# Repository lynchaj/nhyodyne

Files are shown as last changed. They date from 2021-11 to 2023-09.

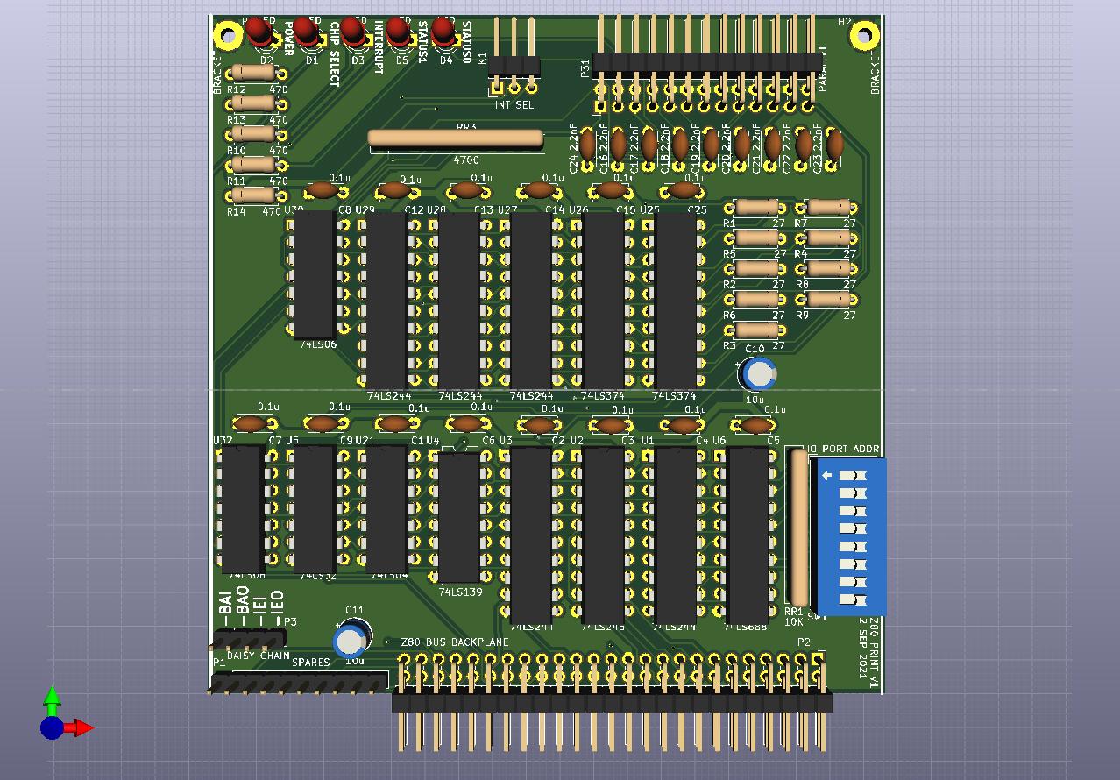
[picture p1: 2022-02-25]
Z80PRINT1/Z80PRINT.jpg

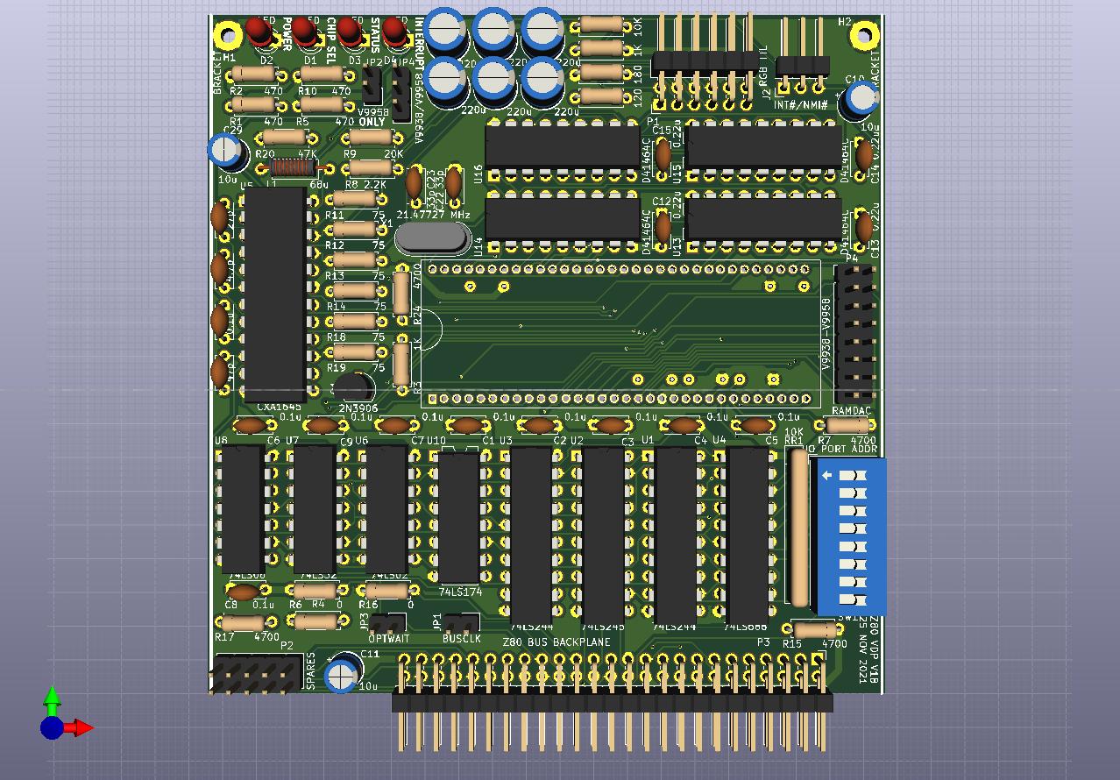
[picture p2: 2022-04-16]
Z80ESP/HARDWARE/Z80ESP.jpg

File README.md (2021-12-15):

# nhyodyne: A Modular Backplane Computer (MBC)

Dans Z80 MBC with MBC65C02

# Introduction
The purpose of this project is to revisit the design concepts behind my original Z80 SBC (aka test prototype) which has evolved into the SBC V2-005 over several years. Attempt to introduce some new concepts to make the design more modular, flexible, and less expensive. Use low cost prototype PCBs (100x100mm) available for less than $20 including shipping from JLCPCB. Make simple single function boards to implement good program design concepts from Computer Science: high cohesion and low coupling. Maintain as much backward compatibility with latest SBC V2 as possible.

# Overview
The MBC consists of four core boards: Z80 backplane, Z80 processor, Z80 clock, and Z80 ROM. These are sufficient to build a working system of minimum capability. However  the core boards are designed in such a way that they can be individually redesigned and replaced with improved designs and/or customized to suit the builder. It achieves low coupling by implementing a simple bus using off-the-shelf 2×25 2.54mm spaced pin headers and socket strips. The backplane is a replication of a fully buffered Z80 CPU pin out in the same order. Each board has high cohesion by being limited to a single function consisting of only parts specifically related to to perform its task. This lowers builder cost by eliminating unnecessary parts and improves system reliability by having fewer parts to fail. Likewise, if a component or whole board fails it can be replaced without affecting the remaining boards.

# Tools
Open Source tools and software are used to the maximum extend possible to keep costs down for people building the Z80 MBC.  The target software for Z80 MBC is ROMWBW and is supported in the Dev Branch.  All boards are designed using KiCAD version 5 or later and FreeRouting for PCB trace autorouting.  Gerber files are supplied for most boards and can be obtained from JLCPCB or the PCB manufacturer of your choice.

RomWBW Dev Branch  https://github.com/wwarthen/romwbw/tree/dev

KiCAD version 5 or later  https://www.kicad.org/

FreeRouting  https://github.com/freerouting/freerouting

JLCPCB  https://jlcpcb.com/

# Additional Design Goals
There are several additional design goals for the Z80 MBC.

First, is to ease constraints on the design to allow for some new configurations. Specifically capability to access memory over the bus and configurable memory map holes for external memory.

A second design goal is making all IO devices optional, fully configurable, and limiting IO port addresses to only the minimum necessary. Multiple IO devices can exist in the system simultaneously or not exist as the builder chooses. Lowers cost and improves system reliability by removing unneeded and/or unwanted capabilities.

The third design goal is allowing multiple memory modules with boot enable jumpers to specify boot devices present after CPU reset.

Fourth, adding simple debug features like user LEDs and a switch.

Fifth, implementing a fully buffered Z80 processor with configurable wait state capability and no internal IO or memory devices. Related is each board is also fully buffered to keep bus signals only on the bus with no raw bus signals intruding into the board past the buffers.

Sixth, maintain backwards compatibility to the extent possible (two exceptions so far) to reuse existing SBC software. Target software is current ROMWBW

Seventh, lower build cost by using inexpensive off-the-shelf components and PCBs. All parts come from Jameco or eBay (like bus connectors). Use simple 9vdc 1A unregulated power supply. Keep part count on boards low so they are effectively disposable eliminating the need for sockets and further lowering builder costs. Make non-essential components optionally do-not-populate.



Photo: Wayne Warthen's early version of Z80 MBC with prototype DSKY V3.  From left to right; contains boards Z80BCKPLN1 (underneath), Z80CLOCK, Z80PROC, Z80RAM, Z80ROM, Z80SERIAL, and Z80PPIDE with CF adapter installed.  Z80PPIDE is also connected to DSKY V3 via legacy PPI connector.
DSKY V3 by Dan Werner  https://www.retrobrewcomputers.org/doku.php?id=boards:ecb:dskyng

# Frequently Asked Questions
  What is "nhyodyne"?  The name nyhodyne is completely made up in an attempt to be unique.  It is pronounced like "neodyne".  https://www.howtopronounce.com/neo meaning "new" and https://www.howtopronounce.com/dyne meaning "force"

  Who is the intended audience?  Electronic and retrocomputing hobbyists of all ages and experience.  From brand new beginners to experienced designers, all are welcome.  Help is available on the discussion forum as needed or get in contact with me personally.  The boards are designed with beginners in mind and use common off-the-shelf tools and components.  I try to keep specialized parts to a minimum as well as surface mount devices (SMD) and/or programmable logic devices (GALs, CPLDs, FPGAs).

Where can I get Printed Circuit Boards (PCBs)?  Use the supplied Gerber files and order from JLCPCB or any other manufacturer. I just accept the defaults and they work fine.  You can customize if you want but you should know what you're doing.

I ordered PCBs and now I have extras.  What do I do with them?  Give them away to family and friends!  They make excellent gifts and affordable too!  Don't let the extras sit on a shelf gathering dust.  Share the fun

Can I use these designs in my science fair, school project, etc?  Sure, but please cite your source so others can find this project too.

What if I want to fork my own project based on your work?  It's OK with me and I wish you the best of luck.  I'll be happy to answer questions as best I can and as time allows.

Can these designs be used commercially?  Not really and I'd prefer they be kept for hobbyists because that's they're intended purpose.  If you take these designs partially or in whole commercial you are on your own and accept all associated risk.  These are intended for hobbyist and educational use only.

Why are all the PCBs green?  I like green PCBs and am a bit of a traditionalist from back in the day when PCBs only came in green.  Also it is a good color choice to see the traces underneath and provides good contrast compared to other colors.  That being said, you can make your PCBs any color you like when you order them.

Wow, this is cool!  How do I get involved?  Simple, download the Gerber files and get them built at JLCPCB or whatever PCB manufacturer you prefer.  Order parts and build your boards.  Post your questions on the forum with pictures.

What can I do to support nhyodyne project?  Great question!  What it most needs is YOU so start building your boards right away.  Then tell your friends.  Post on your favorite retrocomputing forums like retro-comp, comp.os.cpm, vogons.org, vintage computer sites, retrobrewcomputers.org, S100computers.com, etc.

Do you accept monetary donations?  Not really, but some people send money and I appreciate their generousity and thank them profusely. However, the truth is I am a senior engineer much closer to retirement than the beginning of my career.  I really enjoy this hobby so much I want to share it with others and make new friends.  If you insist on donations, I will usually graciously accept them but I'd rather you built your own system and tell all your friends about it.

Hey, I've got a great idea for a new board!  How to I make it?  I can help you and depending on your skill level either make it myself for the project or help you make it yourself.   There are people doing both.  I occasionally take requests for new boards although when I make them they are subject to my sense of priority and availability.  In other words, if I make them it will be on my own time and when I am ready.

Any closing thoughts?   Yes, have a great day!  Get out and enjoy your life!  This is a wonderful hobby and I've met the best people -- you will too.  I wish you a long and prosperous life with all the happiness it can bring.  Help someone else along the way.

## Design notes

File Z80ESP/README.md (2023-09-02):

# ESP32 Multi IO
The Nhyodyne ESP32 board provides the following functions for your Nhyodyne computer
* ANSI Console
* Graphics
* Sprites
* Sound
* Dual USB Serial Support
* WiFi
* Keyboard
* Mouse

This board relies heavily on the FabGL library from Fabrizio Di Vittorio.   More information can be found [HERE](http://www.fabglib.org/)

# ESP32 BOM
Qty|Reference(s)|Value|Notes
---|------------|-----|-----
12|C1, C2, C3, C4, C5, C6, C7, C8, C9, C10, C13, C14|0.1uF
3|C11, C12, C16|10uF
1|C15|100nf
1|D2|LED
2|D3, D6|1N4001
1|J3|Pin Header, right angle 1x2
1|J4|Pin Header, right angle 1x3
1|J5|Pin Header, right angle 1x3
1|J6|DB15 Female High Density PCB VGA Connector
1|J7|Pin Header, right angle 2x5
1|P2|Pin Header Right Angle 2x25
4|R1, R3, R14, R15|120ohm
1|R2|470ohm
2|R4, R6|2Kohm
2|R5, R13|1Kohm
3|R7, R9, R11|400ohm
3|R8, R10, R12|800ohm
1|R16|270ohm
1|R17|150ohm
1|RR1|10Kohm, networked, 9 pin, 8 resistor
1|RR2|1Kohm, networked, 9 pin, 8 resistor
1|SW1|8 position DIP switch
1|U1|74LS04
2|U2, U4|74LS244
1|U3|74LS245
3|U5, U6, U14|74LS32
2|U7, U9|74HC595
2|U8, U11|74HC165
1|U10|74LS688
2|U12, U13|ESP-WROOM-32 Dev Module|Such As: https://www.amazon.com/ESP-WROOM-32-Development-Microcontroller-Integrated-Compatible/dp/B08D5ZD528
1|U15|74LS244
1|U16|74LS07

# ESP32 Firmware Installation
The firmware for this board requires that platformio be installed on your system.

To install platformio core for your operating system see the directions [HERE](https://platformio.org/install/cli).  
Make sure you follow the additional directions to install the shell commands.

On linux systems it may be necessary to update permissions for the device that is autocreated for the ESP32. [More details](https://docs.platformio.org/en/latest/core/installation/udev-rules.html)  
Once platformio is properly setup on your system, you should be able to build and deploy the firmware to the ESP32.  

## To build and install the ESP firmware:
Take the ESP32 device you have designated as ESP0 and with it NOT INSTALLED in the nhyodyne card, plug it into your computer via USB.
change directory to the ESP0Firmware folder on your PC and from the operating system prompt type
```
pio run -t upload
```

Over the next couple of minutes you should see the build and upload process
something like this:

```
dwerner@lserver02:/lserver03/fileserv/Development/Vintage/Projects/nhyodyne/Z80ESP/ESP0Firmware$ pio run -t upload
Processing esp32dev (platform: espressif32; board: esp32dev; framework: arduino)
-----------------------------------------------------------------------------------------------------------------------
Verbose mode can be enabled via `-v, --verbose` option
CONFIGURATION: https://docs.platformio.org/page/boards/espressif32/esp32dev.html
PLATFORM: Espressif 32 (6.3.2) > Espressif ESP32 Dev Module
HARDWARE: ESP32 240MHz, 320KB RAM, 4MB Flash
DEBUG: Current (cmsis-dap) External (cmsis-dap, esp-bridge, esp-prog, iot-bus-jtag, jlink, minimodule, olimex-arm-usb-ocd, olimex-arm-usb-ocd-h, olimex-arm-usb-tiny-h, olimex-jtag-tiny, tumpa)
PACKAGES:
 - framework-arduinoespressif32 @ 3.20009.0 (2.0.9)
 - tool-esptoolpy @ 1.40501.0 (4.5.1)
 - tool-mkfatfs @ 2.0.1
 - tool-mklittlefs @ 1.203.210628 (2.3)
 - tool-mkspiffs @ 2.230.0 (2.30)
 - toolchain-xtensa-esp32 @ 8.4.0+2021r2-patch5
LDF: Library Dependency Finder -> https://bit.ly/configure-pio-ldf
LDF Modes: Finder ~ deep+, Compatibility ~ soft
Found 34 compatible libraries
Scanning dependencies...
Dependency Graph
|-- FabGL @ 1.0.9
|-- SPI @ 2.0.0
|-- Preferences @ 2.0.0
Building in release mode
Retrieving maximum program size .pio/build/esp32dev/firmware.elf
Checking size .pio/build/esp32dev/firmware.elf
Advanced Memory Usage is available via "PlatformIO Home > Project Inspect"
RAM:   [=         ]   9.3% (used 30632 bytes from 327680 bytes)
Flash: [=====     ]  46.4% (used 608561 bytes from 1310720 bytes)
Configuring upload protocol...
AVAILABLE: cmsis-dap, esp-bridge, esp-prog, espota, esptool, iot-bus-jtag, jlink, minimodule, olimex-arm-usb-ocd, olimex-arm-usb-ocd-h, olimex-arm-usb-tiny-h, olimex-jtag-tiny, tumpa
CURRENT: upload_protocol = esptool
Looking for upload port...
Auto-detected: /dev/ttyUSB0
Uploading .pio/build/esp32dev/firmware.bin
esptool.py v4.5.1
Serial port /dev/ttyUSB0
Connecting.....
Chip is ESP32-D0WD-V3 (revision v3.0)
Features: WiFi, BT, Dual Core, 240MHz, VRef calibration in efuse, Coding Scheme None
Crystal is 40MHz
MAC: 08:b6:1f:33:39:fc
Uploading stub...
Running stub...
Stub running...
Changing baud rate to 460800
Changed.
Configuring flash size...
Flash will be erased from 0x00001000 to 0x00005fff...
Flash will be erased from 0x00008000 to 0x00008fff...
Flash will be erased from 0x0000e000 to 0x0000ffff...
Flash will be erased from 0x00010000 to 0x000a4fff...
Compressed 17488 bytes to 12168...
Writing at 0x00001000... (100 %)
Wrote 17488 bytes (12168 compressed) at 0x00001000 in 0.5 seconds (effective 287.3 kbit/s)...
Hash of data verified.
Compressed 3072 bytes to 146...
Writing at 0x00008000... (100 %)
Wrote 3072 bytes (146 compressed) at 0x00008000 in 0.0 seconds (effective 571.2 kbit/s)...
Hash of data verified.
Compressed 8192 bytes to 47...
Writing at 0x0000e000... (100 %)
Wrote 8192 bytes (47 compressed) at 0x0000e000 in 0.1 seconds (effective 829.3 kbit/s)...
Hash of data verified.
Compressed 608928 bytes to 309667...
Writing at 0x00010000... (5 %)
Writing at 0x00020854... (10 %)
Writing at 0x0002f631... (15 %)
Writing at 0x0003b66a... (21 %)
Writing at 0x0004b725... (26 %)
Writing at 0x00050794... (31 %)
Writing at 0x00056585... (36 %)
Writing at 0x0005c2fd... (42 %)
Writing at 0x0006271e... (47 %)
Writing at 0x000684b2... (52 %)
Writing at 0x0006dceb... (57 %)
Writing at 0x00073098... (63 %)
Writing at 0x0007864e... (68 %)
Writing at 0x0007de33... (73 %)
Writing at 0x0008412b... (78 %)
Writing at 0x0008c053... (84 %)
Writing at 0x00094cba... (89 %)
Writing at 0x0009a559... (94 %)
Writing at 0x0009f9b7... (100 %)
Wrote 608928 bytes (309667 compressed) at 0x00010000 in 8.0 seconds (effective 606.6 kbit/s)...
Hash of data verified.

Leaving...
Hard resetting via RTS pin...
============================================ [SUCCESS] Took 22.49 seconds ============================================
```

Once this is done you can install ESP0 into U12 on your nhyodyne board.  Then repeat the process for the ESP1 and install into U13.

# ESP32 Communication Protocol

The ESP32 board communicates with your system via 3 ports, two IO ports and one status port.

The default configuration sets the base IO to $9C.  IO Communication with ESP0 is at base port, ESP1 is at base port +1 and the status register is at base port +2.

```
ESPBASE         EQU $9C         ; Base Port
ESP0:           EQU ESPBASE     ; ESP0 IO PORT

ESP1:           EQU ESPBASE+1   ; ESP1 IO PORT

ESP_STATUS:     EQU ESPBASE+2   ; ESP  STATUS PORT
                                ; MSB XX XX S S S S S
                                ;           | | | | |- ESP0 READY_OUTPUT
                                ;           | | | |--- ESP0 BUSY
                                ;           | | |----- ESP0 SPARE (unused)
                                ;           | |------- ESP1 READY_OUTPUT
                                ;           |--------- ESP1 BUSY
```

The communication process is fairly straight forward.  Upon reset, the ESP will initialize, set BUSY and READY_OUTPUT to low and wait for an opcode.

To send an opcode or data to the ESP:

* wait for ESPx BUSY bit to go low (a timeout is suggested)
* write the opcode or data to the ESPx IO port
* it is a best practice to wait for ESPx BUSY bit to go high then low (a timeout is suggested) before sending the next byte

If an "out of sync" occurrs, where the ESP is waiting for data rather than an opcode and the host driver is unsure of the state of the ESP, it is possible to resync the ESP back to the "waiting for opcode" state by sending a stream of NULL bytes to the IO port. A stream of more than 25 NULLS should always safely return the ESP back to the "waiting for opcode" state.

Some Opcodes will return one or more bytes to the host system.   For those opcodes

* wait for ESPx BUSY bit to go low (a timeout is suggested)
* wait for ESPx READY_OUTPUT bit to go high (a timeout is suggested)
* Read the ESPx IO port
* it is a best practice to wait for ESPx BUSY bit to go high then low (a timeout is suggested) before sending the next byte

Note that the BUSY bit transitions after a command is written or data is read can happen very fast.   On slower systems a timeout is required as it is possible for the host system to miss this transition if it is not polling fast enough.

It is also a best practice to empty the ESP send buffer before sending an opcode that returns data.

For example code, see the ESPTEST.ASM program in this repo.

# ESP32 ESP0 Opcode Reference

## ESP32 Misc Opcodes

OP CODE|Description|Values
-------|-----------|------
00|NO OPERATION|NONE

The NO OPERATION opcode is used to sync the ESP32 communications stream to a known state, "Waiting for opcode".

Input Parameters: None  
Returns: None  

OP CODE|Description|Values
-------|-----------|------
255|DISCOVER|"E" "S" "P" "3" "2" "V" "1"

The DISCOVER opcode is used by host systems to verify the presence and version of the ESP hardware and firmware.

Input Parameters: None  
Returns: 7 bytes - "E" "S" "P" "3" "2" "V" "1"  

## ESP32 Terminal Opcodes
	
OP CODE|Description|Values
-------|-----------|------
1 |VGA ANSI TERM OUT SINGLE CHAR| OUT-BYTE

The VGA ANSI TERM OUT SINGLE CHAR opcode sends a single byte to the ANSI terminal subsystem of the ESP32.  Using the ANSI escape sequence set, this byte is rendered to the VGA terminal console.

Input Parameters: 1 byte - "OUT CHAR"  
Returns: None  

OP CODE|Description|Values
-------|-----------|------
2 |VGA ANSI TERM OUT NULL TERMINATED STRING| OUT-BYTE	OUT-BYTE	OUT-BYTE	OUT-BYTE	OUT-BYTE	OUT-BYTE	…	…	…	…	NULL

The VGA ANSI TERM OUT NULL TERMINATED STRING opcode sends a null terminated string to the ANSI terminal subsystem of the ESP32.  Using the ANSI escape sequence set, this string is rendered to the VGA terminal console.

Input Parameters: X bytes - string terminated by a null  
Returns: None  

OP CODE|Description|Values
-------|-----------|------
3 |VGA ANSI TERM KEYBOARD IN| IN-BYTE	

The VGA ANSI TERM KEYBOARD IN opcode returns a byte from the terminal keyboard buffer.   If there is no keystrokes in the buffer, the opcode will return a null.

Input Parameters: None  
Returns: 1 byte - input keystroke or null  

OP CODE|Description|Values
-------|-----------|------
4 |VGA ANSI TERM KEYBOARD BUFFER LENGTH| IN-BYTE

The VGA ANSI TERM KEYBOARD BUFFER LENGTH opcode returns the numbser of keystrokes in the ANSI terminal keyboard buffer.

Input Parameters: None  
Returns: 1 byte - keystroke buffer length  

OP CODE|Description|Values
-------|-----------|------
5 |VGA ANSI TERM SET CURSOR| OUT-BYTE

The VGA ANSI TERM SET CURSOR opcode sets the visibility of the terminal cursor.
* 0 = cursor off
* 1 = cursor on

Input Parameters: 1 byte - Cursor status  
Returns: None  

## ESP32 Serial Opcodes

OP CODE|Description|Values
-------|-----------|------
6 |Set Baud Rate| OUT-BYTE  OUT-BYTE  OUT-BYTE  OUT-BYTE

The Set Baud Rate opcode sets the baud rate for the ESP async serial port.  This port is exposed through the header on the top of the card and through the USB port on the ESP32 module.   Byte order is least signifigant byte to most significant byte.

Input Parameters: 4 bytes - Baud Rate
Returns: None  

OP CODE|Description|Values
-------|-----------|------
7 |Set Serial Mode| OUT-BYTE

The Set Serial Mode opcode sets the serial communication parameters for the ESP async serial port.  This port is exposed through the header on the top of the card and through the USB port on the ESP32 module.
Parameters are set as follows:
* 0 = 8 data bits, no parity, 1 stop bits
* 1 = 8 data bits, even parity, 1 stop bits
* 2 = 8 data bits, odd parity, 1 stop bits
* 3 = 7 data bits, no parity, 1 stop bits
* 4 = 7 data bits, even parity, 1 stop bits
* 5 = 7 data bits, odd parity, 1 stop bits

Input Parameters: 1 byte - Serial Mode  
Returns: None  

OP CODE|Description|Values
-------|-----------|------
8 |Serial TX Single char| OUT-BYTE

The Serial TX Single char opcode transmits a single byte through the serial communication port.  This port is exposed through the header on the top of the card and through the USB port on the ESP32 module.

Input Parameters: 1 byte - char  
Returns: None  

OP CODE|Description|Values
-------|-----------|------
9 |Serial TX Null Terminated String| OUT-BYTE  OUT-BYTE  OUT-BYTE  OUT-BYTE  OUT-BYTE  OUT-BYTE	…	…	…	…	NULL

The Serial TX Null Terminated String opcode transmits a null terminated string through the serial communication port.  This port is exposed through the header on the top of the card and through the USB port on the ESP32 module.

Input Parameters: X bytes - string terminated by a null  
Returns: None  

OP CODE|Description|Values
-------|-----------|------
10 |Serial RX| IN-BYTE

The Serial RX opcode returns a byte from the serial communication port buffer.  If there are no values in the buffer, the opcode will return a null.  This port is exposed through the header on the top of the card and through the USB port on the ESP32 module.   

Input Parameters: None  
Returns: 1 byte - input value or null    

OP CODE|Description|Values
-------|-----------|------
11 |Chars in Serial Buffer| IN-BYTE

The Chars in Serial Buffer opcode returns the numbser of keystrokes in the serial communication port buffer.  This port is exposed through the header on the top of the card and through the USB port on the ESP32 module.   

Input Parameters: None  
Returns: 1 byte - serial buffer length  

## ESP32 Audio Opcodes

OP CODE|Description|Values
-------|-----------|------
12 |Play Null Terminated String| OUT-BYTE  OUT-BYTE  OUT-BYTE  OUT-BYTE  OUT-BYTE  OUT-BYTE	…	…	…	…	NULL

The Play Null Terminated String opcode intreprets a string as musical notes and plays them with a square wave tone generator through the audio port on the top of the ESP32 card.  The audio port is at line level and requires amplification. 

Example string: "A4 4 2 A4 4 2 A#4 4 2 C5 4 2 C5 4 2 A#4 4 2 A4 4 2 G4 4 2 F4 4 2 F4 4 2 G4 4 2 A4 4 2 A4 2 2 G4 16 2 G4 2 2 P 8 2 "

The string is in the format:  [note (C,D,E,F,G,A,B) + [#,b] + octave (2..7) + space + tempo (99..1)] + [pause (P) + space + tempo (99.1)]
```
    "A4 4 2" 
     |  | |----- Tempo
     |  |------- Octave (2..7)
     |---------- note to play (or P for pause)
```     

Input Parameters: 1 byte - Cursor status  
Returns: None  

OP CODE|Description|Values
-------|-----------|------
13 |Play Sound	| OUT-BYTE  OUT-BYTE  OUT-BYTE  OUT-BYTE  OUT-BYTE  OUT-BYTE  OUT-BYTE  OUT-BYTE  OUT-BYTE  OUT-BYTE  OUT-BYTE  OUT-BYTE  OUT-BYTE  OUT-BYTE  OUT-BYTE  OUT-BYTE  OUT-BYTE  OUT-BYTE  OUT-BYTE  OUT-BYTE  OUT-BYTE  OUT-BYTE  OUT-BYTE  OUT-BYTE  

The Play Sound opcode plays a sound with the specified parameters through the audio port on the top of the ESP32 card.  The audio port is at line level and requires amplification. 

The following parameters need to be specified in the following order:
* Attack, 4 bytes, Byte order is least signifigant byte to most significant byte.
* Decay, 4 bytes, Byte order is least signifigant byte to most significant byte.
* Sustain, 2 bytes, Byte order is least signifigant byte to most significant byte.
* Release, 4 bytes, Byte order is least signifigant byte to most significant byte.
* WaveType, 1 byte,   0=WAVE_SQUARE,1=WAVE_SINE,2=WAVE_TRIANGLE,3=WAVE_SAW,4=WAVE_NOISE
* Volume, 2 bytes,  Byte order is least signifigant byte to most significant byte.  Even though volume is specified as two bytes, only LSB is used.
* Duration, 2 bytes, Byte order is least signifigant byte to most significant byte.  Duration is in MS.
* FreqStart, 2 bytes, Byte order is least signifigant byte to most significant byte.
* FreqEnd, 2 bytes, Byte order is least signifigant byte to most significant byte.
* ModFreqMode, 1 byte,  0=MODFREQ_NONE,1=MODFREQ_TO_END,2=MODFREQ_TO_RELEASE,3=MODFREQ_TO_SUSTAIN

More detailed information about programming the sound generator can be found [HERE](http://www.fabglib.org/classfabgl_1_1_sound_generator.html)

Input Parameters: 24 bytes
Returns: None  

OP CODE|Description|Values
-------|-----------|------
14 |Set Volume| OUT-BYTE

The Set Volume opcode sets the overall volume of the sound generated by the audio port on the top of the ESP32 card.  The audio port is at line level and requires amplification.

Input Parameters: 1 byte - Volume
Returns: None  

## ESP32 Graphics Opcodes
OP CODE|Description|Values
-------|-----------|------
15 |Set Display Resolution| OUT-BYTE

The Set Display Resolution opcode sets the display resolution of the VGA output of the ESP32. The specified display resolution is stored in flash memory and will survive a power cycle.  Note that this opcode can take a SECOND OR MORE to process as it requires the ESP to reboot, so leave plenty of time after issuing this command. ALWAYS issue a Clear Display(17) command after changing video mode. 

The proper sequence is as follows:
* issue Set Display Resolution opcode
* send one byte for new video mode
* wait at least 3 seconds
* issue clear display command

ID|Mode Name|Description|Color Depth
--|---------|-----------|-----------
00|VGA_320x200_70Hz|320x200@70Hz resolution - the same of VGA_640x200_70Hz with horizontal halved|64
01|VGA_320x200_75Hz|320x200@75Hz resolution|64
02|VGA_320x200_75HzRetro|320x200@75Hz retro resolution|64
03|QVGA_320x240_60Hz|320x240@60Hz resolution|64
04|VGA_400x300_60Hz|400x300@60Hz resolution|64
05|VGA_480x300_75Hz|480x300@75Hz resolution|64
06|VGA_512x192_60Hz|512x192@60Hz resolution|16
07|VGA_512x384_60Hz	|512x384@60Hz resolution|16
08|VGA_512x448_60Hz|512x448@60Hz resolution|16
09|VGA_512x512_58Hz|512x512@58Hz resolution|16
10|VGA_640x200_60HzD|640x200@60Hz doublescan resolution|16
11|VGA_640x200_70Hz|640x200@70Hz resolution - the same of VGA_640x400_70Hz with vertical halved|16
12|VGA_640x200_70HzRetro|640x200@70Hz retro resolution|16
13|VGA_640x240_60Hz|640x240@60Hz (DoubleScan) resolution|16
14|VGA_640x350_70Hz|640x350@70Hz resolution|16
15|VGA_640x350_70HzAlt1|640x350@70HzAlt1 resolution|16
16|VESA_640x350_85Hz|640x350@85Hz resolution|16
17|VGA_640x382_60Hz|640x382@60Hz resolution|16
18|VGA_640x384_60Hz|640x384@60Hz resolution|16
19|VGA_640x400_70Hz|640x400@70Hz resolution|16
20|VGA_640x400_60Hz|640x400@60Hz (actually 640x480 but with less lines)|16
21|VGA_640x480_60Hz|640x480@60Hz resolution|16
22|VGA_640x480_60HzAlt1|640x480@60HzAlt1 resolution|16
23|VGA_640x480_60HzD|640x480@60Hz doublescan resolution|16
24|VGA_640x480_73Hz|640x480@73Hz resolution|16
25|VESA_640x480_75Hz|640x480@75Hz resolution|16
26|VGA_720x348_50HzD|720x348@50Hz doublescan resolution|16
27|VGA_720x348_59HzD|720x348@59Hz doublescan resolution|16
28|VGA_720x348_73Hz|720x348@73Hz resolution|16
29|VGA_720x350_70Hz|720x350@70Hz resolution|16
30|VGA_720x400_70Hz|720x400@70Hz resolution|16
31|VESA_720x400_85Hz|720x400@85Hz resolution|16
32|PAL_720x576_50Hz|720x576@50Hz resolution|8
33|VESA_768x576_60Hz|768x576@60Hz resolution|8
34|SVGA_800x300_60Hz|800x300@60Hz resolution|8
35|SVGA_800x600_56Hz|800x600@56Hz resolution|4
36|SVGA_800x600_60Hz|800x600@60Hz resolution|4
37|SVGA_960x540_60Hz|960x540@60Hz resolution|4
38|SVGA_1024x768_60Hz|1024x768@60Hz resolution|2
39|SVGA_1024x768_70Hz|1024x768@70Hz resolution|2
40|SVGA_1024x768_75Hz|1024x768@75Hz resolution|2
41|SVGA_1280x600_60Hz|1280x600@60Hz resolution|2
42|SVGA_1280x720_60Hz|1280x720@60Hz resolution|2
43|SVGA_1280x720_60HzAlt1|1280x720@60Hz resolution|2
44|SVGA_1280x768_50Hz|1280x768@50Hz resolution|2

Input Parameters: 1 byte - Video Mode
Returns: None  

OP CODE|Description|Values
-------|-----------|------
16 |Load Font| OUT-BYTE

The Load Font opcode sets the display font for the VGA ANSI Terminal.

ID|Font Name	
--|---------
00|FONT_4X6
01|FONT_5X7
02|FONT_5X8
03|FONT_6X8
04|FONT_6X9
05|FONT_6X10
06|FONT_6X12
07|FONT_6X13
08|FONT_7X13
09|FONT_7X14
10|FONT_8X8
11|FONT_8X9
12|FONT_8X13
13|FONT_8X14
14|FONT_8X16
15|FONT_8X19
16|FONT_9X15
17|FONT_9X18
18|FONT_10X20
19|FONT_BIGSERIF_8X14
20|FONT_BIGSERIF_8X16
21|FONT_BLOCK_8X14
22|FONT_BROADWAY_8X14
23|FONT_COMPUTER_8X14
24|FONT_COURIER_8X14
25|FONT_LCD_8X14
26|FONT_OLDENGL_8X16
27|FONT_SANSERIF_8X14
28|FONT_SANSERIF_8X16
29|FONT_SLANT_8X14
30|FONT_WIGGLY_8X16

Input Parameters: 1 byte - Font
Returns: None  

OP CODE|Description|Values
-------|-----------|------
17|Clear Display| NONE

The Clear Display opcode clears the VGA.

Input Parameters: None
Returns: None  

OP CODE|Description|Values
-------|-----------|------
18 |Copy Rectangle| OUT-BYTE OUT-BYTE OUT-BYTE OUT-BYTE OUT-BYTE OUT-BYTE OUT-BYTE OUT-BYTE OUT-BYTE OUT-BYTE OUT-BYTE OUT-BYTE

The Copy Rectangle opcode copyies a rectangle shaped area from one part of the bitmapped display to another.

The following parameters need to be specified in the following order:
* Source X coordinate, 2 bytes, Byte order is least signifigant byte to most significant byte.
* Source Y coordinate, 2 bytes, Byte order is least signifigant byte to most significant byte.
* Destination X coordinate, 2 bytes, Byte order is least signifigant byte to most significant byte.
* Destination Y coordinate, 2 bytes, Byte order is least signifigant byte to most significant byte.
* Area Width, 2 bytes, Byte order is least signifigant byte to most significant byte.
* Area Hight, 2 bytes, Byte order is least signifigant byte to most significant byte.

All Parameters above are in display pixels with 0,0 being the upper left of the VGA screen.

Input Parameters: 12 bytes
Returns: None  

OP CODE|Description|Values
-------|-----------|------
19 |Draw Bitmap| OUT-BYTE(s)

The Draw Bitmap opcode draws a specified bitmap on the VGA display.

The following parameters need to be specified in the following order:
* X coordinate, 2 bytes, Byte order is least signifigant byte to most significant byte.
* Y coordinate, 2 bytes, Byte order is least signifigant byte to most significant byte.
* Width, 2 bytes, Byte order is least signifigant byte to most significant byte.
* Hight, 2 bytes, Byte order is least signifigant byte to most significant byte.
* Pixel Format, 1 byte, FORMAT=1:NATIVE DEVICE(usually 1 BIT/PIXEL),2:MASK(1=OPAQUE 0=TRANSP),3: 8 BITS/PIXEL aabbggrr, 4:32 BITS/PIXEL RGBA
* Bitmap Length, 2 bytes, Byte order is least signifigant byte to most significant byte.
* Bitmap Data, X bytes, bitmap size cannot exceed 31.5K

Input Parameters: X bytes
Returns: None  

OP CODE|Description|Values
-------|-----------|------
20 |Draw Char| OUT-BYTE OUT-BYTE OUT-BYTE OUT-BYTE OUT-BYTE OUT-BYTE

The Draw Char opcode draws a specified character, at a specified location, in a specified font, in the current Pen color.

The following parameters need to be specified in the following order:
* X coordinate, 2 bytes, Byte order is least signifigant byte to most significant byte.
* Y coordinate, 2 bytes, Byte order is least signifigant byte to most significant byte.
* Character to Draw, 1 byte
* Font, 1 bytes, See Font Table from Set Font opcode

Input Parameters: 6 bytes
Returns: None  

OP CODE|Description|Values
-------|-----------|------
21 |Draw Ellipse| OUT-BYTE  OUT-BYTE  OUT-BYTE  OUT-BYTE  OUT-BYTE  OUT-BYTE  OUT-BYTE  OUT-BYTE  

The Draw Ellipse opcode draws an ellpise on the bitmapped display, in the current Pen color.

The following parameters need to be specified in the following order:
* X coordinate, 2 bytes, Byte order is least signifigant byte to most significant byte.
* Y coordinate, 2 bytes, Byte order is least signifigant byte to most significant byte.
* Width, 2 bytes, Byte order is least signifigant byte to most significant byte.
* Height, 2 bytes, Byte order is least signifigant byte to most significant byte.

Input Parameters: 6 bytes
Returns: None  

OP CODE|Description|Values
-------|-----------|------
22 |Draw Gliph| OUT-BYTE(s)

The Draw Glyph opcode draws a Glyph on the bitmapped display, in the current Pen color.

The following parameters need to be specified in the following order:
* X coordinate, 2 bytes, Byte order is least signifigant byte to most significant byte.
* Y coordinate, 2 bytes, Byte order is least signifigant byte to most significant byte.
* Width, 2 bytes, Byte order is least signifigant byte to most significant byte.
* Height, 2 bytes, Byte order is least signifigant byte to most significant byte.
* Index, 2 bytes, Byte order is least signifigant byte to most significant byte.  Usually 0, Use when the buffer contains multiple glyphs.
* Glyph Length, 2 bytes, Byte order is least signifigant byte to most significant byte.
* Glyph Data, X bytes, glyph size cannot exceed 255 bytes, and is stored as a 1 bit/pixel bitmap

Input Parameters: X bytes
Returns: None  

OP CODE|Description|Values
-------|-----------|------
23 |Draw Line| OUT-BYTE  OUT-BYTE  OUT-BYTE  OUT-BYTE  OUT-BYTE  OUT-BYTE  OUT-BYTE  OUT-BYTE  

The Draw Line opcode draws a line on the bitmapped display, in the current Pen color.

The following parameters need to be specified in the following order:
* Start X coordinate, 2 bytes, Byte order is least signifigant byte to most significant byte.
* Start Y coordinate, 2 bytes, Byte order is least signifigant byte to most significant byte.
* End X coordinate, 2 bytes, Byte order is least signifigant byte to most significant byte.
* End Y coordinate, 2 bytes, Byte order is least signifigant byte to most significant byte.

Input Parameters: 8 bytes
Returns: None  

OP CODE|Description|Values
-------|-----------|------
24 |Draw Rectangle| OUT-BYTE  OUT-BYTE  OUT-BYTE  OUT-BYTE  OUT-BYTE  OUT-BYTE  OUT-BYTE  OUT-BYTE  

The Draw Rectangle opcode draws a Rectangle on the bitmapped display, in the current Pen color.

The following parameters need to be specified in the following order:
* Start X coordinate, 2 bytes, Byte order is least signifigant byte to most significant byte.
* Start Y coordinate, 2 bytes, Byte order is least signifigant byte to most significant byte.
* End X coordinate, 2 bytes, Byte order is least signifigant byte to most significant byte.
* End Y coordinate, 2 bytes, Byte order is least signifigant byte to most significant byte.

Input Parameters: 8 bytes
Returns: None  

OP CODE|Description|Values
-------|-----------|------
25 |Draw Filled Ellipse| OUT-BYTE  OUT-BYTE  OUT-BYTE  OUT-BYTE  OUT-BYTE  OUT-BYTE  OUT-BYTE  OUT-BYTE  

The Draw Filled Ellipse opcode draws a filled ellipse on the bitmapped display, in the current Pen color, filled with the current Brush color.

The following parameters need to be specified in the following order:
* Start X coordinate, 2 bytes, Byte order is least signifigant byte to most significant byte.
* Start Y coordinate, 2 bytes, Byte order is least signifigant byte to most significant byte.
* width, 2 bytes, Byte order is least signifigant byte to most significant byte.
* Height, 2 bytes, Byte order is least signifigant byte to most significant byte.

Input Parameters: 8 bytes
Returns: None  

OP CODE|Description|Values
-------|-----------|------
26 |Draw Filled Rectangle| OUT-BYTE  OUT-BYTE  OUT-BYTE  OUT-BYTE  OUT-BYTE  OUT-BYTE  OUT-BYTE  OUT-BYTE  

The Draw Filled Rectangle opcode draws a filled rectangle on the bitmapped display, in the current Pen color, filled with the current Brush color.

The following parameters need to be specified in the following order:
* Start X coordinate, 2 bytes, Byte order is least signifigant byte to most significant byte.
* Start Y coordinate, 2 bytes, Byte order is least signifigant byte to most significant byte.
* End X coordinate, 2 bytes, Byte order is least signifigant byte to most significant byte.
* End Y coordinate, 2 bytes, Byte order is least signifigant byte to most significant byte.

Input Parameters: 8 bytes
Returns: None  

OP CODE|Description|Values
-------|-----------|------
27 |Get Pixel Value| OUT-BYTE  OUT-BYTE  OUT-BYTE  OUT-BYTE  IN-BYTE    IN-BYTE    IN-BYTE  

The Get Pixel Value opcode returns the current color value of the specified display pixel.

The following parameters need to be specified in the following order:
* X coordinate, 2 bytes, Byte order is least signifigant byte to most significant byte.
* Y coordinate, 2 bytes, Byte order is least signifigant byte to most significant byte.

The ESP will then return:
* Blue value, 1 byte
* Green value, 1 byte
* Red value, 1 byte

Input Parameters: 4 bytes
Returns: 3 bytes

OP CODE|Description|Values
-------|-----------|------
28 |Invert Rectangle| OUT-BYTE  OUT-BYTE  OUT-BYTE  OUT-BYTE  OUT-BYTE  OUT-BYTE  OUT-BYTE  OUT-BYTE  

The Invert Rectangle opcode will invert all of the pixels within a specified area on the bitmapped display.

The following parameters need to be specified in the following order:
* Start X coordinate, 2 bytes, Byte order is least signifigant byte to most significant byte.
* Start Y coordinate, 2 bytes, Byte order is least signifigant byte to most significant byte.
* End X coordinate, 2 bytes, Byte order is least signifigant byte to most significant byte.
* End Y coordinate, 2 bytes, Byte order is least signifigant byte to most significant byte.

Input Parameters: 8 bytes
Returns: None  

OP CODE|Description|Values
-------|-----------|------
29 |Draw A Line To| OUT-BYTE  OUT-BYTE  OUT-BYTE  OUT-BYTE

The Draw A Line To opcode will draw a line from the current graphics cursor position to the specified location on the bitmapped display.

The following parameters need to be specified in the following order:
* End X coordinate, 2 bytes, Byte order is least signifigant byte to most significant byte.
* End Y coordinate, 2 bytes, Byte order is least signifigant byte to most significant byte.

Input Parameters: 4 bytes
Returns: None  

OP CODE|Description|Values
-------|-----------|------
30 |Move Cursor To| OUT-BYTE  OUT-BYTE  OUT-BYTE  OUT-BYTE

The Move Cursor To opcode will move the graphics cursor to the specified location on the bitmapped display.

The following parameters need to be specified in the following order:
* End X coordinate, 2 bytes, Byte order is least signifigant byte to most significant byte.
* End Y coordinate, 2 bytes, Byte order is least signifigant byte to most significant byte.

Input Parameters: 4 bytes
Returns: None  

OP CODE|Description|Values
-------|-----------|------
31 |Scroll Display| OUT-BYTE  OUT-BYTE  OUT-BYTE  OUT-BYTE

The Scroll Display opcode will scroll the display by the specified offset.

The following parameters need to be specified in the following order:
* X Offset, 2 bytes, Byte order is least signifigant byte to most significant byte.  Left Scroll is accomplished by a negative offset
* Y Offset, 2 bytes, Byte order is least signifigant byte to most significant byte.  Up Scroll is accomplished by a negative offset

Input Parameters: 4 bytes
Returns: None  

OP CODE|Description|Values
-------|-----------|------
32 |Set Brush Color| OUT-BYTE

The Set Brush Color sets the brush color to the specified color index on the pallette.

Input Parameters: 1 byte - Color
Returns: None  

OP CODE|Description|Values
-------|-----------|------
33 |Set Line Ends| OUT-BYTE

The Set Line Ends sets the method for drawing line ends by the display renderer. 
* 0=NONE
* 1=ROUNDED

Input Parameters: 1 byte - End Type
Returns: None  

OP CODE|Description|Values
-------|-----------|------
34 |Set Pen Color| OUT-BYTE

The Set Pen Color sets the brush color to the specified color index on the pallette.

Input Parameters: 1 byte - Color
Returns: None  

OP CODE|Description|Values
-------|-----------|------
35 |Set Pen Width| OUT-BYTE

The Set Pen Width sets the width in pixels of the drawing pen.

Input Parameters: 1 byte - Pen Width
Returns: None  

OP CODE|Description|Values
-------|-----------|------
36 |Set Pixel| OUT-BYTE  OUT-BYTE  OUT-BYTE  OUT-BYTE  

The Set Pixel draws a pixel at the specified location in the current pen color.

The following parameters need to be specified in the following order:
* End X coordinate, 2 bytes, Byte order is least signifigant byte to most significant byte.
* End Y coordinate, 2 bytes, Byte order is least signifigant byte to most significant byte.

Input Parameters: 4 bytes
Returns: None 

OP CODE|Description|Values
-------|-----------|------
37 |Set Glyph Options| OUT-BYTE  OUT-BYTE  OUT-BYTE  OUT-BYTE  OUT-BYTE  OUT-BYTE  OUT-BYTE  

The Set Glpyh Options opcode sets optional parameters that modify how glyphs are rendered by Draw Glyph.

The following parameters need to be specified in the following order:
* blank, 1 byte, send 1 to cause glyph to be rendered in background color
* bold, 1 byte, send 1 to cause glyph to be rendered in bold
* doubleWidth, 1 byte, send 1 to cause glyph to be rendered double width
* FillBackground, 1 byte, send 1 to cause glyph to be rendered with background painted in the specified brush color
* Invert, 1 byte, send 1 to cause glyph to be rendered inverted
* Italic, 1 byte, send 1 to cause glyph to be rendered in italics
* Underline, 1 byte, send 1 to cause glyph to be rendered with an underline

Input Parameters: 7 bytes
Returns: None  

OP CODE|Description|Values
-------|-----------|------
38 |Set Pallette Item| OUT-BYTE  OUT-BYTE  OUT-BYTE  OUT-BYTE  

The Set Pallette Item opcode sets the rendered color for a given color index.

The following parameters need to be specified in the following order:
* Index, 1 byte, Color Index on Pallette (0-63 or 0-15, or 0-3, or 0-2 or 0-1 depending on screen color depth)
* Blue Value, 1 byte 
* Green Value, 1 byte
* Red Value, 1 byte

Input Parameters: 4 bytes
Returns: None  

OP CODE|Description|Values
-------|-----------|------
39 |Set Mouse Cursor Type| OUT-BYTE

The Set Mouse Cursor Type opcode sets the shape of the rendered mouse cursor.

ID|Description
--|-----------
0|11x11 Amiga like colored mouse pointer
1|10x15 mouse pointer
2|11x19 mouse pointer
3|11x19 shadowed mouse pointer
4|12x17 mouse pointer
5|16x16 pen
6|9x9 cross
7|11x11 cross
8|5x5 point
9|11x11 left arrow
10|11x11 right arrow
11|11x11 down arrow
12|11x11 up arrow
13|19x19 move
14|12x12 resize orientation 1
15|12x12 resize orientation 2
16|11x17 resize orientation 3
17|17x11 resize orientation 4
18|7x15 text input

Input Parameters: 1 byte - Mouse Cursor Type
Returns: None  

OP CODE|Description|Values
-------|-----------|------
40 |Set Mouse Cursor Position| OUT-BYTE  OUT-BYTE  OUT-BYTE  OUT-BYTE  

The Set Mouse Cursor Position opcode sets the display position of the mouse cursor.

The following parameters need to be specified in the following order:
* X coordinate, 2 bytes, Byte order is least signifigant byte to most significant byte.
* Y coordinate, 2 bytes, Byte order is least signifigant byte to most significant byte.

Input Parameters: 4 bytes
Returns: None  

OP CODE|Description|Values
-------|-----------|------
41 |Clear Sprites| NONE

The Clear Sprites opcode clears the sprite shape table.

Input Parameters: None  
Returns: None  

OP CODE|Description|Values
-------|-----------|------
42 |Set Sprite Map| OUT-BYTE(s)

setSpriteMap	42		*AWAYS SET THE HIGHEST INDEX SPRITE LAST, AND THE MAX CONFIGURED SPRITE NUMBER IS 31. (0-32)

The Set Sprite Map opcode sets the shape for a specified sprite.   There are 32 sprites (0-31) available with the current firmware and it is important to set the highest # sprite used LAST.   

The following parameters need to be specified in the following order:
* Sprite Index, 1 byte
* Sprite Width, 2 bytes, Byte order is least signifigant byte to most significant byte.
* Sprite Hight, 2 bytes, Byte order is least signifigant byte to most significant byte.
* Pixel Format, 1 byte, FORMAT=1:NATIVE DEVICE(usually 1 BIT/PIXEL),2:MASK(1=OPAQUE 0=TRANSP),3: 8 BITS/PIXEL aabbggrr, 4:32 BITS/PIXEL RGBA
* Sprite Length, 2 bytes, Byte order is least signifigant byte to most significant byte.
* Sprite Data, X bytes, bitmap size cannot exceed 31.5K

Input Parameters: X bytes
Returns: None  

OP CODE|Description|Values
-------|-----------|------
43 |Set Sprite Location| OUT-BYTE   OUT-BYTE   OUT-BYTE   OUT-BYTE   OUT-BYTE  

The Set Sprite Location opcode moves a specified sprite to a specified location.

The following parameters need to be specified in the following order:
* X Coordinate Location, 2 bytes, Byte order is least signifigant byte to most significant byte.
* Y Coordinate Location, 2 bytes, Byte order is least signifigant byte to most significant byte.
* Sprite Index, 1 byte

Input Parameters: 5 bytes
Returns: None  

OP CODE|Description|Values
-------|-----------|------
44 |Set Sprite Visibility| OUT-BYTE  OUT-BYTE  

The Set Sprite Visibility opcode sets the visibility of a specified sprite.

The following parameters need to be specified in the following order:
* Sprite Index, 1 byte
* Visible, 1 byte, 0= hidden, 1=visible

Input Parameters: 2 bytes
Returns: None  

### ESP32 ESP1 Opcode Reference

## ESP32 Misc Opcodes

OP CODE|Description|Values
-------|-----------|------
00|NO OPERATION|NONE

The NO OPERATION opcode is used to sync the ESP32 communications stream to a known state, "Waiting for opcode".

Input Parameters: None  
Returns: None  

OP CODE|Description|Values
-------|-----------|------
255|DISCOVER|"E" "S" "P" "3" "2" "V" "1"

The DISCOVER opcode is used by host systems to verify the presence and version of the ESP hardware and firmware.

Input Parameters: None  
Returns: 7 bytes - "E" "S" "P" "3" "2" "V" "1"  

## ESP32 WiFi Opcodes
OP CODE|Description|Values
-------|-----------|------
1 |WiFi Set SSID| OUT-BYTE(s)

The WiFi Set SSID opcode stores a null terminated string in the ESP flash memory and will survive a power cycle.  This value is then used during WiFi Connection.

Input Parameters: X bytes - string terminated by a null  
Returns: None  

OP CODE|Description|Values
-------|-----------|------
2 |WiFi Set Password| OUT-BYTE(s)
The WiFi Set WiFi Password opcode stores a null terminated string in the ESP flash memory and will survive a power cycle.  This value is then used during WiFi Connection.

Input Parameters: X bytes - string terminated by a null  
Returns: None  

OP CODE|Description|Values
-------|-----------|------
3 |WiFi Connect| None

The WiFi Connect opcode will attempt to connect to a WiFI access point using the stored configuration information.  If No TCP/IP address information is configured, DHCP will be attempted.

Input Parameters: None  
Returns: None  

OP CODE|Description|Values
-------|-----------|------
4 |WiFi Get Status| IN-BYTE  

The WiFi Get Status opcode returns the current WiFi status.

Status Byte|Description
-----------|-----------
0|WL_IDLE_STATUS
1|WL_NO_SSID_AVAIL
2|WL_SCAN_COMPLETED
3|WL_CONNECTED
4|WL_CONNECT_FAILED
5|WL_CONNECTION_LOST
6|WL_DISCONNECTED

Input Parameters: None  
Returns: 1 byte - WiFi Status

OP CODE|Description|Values
-------|-----------|------
5 |WiFi Get Signal Strength| IN-BYTE  

The WiFi Get Signal Strength opcode returns the current WiFi signal strength.

Input Parameters: None  
Returns: 1 bytes- Signal Strength  

## ESP32 TCP/IP Opcodes

OP CODE|Description|Values
-------|-----------|------
12|Get IP Address| IN-BYTE   IN-BYTE   IN-BYTE   IN-BYTE

The Get IP Address opcode returns the current IP address.

Input Parameters: None  
Returns: 4 bytes (octet 1,2,3,4)  

OP CODE|Description|Values
-------|-----------|------
13 |Get Subnet Mask| IN-BYTE   IN-BYTE   IN-BYTE   IN-BYTE

The Get Subnet Mask opcode returns the current submet mask.

Input Parameters: None  
Returns: 4 bytes (octet 1,2,3,4)  

OP CODE|Description|Values
-------|-----------|------
14 |Get Gateway| IN-BYTE   IN-BYTE   IN-BYTE   IN-BYTE

The Get Gateway opcode returns the current IP default gateway.

Input Parameters: None  
Returns: 4 bytes (octet 1,2,3,4)  

OP CODE|Description|Values
-------|-----------|------
15 |Get Primary DNS| IN-BYTE   IN-BYTE   IN-BYTE   IN-BYTE

The Get Primary DNS returns the current primary DNS address.

Input Parameters: None  
Returns: 4 bytes (octet 1,2,3,4)  

OP CODE|Description|Values
-------|-----------|------
16 |Get Secondary DNS| IN-BYTE   IN-BYTE   IN-BYTE   IN-BYTE

The Get Secondary DNS opcode returns the current secondary DNS IP address.

Input Parameters: None  
Returns: 4 bytes (octet 1,2,3,4)  

OP CODE|Description|Values
-------|-----------|------
17 |Set IP Address| OUT-BYTE   OUT-BYTE   OUT-BYTE   OUT-BYTE

The Set IP Address opcode sets the IP address. 0.0.0.0 value enables DHCP.

Input Parameters: 4 bytes (octet 1,2,3,4)  
Returns: None  

OP CODE|Description|Values
-------|-----------|------
18 |Set Subnet Mask| OUT-BYTE   OUT-BYTE   OUT-BYTE   OUT-BYTE   OUT-BYTE  

The Set Subnet Mask opcode sets the subnet mask.

Input Parameters: 4 bytes (octet 1,2,3,4)  
Returns: None  

OP CODE|Description|Values
-------|-----------|------
19 |Set Gateway	| OUT-BYTE   OUT-BYTE   OUT-BYTE   OUT-BYTE   OUT-BYTE  

The Set Gateway	opcode sets the Gateway IP Address.

Input Parameters: 4 bytes (octet 1,2,3,4)  
Returns: None  

OP CODE|Description|Values
-------|-----------|------
20 |Set Primary DNS| OUT-BYTE   OUT-BYTE   OUT-BYTE   OUT-BYTE   OUT-BYTE  

The Set Primary DNS opcode sets the primary DNS IP address.

Input Parameters: 4 bytes (octet 1,2,3,4)  
Returns: None  

OP CODE|Description|Values
-------|-----------|------
21 |Set Secondary DNS| OUT-BYTE   OUT-BYTE   OUT-BYTE   OUT-BYTE   OUT-BYTE  

The Set Secondary DNS opcode sets the secondary DNS IP address.

Input Parameters: 4 bytes (octet 1,2,3,4)  
Returns: None  

OP CODE|Description|Values
-------|-----------|------
22 |Set Hostname| OUT-BYTE(s)

The Set Hostname opcode stores a null terminated string in the ESP flash memory and will survive a power cycle.  This value is then used during WiFi Connection.

Input Parameters: X bytes - string terminated by a null  
Returns: None  

OP CODE|Description|Values
-------|-----------|------
23 |Create Outgoing Connection| OUT-BYTEs

The Create Outgoing Connection opcode creates an outgoing TCP/IP socket connection to a specified host.

The following parameters need to be specified in the following order:
* Connection Number, 1 byte, Must be from 1-63, connection 0 is reserved for incoming connections.
* Port, 2 bytes, Byte order is least signifigant byte to most significant byte.
* Hostname, x bytes, null terminated string.

Input Parameters: x bytes
Returns: None  

OP CODE|Description|Values
-------|-----------|------
24 |Set Incoming Port| OUT-BYTE   OUT-BYTE

The Set Incoming Port opcode sets listen port for connection 0.

The following parameters need to be specified in the following order:
* Port Number, 2 bytes, Byte order is least signifigant byte to most significant byte.

Input Parameters: 2 bytes
Returns: None  

OP CODE|Description|Values
-------|-----------|------
25 |Out Byte to Connection#| OUT-BYTE   OUT-BYTE

The Out Byte to Connection# opcode sends a byte to the specified connection.

The following parameters need to be specified in the following order:
* Connetion #, 1 byte
* Char, 1 byte

Input Parameters: 2 bytes
Returns: None  

OP CODE|Description|Values
-------|-----------|------
26 |Out String to Connection#| OUT-BYTE   OUT-BYTE(s)

The Out String to Connection# opcode sends a null terminated string to the specified connection.

The following parameters need to be specified in the following order:
* Connetion #, 1 byte
* string, x bytes null terminated

Input Parameters: x bytes
Returns: None  

OP CODE|Description|Values
-------|-----------|------
27 |In Byte From Connection#| OUT-BYTE   IN-BYTE

The In Byte From Connection# opcode returns a byte from the connection communication buffer.  If there are no values in the buffer, the opcode will return a null.  

Input Parameters: 1 byte - Connection Number  
Returns: 1 byte - input value or null    

OP CODE|Description|Values
-------|-----------|------
28 |Chars in Buffer from Connection#| OUT-BYTE   IN-BYTE   OUT-BYTE   OUT-BYTE   OUT-BYTE  

The Chars in Buffer from Connection# opcode returns the numbser of bytes in the connection communication buffer.  This port is exposed through the header on the top of the card and through the USB port on the ESP32 module.   

Input Parameters: 1 byte - Connection Number  
Returns: 1 byte - number of bytes in the buffer 

OP CODE|Description|Values
-------|-----------|------
30 |Get MAC Address| IN-BYTE  IN-BYTE  IN-BYTE  IN-BYTE  IN-BYTE  IN-BYTE    

The Get Mac Address opcode returns the six byte MAC address of the ESP32

The following information is returned in the following order:
* MAC Address, 6 bytes

Input Parameters: None  
Returns: 6 bytes  

## ESP32 Serial Opcodes

OP CODE|Description|Values
-------|-----------|------
6 |Set Baud Rate| OUT-BYTE  OUT-BYTE  OUT-BYTE  OUT-BYTE

The Set Baud Rate opcode sets the baud rate for the ESP async serial port.  This port is exposed through the header on the top of the card and through the USB port on the ESP32 module.   Byte order is least signifigant byte to most significant byte.

Input Parameters: 4 bytes - Baud Rate
Returns: None  

OP CODE|Description|Values
-------|-----------|------
7 |Set Serial Mode| OUT-BYTE

The Set Serial Mode opcode sets the serial communication parameters for the ESP async serial port.  This port is exposed through the header on the top of the card and through the USB port on the ESP32 module.
Parameters are set as follows:
* 0 = 8 data bits, no parity, 1 stop bits
* 1 = 8 data bits, even parity, 1 stop bits
* 2 = 8 data bits, odd parity, 1 stop bits
* 3 = 7 data bits, no parity, 1 stop bits
* 4 = 7 data bits, even parity, 1 stop bits
* 5 = 7 data bits, odd parity, 1 stop bits

Input Parameters: 1 byte - Serial Mode  
Returns: None  

OP CODE|Description|Values
-------|-----------|------
8 |Serial TX Single char| OUT-BYTE

The Serial TX Single char opcode transmits a single byte through the serial communication port.  This port is exposed through the header on the top of the card and through the USB port on the ESP32 module.

Input Parameters: 1 byte - char  
Returns: None  

OP CODE|Description|Values
-------|-----------|------
9 |Serial TX Null Terminated String| OUT-BYTE  OUT-BYTE  OUT-BYTE  OUT-BYTE  OUT-BYTE  OUT-BYTE	…	…	…	…	NULL

The Serial TX Null Terminated String opcode transmits a null terminated string through the serial communication port.  This port is exposed through the header on the top of the card and through the USB port on the ESP32 module.

Input Parameters: X bytes - string terminated by a null  
Returns: None  

OP CODE|Description|Values
-------|-----------|------
10 |Serial RX| IN-BYTE

The Serial RX opcode returns a byte from the serial communication port buffer.  If there are no values in the buffer, the opcode will return a null.  This port is exposed through the header on the top of the card and through the USB port on the ESP32 module.   

Input Parameters: None  
Returns: 1 byte - input value or null    

OP CODE|Description|Values
-------|-----------|------
11 |Chars in Serial Buffer| IN-BYTE

The Chars in Serial Buffer opcode returns the numbser of keystrokes in the serial communication port buffer.  This port is exposed through the header on the top of the card and through the USB port on the ESP32 module.   

Input Parameters: None  
Returns: 1 byte - serial buffer length  

## ESP32 Mouse Opcodes
OP CODE|Description|Values
-------|-----------|------
29 |Get Mouse| IN-BYTE  IN-BYTE  IN-BYTE  IN-BYTE  IN-BYTE  IN-BYTE  IN-BYTE  IN-BYTE  

GetMouse	29	left btn	middle btn	right btn	Wheel Delta	X	X	Y	Y

The Get Mouse opcode gets the current mouse information.

The following information is returned in the following order:
* Left Button Status, 1 byte
* Middle Button Status, 1 byte
* Right Button Status, 1 byte
* Wheel location Delta, 1 byte
* X Coordinate Location, 2 bytes, Byte order is least signifigant byte to most significant byte.
* Y Coordinate Location, 2 bytes, Byte order is least signifigant byte to most significant byte.

Input Parameters: None  
Returns: 8 bytes  

### TO DO
* Improve formatting of README file

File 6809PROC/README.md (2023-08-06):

# MBC6809
6809 processor board (hardware and software) for the Nhyodyne computer system

# Bugs
* I AM SURE THERE ARE SOME . . . .

# JUMPER SETTINGS
## General
        J1 - Enable
                1&2 Only CPU
                2&3 Secondary CPU

        J2 - Clock Divider
                1&2 CLK/2
                3&4 CLK/4
                5&6 CLK/8
                7&8 CLK/16
                9&10 CLK

        J4 - Reset
                1&2 Only CPU
                2&3 Secondary CPU

        JP1 - External Reset Switch

        SW1 - IO Page select
                This maps the IO addresses $00-$FF into the 6809 memory space.  Note that
                the 6809 has address line A15 inverted in order to maintain compatibility
                with the Nhyodyne ROM and RAM cards.   Therefore the MSB (SW8) is inverted.  Most applications for this board expect an IO page of $FE ($FE00-$FEFF).Leading to a default setting of:
                1-on
                2-off
                3-off
                4-off
                5-off
                6-off
                7-off
                8-on

        SW2 - Reset

        SW2 - 6809 toggle address
                This setting sets the IO port that toggles the 6809 in and out of control when it is a secondary CPU.  When it is the only CPU in the system this setting has no effect. Most test applications for this board expect an IO address of $F0.   Reading this IO port will toggle the 6809 active/inactive.
                Leading to a default setting of:
                1-on
                2-on
                3-on
                4-on
                5-off
                6-off
                7-off
                8-off

# BOM

Qty|Reference(s)|Value
--- | --- | ---
5|C1, C14, C15, C16, C17|10µf electrolytic
12|C2, C3, C4, C5, C6, C7, C8, C9, C10, C11, C12, C13|0.1µf
1|D1|Device:LED
1|D2|Device:LED
1|D3|Device:LED
1|D4|Device:LED
1|D5|Device:LED
1|D6|Device:LED
1|D7|1N4148
1|J1|Connecto 02x04 Male Right Angle
1|J2|Connector 01x03  Male Right Angle
1|J3|Connector 01x03  Male Right Angle
1|J4|Connector 02x25  Male Right Angle
1|JP1|Jumper  01x02 Male Right Angle
6|R1, R2, R3, R4, R6, R7|470 ohm
1|R5|10 ohm
1|R8|10K ohm
1|RN1|4700 ohm Network 9
2|RN2, RN4|1K ohm Network 8
1|RN3|1k ohm Network 9
1|RN5|2.2k ohm Network 9
1|SW1|Switch:SW_DIP_x08
1|SW2|Switch:SW_DIP_x08
1|SW3|Switch:SW_Push
1|U1|74LS93
3|U2, U8, U10|74LS244
1|U3|74LS04
2|U4, U7|74LS688
1|U5|74LS245
1|U6|MC6809 (68B09 Preferred)
1|U9|74LS00
1|U11|74LS74
1|U12|74LS07

# SOFTWARE

### MONITOR
This is a simple monitor program, see the "monitor" section of this document for usage instructions. "Monitor" requires that the UART is properly initialized.

It assumes that the 6809 board is set for IOPage $FE.
        * remember that bit A15 is inverted on the board

If the SBC is the only CPU in the system, ensure that jumpers J1 and J4 are set for 1&2, then burn monitor.hex into EPROM. (note that this monitor does not initialize the UART yet, so this is broken at the moment)

If the SBC is secondary to a Z80, the monitor.com file can be run from CP/M or the monitor.hex file can be loaded from the monitor. Ensure that jumpers J1 and J4 are set for 2&3, the 6809 toggle IO address is set for $F0 and the 6809 board is set for IOPage $FE.
        * remember that bit A15 is inverted on the board

To run from the MBC Z80 monitor

first set the MPCL to allow RAM in the low bank
```
>O 7C 80
>O 78 80
```
Then load the .HEX file.
```
>L
```

Finally transfer control to the 6809 by reading the toggle register
```
>I F0
```

### SCREAM
This is a quick program that can be put on a ROM to test the 6809 board. It will output a continuous stream of "A"s from the UART. It does not require the stack to be available and is pretty much the simplest code imaginable. :)

It assumes that the 6809 board is set for IOPage $FE.
        * remember that bit A15 is inverted on the board

If the SBC is the only CPU in the system, ensure that jumpers J1 and J4 are set for 1&2, then burn scream.hex into EPROM.  (note that this monitor does not initialize the UART yet, so this is broken at the moment)

If the SBC is secondary to a Z80, the scrm.com file can be run from CP/M or the scream.hex file can be loaded from the monitor. Ensure that jumpers J1 and J4 are set for 2&3, the 6809 toggle IO address is set for $F0 and the 6809 board is set for IOPage $FE.
        * remember that bit A15 is inverted on the board

To run from the MBC Z80 monitor

first set the MPCL to allow RAM in the low bank
```
>O 7C 80
>O 78 80
```
Then load the .HEX file.
```
>L
```

Finally transfer control to the 6809 by reading the toggle register
```
>I F0
```

The '09 should reset and run this program

### MONITOR Program

Monitor is a simple machine language monitor that will allow you to view and manipulate the 6809 operating environment.

Monitor Supports the following Commands:

```
	* D -  XXXX YYYY - Dump memory from XXXX to YYYY
        * L - Load a S19 file into RAM
       	* M XXXX YY  - update the ram at XXXX with value YY
        * G XXXX - Execute program at XXXX
        * P - PRINT CONTENTS OF STACK
```

### FLEX09 OPERATING SYSTEM

MEMORY MAP:

```
 C000  -------
          I     System Stack
 C080  -------
          I     Input Buffer
 C100  -------
          I
          I     Utility Area
          I
 C400  -------  Startup Code
          I
          I
 C700  -------
          I     Printer Spooler Stub
 C71C  -------
          I     Open Space
          I
 C840  -------
          I
          I     System/User FCB
          I
 C980  -------
          I
          I     System I/O FCB's
          I     (FLEX Initialize at CA00)
          I
 CC00  -------
          I
          I     Flex CCP
          I
 CD00  -------
          I
          I
          I     Disk Operating System
          I
          I
 D3E1  -------
          I     Driver Vector Table
                D3E1 ADDDEV      * add an IRQ handler to table
                D3E3 DELDEV      * delete an IRQ handler from table
                D3E5 INCHNE      * INPUT CHARACTER W/O ECHO
                D3E7 IHNDLR      * IRQ INTERRUPT HANDLER
                D3E9 SWIVEC      * SWI3 VECTOR LOCATION
                D3EB IRQVEC      * IRQ VECTOR LOCATION
                D3ED TMOFF       * TIMER OFF ROUTINE
                D3EF TMON        * TIMER ON ROUTINE
                D3F1 TMINT       * TIMER INITIALIZATION
                D3F3 MONITR      * MONITOR ENTRY ADDRESS
                D3F5 TINIT       * TERMINAL INITIALIZATION
                D3F7 STAT        * CHECK TERMINAL STATUS
                D3F9 VOUTCH      * OUTPUT CHARACTER
                D3FB VINCH       * INPUT CHARACTER W/ ECHO
          I
 D400  -------
          I
          I
          I     File Management-System
          I
          I
          I
 DE00  -------
          I     DISK DRIVER ROUTINE JUMP TABLE
                DE00 READ      Read a single sector
                DE03 WRITE     Write a single sector
                DE06 VERIFY    Verify last sector written
                DE09 RESTORE   Restore head to track #0
                DE0C DRIVE     Select the specified drive
                DE0F CHKRDY    Check for drive ready
                DE12 QUICK     Quick check for drive ready
                DE15 INIT      Driver initialize (cold start)
                DE18 WARM      Driver initialize (warm start)
                DE1B SEEK      Seek to specified track
          I
          I     Disk Drivers
          I
 FE00  -------
          I    I/O Area
 FF00  -------
          I    Work RAM
 FFEF  -------
                FFF0    RESERVED
                FFF2    SWI3 VECTOR
                FFF4    SWI2 VECTOR
                FFF6    FIRQ VECTOR
                FFF8    IRQ VECTOR
                FFFA    SWI VECTOR
                FFFC    NMI VECTOR
                FFFE    RESET VECTOR
 FFFF  -------
```

### FLEX09 OPERATING SYSTEM TODO LIST
* PPIDE WRITE IS SORTA BROKEN (needs read following write to work?!?!?)
* ADD CPM COMMAND
* INSTRUCTIONS FOR DRIVE AND DSKY CONFIGURATION
* FLOPPY DRIVERS
* RTC
* VIDEO/KB SUPPORT
* DOCUMENTATION
* ALLOW MULTIPLE IMAGES ON CF
* Document slices and drives
* write assign program
* C compiler?
* CODE CLEANUP
* SUPPORT FOR STAND ALONE FLEX
* WRITE PRINTER DRIVER
0145 CCC0 39         PINIT     RTS (jmp Printerinit)
0149 CCD8 39         PCHK      RTS (jmp Check Printer)
0153 CCE4 39         POUT      RTS (jmp output to Printer)

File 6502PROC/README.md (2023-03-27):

# MBC65C02
65C02 processor board (hardware and software) for the Nhyodyne computer system

## BUGS
* the WDC 65C02 cannot be used in the board, it needs to be an older chip.  I recently found a document from a builder that was working on a PET clone that (I believe) may give a clue to resolving this issue.

> . . . s. Additionally, although for all
practical purposes here the W65C02 is, functionally, entirely equivalent to the original 6502,
it is not a direct drop-in replacement. It has slightly different pin functions, different, more
stringent timing requirements due to its ability to run several times faster than the original
NMOS 6502 and it is a CMOS part with CMOS-level, rather than TTL-level compatible I/O
thresholds. The potential timing incompatibility mostly relates to memory write operations and how
briefly (only 10 ns) valid data is guaranteed to remain on the data bus upon the falling edge of
the system clock (time THW). If your memory write strobe decoding doesn’t have time to react
before the data disappears from the data bus you’re going to have trouble with memory write
operations! If you peruse my circuit diagrams you’ll notice that a pair of 74HCT244 driver
chips directly buffer the W65C02S’s data I/O pins to the systems data bus. These chips
provide CMOS-level to TTL-level threshold conversion and add critical, delayed time
extension to THW. To doubly ensure that the memory write strobe is available well ahead of
schedule, it is decoded by a super-fast 74AC family device. . . . .

# JUMPER SETTINGS
## General
        J1 - Enable
                1&2 Only CPU
                2&3 Secondary CPU

        J2 - Clock Divider
                1&2 CLK/2
                3&4 CLK/4
                5&6 CLK/8
                7&8 CLK/16
                9&10 CLK

        J4 - Reset
                1&2 Only CPU
                2&3 Secondary CPU

        JP1 - External Reset Switch

        SW1 - IO Page select
                This maps the IO addresses $00-$FF into the 6502 memory space.  Note that
                the 6502 has address line A15 inverted in order to maintain compatibility
                with the Nhyodyne ROM and RAM cards.   Therefore the MSB (SW8) is inverted.  Most test applications for this board expect an IO page of $03 ($0300-$03FF).Leading to a default setting of:
                1-off
                2-off
                3-on
                4-on
                5-on
                6-on
                7-on
                8-off

        SW2 - Reset

        SW2 - 6502 toggle address
                This setting sets the IO port that toggles the 6502 in and out of control when it is a secondary CPU.  When it is the only CPU in the system this setting has no effect. Most test applications for this board expect an IO address of $FF ($0300-$03FF).   Reading this IO port will toggle the 6502 active/inactive.
                Leading to a default setting of:
                1-off
                2-off
                3-off
                4-off
                5-off
                6-off
                7-off
                8-off

# BOM (V1.4)

Qty|Reference(s)|Value
--- | --- | ---
5|C1, C2, C16, C17, C18|10�F electrolytic
13|C3, C4, C5, C6, C7, C8, C9, C10, C11, C12, C13, C14, C15|0.1�F
1|D1|Device:LED
1|D2|1N4148
1|D3|Device:LED
1|D4|Device:LED
1|D5|Device:LED
1|D6|Device:LED
1|D7|Device:LED
1|J1|Connector 01x03 Male  Rt angle
1|J2|Connector 02x04 Male  Rt angle
1|J3|Connector  01x03 Male  Rt angle
1|J4|Connector 02x25 Male Rt angle
1|JP1|Jumperx2
1|R1|3.3K
1|R2|10
6|R3, R5, R6, R7, R8, R9|470
1|R4|10K
1|RN1|4700 Network 09
2|RN2, RN5|1K Network 08
1|RN3|1K Network 05
1|RN4|2.2K Network 09
1|SW1|Switch:SW_DIP_x08
1|SW2|Switch:SW_DIP_x08
1|SW3|Switch:SW_Push
3|U1, U8, U9|74LS244
1|U2|74LS93
1|U3|74LS32
1|U4|74LS04
2|U5, U10|74LS688
1|U6|65CE02
1|U7|74LS245
1|U11|74LS74
1|U12|74LS07

# SOFTWARE
### HI
This is a quick program that will print a "Hi" message to the UART then return control to the Z80.  It does not require the stack to be available and is pretty much the simplest code imaginable. :)   "Hi" requires that the UART is properly initialized.

This requires the SBC to be secondary to a Z80 SBC.

the HI.hex file can be loaded from the monitor. Ensure that jumpers J1 and J4 are set for 2&3, the 6502 toggle IO address is set for $FF and the 65C02 board is set for IOPage 03.
        * remember that bit A15 is inverted on the board so the dip switch is set to $83.

To run from the MBC Z80 monitor

first set the MPCL to allow RAM in the low bank
```
>O 7C 80
>O 78 80
```
Then load the .HEX file.
```
>L
```

Finally transfer control to the 65C02 by reading the toggle register
```
>I FF
```

### SCREAM
This is a quick program that can be put on a ROM to test the 65C02 board. It will output a continuous stream of "A" at 9600 baud from the UART. It does not require the stack to be available and is pretty much the simplest code imaginable. :)
"SCREAM" initializes the UART for 9600,n,8,1.

It assumes that the 65C02 board is set for IOPage 03.
        * remember that bit A15 is inverted on the board so the dip switch is set to $83.

The scrm.com file can be run from CP/M or the scream.hex file can be loaded from the monitor. Ensure that jumpers J1 and J4 are set for 2&3, the 6502 toggle IO address is set for $FF and the 65C02 board is set for IOPage 03.
        * remember that bit A15 is inverted on the board so the dip switch is set to $83.

 ** Note that this program will change the baud rate to 9600.

To run from the MBC Z80 monitor

first set the MPCL to allow RAM in the low bank
```
>O 7C 80
>O 78 80
```
Then load the .HEX file.
```
>L
```

Finally transfer control to the 65C02 by reading the toggle register
```
>I FF
```

The '02 should reset and run this program

### MONITOR
This is a simple monitor program, see the "monitor" section of this document for usage instructions. "Monitor" requires that the UART is properly initialized as it would be when the SBC is secondary to the Z80 proc board.  If you are running this board as the primary CPU, see the Firmware section.

It assumes that the 65C02 board is set for IOPage 03.
        * remember that bit A15 is inverted on the board so the dip switch is set to $83.

The monitor.com file can be run from CP/M or the monitor.hex file can be loaded from the Z80 monitor. Ensure that jumpers J1 and J4 are set for 2&3, the 6502 toggle IO address is set for $FF and the 65C02 board is set for IOPage 03.
        * remember that bit A15 is inverted on the board so the dip switch is set to $83.

To run from the MBC Z80 monitor

first set the MPCL to allow RAM in the low bank
```
>O 7C 80
>O 78 80
```
Then load the .HEX file.
```
>L
```

Finally transfer control to the 65C02 by reading the toggle register
```
>I FF
```

## Using the 6502 MONITOR
The Nhyodyne system now uses the SuperMON monitor.  It is a powerful machine language monitor that will allow you to view and manipulate the 6502 operating environment.

```
 INSERT SUPERMON DOCS HERE
```

## Using DOS65
        DOS/65 is provided as the operating system for the Nhyodyne 65C02 board.  See the DOS/65 documentation for more information on how to use DOS/65.

        If you are running the 6502 board as a secondary CPU, the CP/M program DOS65.com will load DOS/65 and transition control from Z80 CP/M to 65c02 DOS/65.  DOS65.COM also requires DOS65DRV.SYS on the same drive as it contains all of the device drivers that are loaded into another RAM bank.

        DOS/65 will read and write from HD_512 style ROMWBW slices and CP/M images. HD_1024 images are not supported.

        Rather than running .COM files, DOS/65 will run .CO6 files.

        currently DOS/65 supports PPIDE, serial, and DSKYNG devices

        DOS/65 utility programs:
        CPM.CO6 - return control to the Z80 and Boot CPM into a sane state.
        ASSIGN.CO6 - dynamically adjust drive mapping
        SEDIT.CO6 - Text editor (only partially working)
        DBASIC.CO6 - ehBasic for DOS/65
        FORMAT.CO6 - Utility to format floppy disks for DOS/65
        S19.CO6 - Utility to dump S19 files to memory.
        WRITEOS.CO6 - Save Running OS version to device for Boot.

        The following utilities are from the DOS/65 distribution and are documented in the DOS/65 documentation.
        alloc.CO6 - DOS/65 drive utility
        compare.CO6- DOS/65 compare utility
        debug.CO6- DOS/65 debugger
        edit.CO6- DOS/65 line editor
        asm.CO6- DOS/65 assembler
        bcompile.CO6- DOS/65 Basic-E compiler
        copy.CO6- DOS/65 file copy utility
        run.CO6- DOS/65 Basic-E run time

# 6502 ROM
If the 6502 processor board is the only CPU board in your Nhyodyne system ensure J1 is set for 1&2 (Only CPU) and J4 is set for 1&2 (Only CPU).   The ROM.BIN file can be placed in ROM (starting at 0000) to bring the system up to the ROM monitor.
TO BOOT DOS/65 FROM A PRIMARY 6502 CPU:
   L (SEND FILE LOWMON.S19)
   G 1000 ( TO RUN LOWMON)
   >037C 80
   >0378 8E
   L (SEND FILE DOS65.S19)
   G D000 (OR W XX to write os to a specified device)

# Items left on the DOS/65 To Do list:
        * Hardware support for RTC
        * Hardware support for ORIGINAL DSKY
        * Hardware Support for VDC/Keyboard
        * Hardware support for Dual Serial
        * XMODEM
        * DOCUMENTATION
        * TEST HOSTED AND STAND ALONE (ALL FUNCTIONS, WITH ONE BUILD)

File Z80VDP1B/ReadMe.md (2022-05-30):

Z80 VPD1B is a board for V9938/V9958 using CXA1645 for video output stage

The following patches are needed (per Dan's build. Mine are similar but slightly different):
- HSYNC (pin 5, U12) needs to be low, not floating I tied it to pin U12,Pin 1 with a jumper
- SCIN (U5) needs the CLK signal, and this is disabled when JP1 is off (which it typically must be off in order to not conflict with the system clock Wink
-- I clipped pin 12 on the bus connector and installed JP1
- R, G, and B need 470 ohm pull downs to ground from pins 22,23 & 24 on the VDP (U3)
- jumper VRESET/VDS (U12, pin 4) to +5 VCC

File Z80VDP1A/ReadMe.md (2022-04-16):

Z80 VPD1A is a board for V9938/V9958 using discrete components for video output stage

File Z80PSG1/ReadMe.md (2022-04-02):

# Z80 PSG V1

Provides GI AY-3-8910 Programmable Sound Generator with three channel FM synthesis

Atari or MSX compatible joysticks or paddles

Power, chip select, and status LEDs

IO ports $E8-$EB

# Jumpers

JP1 AY-3-8910 test input pins 1-2, default is none

J5 Pins 1-2 all channels merged into channel C, Pins 3-4 all channels merged into channel A, default is none

pins 5-7 audio oscillator /2
pins 7-9 audio oscillator /8
pins 6-8 audio oscillator /1
pins 8-10 audio oscillator /4

default is pins 5-7 closed assuming a 3.5795 MHz audio oscillator

J1 POT/VCC pins 1-2-3, default is none
J2 JOYBG/VCC pins 1-2-3, default is none

need to select Atari or MSX compatible joystick, use J1 and J2 to enable one or the other or leave empty for neither

# Notes

Found an error in the schematic, the audio oscillator should be 3.5795 MHz not 3.57595 MHz.  Updated the tech data to reflect change however PCB will have 3.57595 MHz on silkscreen.  Just ignore it and use the proper frequency oscillator.  It will become obvious once you try to purchase a oscillator that the 3.57595 MHz does not exist.  Will update on the next revision of the PCB but not worth a respin on this alone

Another error is the STATUS LED D3 only is reversed so it must be installed *opposite* of the silkscreen indication.  This is a result of an import error from an older version of the KiCAD schematic.  The other LEDs are OK

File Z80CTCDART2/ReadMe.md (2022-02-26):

# Counter / Timer Channels (CTC) and Dual Asynchronous Receiver Transmitter (DART) board for Z80 Modular Backplane Computer

Adds CTC system timer and DART dual serial ports

External interrupts with Zilog compatible interrupt priority modes

Fully configurable CTC settings for multiple timers and system ticks

Uses built in 4.9152 MHz clock or system CPU clock

Clock dividers for system ticker at selected tick frequencies

Dual RS-232 level serial ports plus dual TTL level serial ports for USB adapters

Power LED

Chip Select LED

Interrupt LED

Default IO Address Port $B0-B7; IO port address is set using SW1-SW5
SW1=1-2 - A7 (high)
SW2=2-3 - A6 (low)
SW3=1-2 - A5 (high)
SW4=1-2 - A4 (high)
SW5=2-3 - A3 (low)

# Jumpers

J1 Interrupt Select, connect 1-2 for INT# default, connect 2-3 for NMI#, none for no interrupt
Note: can connect J1 pin 2 via flying lead to Z80 processor IM2 connector

J2 TTL Level Serial Ports Power, connect 1-2 for Port A Power, connect 3-4 for Port B Power, default is none

P4 connect 1-2 for system timer 2, none for no system timer, default is 1-2.

P10 connect 1-2 for system timer 3, none for no system timer, default is 1-2

# Notes

There is a problem with the Z80 CTCDART V2 serial port channel B but there is an easy fix. The DCDB pin needs to be grounded for the serial port channel B to receive data. Just add a short jumper between DCDB U9, pin 22 (DART or SIO) and Ground U9, pin 31 (or any other close by ground pin) on the copper side of the PCB.

Serial port channel B transmits data just fine but due to a peculiar initialization of the DART or SIO pins DCDB has to be grounded for it to receive data. This change will be added to the upcoming PCB respin for Z80 CTCDART V3 when it comes out.

There is a problem with the bus transceiver logic and a patch to fix it.  The IO port decoder/data_dir design for CTCDART & DUALPIO does not share a common 16 byte IO address space as planned.  The fix has been tested on Z80 CTCDART V2 and Z80 DUALPIO V2 boards and works as intended using only 8 IO port addresses with no interference.  Both CTCDART and DUALPIO boards have this problem and need the patch.

It is an easy patch to make.  No trace cuts and just one jumper on copper side and another on the component side.  The fix is optional because the board works fine unmodified but requires an entire 16 byte block to not interfere with another board.  For example, $B0-$BF & $A0-AF unmodified or $B0-B7 & $B8-BF modified.

Placing the CTCDART at $B0-$B7 and DUALPIO at $B8-$BF and they coexist peaceably. TIMER/C runs no problem as does 2PIOTST generates the right responses. No more annoying interference between the two boards.

The patch is the same for both boards:

U17, pin 2 (74LS138) to U5, pin 13 (74LS14); jumper on copper side
U5, pin 12 (74LS14) to U1A, pin 5 (74LS20); lift pins & jumper on component side

The board is close enough now for some extended testing to shake out any other possible bugs. These problems will be fixed in the next PCB respin.

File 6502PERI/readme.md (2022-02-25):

README
February 25, 2022 at 10:45:13 AM EST

This board (hopefully) will provide a CPU6502-specific multi-IO capability consisting of
a 65C22 VIA, 65C51 ACIA, and a 6581 SID sound device.

Open Items
==========

1.	Actual design has not yet been tested, but is based on existing designs, so
	there should be no reason why it wouldn't work.
	
2.	Regarding the I/O port allocation, depending on which functions remain in the 
	final design, there may be an opportunity to remove the DIP switches and replace
	with two jumpers. The SID requires a 32-byte block of port addresses, the VIA 
	requires 16, and the ACIA requires 4. Thus, blocks are allocated in 64-byte 
	chunks. Using this board will likely limit the number of other MBC boards that 
	can co-exist with it and/or greatly change the port allocations such that changes
	to RomWBW might be needed.

3.	Board real estate is exceedingly tight and there's no room for the additional
	circuitry required to derive the PHI1 clock from the main system clock.
	All of the spare pins on the main buss connector have been allocated, so for this
	development version, there's a tie point next to the 65C22 which should
	connect with a "flying lead" to the clock on the MBC6502 CPU card. As such,
	these cards should be kept next to each other. If chip functions are removed
	from the board (i.e., eliminating the 65C51 or the SID), then there would be
	room for an on-board clock divider. Since the 6502-specific software already 
	utilizes the console board, there may be limited use for this function and
	eliminating it would create the necessary room.
	
4.	Again, due to board space, the serial output of the 65C51 is brought out to a
	1x6 0.1" header for use with a TTL-to-USB converter.

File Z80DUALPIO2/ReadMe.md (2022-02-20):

# Dual Parallel IO board for Z80 Modular Backplane Computer

Add a pair of PIOs with external connectors, 32 GPIO pins plus 4 strobe pins, 4 ready pins, and power pins 

External interrupts with Zilog compatible interrupt priority modes

Fully configurable PIO settings for wide variety of uses

Power LED

Chip Select LED

Interrupt LED

Default IO ports $B8-$BF

# Jumpers

J1 is Interrupt Selection, close 1-2 for INT#, close 2-3 for NMI#, none for no interrupt.
Note: pin 2 can be connected to Z80 Processor IM2 connector via flying lead

Default IO Address Port $B8-BF; IO port address is set using SW1-SW5
SW1=1-2 - A7 (high)
SW2=2-3 - A6 (low)
SW3=1-2 - A5 (high)
SW4=1-2 - A4 (high)
SW5=1-2 - A3 (high)

# Notes

There is a problem with the bus transceiver logic and a patch to fix it.  The IO port decoder/data_dir design for CTCDART & DUALPIO does not share a common 16 byte IO address space as planned.  The fix has been tested on Z80 CTCDART V2 and Z80 DUALPIO V2 boards and works as intended using only 8 IO port addresses with no interference.  Both CTCDART and DUALPIO boards have this problem and need the patch.

It is an easy patch to make.  No trace cuts and just one jumper on copper side and another on the component side.  The fix is optional because the board works fine unmodified but requires an entire 16 byte block to not interfere with another board.  For example, $B0-$BF & $A0-AF unmodified or $B0-B7 & $B8-BF modified.

Placing the CTCDART at $B0-$B7 and DUALPIO at $B8-$BF and they coexist peaceably. TIMER/C runs no problem as does 2PIOTST generates the right responses. No more annoying interference between the two boards.

The patch is the same for both boards:

U17, pin 2 (74LS138) to U5, pin 13 (74LS14); jumper on copper side
U5, pin 12 (74LS14) to U1A, pin 5 (74LS20); lift pins & jumper on component side

The board is close enough now for some extended testing to shake out any other possible bugs. These problems will be fixed in the next PCB respin.

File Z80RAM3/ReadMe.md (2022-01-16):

# Z80 RAM board for Z80 Modular Backplane Computer

Provides Random Access Memory (RAM) for Z80 MBC

128KB to 1MB capacity

Uses 32 pin SRAMs 128KB or 512KB

Uses two DS1210 Non-Volatile Memory Controllers with CR2032 for battery backed NVRAM

RAM Memory Page Configuration Latch for 32KB Upper and/or Lower memory pages

Boot jumper, capacity for multiple RAM boards in system, only one must be bootable

Power LED

RAM0 and RAM1 Chip Select LEDs

Default IO port $7C

# Jumpers

JP1 is Boot RAM Option. Pins 1-2 closed (default) for Boot enable assuming single RAM board present in system. Will cause upper 32KB RAM page to be present at power on or after reset. Only one RAM board per system can be boot enabled. Multiple RAM boards can be present but only one can be boot enabled and rest must have JP1 open or bus contention.

K2 is RAM size option. Pins 1-2 closed for 128KB RAMs (both RAM0 and RAM1) (default). Pins 2-3 closed for 512KB RAMs.

K7 is for 32 pin 128KB RAM0 or 512KB RAM0.  Pins 1-2 closed for 512KB RAM (default). Pins 2-3 closed for 128KB RAM.  One or the other must be selected.

K9 is for select Upper 32KB of RAM to be fixed, Lower 32KB of RAM to be switchable Pins 2-3 closed (default) or both to be switchable pins 1-2 closed.  Note: software needs to support latter feature.  RomWBW assumes default of pins 2-3 closed. One or the other must be selected.

K6 is to select whether fixed top of RAM to be 32KB pins 1-2 closed (default) or 16KB pins 2-3 closed.  One or the other must be selected. 

JP2 is battery select jumper option supports both RAM0 and RAM1. Pins 1-2 closed for onboard CR2032 battery (default).  Pins 3-4 must be closed also if CR2032 is used (default).  Optionally pins 3-4 can be used as external battery connector with pin 4 is positive terminal, pin 3 is negative (ground).  

JP3 and JP4 for U16 DS1210 installed pin 1-2 open (default).  Closed both pins 1-2 to bypass.  Default is both open.  Note, if pins 1-2 closed U16 must be removed or unreliable operation.

K3 DS1210 RAM0 power sag tolerance feature, pins 1-2 closed 10% power sag (default), pins 2-3 closed 5%. One or the other must be selected or NVRAM will not work. If experiencing random lockups try 10% power sag setting or diagnose power supply issues.

JP5 and JP6 for U9 DS1210 installed pin 1-2 open (default).  Closed both pins 1-2 to bypass.  Default is both open.  Note, if pins 1-2 closed U9 must be removed or unreliable operation.

K1 DS1210 RAM1 power sag tolerance feature, pins 1-2 closed 10% power sag (default), pins 2-3 closed 5%. One or the other must be selected or NVRAM will not work. If experiencing random lockups try 10% power sag setting or diagnose power supply issues.

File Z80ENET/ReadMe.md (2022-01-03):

Folder for Z80 ENET board. Uses RTL8019AS IC for Ethernet capability 

Caution: this board is still in active design phase. Not recommended for PCB manufacturing at this point

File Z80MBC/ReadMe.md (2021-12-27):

Folder for Z80 MBC general files not specific to any board such as test software, datasheets, build notes, etc.

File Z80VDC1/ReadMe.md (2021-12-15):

# Terminal Video Board for Z80 Modular Backplane Computer

Based on MOS 6568 Video Display Controller (same as Commodore 128D 80 column mode)

External TTL RGB connector

Up to 64KB dedicated video RAM using two 41464 DRAM chips

Intended for Video Terminal Console, 80 column mode

Some graphics and color capability as well

Default IO ports $E4-$E5

Demostrated working with GBS-8200 VGA upscaler device however requires custom interface with analog color signals from pseudo-VGA interface (no not install VGA-F connector) and CSYNC signal.  Route wire jumper from U7, pin 9 to U3, pin 6 and wire jumper from U3, pin 14 to CSYNC on connector (replaces HSYNC signal) to feed GBS-8200.  Issues will be resolved in future Z80 VDC V2 PCB respin.

# Jumpers

K1 is Interrupt Selection.  Pins 1-2 closed for INT# and pins 2-3 closed for NMI#.  No jumper for none (default).  Note pin 2 can be connected to the IM2 connector on the processor board via flying lead.

JP1 and JP2 are not really option jumpers but PCB debugging tools due to conflicting technical data on MOS 8568 VDC.  JP1 connects #RES to bRESET# and is 1-2 closed (default).  JP2 connects INIT to GND and is 1-2 closed (default).  These are solid assumptions but if prove incorrect can be fixed with wire wrap connections rather than cuts and jumpers.

NOTE: JP1 and JP2 proved useful as the conflict between MOS technical data and Commodore C128D schematic was resolved and the Commodore C128D schematic was correct.  Do not install jumpers JP1 and JP2 and instead solder wires between Pin 1 of JP1 footprint and Pin 2 of JP2 footprint.  Likewise Pin 1 of JP2 footprint to Pin 2 of JP1 footprint.  Be sure to use insulated wires so there are not inadvertent short circuits between jumpers or rest of board circuitry. 

P4 is VGA connector sync selection.  Pins 1-3 closed for HSYNC (default) and pins 3-5 closed for HSYNC#.  Pins 2-4 closed for VSYNC (default) and pins 4-6 closed for VSYNC#.  Polarity of HSYNC and VSYNC varies depending on monitor although most use HSYNC and VSYNC by default.  One or the other must be selected or monitor display will not work.  VSYNC and HSYNC are active high.  VSYNC# and HSYNC# are active low.

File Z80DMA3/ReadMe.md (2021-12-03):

# Direct Memory Access for Z80 Modular Backplane Computer system

Optional DMA for Z80 processor

Flash File System support -- requires 39SF040 Flash ROMs

External DMA connector

Power LED

Chip Select LED

DMA transfer LED

DMA Ready LED

Default IO ports $E0-$E1

Note: The Z80 DMA V2 board has not yet gone to PCB production however the differences between it and the Z80 DMA V1 board are very minor.

# Jumpers

K2 Interrupt Selection, connect 1-2 for INT#, connect 2-3 for NMI#, default is none
Note: pin 2 can be connected to Z80 Processor IM2 connector via flying lead

K1 is external DMA connector.  Default is 2-3 closed, otherwise connected to DMA capable IO board

JP2 is source of DMA Address Direction, close 1-2 for BAIb# or close 2-3 for BUSAK#. Default is close 2-3 BUSAK#

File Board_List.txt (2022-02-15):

# Board List
Here is a list of the current circuit boards:

Z80 backplane V1
Z80 backplane V2
Z80 clock V2
Z80 CTCDART V2
Z80 DMA V2
Z80 DUALPIO V2
Z80 DUART (PLCC-44)
Z80 FDC V1
Z80 KBDMSE V1
Z80 PPIDE V2
Z80 processor V3
Z80 prototype V2
Z80 RAM V3
Z80 ROM V2
Z80 serial V2 (DIP-40)
Z80 serial V3 (PLCC-44)
Z80 VDC V1
6502 processor (in development)

Upcoming boards to be released:

Z80 PRINT V1
Z80 PSG V1
Z80 SPI
Z80 USD-SD V1
Z80 VDP V1
Z80 ADCDAC V1
Z80 BusTerm V1
Z80 ENET V1

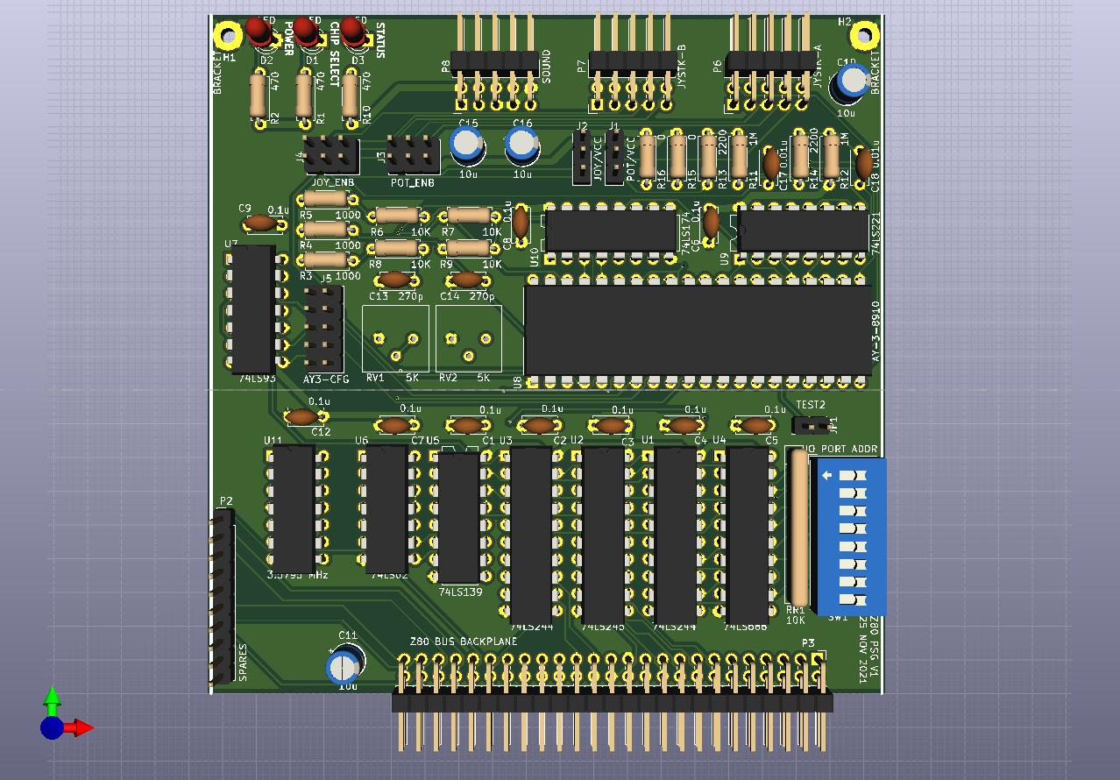
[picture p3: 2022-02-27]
Z80PSG1/Z80PSG1.jpg

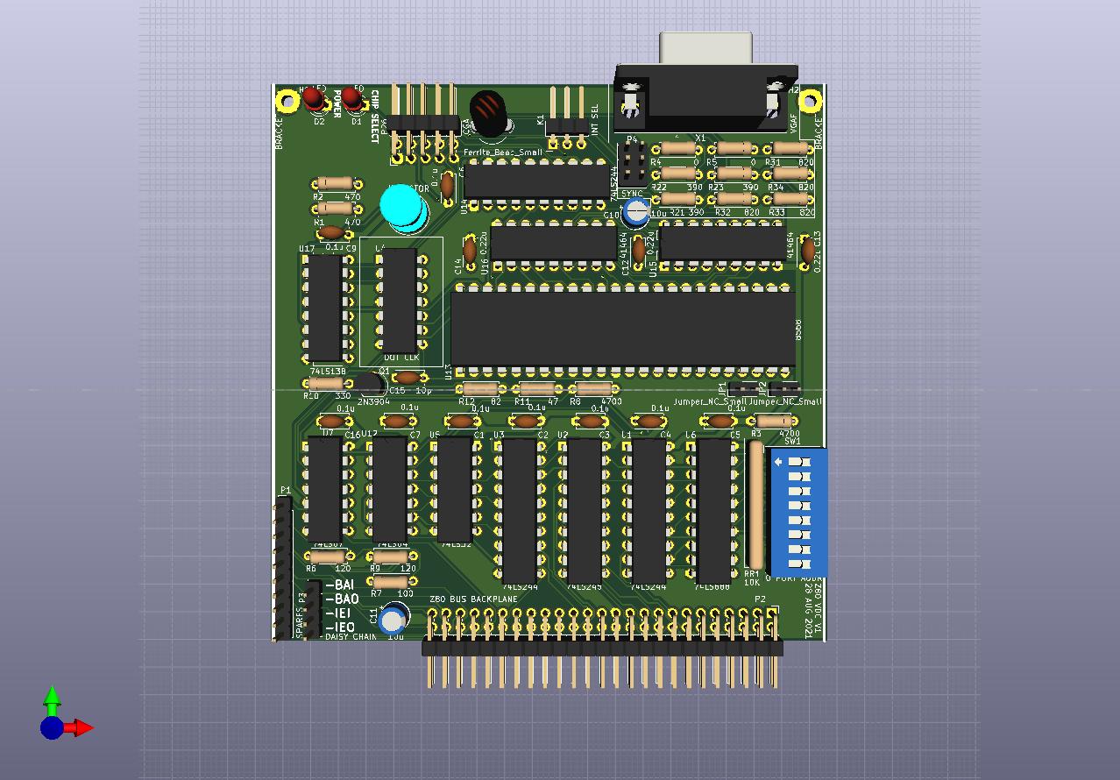
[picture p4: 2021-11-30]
Z80VDC1/Z80VDC.jpg

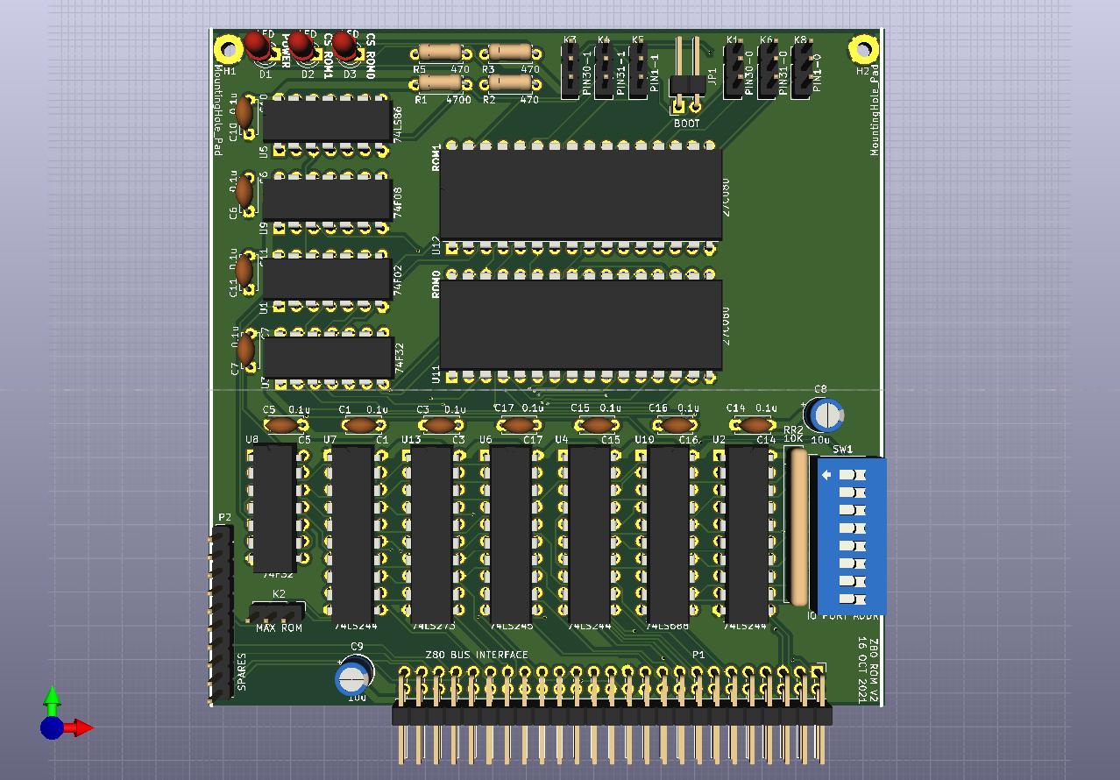
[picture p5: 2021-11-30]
Z80ROM2/Z80ROM2.jpg

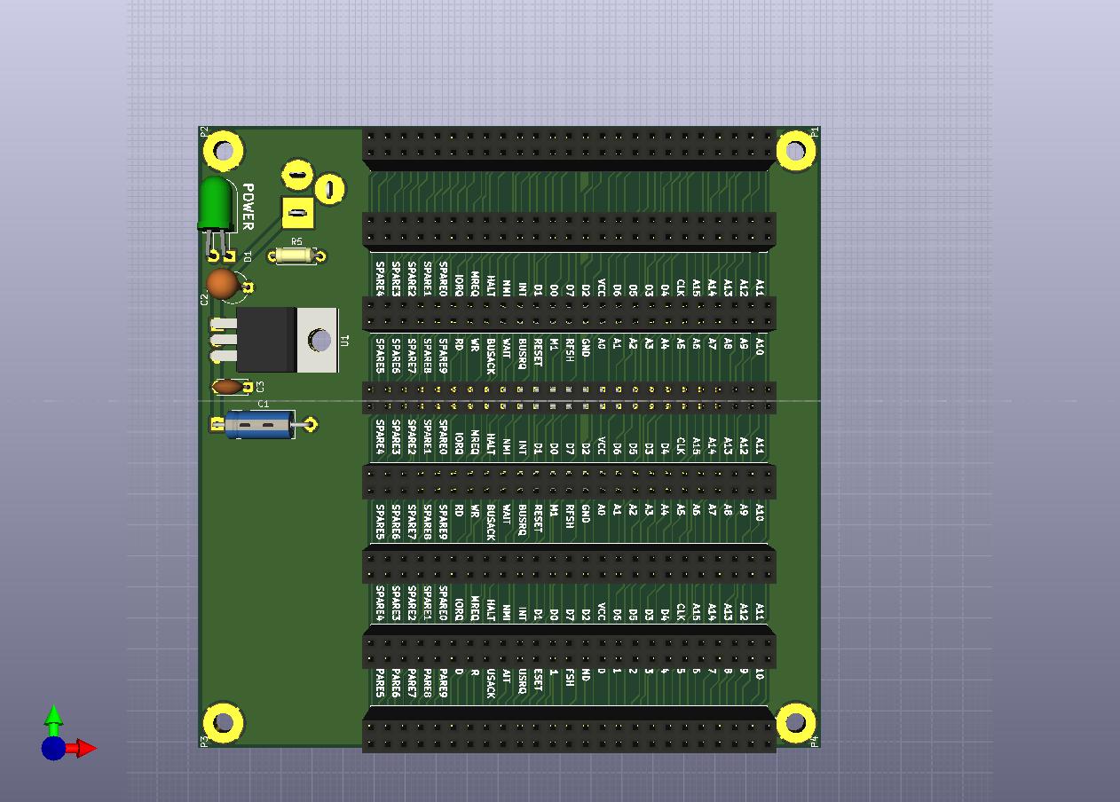
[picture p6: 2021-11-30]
Z80BCKPLN1/Z80BCKPLN.jpg

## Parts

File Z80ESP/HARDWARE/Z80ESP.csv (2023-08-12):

Source: | N:\Projects\nhyodyne\Z80ESP\HARDWARE\Z80ESP.kicad_sch
Date: | 8/12/2023 9:23:46 AM
Tool: | Eeschema (6.0.11)
Generator: | C:\Program Files\KiCad\6.0\bin\scripting\plugins/bom_csv_grouped_by_value.py
Component Count: | 63
Individual Components:
Item | Qty | Reference(s) | Value | LibPart | Footprint | Datasheet
 |  | C1 | 0.1µF | Z80ESP-rescue:C-device-Z80SERIAL-rescue-Z80SERIAL2-rescue-Z80SERIAL3-rescue-Z80SOUND-rescue-Z80VIDEO-rescue-Z80VDP1B-rescue | Capacitor_THT:C_Disc_D5.0mm_W2.5mm_P5.00mm
 |  | C2 | 0.1µF | Z80ESP-rescue:C-device-Z80SERIAL-rescue-Z80SERIAL2-rescue-Z80SERIAL3-rescue-Z80SOUND-rescue-Z80VIDEO-rescue-Z80VDP1B-rescue | Capacitor_THT:C_Disc_D5.0mm_W2.5mm_P5.00mm
 |  | C3 | 0.1µF | Z80ESP-rescue:C-device-Z80SERIAL-rescue-Z80SERIAL2-rescue-Z80SERIAL3-rescue-Z80SOUND-rescue-Z80VIDEO-rescue-Z80VDP1B-rescue | Capacitor_THT:C_Disc_D5.0mm_W2.5mm_P5.00mm
 |  | C4 | 0.1µF | Z80ESP-rescue:C-device-Z80SERIAL-rescue-Z80SERIAL2-rescue-Z80SERIAL3-rescue-Z80SOUND-rescue-Z80VIDEO-rescue-Z80VDP1B-rescue | Capacitor_THT:C_Disc_D5.0mm_W2.5mm_P5.00mm
 |  | C5 | 0.1µF | Z80ESP-rescue:C-device-Z80SERIAL-rescue-Z80SERIAL2-rescue-Z80SERIAL3-rescue-Z80SOUND-rescue-Z80VIDEO-rescue-Z80VDP1B-rescue | Capacitor_THT:C_Disc_D5.0mm_W2.5mm_P5.00mm
 |  | C6 | 0.1µF | Z80ESP-rescue:C-device-Z80SERIAL-rescue-Z80SERIAL2-rescue-Z80SERIAL3-rescue-Z80SOUND-rescue-Z80VIDEO-rescue-Z80VDP1B-rescue | Capacitor_THT:C_Disc_D5.0mm_W2.5mm_P5.00mm
 |  | C7 | 0.1µF | Z80ESP-rescue:C-device-Z80SERIAL-rescue-Z80SERIAL2-rescue-Z80SERIAL3-rescue-Z80SOUND-rescue-Z80VIDEO-rescue-Z80VDP1B-rescue | Capacitor_THT:C_Disc_D5.0mm_W2.5mm_P5.00mm
 |  | C8 | 0.1µF | Z80ESP-rescue:C-device-Z80SERIAL-rescue-Z80SERIAL2-rescue-Z80SERIAL3-rescue-Z80SOUND-rescue-Z80VIDEO-rescue-Z80VDP1B-rescue | Capacitor_THT:C_Disc_D5.0mm_W2.5mm_P5.00mm
 |  | C9 | 0.1µF | Z80ESP-rescue:C-device-Z80SERIAL-rescue-Z80SERIAL2-rescue-Z80SERIAL3-rescue-Z80SOUND-rescue-Z80VIDEO-rescue-Z80VDP1B-rescue | Capacitor_THT:C_Disc_D5.0mm_W2.5mm_P5.00mm
 |  | C10 | 0.1µF | Z80ESP-rescue:C-device-Z80SERIAL-rescue-Z80SERIAL2-rescue-Z80SERIAL3-rescue-Z80SOUND-rescue-Z80VIDEO-rescue-Z80VDP1B-rescue | Capacitor_THT:C_Disc_D5.0mm_W2.5mm_P5.00mm
 |  | C11 | 10µF | Z80ESP-rescue:CP-device-Z80SERIAL-rescue-Z80SERIAL2-rescue-Z80SERIAL3-rescue-Z80SOUND-rescue-Z80VIDEO-rescue-Z80VDP1B-rescue | Capacitor_THT:CP_Radial_D5.0mm_P2.50mm
 |  | C12 | 10µF | Z80ESP-rescue:CP-device-Z80SERIAL-rescue-Z80SERIAL2-rescue-Z80SERIAL3-rescue-Z80SOUND-rescue-Z80VIDEO-rescue-Z80VDP1B-rescue | Capacitor_THT:CP_Radial_D5.0mm_P2.50mm
 |  | C13 | 0.1µF | Z80ESP-rescue:C-device-Z80SERIAL-rescue-Z80SERIAL2-rescue-Z80SERIAL3-rescue-Z80SOUND-rescue-Z80VIDEO-rescue-Z80VDP1B-rescue | Capacitor_THT:C_Disc_D5.0mm_W2.5mm_P5.00mm
 |  | C14 | 0.1µF | Z80ESP-rescue:C-device-Z80SERIAL-rescue-Z80SERIAL2-rescue-Z80SERIAL3-rescue-Z80SOUND-rescue-Z80VIDEO-rescue-Z80VDP1B-rescue | Capacitor_THT:C_Disc_D5.0mm_W2.5mm_P5.00mm
 |  | C15 | 100nf | Z80ESP-rescue:C-device-Z80SERIAL-rescue-Z80SERIAL2-rescue-Z80SERIAL3-rescue-Z80SOUND-rescue-Z80VIDEO-rescue-Z80VDP1B-rescue | Capacitor_THT:C_Disc_D5.0mm_W2.5mm_P5.00mm
 |  | C16 | 10µF | Z80ESP-rescue:CP-device-Z80SERIAL-rescue-Z80SERIAL2-rescue-Z80SERIAL3-rescue-Z80SOUND-rescue-Z80VIDEO-rescue-Z80VDP1B-rescue | Capacitor_THT:CP_Radial_D5.0mm_P2.50mm
 |  | D2 | LED | Z80ESP-rescue:LED-device | LED_THT:LED_D3.0mm
 |  | D3 | 1N4001 | Diode:1N4001 | Diode_THT:D_DO-41_SOD81_P10.16mm_Horizontal | http://www.vishay.com/docs/88503/1n4001.pdf
 |  | D6 | 1N4001 | Diode:1N4001 | Diode_THT:D_DO-41_SOD81_P10.16mm_Horizontal | http://www.vishay.com/docs/88503/1n4001.pdf
 |  | H1 | BRACKET | Z80ESP-rescue:MountingHole_Pad-mechanical | MountingHole:MountingHole_2.2mm_M2_Pad
 |  | H2 | BRACKET | Z80ESP-rescue:MountingHole_Pad-mechanical | MountingHole:MountingHole_2.2mm_M2_Pad
 |  | J3 | AUDIO OUT | Connector:Conn_01x02_Male | Connector_PinHeader_2.54mm:PinHeader_1x02_P2.54mm_Horizontal | ~
 |  | J4 | ESP_SERIAL_1 | Connector:Conn_01x03_Male | Connector_PinHeader_2.54mm:PinHeader_1x03_P2.54mm_Horizontal | ~
 |  | J5 | ESP_SERIAL_0 | Connector:Conn_01x03_Male | Connector_PinHeader_2.54mm:PinHeader_1x03_P2.54mm_Vertical | ~
 |  | J6 | VGA | Connector:DB15_Female_HighDensity_MountingHoles | Connector_Dsub:DSUB-15-HD_Female_Horizontal_P2.29x1.98mm_EdgePinOffset3.03mm_Housed_MountingHolesOffset4.94mm | ~
 |  | J7 | KEYBOARD AND MOUSE | Connector_Generic:Conn_02x05_Odd_Even | Connector_PinHeader_2.54mm:PinHeader_2x05_P2.54mm_Horizontal | ~
 |  | P2 | Z80 BUS BACKPLANE | Z80ESP-rescue:CONN_25X2-conn-Z80SERIAL3-rescue-Z80SOUND-rescue-Z80VIDEO-rescue-Z80VDP1B-rescue | Connector_PinHeader_2.54mm:PinHeader_2x25_P2.54mm_Horizontal
 |  | R1 | 120Ω | Device:R | Resistor_THT:R_Axial_DIN0207_L6.3mm_D2.5mm_P7.62mm_Horizontal | ~
 |  | R2 | 470Ω | Z80ESP-rescue:R-device-Z80SERIAL-rescue-Z80SERIAL2-rescue-Z80SERIAL3-rescue-Z80SOUND-rescue-Z80VIDEO-rescue-Z80VDP1B-rescue | Resistor_THT:R_Axial_DIN0207_L6.3mm_D2.5mm_P7.62mm_Horizontal
 |  | R3 | 120Ω | Device:R | Resistor_THT:R_Axial_DIN0207_L6.3mm_D2.5mm_P7.62mm_Horizontal | ~
 |  | R4 | 2KΩ | Device:R | Resistor_THT:R_Axial_DIN0207_L6.3mm_D2.5mm_P7.62mm_Horizontal | ~
 |  | R5 | 1KΩ | Device:R | Resistor_THT:R_Axial_DIN0207_L6.3mm_D2.5mm_P7.62mm_Horizontal | ~
 |  | R6 | 2KΩ | Device:R | Resistor_THT:R_Axial_DIN0207_L6.3mm_D2.5mm_P7.62mm_Horizontal | ~
 |  | R7 | 400Ω | Device:R | Resistor_THT:R_Axial_DIN0207_L6.3mm_D2.5mm_P7.62mm_Horizontal | ~
 |  | R8 | 800Ω | Device:R | Resistor_THT:R_Axial_DIN0207_L6.3mm_D2.5mm_P7.62mm_Horizontal | ~
 |  | R9 | 400Ω | Device:R | Resistor_THT:R_Axial_DIN0207_L6.3mm_D2.5mm_P7.62mm_Horizontal | ~
 |  | R10 | 800Ω | Device:R | Resistor_THT:R_Axial_DIN0207_L6.3mm_D2.5mm_P7.62mm_Horizontal | ~
 |  | R11 | 400Ω | Device:R | Resistor_THT:R_Axial_DIN0207_L6.3mm_D2.5mm_P7.62mm_Horizontal | ~
 |  | R12 | 800Ω | Device:R | Resistor_THT:R_Axial_DIN0207_L6.3mm_D2.5mm_P7.62mm_Horizontal | ~
 |  | R13 | 1KΩ | Device:R | Resistor_THT:R_Axial_DIN0207_L6.3mm_D2.5mm_P7.62mm_Horizontal | ~
 |  | R14 | 120Ω | Device:R | Resistor_THT:R_Axial_DIN0207_L6.3mm_D2.5mm_P7.62mm_Horizontal | ~
 |  | R15 | 120Ω | Device:R | Resistor_THT:R_Axial_DIN0207_L6.3mm_D2.5mm_P7.62mm_Horizontal | ~
 |  | R16 | 270Ω | Device:R | Resistor_THT:R_Axial_DIN0207_L6.3mm_D2.5mm_P7.62mm_Horizontal | ~
 |  | R17 | 150Ω | Device:R | Resistor_THT:R_Axial_DIN0207_L6.3mm_D2.5mm_P7.62mm_Horizontal | ~
 |  | RR1 | 10KΩ | Z80ESP-rescue:RR8-device-Z80SERIAL-rescue-Z80SERIAL2-rescue-Z80SERIAL3-rescue-Z80SOUND-rescue-Z80VIDEO-rescue-Z80VDP1B-rescue | Resistor_THT:R_Array_SIP9
 |  | RR2 | 1KΩ | Z80ESP-rescue:RR8-device-Z80SERIAL-rescue-Z80SERIAL2-rescue-Z80SERIAL3-rescue-Z80SOUND-rescue-Z80VIDEO-rescue-Z80VDP1B-rescue | Resistor_THT:R_Array_SIP9
 |  | SW1 | IO PORT ADDR | Switch:SW_DIP_x08 | Button_Switch_THT:SW_DIP_SPSTx08_Slide_9.78x22.5mm_W7.62mm_P2.54mm | ~
 |  | U1 | 74LS04 | 74xx:74LS04 | Package_DIP:DIP-14_W7.62mm | http://www.ti.com/lit/gpn/sn74LS04
 |  | U2 | 74LS244 | Z80ESP-rescue:74LS244-RESCUE-Z80PROC-Z80CLOCK-rescue-Z80GENERIC_IO-rescue-Z80PPIDE-rescue-Z80SERIAL-rescue-Z80SERIAL-rescue-Z80SERIAL2-rescue-Z80SERIAL3-rescue-Z80SOUND-rescue-Z80VIDEO-rescue-Z80VDP1B-rescue | Package_DIP:DIP-20_W7.62mm
 |  | U3 | 74LS245 | Z80ESP-rescue:74LS245-RESCUE-Z80PROC-Z80CLOCK-rescue-Z80GENERIC_IO-rescue-Z80PPIDE-rescue-Z80SERIAL-rescue-Z80SERIAL-rescue-Z80SERIAL2-rescue-Z80SERIAL3-rescue-Z80SOUND-rescue-Z80VIDEO-rescue-Z80VDP1B-rescue | Package_DIP:DIP-20_W7.62mm
 |  | U4 | 74LS244 | Z80ESP-rescue:74LS244-RESCUE-Z80PROC-Z80CLOCK-rescue-Z80GENERIC_IO-rescue-Z80PPIDE-rescue-Z80SERIAL-rescue-Z80SERIAL-rescue-Z80SERIAL2-rescue-Z80SERIAL3-rescue-Z80SOUND-rescue-Z80VIDEO-rescue-Z80VDP1B-rescue | Package_DIP:DIP-20_W7.62mm
 |  | U5 | 74LS32 | 74xx:74LS32 | Package_DIP:DIP-14_W7.62mm | http://www.ti.com/lit/gpn/sn74LS32
 |  | U6 | 74LS32 | 74xx:74LS32 | Package_DIP:DIP-14_W7.62mm | http://www.ti.com/lit/gpn/sn74LS32
 |  | U7 | 74HC595 | 74xx:74HC595 | Package_DIP:DIP-16_W7.62mm | http://www.ti.com/lit/ds/symlink/sn74hc595.pdf
 |  | U8 | 74HC165 | 74xx:74HC165 | Package_DIP:DIP-16_W7.62mm | https://assets.nexperia.com/documents/data-sheet/74HC_HCT165.pdf
 |  | U9 | 74HC595 | 74xx:74HC595 | Package_DIP:DIP-16_W7.62mm | http://www.ti.com/lit/ds/symlink/sn74hc595.pdf
 |  | U10 | 74LS688 | 74xx:74LS688 | Package_DIP:DIP-20_W7.62mm | http://www.ti.com/lit/gpn/sn74LS688
 |  | U11 | 74HC165 | 74xx:74HC165 | Package_DIP:DIP-16_W7.62mm | https://assets.nexperia.com/documents/data-sheet/74HC_HCT165.pdf
 |  | U12 | ESP32_MODULE | CUSTOM_LIB:ESP32_MODULE | CUSTOM:ESP32_MODULE
 |  | U13 | ESP32_MODULE | CUSTOM_LIB:ESP32_MODULE | CUSTOM:ESP32_MODULE
 |  | U14 | 74LS32 | 74xx:74LS32 | Package_DIP:DIP-14_W7.62mm | http://www.ti.com/lit/gpn/sn74LS32
 |  | U15 | 74LS244 | 74xx:74LS244 | Package_DIP:DIP-20_W7.62mm | http://www.ti.com/lit/ds/symlink/sn74ls244.pdf
 |  | U16 | 74LS07 | 74xx:74LS07 | Package_DIP:DIP-14_W7.62mm | www.ti.com/lit/ds/symlink/sn74ls07.pdf
Collated Components:
Item | Qty | Reference(s) | Value | LibPart | Footprint | Datasheet
1 | 12 | C1, C2, C3, C4, C5, C6, C7, C8, C9, C10, C13, C14 | 0.1µF | Z80ESP-rescue:C-device-Z80SERIAL-rescue-Z80SERIAL2-rescue-Z80SERIAL3-rescue-Z80SOUND-rescue-Z80VIDEO-rescue-Z80VDP1B-rescue | Capacitor_THT:C_Disc_D5.0mm_W2.5mm_P5.00mm
2 | 3 | C11, C12, C16 | 10µF | Z80ESP-rescue:CP-device-Z80SERIAL-rescue-Z80SERIAL2-rescue-Z80SERIAL3-rescue-Z80SOUND-rescue-Z80VIDEO-rescue-Z80VDP1B-rescue | Capacitor_THT:CP_Radial_D5.0mm_P2.50mm
3 | 1 | C15 | 100nf | Z80ESP-rescue:C-device-Z80SERIAL-rescue-Z80SERIAL2-rescue-Z80SERIAL3-rescue-Z80SOUND-rescue-Z80VIDEO-rescue-Z80VDP1B-rescue | Capacitor_THT:C_Disc_D5.0mm_W2.5mm_P5.00mm
4 | 1 | D2 | LED | Z80ESP-rescue:LED-device | LED_THT:LED_D3.0mm
5 | 2 | D3, D6 | 1N4001 | Diode:1N4001 | Diode_THT:D_DO-41_SOD81_P10.16mm_Horizontal | http://www.vishay.com/docs/88503/1n4001.pdf
6 | 2 | H1, H2 | BRACKET | Z80ESP-rescue:MountingHole_Pad-mechanical | MountingHole:MountingHole_2.2mm_M2_Pad
7 | 1 | J3 | AUDIO OUT | Connector:Conn_01x02_Male | Connector_PinHeader_2.54mm:PinHeader_1x02_P2.54mm_Horizontal | ~
8 | 1 | J4 | ESP_SERIAL_1 | Connector:Conn_01x03_Male | Connector_PinHeader_2.54mm:PinHeader_1x03_P2.54mm_Horizontal | ~
9 | 1 | J5 | ESP_SERIAL_0 | Connector:Conn_01x03_Male | Connector_PinHeader_2.54mm:PinHeader_1x03_P2.54mm_Vertical | ~
10 | 1 | J6 | VGA | Connector:DB15_Female_HighDensity_MountingHoles | Connector_Dsub:DSUB-15-HD_Female_Horizontal_P2.29x1.98mm_EdgePinOffset3.03mm_Housed_MountingHolesOffset4.94mm | ~
11 | 1 | J7 | KEYBOARD AND MOUSE | Connector_Generic:Conn_02x05_Odd_Even | Connector_PinHeader_2.54mm:PinHeader_2x05_P2.54mm_Horizontal | ~
12 | 1 | P2 | Z80 BUS BACKPLANE | Z80ESP-rescue:CONN_25X2-conn-Z80SERIAL3-rescue-Z80SOUND-rescue-Z80VIDEO-rescue-Z80VDP1B-rescue | Connector_PinHeader_2.54mm:PinHeader_2x25_P2.54mm_Horizontal
13 | 4 | R1, R3, R14, R15 | 120Ω | Device:R | Resistor_THT:R_Axial_DIN0207_L6.3mm_D2.5mm_P7.62mm_Horizontal | ~
14 | 1 | R2 | 470Ω | Z80ESP-rescue:R-device-Z80SERIAL-rescue-Z80SERIAL2-rescue-Z80SERIAL3-rescue-Z80SOUND-rescue-Z80VIDEO-rescue-Z80VDP1B-rescue | Resistor_THT:R_Axial_DIN0207_L6.3mm_D2.5mm_P7.62mm_Horizontal
15 | 2 | R4, R6 | 2KΩ | Device:R | Resistor_THT:R_Axial_DIN0207_L6.3mm_D2.5mm_P7.62mm_Horizontal | ~
16 | 2 | R5, R13 | 1KΩ | Device:R | Resistor_THT:R_Axial_DIN0207_L6.3mm_D2.5mm_P7.62mm_Horizontal | ~
17 | 3 | R7, R9, R11 | 400Ω | Device:R | Resistor_THT:R_Axial_DIN0207_L6.3mm_D2.5mm_P7.62mm_Horizontal | ~
18 | 3 | R8, R10, R12 | 800Ω | Device:R | Resistor_THT:R_Axial_DIN0207_L6.3mm_D2.5mm_P7.62mm_Horizontal | ~
19 | 1 | R16 | 270Ω | Device:R | Resistor_THT:R_Axial_DIN0207_L6.3mm_D2.5mm_P7.62mm_Horizontal | ~
20 | 1 | R17 | 150Ω | Device:R | Resistor_THT:R_Axial_DIN0207_L6.3mm_D2.5mm_P7.62mm_Horizontal | ~
21 | 1 | RR1 | 10KΩ | Z80ESP-rescue:RR8-device-Z80SERIAL-rescue-Z80SERIAL2-rescue-Z80SERIAL3-rescue-Z80SOUND-rescue-Z80VIDEO-rescue-Z80VDP1B-rescue | Resistor_THT:R_Array_SIP9
22 | 1 | RR2 | 1KΩ | Z80ESP-rescue:RR8-device-Z80SERIAL-rescue-Z80SERIAL2-rescue-Z80SERIAL3-rescue-Z80SOUND-rescue-Z80VIDEO-rescue-Z80VDP1B-rescue | Resistor_THT:R_Array_SIP9
23 | 1 | SW1 | IO PORT ADDR | Switch:SW_DIP_x08 | Button_Switch_THT:SW_DIP_SPSTx08_Slide_9.78x22.5mm_W7.62mm_P2.54mm | ~
24 | 1 | U1 | 74LS04 | 74xx:74LS04 | Package_DIP:DIP-14_W7.62mm | http://www.ti.com/lit/gpn/sn74LS04
25 | 2 | U2, U4 | 74LS244 | Z80ESP-rescue:74LS244-RESCUE-Z80PROC-Z80CLOCK-rescue-Z80GENERIC_IO-rescue-Z80PPIDE-rescue-Z80SERIAL-rescue-Z80SERIAL-rescue-Z80SERIAL2-rescue-Z80SERIAL3-rescue-Z80SOUND-rescue-Z80VIDEO-rescue-Z80VDP1B-rescue | Package_DIP:DIP-20_W7.62mm
26 | 1 | U3 | 74LS245 | Z80ESP-rescue:74LS245-RESCUE-Z80PROC-Z80CLOCK-rescue-Z80GENERIC_IO-rescue-Z80PPIDE-rescue-Z80SERIAL-rescue-Z80SERIAL-rescue-Z80SERIAL2-rescue-Z80SERIAL3-rescue-Z80SOUND-rescue-Z80VIDEO-rescue-Z80VDP1B-rescue | Package_DIP:DIP-20_W7.62mm
27 | 3 | U5, U6, U14 | 74LS32 | 74xx:74LS32 | Package_DIP:DIP-14_W7.62mm | http://www.ti.com/lit/gpn/sn74LS32
28 | 2 | U7, U9 | 74HC595 | 74xx:74HC595 | Package_DIP:DIP-16_W7.62mm | http://www.ti.com/lit/ds/symlink/sn74hc595.pdf
29 | 2 | U8, U11 | 74HC165 | 74xx:74HC165 | Package_DIP:DIP-16_W7.62mm | https://assets.nexperia.com/documents/data-sheet/74HC_HCT165.pdf
30 | 1 | U10 | 74LS688 | 74xx:74LS688 | Package_DIP:DIP-20_W7.62mm | http://www.ti.com/lit/gpn/sn74LS688
31 | 2 | U12, U13 | ESP32_MODULE | CUSTOM_LIB:ESP32_MODULE | CUSTOM:ESP32_MODULE
32 | 1 | U15 | 74LS244 | 74xx:74LS244 | Package_DIP:DIP-20_W7.62mm | http://www.ti.com/lit/ds/symlink/sn74ls244.pdf
33 | 1 | U16 | 74LS07 | 74xx:74LS07 | Package_DIP:DIP-14_W7.62mm | www.ti.com/lit/ds/symlink/sn74ls07.pdf

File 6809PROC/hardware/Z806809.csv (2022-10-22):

Item | Qty | Reference(s) | Value
1 | 5 | C1, C14, C15, C16, C17 | 10µf electrolytic
2 | 12 | C2, C3, C4, C5, C6, C7, C8, C9, C10, C11, C12, C13 | 0.1µf
3 | 1 | D1 | Device:LED
4 | 1 | D2 | Device:LED
5 | 1 | D3 | Device:LED
6 | 1 | D4 | Device:LED
7 | 1 | D5 | Device:LED
8 | 1 | D6 | Device:LED
9 | 1 | D7 | 1N4148
10 | 1 | J1 | Connecto 02x04 Male Right Angle
11 | 1 | J2 | Connector 01x03 Male Right Angle
12 | 1 | J3 | Connector 01x03 Male Right Angle
13 | 1 | J4 | Connector 02x25 Male Right Angle
14 | 1 | JP1 | Jumper 01x02 Male Right Angle
15 | 6 | R1, R2, R3, R4, R6, R7 | 470 ohm
16 | 1 | R5 | 10 ohm
17 | 1 | R8 | 10K ohm
18 | 1 | RN1 | 4700 ohm Network 9
19 | 2 | RN2, RN4 | 1K ohm Network 8
20 | 1 | RN3 | 1k ohm Network 9
21 | 1 | RN5 | 2.2k ohm Network 9
22 | 1 | SW1 | Switch:SW_DIP_x08
23 | 1 | SW2 | Switch:SW_DIP_x08
24 | 1 | SW3 | Switch:SW_Push
25 | 1 | U1 | 74LS93
26 | 3 | U2, U8, U10 | 74LS244
27 | 1 | U3 | 74LS04
28 | 2 | U4, U7 | 74LS688
29 | 1 | U5 | 74LS245
30 | 1 | U6 | MC6809
31 | 1 | U9 | 74LS00
32 | 1 | U11 | 74LS74
33 | 1 | U12 | 74LS07

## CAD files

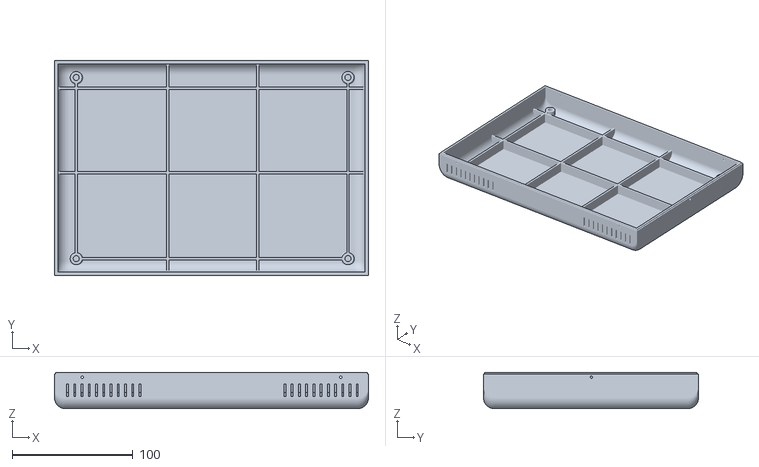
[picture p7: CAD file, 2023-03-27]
enclosure_v2/Attempt 1/Nhyodyne1.stl
260.0 x 178.1 x 30.0

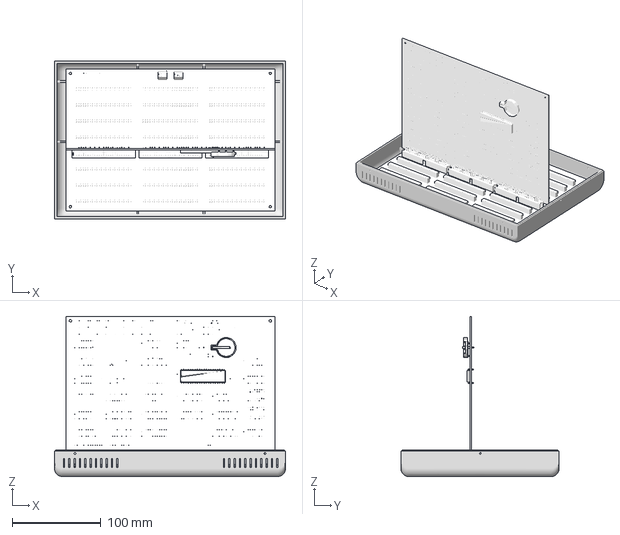
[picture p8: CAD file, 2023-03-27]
enclosure_v2/Attempt 1/render2.3mf
260.0 x 178.1 x 180.2 mm

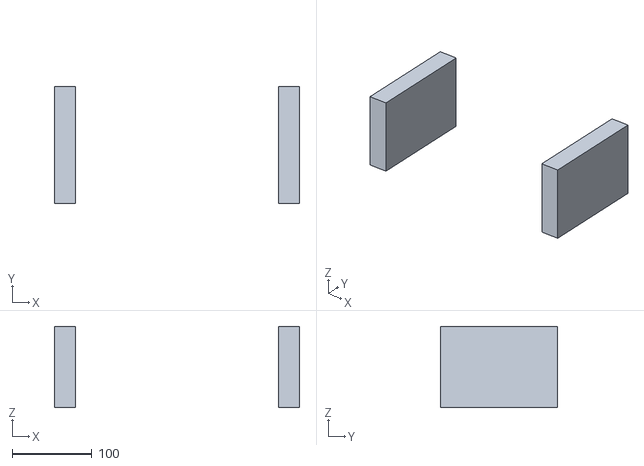
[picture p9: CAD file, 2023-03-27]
enclosure_v2/Attempt 1/4.stl
307.1 x 147.2 x 101.6

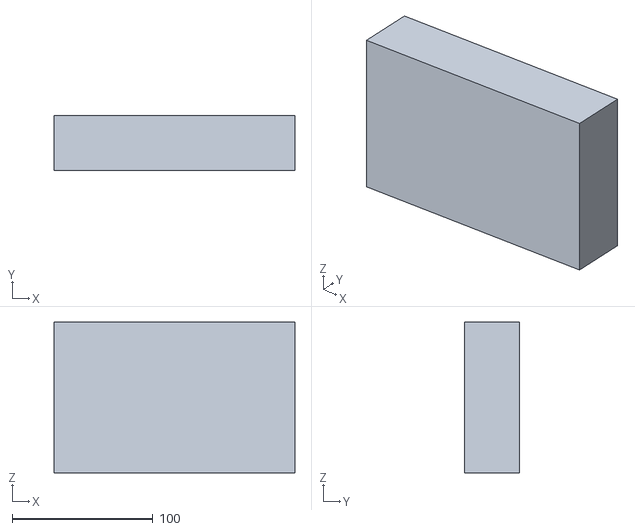
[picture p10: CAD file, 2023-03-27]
enclosure_v2/Attempt 1/5.stl
171.0 x 39.0 x 107.0

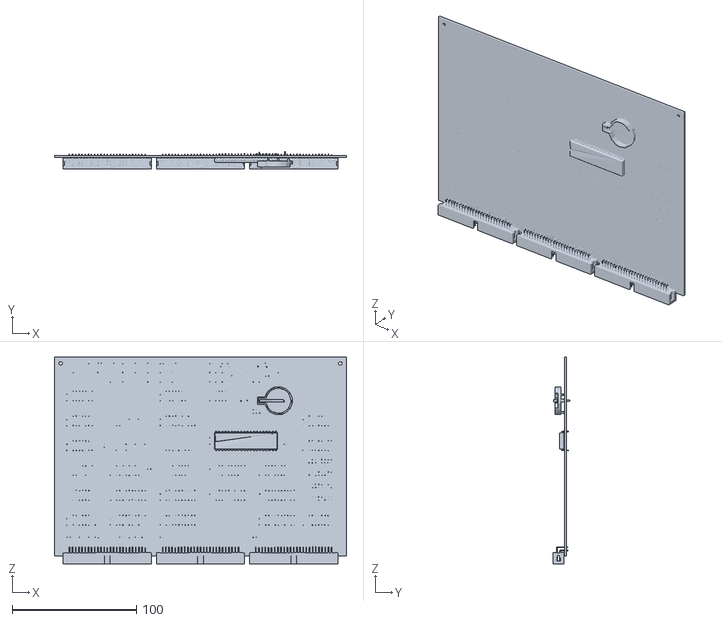
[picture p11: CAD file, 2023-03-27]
enclosure_v2/Attempt 1/1.stl
235.0 x 13.7 x 166.2

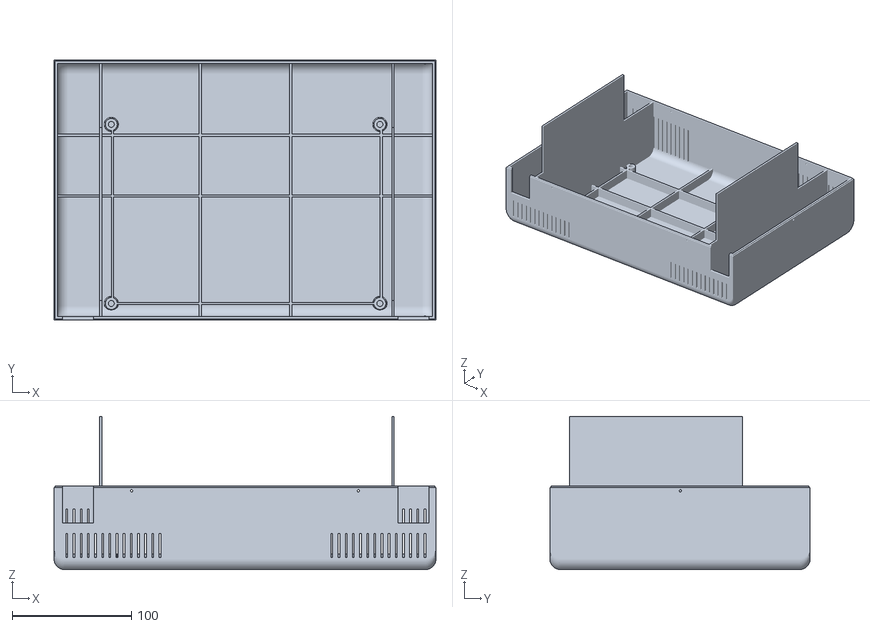
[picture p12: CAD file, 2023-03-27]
enclosure_v2/Attempt 1/3.stl
320.0 x 218.1 x 128.3

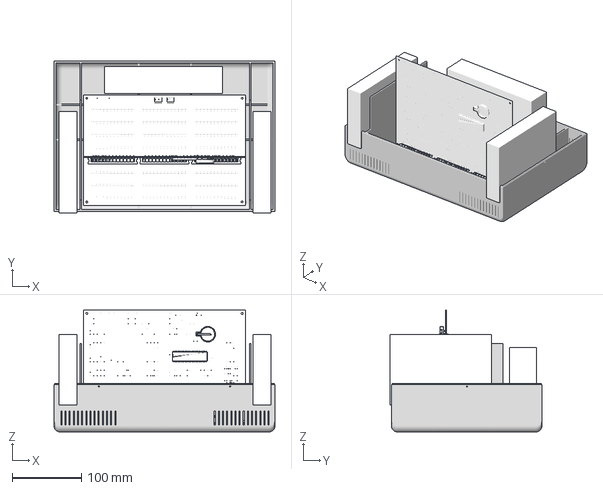
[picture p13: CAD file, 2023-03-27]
enclosure_v2/Attempt 1/render.3mf
320.0 x 220.1 x 176.6 mm

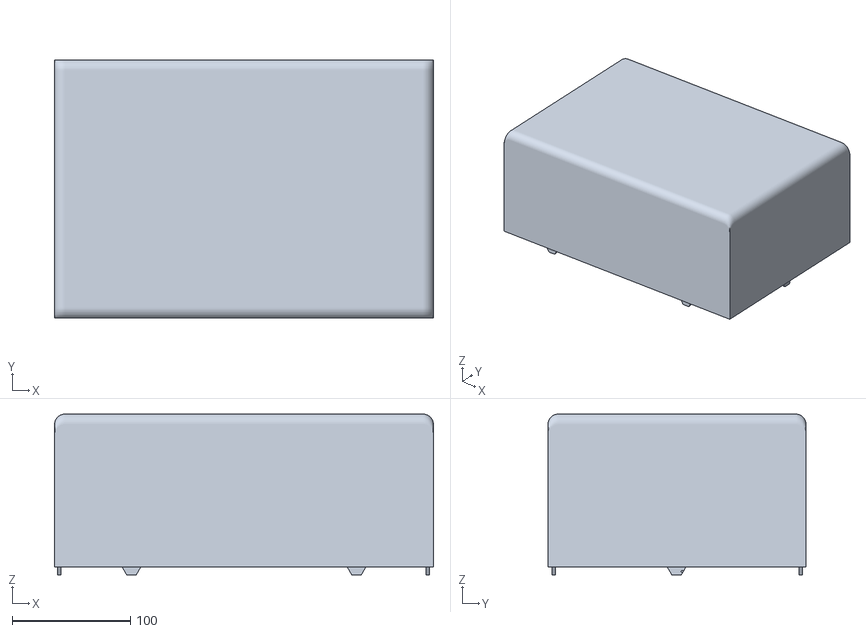
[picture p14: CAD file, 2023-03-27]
enclosure_v2/Attempt 1/6.stl
320.0 x 218.1 x 135.9

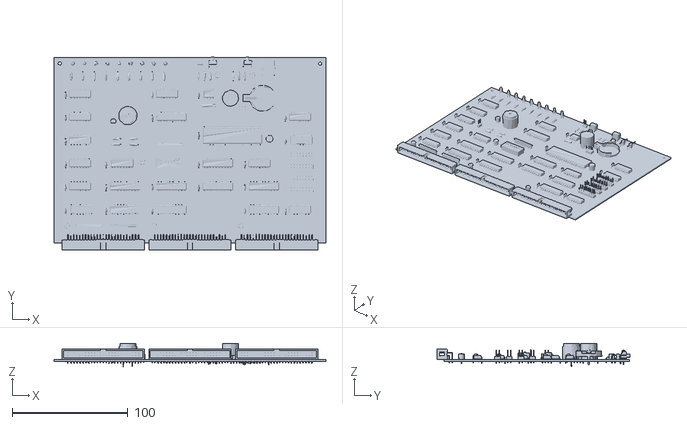
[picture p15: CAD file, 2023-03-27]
enclosure_v2/Attempt 1/template.stl
235.0 x 166.9 x 20.0

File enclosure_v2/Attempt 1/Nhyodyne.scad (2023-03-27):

/* [Box dimensions] */
  Length        = 320;       
  Width         = 220;                     
  TopHeight        = 120;  
  BottomHeight     = 61;  
  SlopeHeight      = 20;
  BackShelf     =130;
  Thick         = 3;//[2:5]  


  
/* [Box options] */
  PCBFeet       = 1;// [0:No, 1:Yes]
  Vent          = 1;// [0:No, 1:Yes]
  Vent_width    = 1.5;   
  Filet         = 9;//[0.1:12] 
  Resolution    = 50;//[1:100] 
  m             = 0.9;
  
/* [PCB_Feet--the_board_will_not_be_exported) ] */
PCBPosX         = 0;
PCBPosY         = 0;
PCBLength       = 142;
PCBWidth        = 360;
FootHeight      = 5;
FootDia         = 10;
FootHole        = 5;  /* 4.4 for melt in 5 for glue in */
  

/* [STL element to export] */
//Top shell
  TShell        = 0;// [0:No, 1:Yes]
//Bottom shell
  BShell        = 1;// [0:No, 1:Yes]
// Show PCBs
  ShowPCB       = 1;// [0:No, 1:Yes]
  ShowVertPCB   = 1;// [0:No, 1:Yes]
  ShowPowerSupply =1;
  ShowDrives    =1;

  
/* [Hidden] */
Couleur1        = "Orange";       
Couleur2        = "OrangeRed";    
Dec_Thick       = Vent ? Thick*2 : Thick; 
Dec_size        = Vent ? Thick*2 : 0.8;

PCBL=PCBLength;
PCBW=PCBWidth;



   
module SlopeRoundBox($a=Length, $b=Width, $c=TopHeight+BottomHeight){
                    $fn=Resolution;     
                         
                        translate([Filet,-Filet/2,Filet])
                        {  
                    minkowski ()
                    {  
              
                    translate([0,($b/2)+1,TopHeight])
                       rotate(a=[0,-90,90])
                          linear_extrude(height =(($b/2)-Filet/2)+1, center = false, convexity = 0, twist = 0)
                              polygon(points=[[0,0],[(SlopeHeight+TopHeight)*-1,0],[(SlopeHeight+TopHeight)*-1,BackShelf*-1],  [TopHeight*-1,($a-Filet*2)*-1],[0,($a-Filet*2)*-1]], paths=[[3,2,1,0]]);                      
                        
                     rotate([270,0,0]){    
                        cylinder(r=Filet,h=Width/2+1, center = false);
                            } 
                        }
                    }
                }// End of SlopeRoundBox Module                


module RoundBox($a=Length, $b=Width, $c=TopHeight+BottomHeight){
                    $fn=Resolution;            
                    translate([0,Filet,Filet]){  
                    minkowski (){                                              
                        cube ([$a-(Length/2),$b-(2*Filet),$c-(2*Filet)], center = false);
                        rotate([0,90,0]){   
                           translate([0,0,Filet]){  
                        cylinder(r=Filet,h=Length/2-(2*Filet), center = false);}
                            } 
                        rotate([270,0,0]){    
                        cylinder(r=Filet,h=.1, center = false);
                            } 
                        }
                    }
                }// End of RoundBox Module

      


module thinFoot(FootDia,FootHole,FootHeight){
    Filet=2;
    color("Orange")   
    translate([0,0,Filet-1.5])
    difference(){
    
    difference(){
            //translate ([0,0,-Thick]){
                cylinder(d=(FootDia),FootHeight-Thick, $fn=100);
                        //}
                    rotate_extrude($fn=100){
                            translate([(FootDia)/1.75,0,0]){
                                    minkowski(){
                                            square(10);
                                            circle(Filet, $fn=100);
                                        }
                                 }
                           }
                   }
            cylinder(d=FootHole/2,FootHeight+1, $fn=100);
               }          
}
module foot(FootDia,FootHole,FootHeight){
    Filet=2;
    color("Orange")   
    translate([0,0,Filet-1.5])
    difference(){
    
    difference(){
            //translate ([0,0,-Thick]){
                cylinder(d=FootDia+Filet,FootHeight-Thick, $fn=100);
                        //}
                    rotate_extrude($fn=100){
                            translate([(FootDia+Filet*2)/2,Filet,0]){
                                    minkowski(){
                                            square(10);
                                            circle(Filet, $fn=100);
                                        }
                                 }
                           }
                   }
            cylinder(d=FootHole,FootHeight+1, $fn=100);
               }          
}


module TopShell(){
    Thick = Thick*2;  
    difference(){    
        difference(){
            union(){    
                     difference() {
                      
                        difference(){
                            union() {                                
                                       

                            difference(){
                                RoundBox($a=Length, $b=Width-2, $c=TopHeight+BottomHeight);
                                translate([Thick/2,Thick/2,Thick/2]){     
                                        RoundBox($a=Length-Thick, $b=Width-Thick-2, $c=TopHeight+BottomHeight-Thick);
                                        }
                                        }
                                    }
                               translate([-Thick,-Thick,TopHeight]){
                                   cube ([Length+100, Width+100, TopHeight+BottomHeight], center=false);
                                            }                                            
                                      }
                                }                                          
                // These are the tabs that attach the top to the bottom
                difference(){
                    union(){
                        
                        // four sides
                        translate([10*Thick +5,Thick,TopHeight]){
                            rotate([90,0,0]){
                                    $fn=6;
                                    cylinder(d=16,Thick/2);
                                    }   
                            }
                            
                       translate([Length-((10*Thick)+5),Thick,TopHeight]){
                            rotate([90,0,0]){
                                    $fn=6;
                                    cylinder(d=16,Thick/2);
                                    }   
                            }

                    translate([10*Thick +5,Width-Thick/2-2.4,TopHeight]){
                            rotate([90,0,0]){
                                    $fn=6;
                                    cylinder(d=16,Thick/2);
                                    }   
                            }
                            
                       translate([Length-((10*Thick)+5),Width-Thick/2-2.4,TopHeight]){
                            rotate([90,0,0]){
                                    $fn=6;
                                    cylinder(d=16,Thick/2);
                                    }   
                            }

                        // front and back
                       translate([Length-Thick-0.5,(Width/2)-Thick/2+2.4,TopHeight]){
                            rotate([90,0,90]){
                                    $fn=6;
                                    cylinder(d=16,Thick/2);
                                    }   
                            }
                      translate([Thick-3.5,(Width/2)-Thick/2+2.4,TopHeight]){
                            rotate([90,0,90]){
                                    $fn=6;
                                    cylinder(d=16,Thick/2);
                                    }   
                            }
                       
                            
                        }




                            
                    } 
                    
                    
            }

       }
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

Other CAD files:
enclosure_v2/Attempt 2/Nhyodyne.scad

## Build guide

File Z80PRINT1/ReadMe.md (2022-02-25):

# Z80 PRINT V1

Provides bi-directional 8 bit parallel port with buffering and full handshake and control signals

Centronics and IBM PC compatible with optional interrupt capability

Power, chip select, interrupt, and two status LEDs

IO ports $E8-$EB

# Jumpers

K1 interrupt select INT# or NMI#, interrupt can optionally be fed to IM2 circuit on Z80 processor board via flying lead

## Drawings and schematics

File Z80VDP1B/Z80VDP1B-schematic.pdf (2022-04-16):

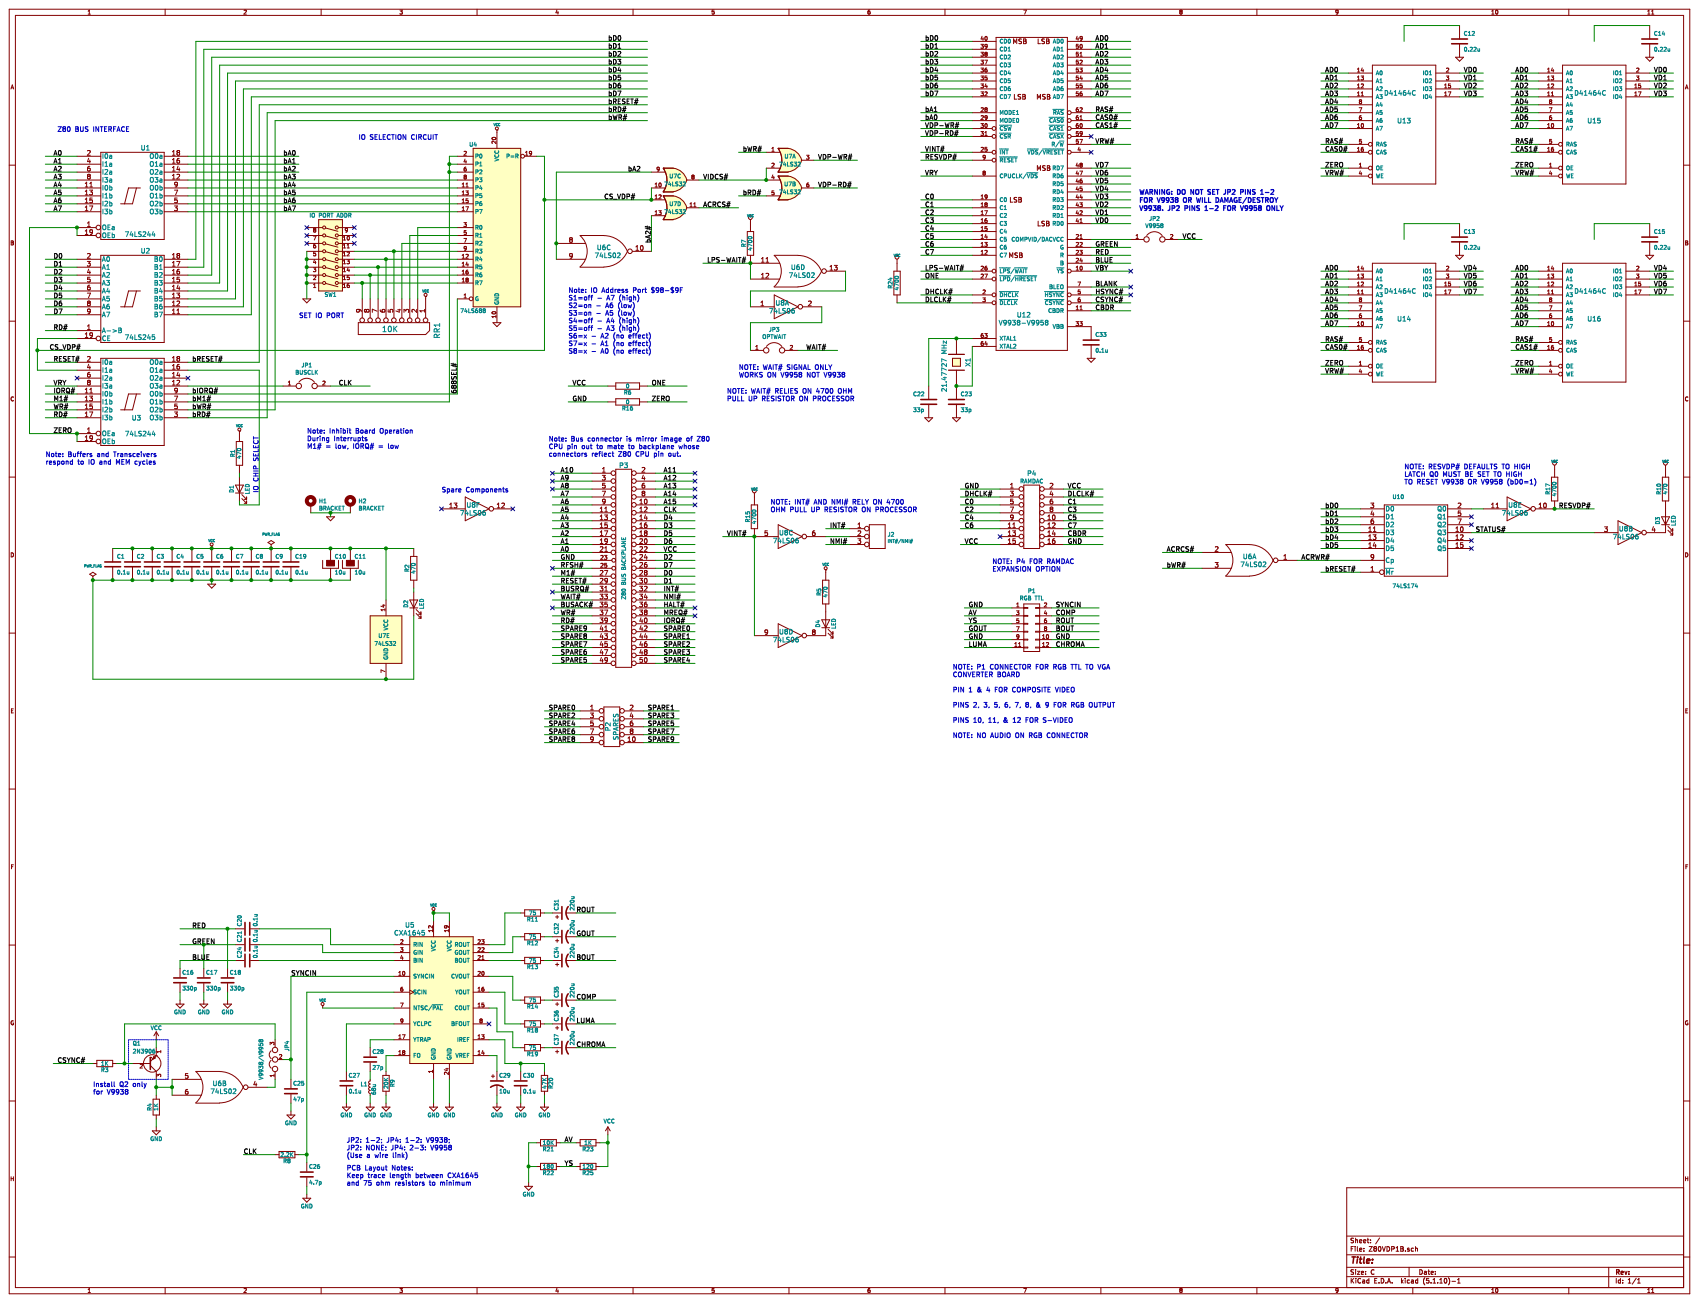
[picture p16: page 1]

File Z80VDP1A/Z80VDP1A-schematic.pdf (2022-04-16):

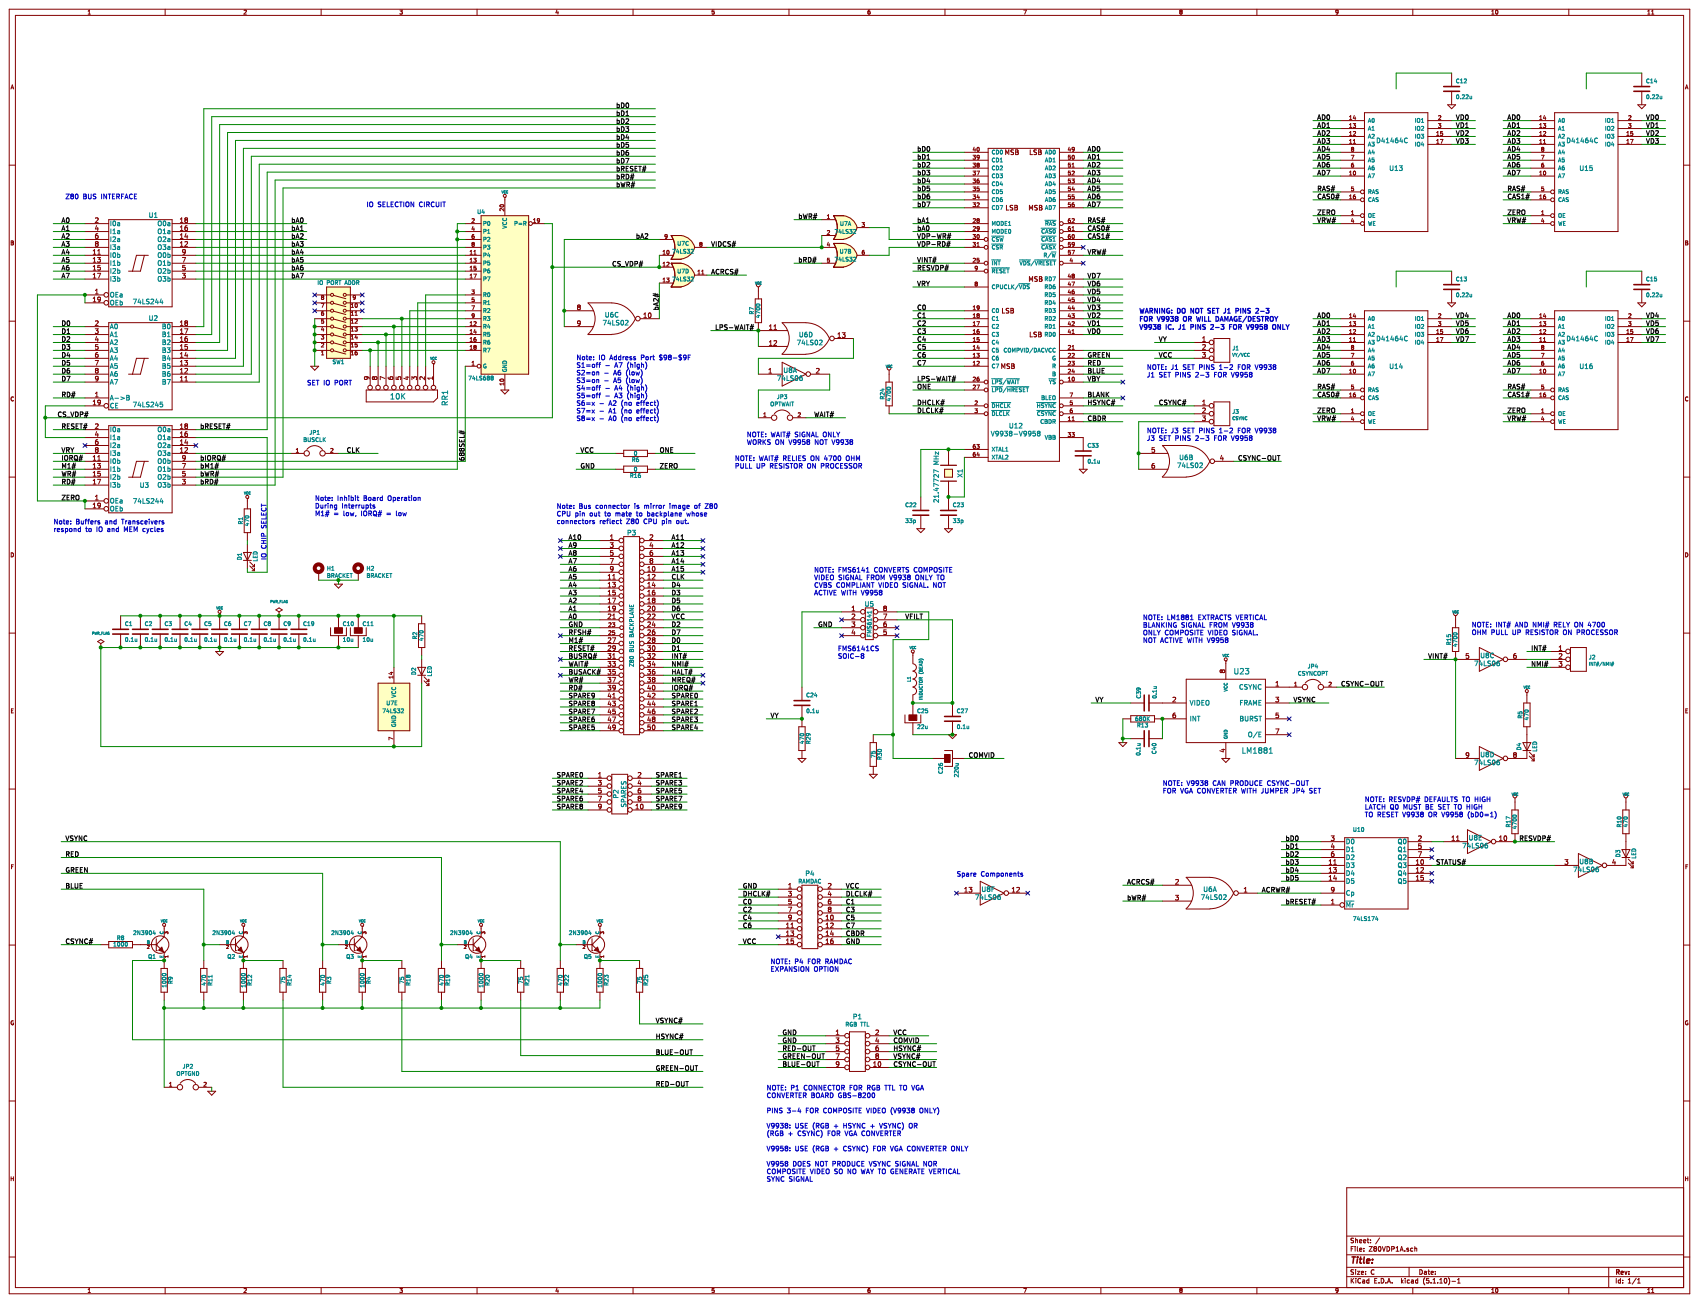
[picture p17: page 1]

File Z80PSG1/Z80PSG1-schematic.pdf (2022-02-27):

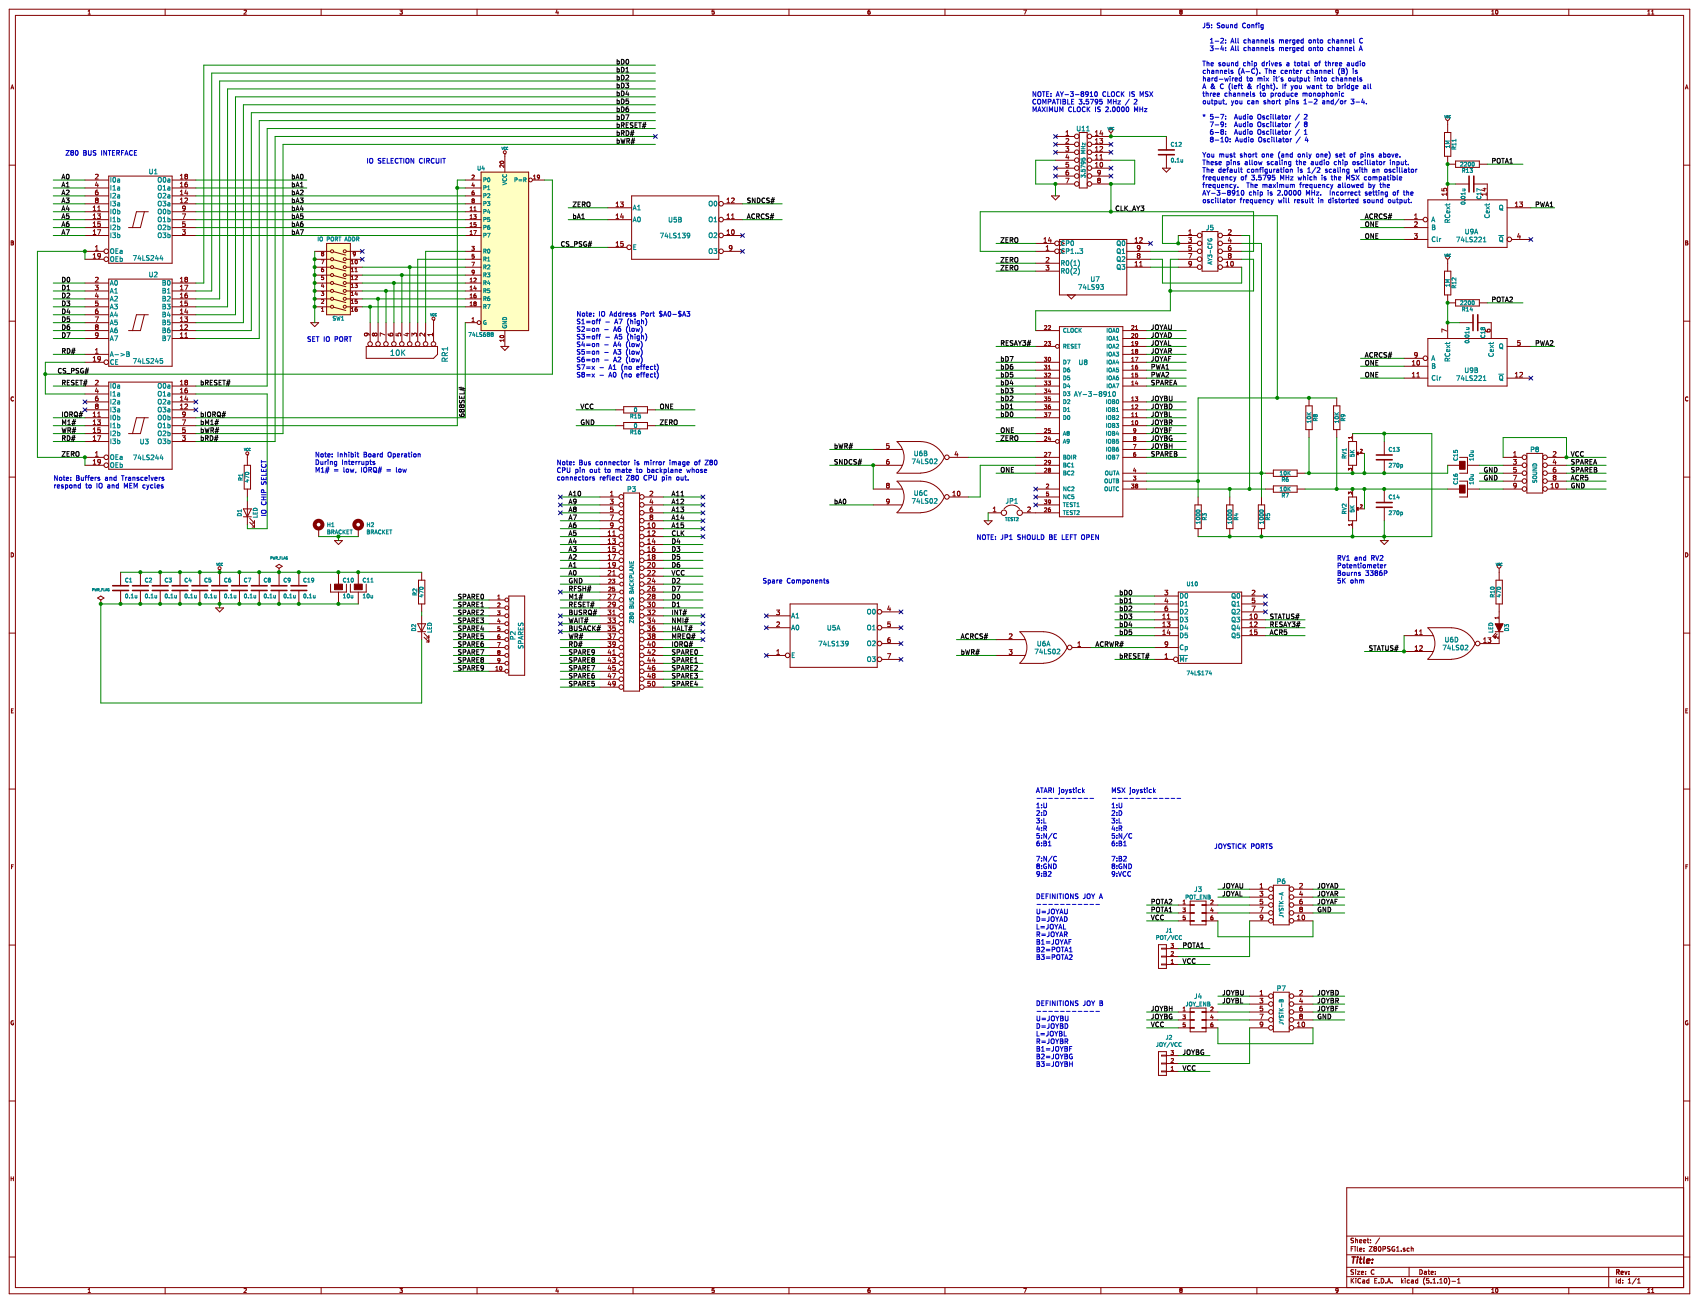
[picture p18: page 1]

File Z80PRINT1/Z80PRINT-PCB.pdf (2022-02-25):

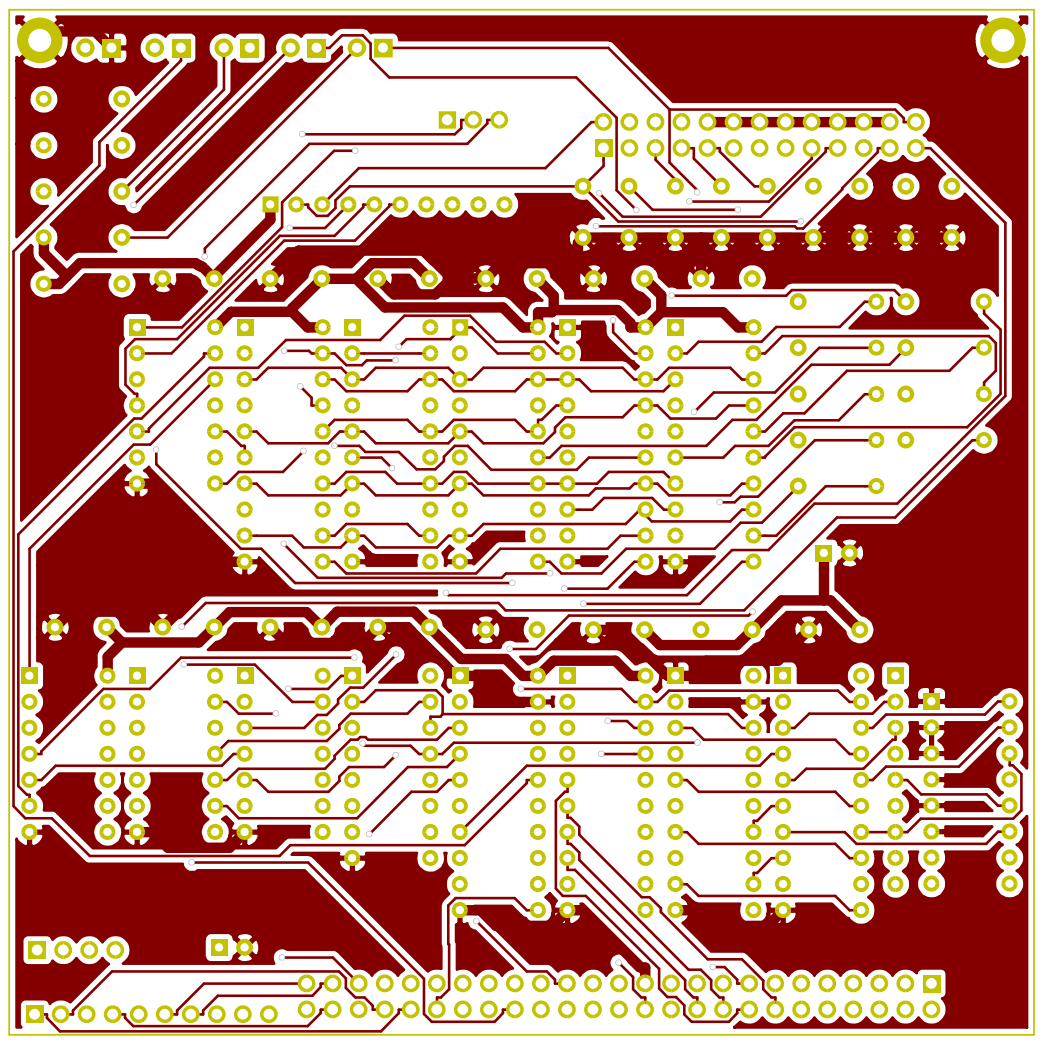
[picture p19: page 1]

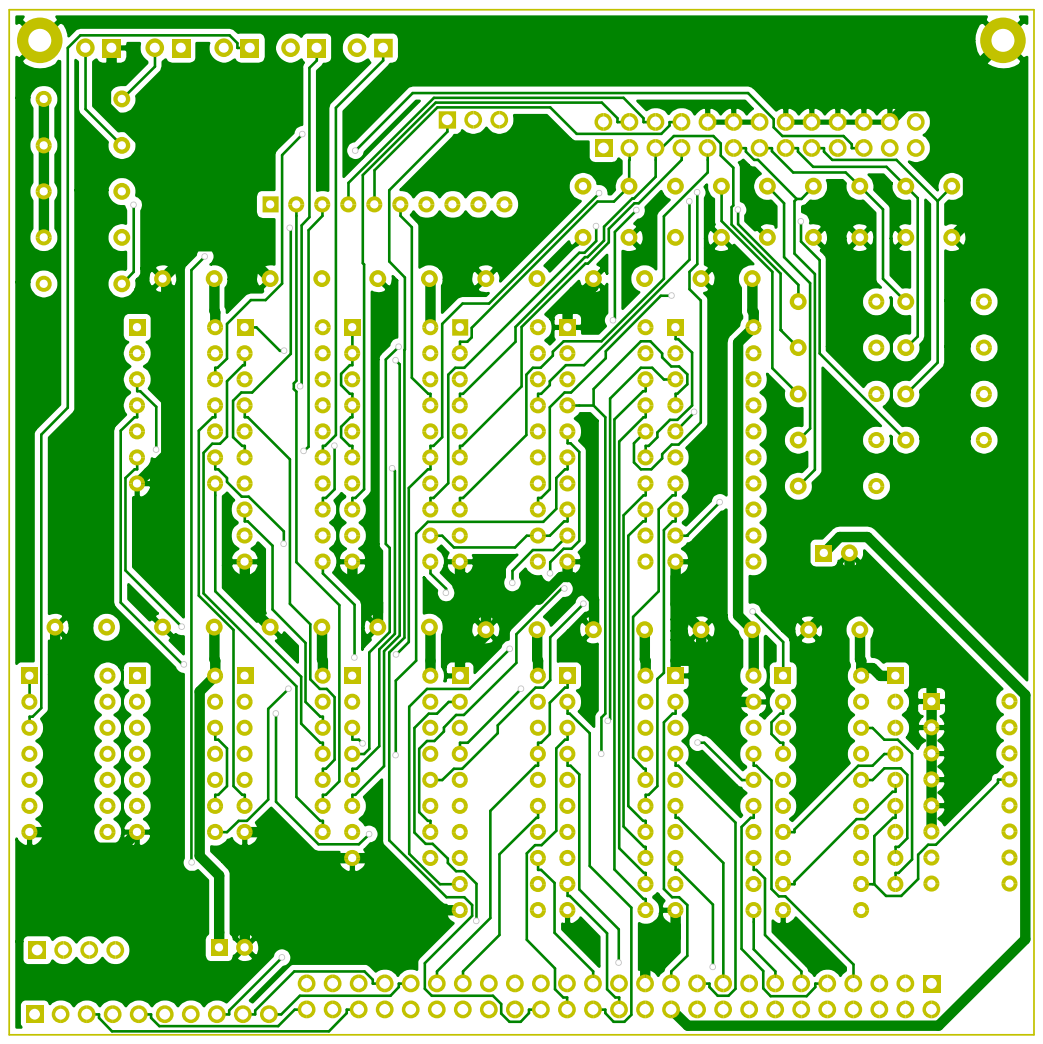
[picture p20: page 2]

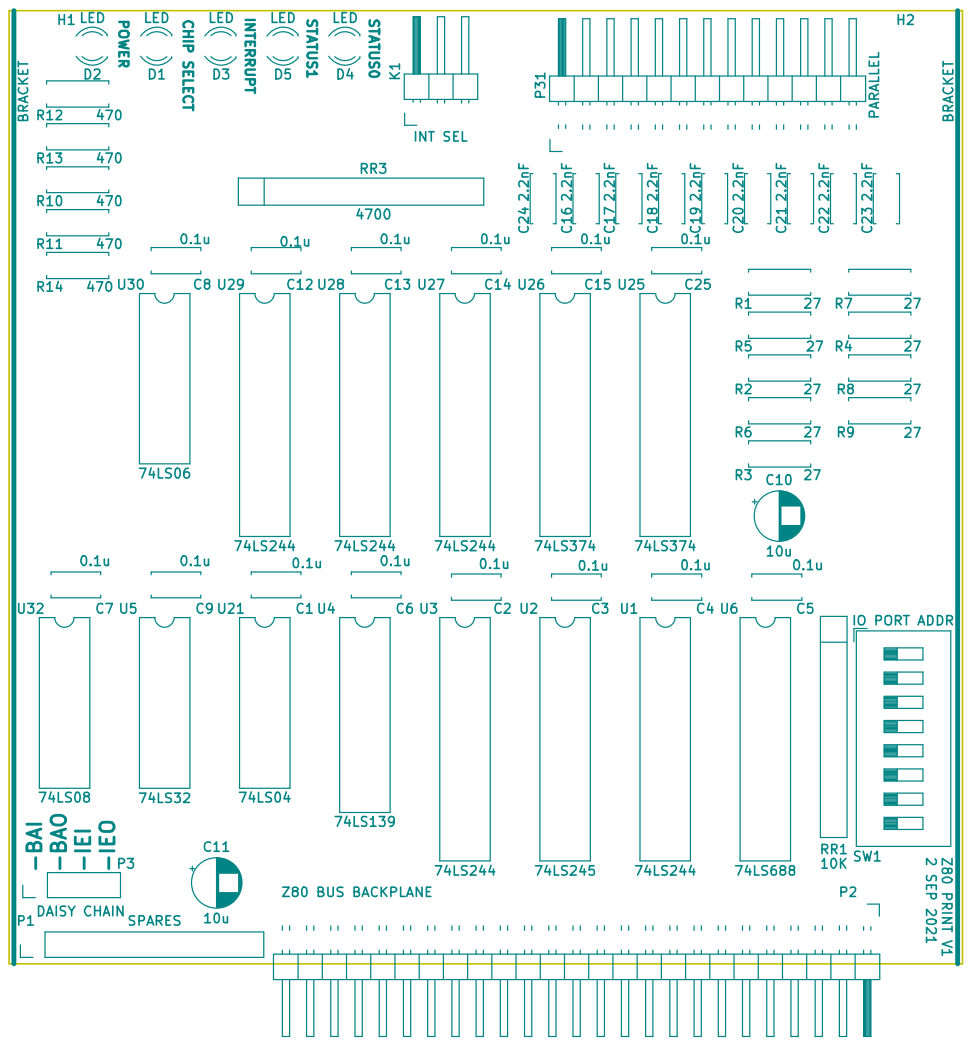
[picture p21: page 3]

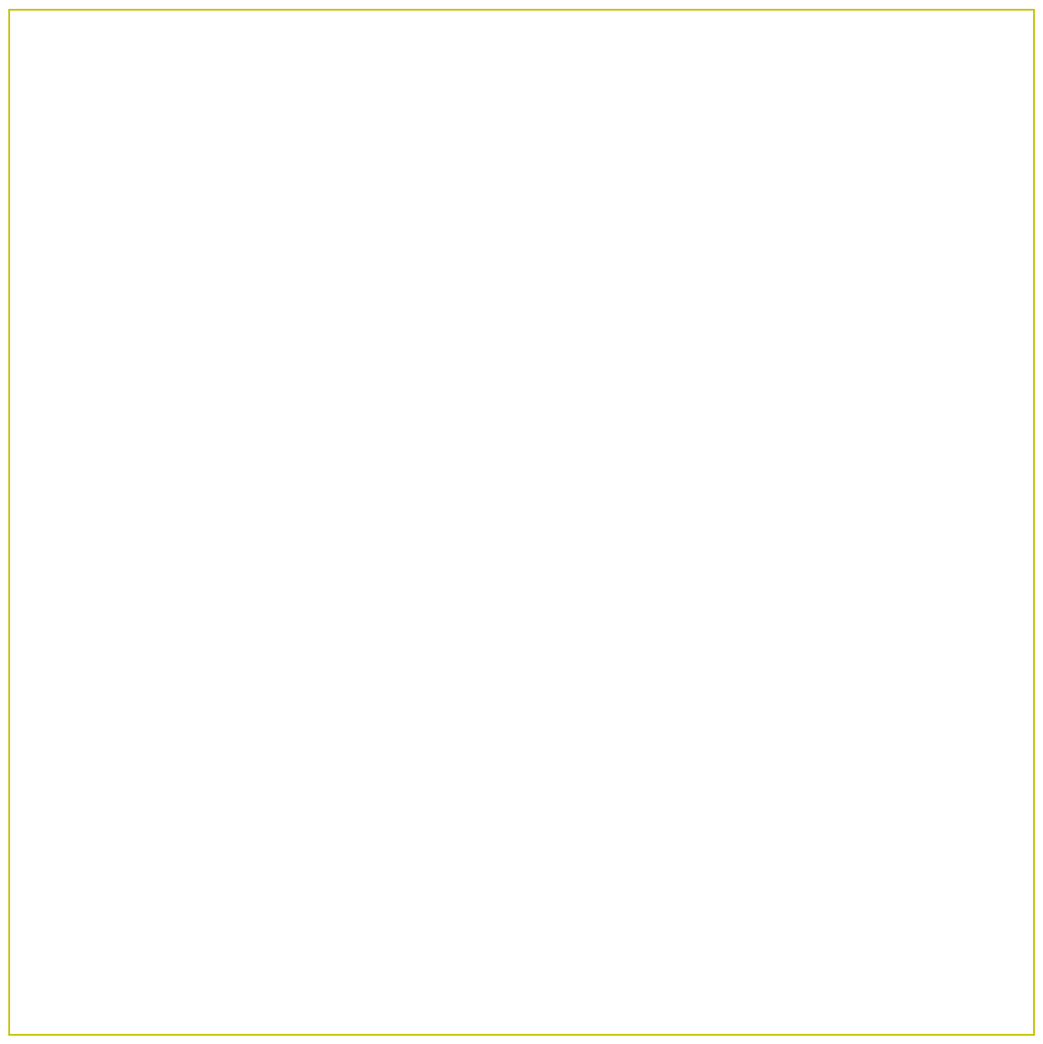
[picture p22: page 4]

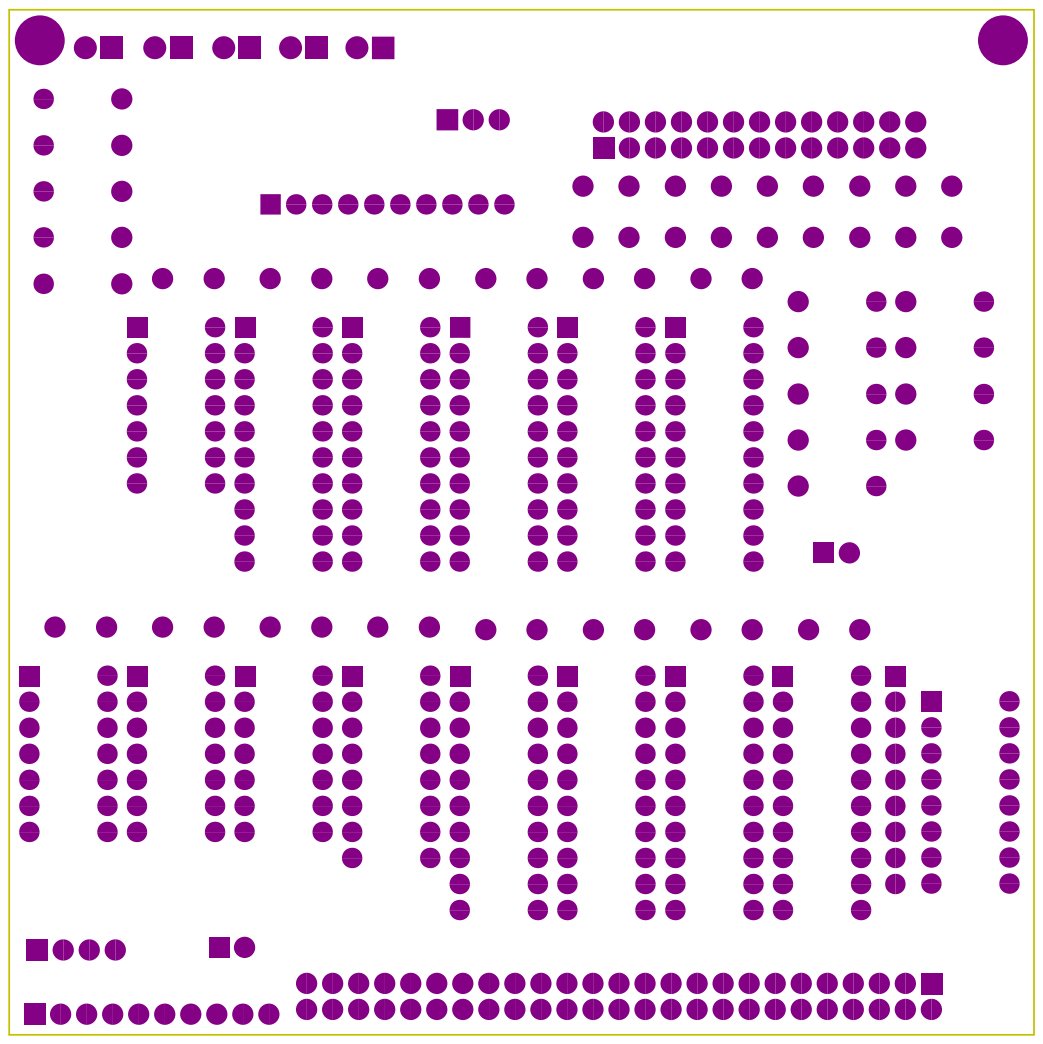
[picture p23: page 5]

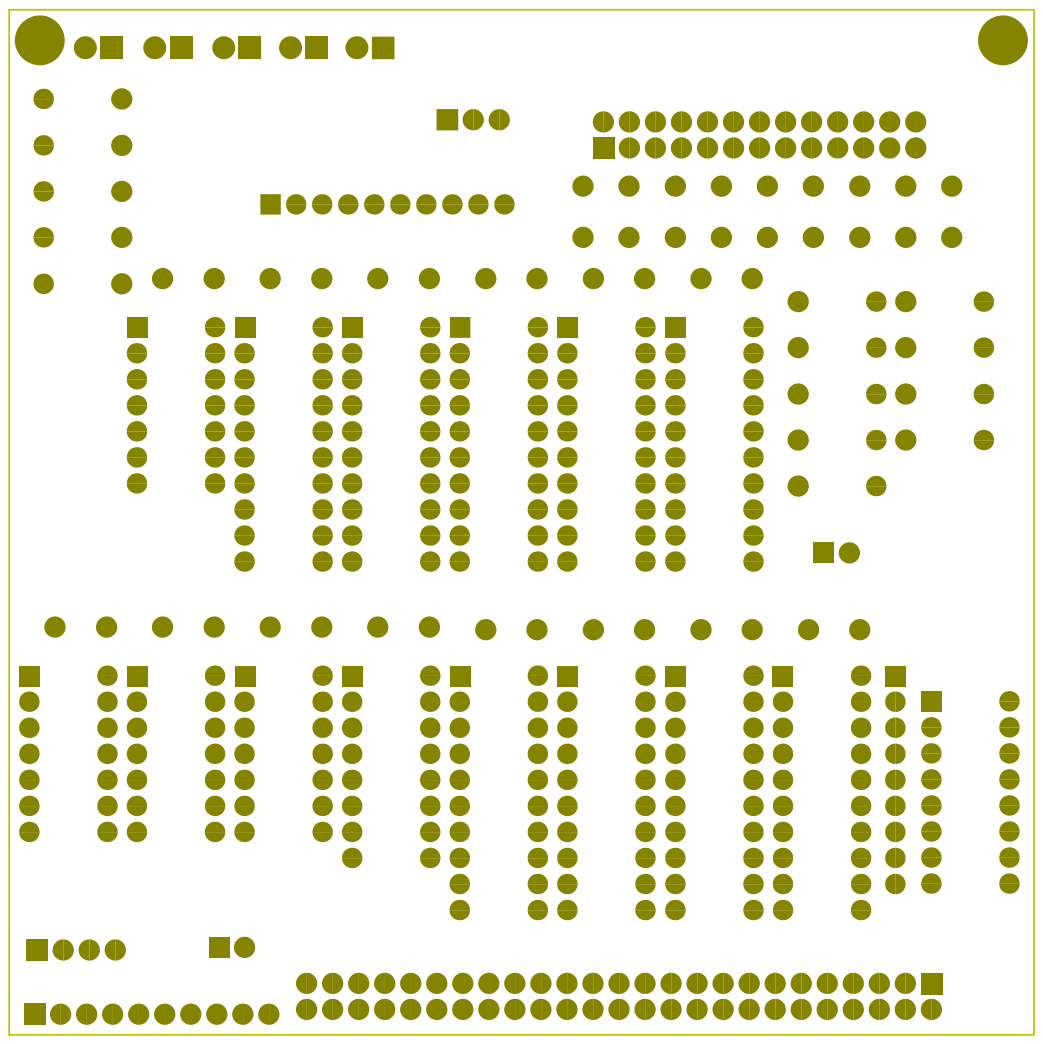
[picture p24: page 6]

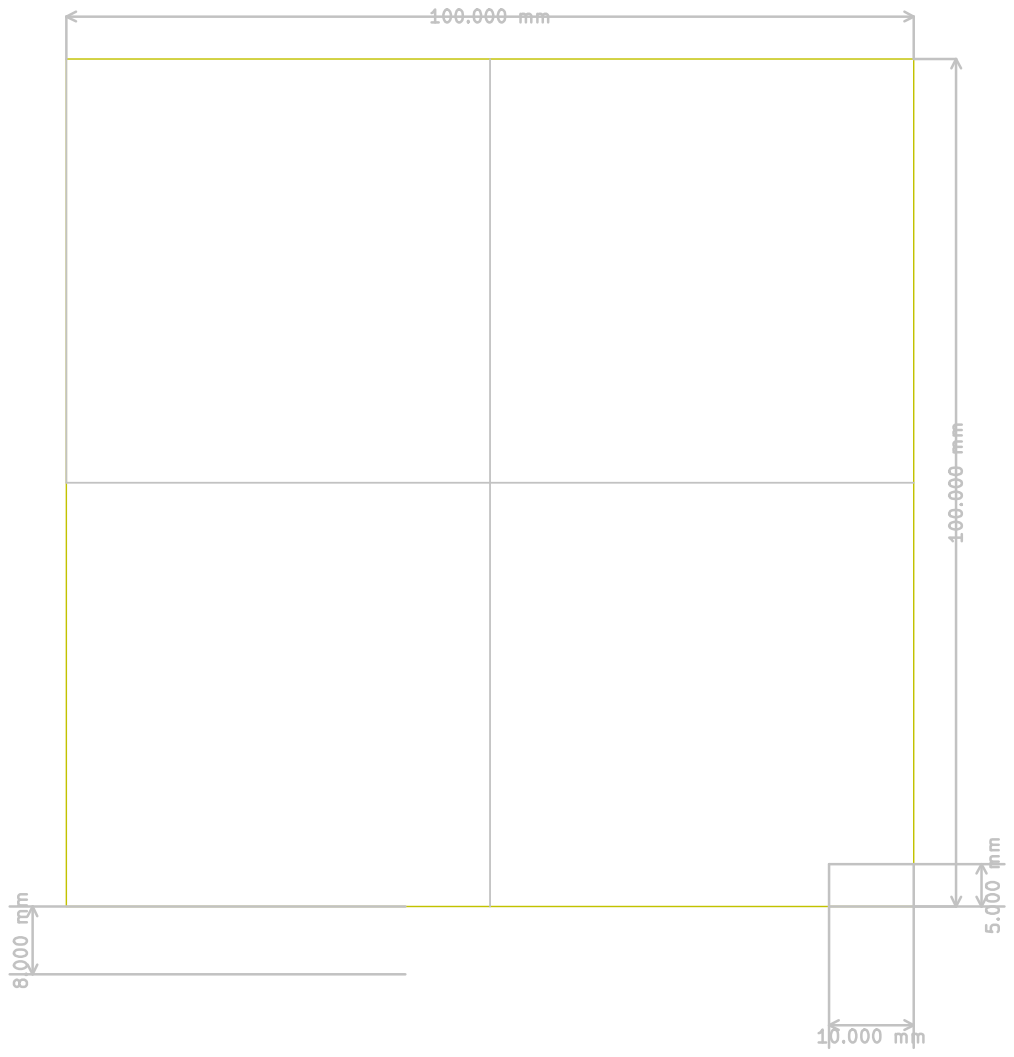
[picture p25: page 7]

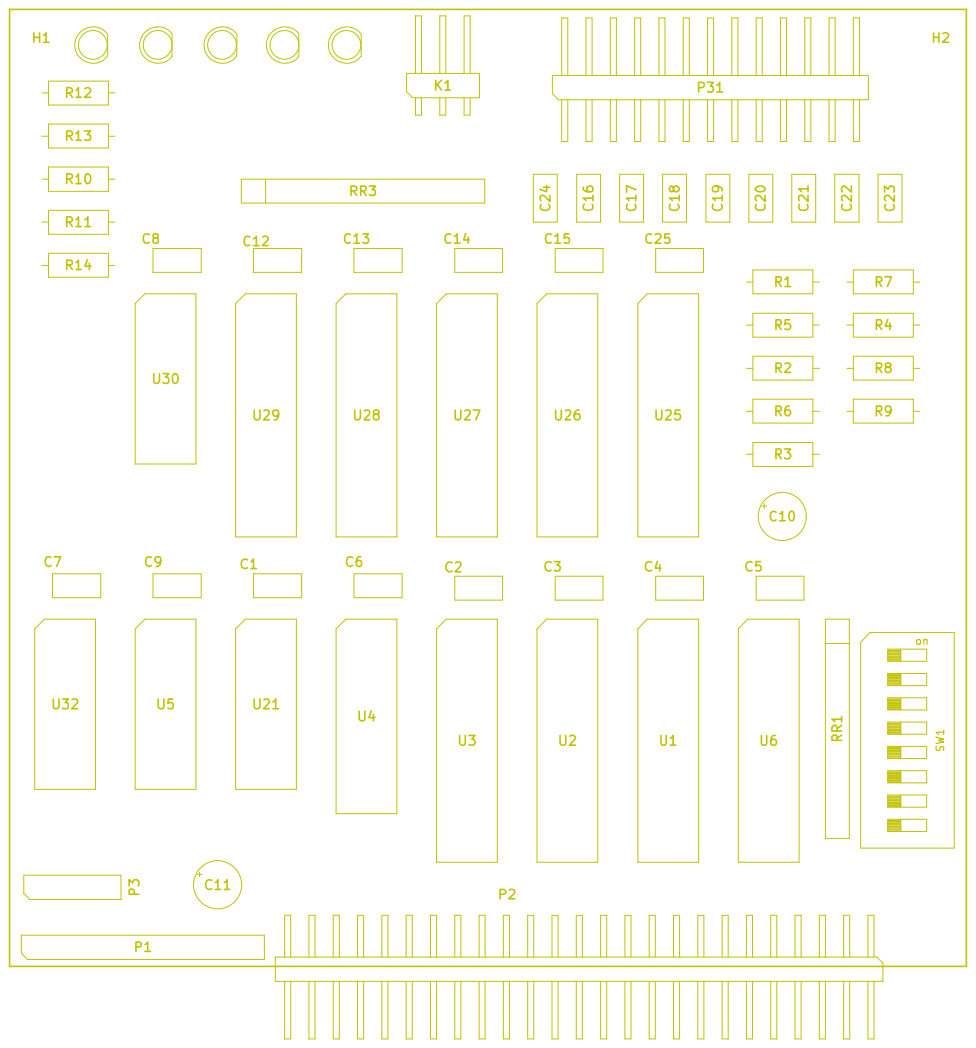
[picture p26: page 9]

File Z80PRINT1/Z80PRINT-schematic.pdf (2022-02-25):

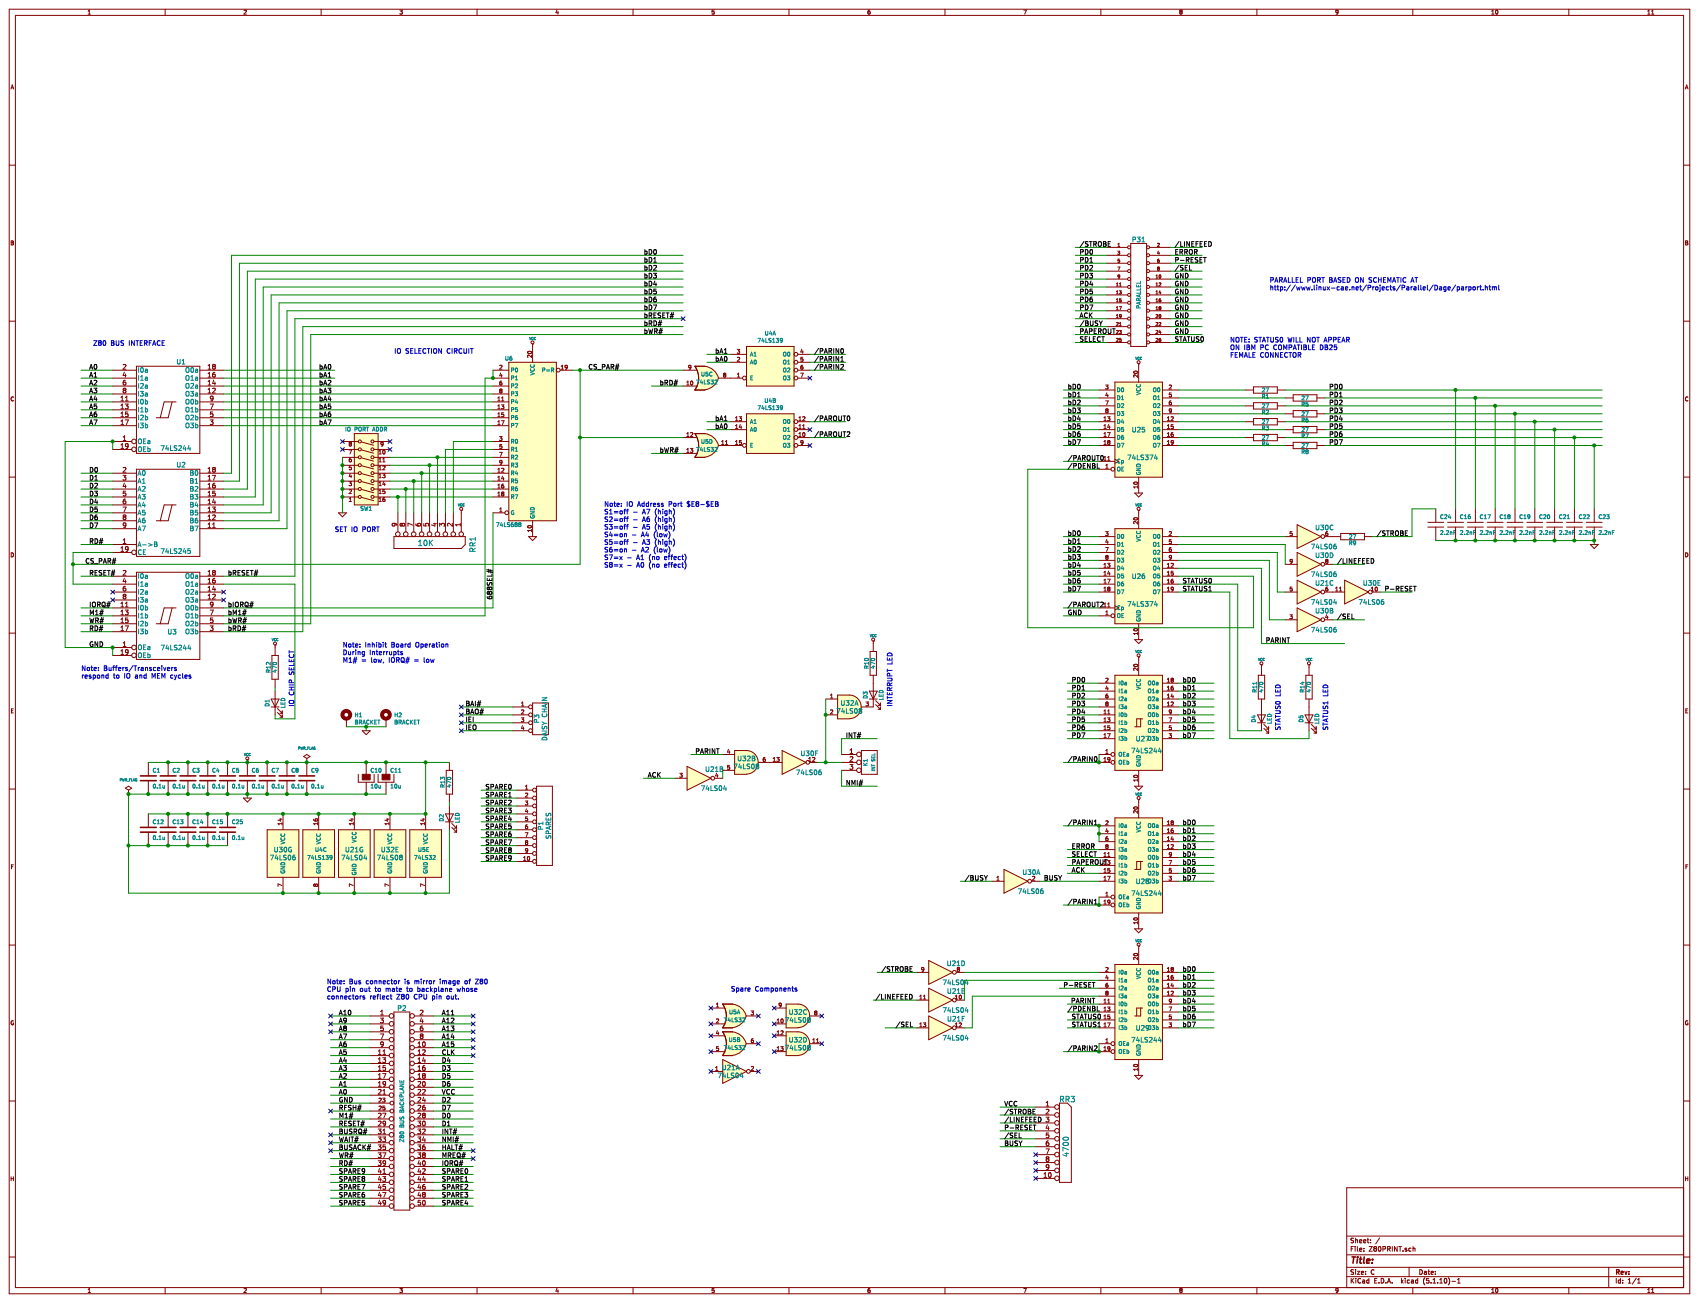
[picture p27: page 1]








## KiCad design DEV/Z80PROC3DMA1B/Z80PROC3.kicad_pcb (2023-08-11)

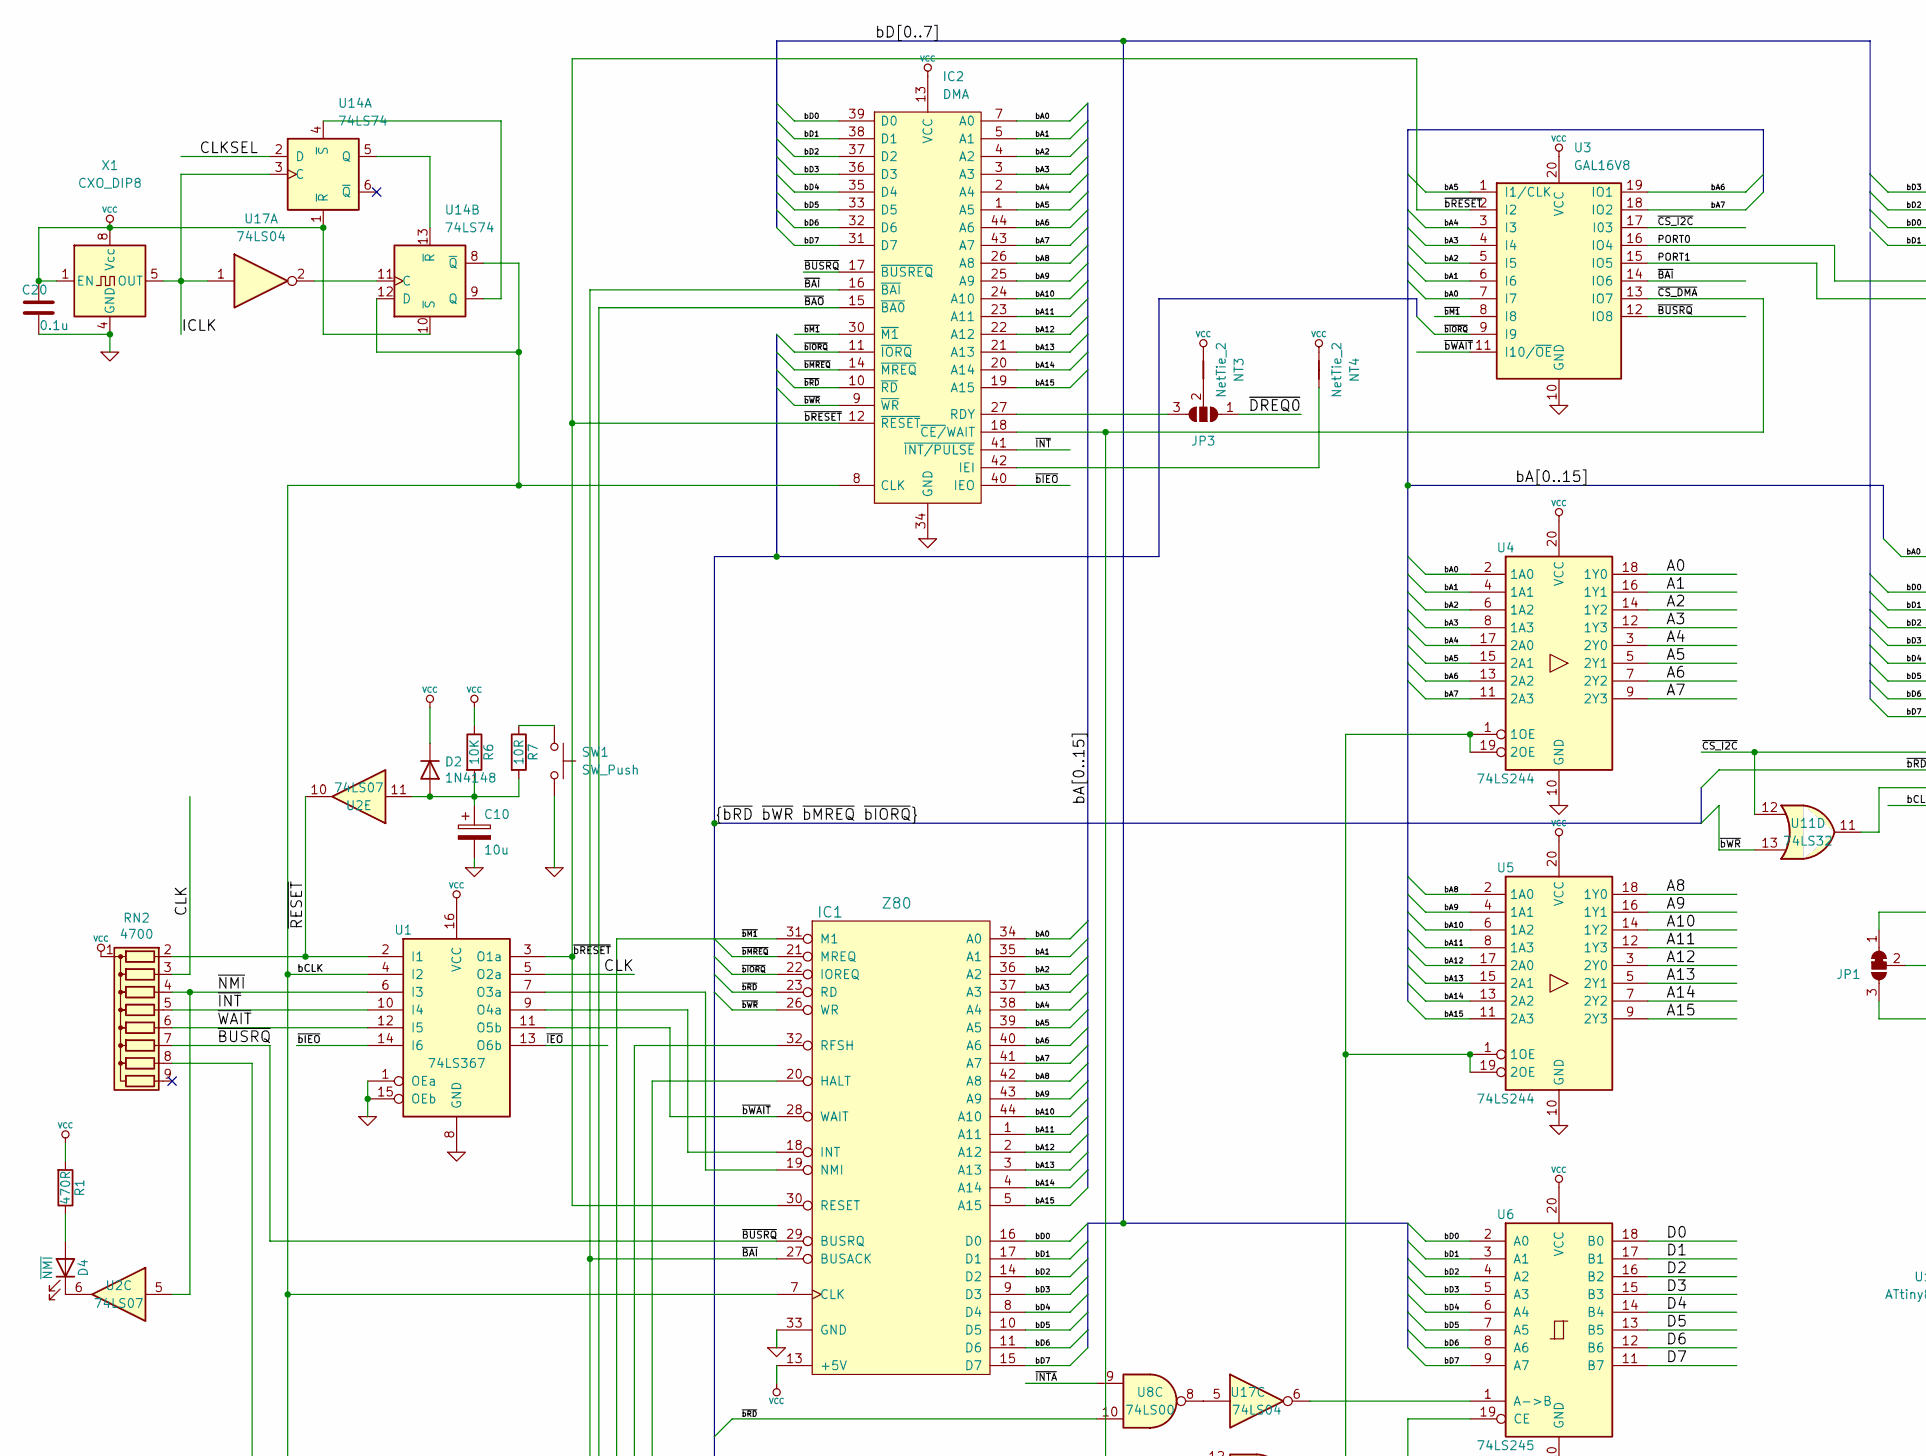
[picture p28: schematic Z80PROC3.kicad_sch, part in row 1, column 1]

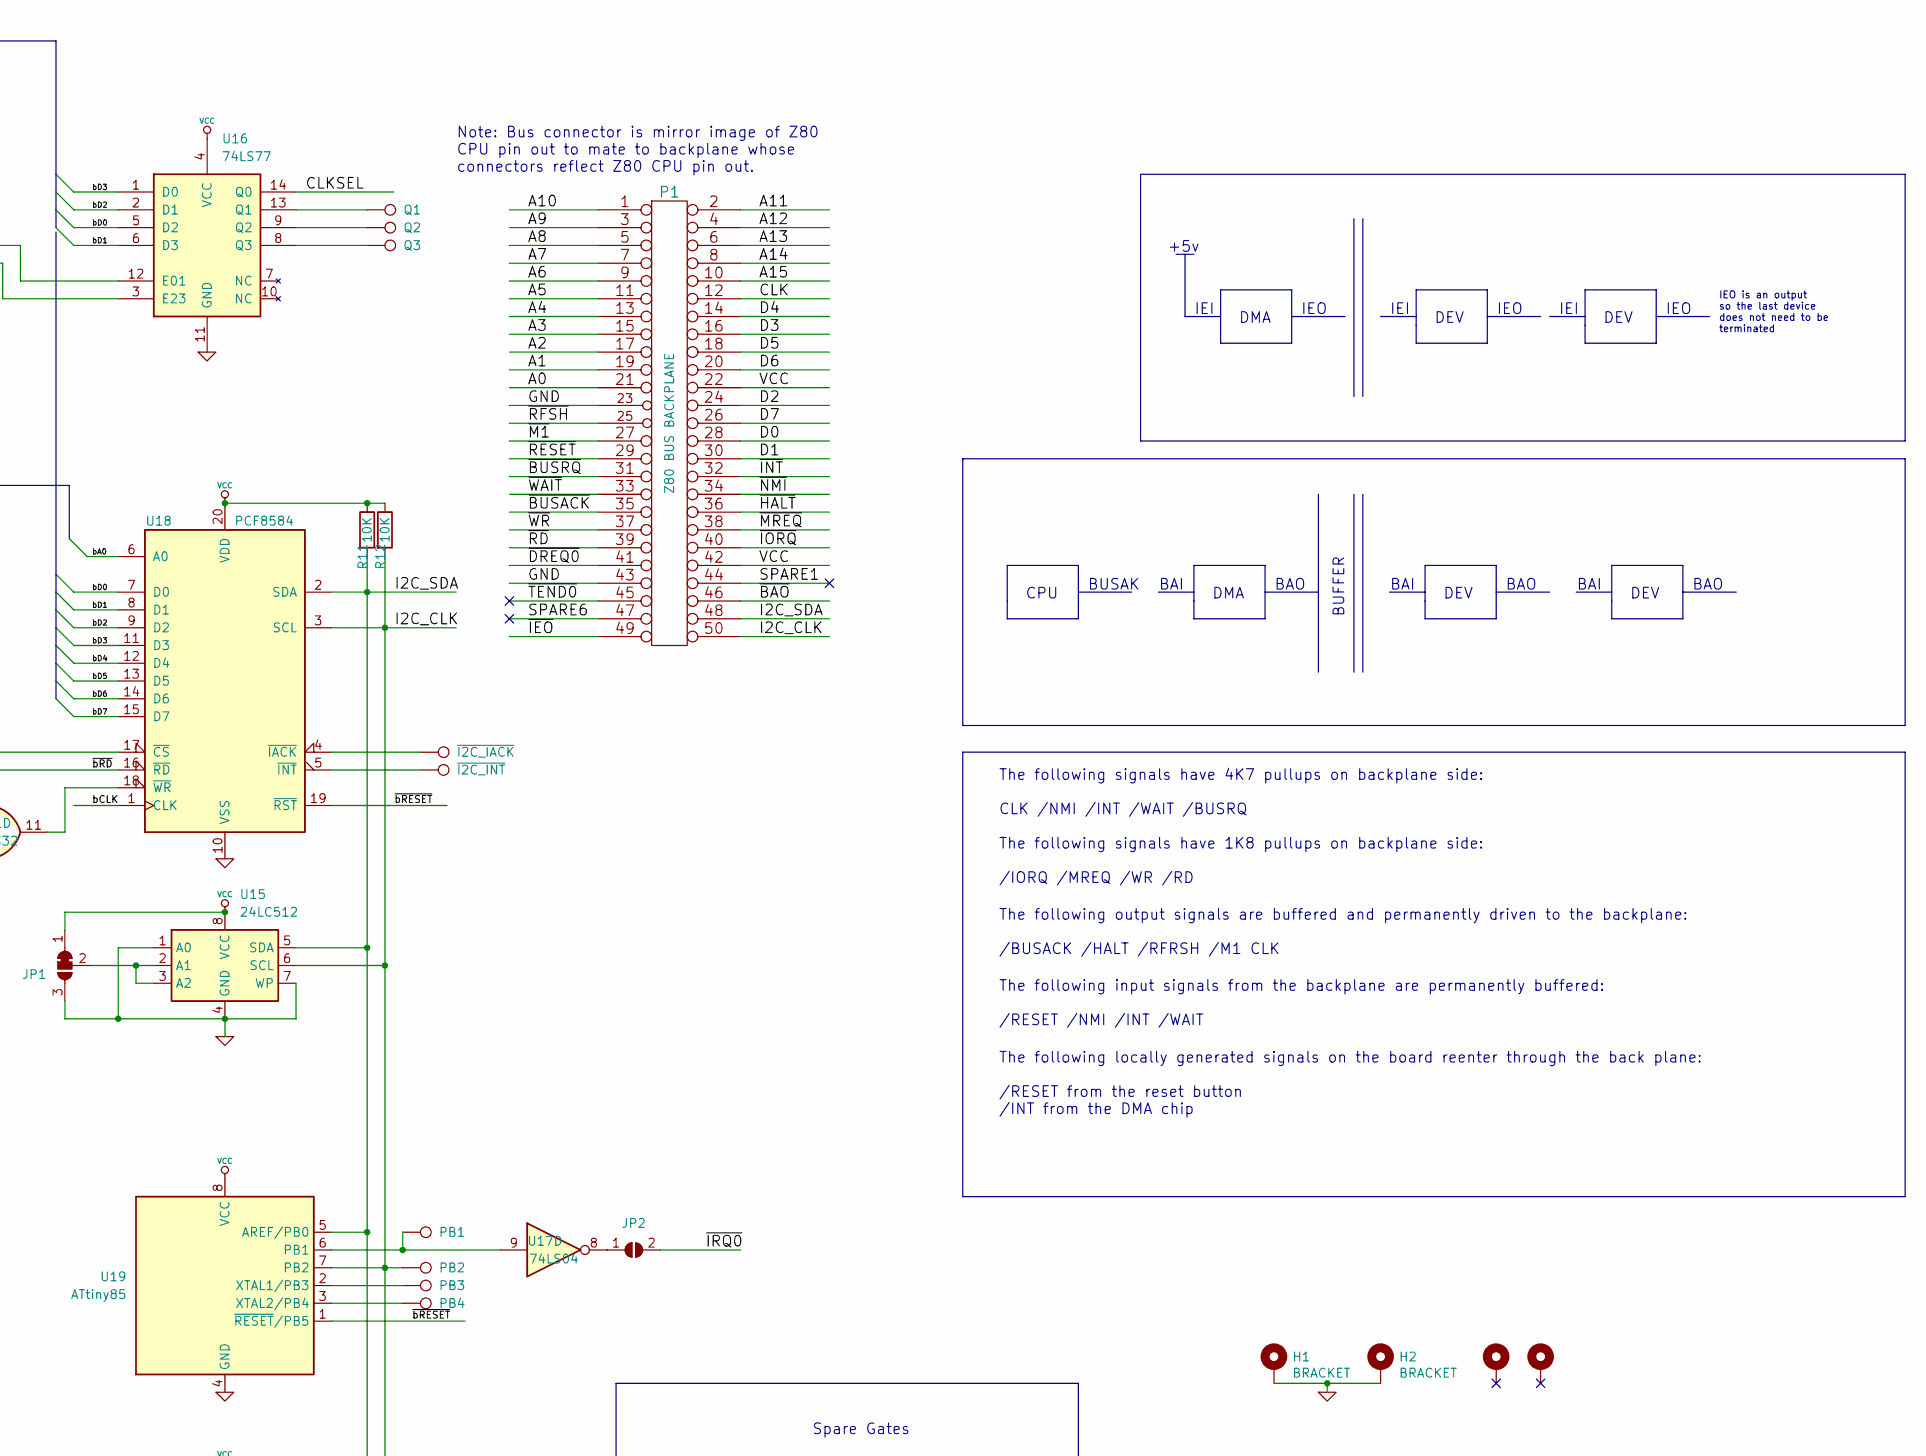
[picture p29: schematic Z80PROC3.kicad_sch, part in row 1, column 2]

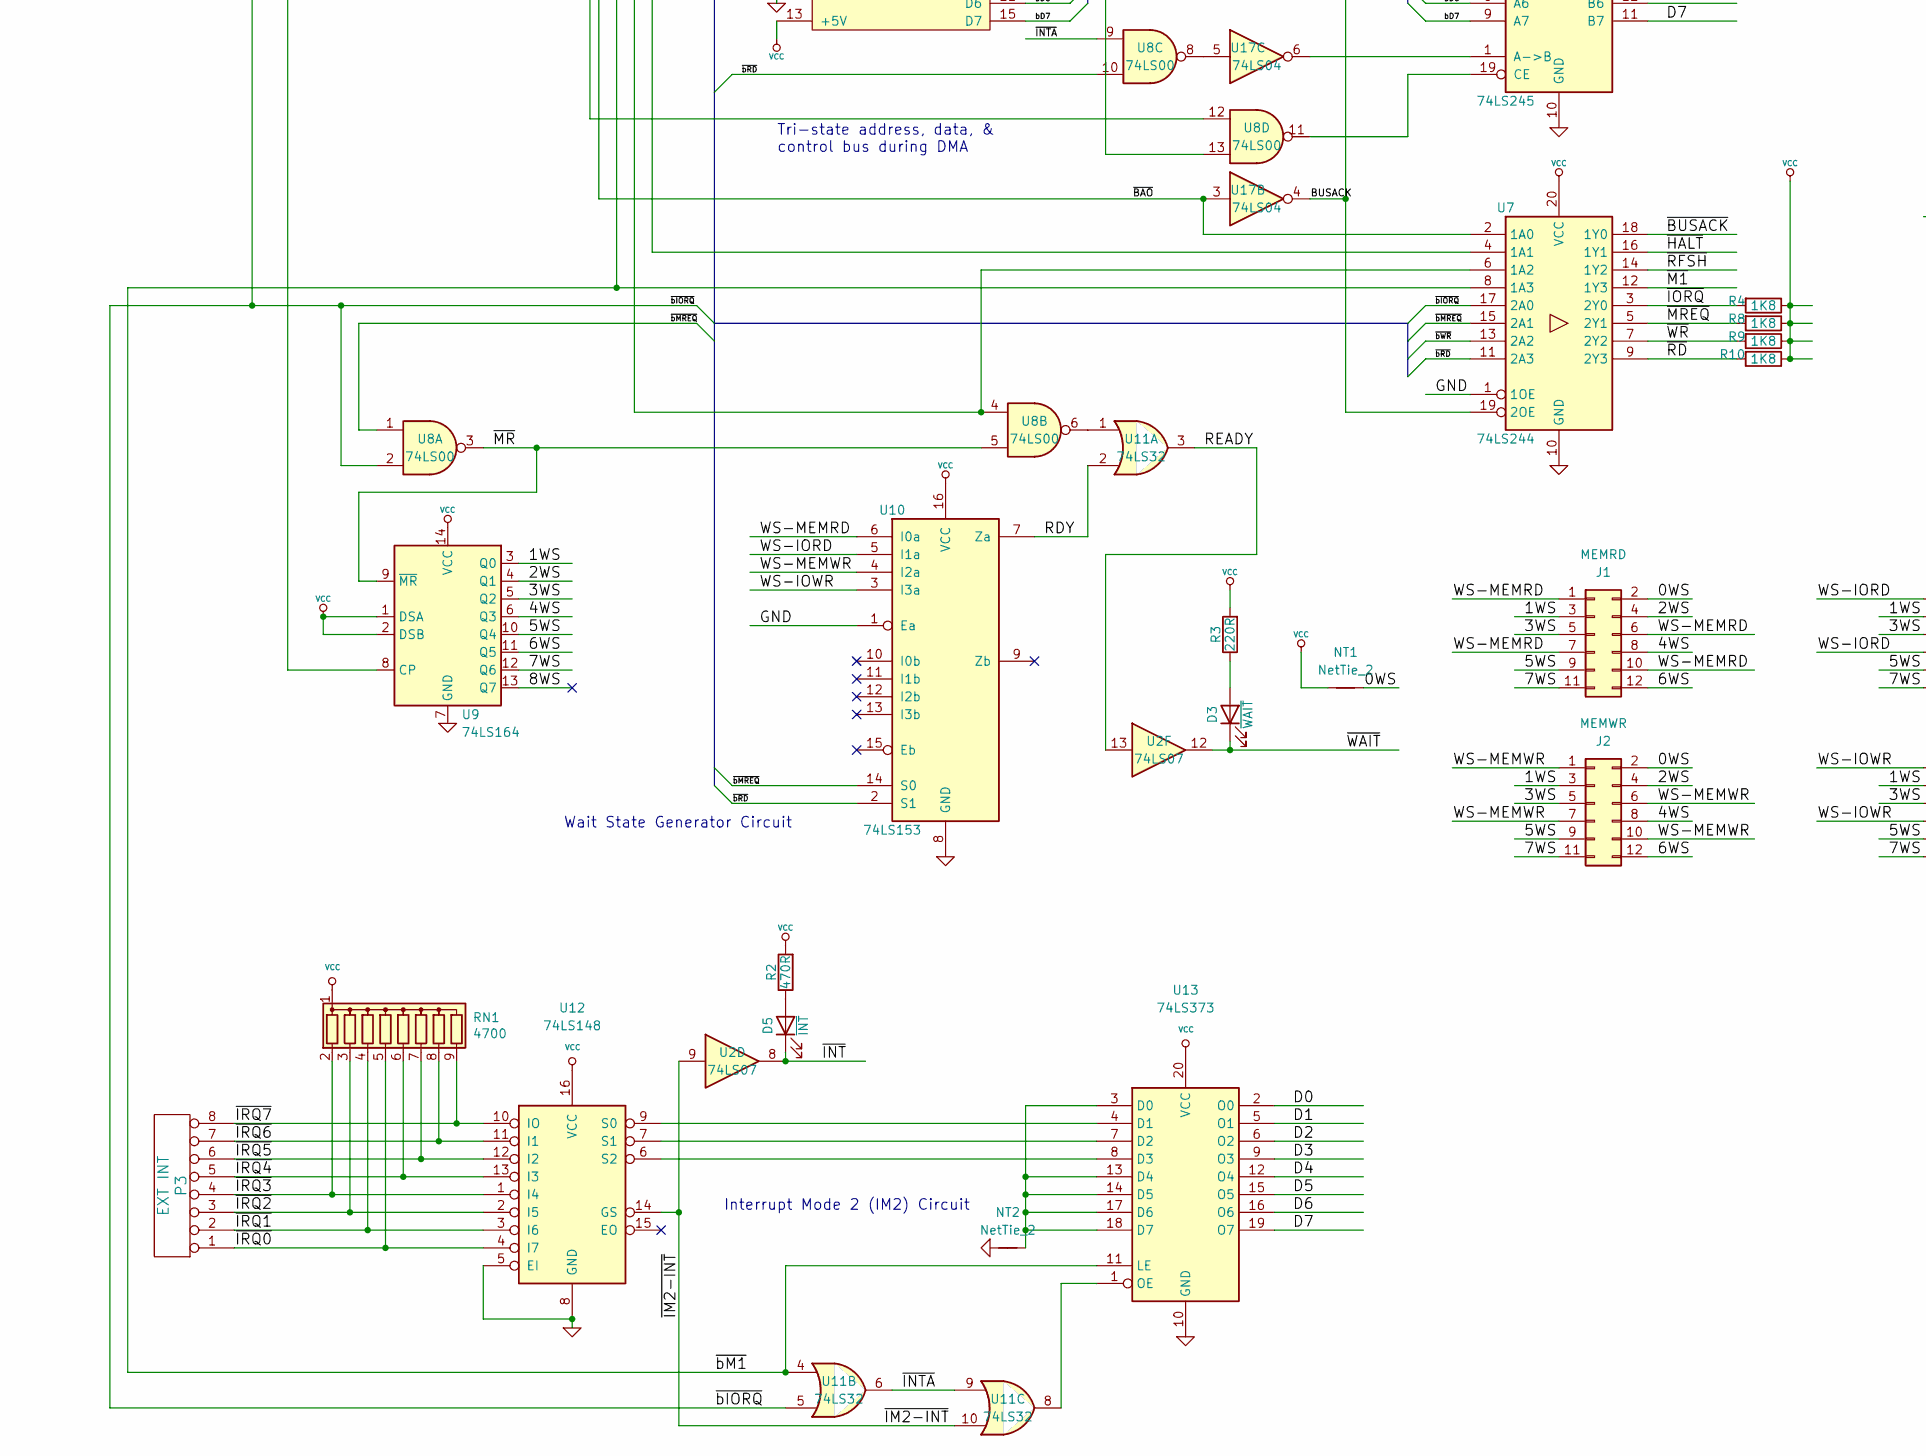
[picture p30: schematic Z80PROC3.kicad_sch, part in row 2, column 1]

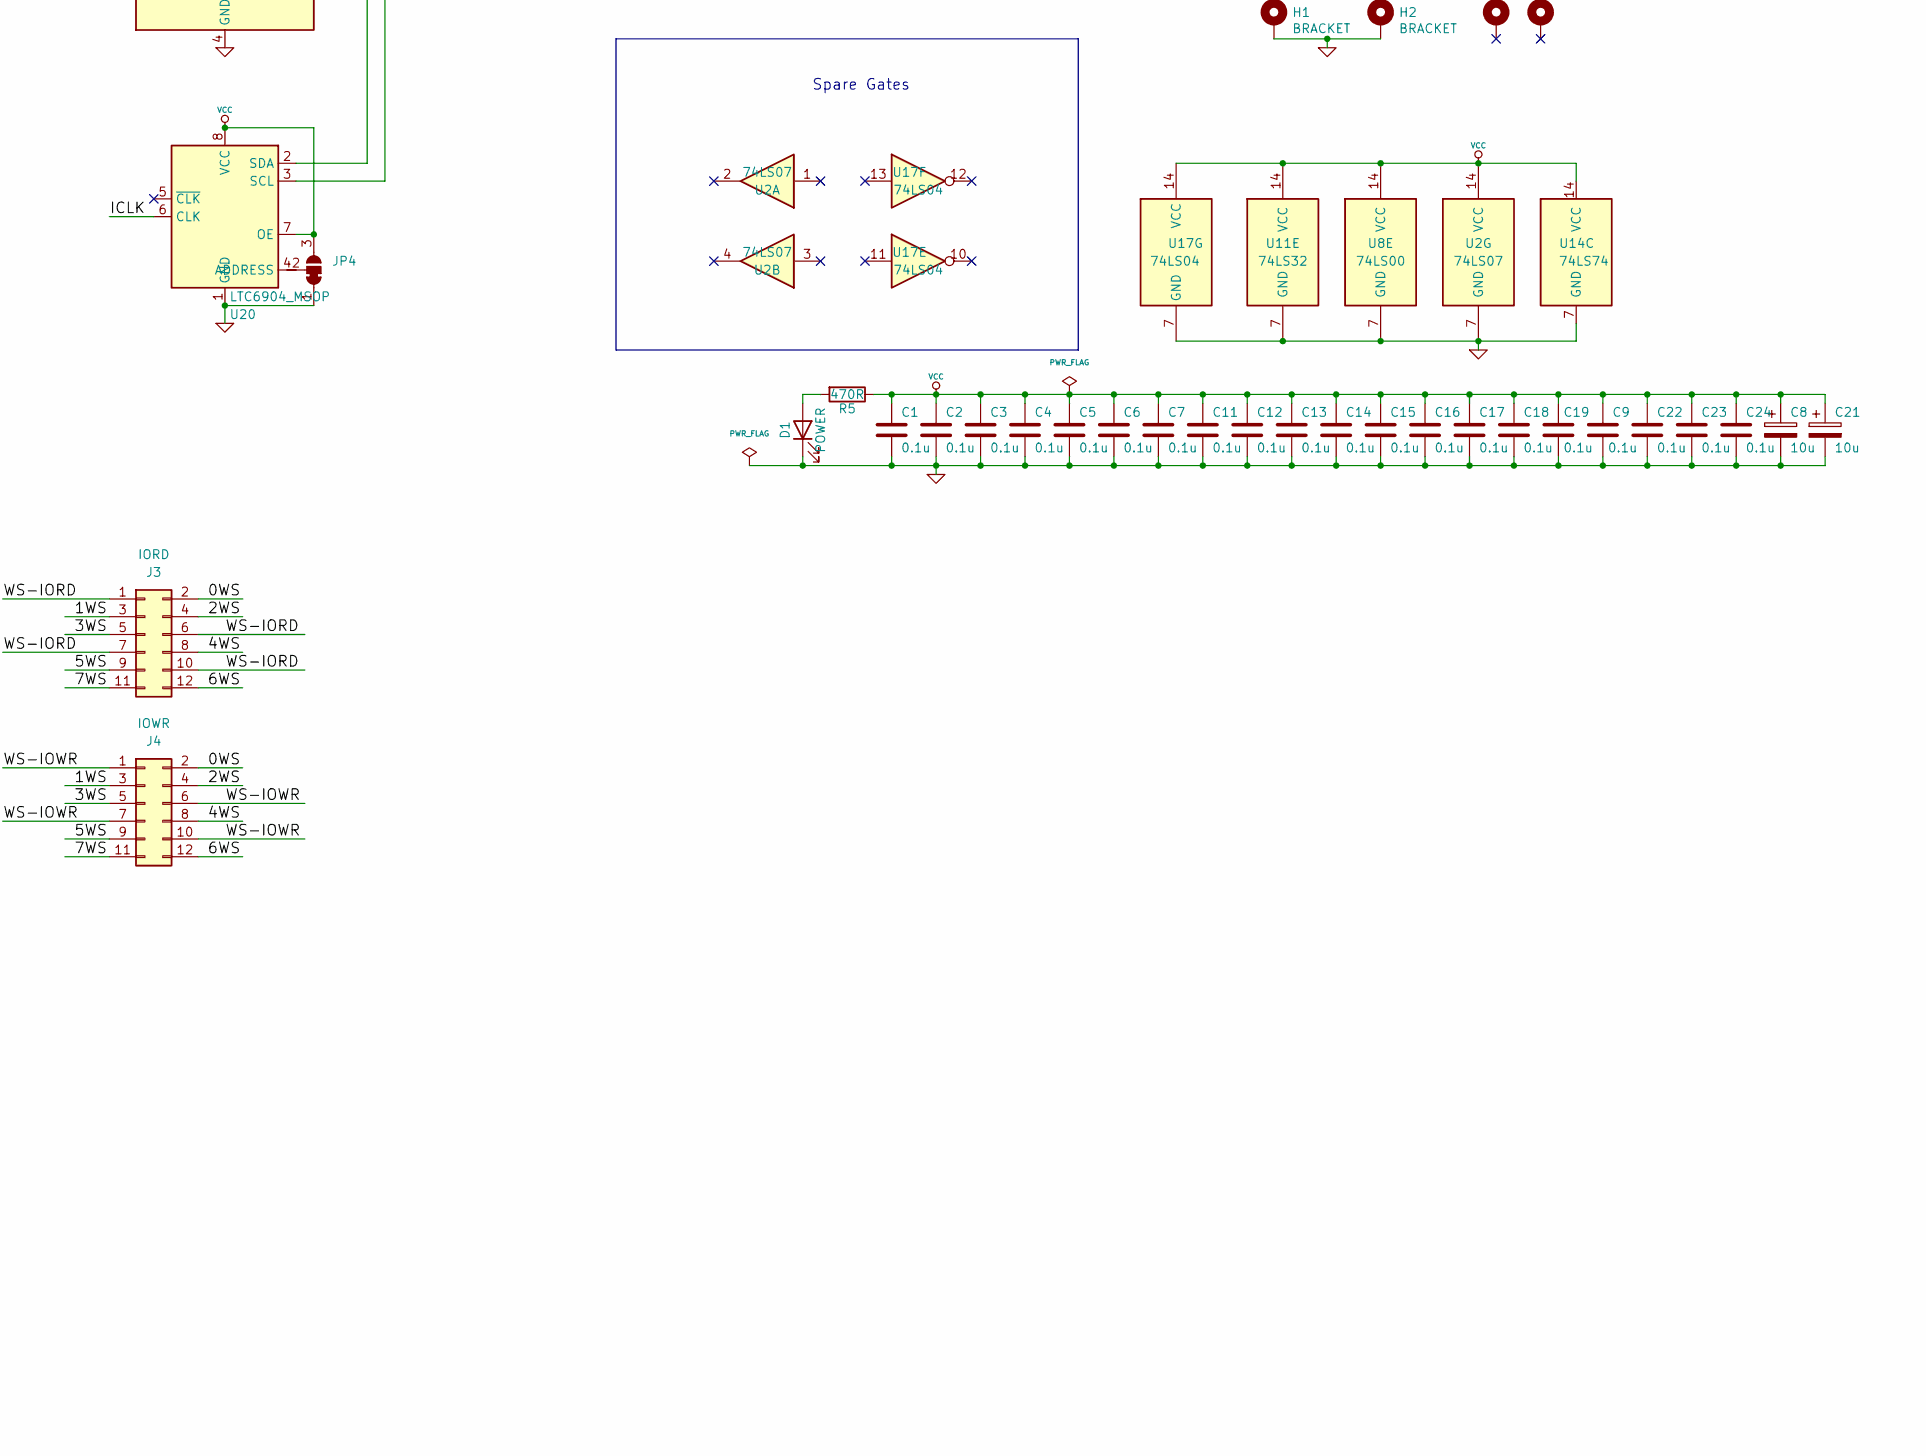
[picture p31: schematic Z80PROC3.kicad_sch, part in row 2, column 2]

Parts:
C1, C2, C3, C4, C5, C6, C7, C9, C11, C12, C13, C14, C15, C16, C17, C18, C19, C20, C22, C23, C24: 0.1u; C_Disc_D5.0mm_W2.5mm_P5.00mm
C8, C10, C21: 10u; CP_Radial_D4.0mm_P2.00mm
D1: POWER; LED_D3.0mm
D2: 1N4148; D_DO-35_SOD27_P7.62mm_Horizontal
D3: ~{WAIT}; LED_D3.0mm
D4: ~{NMI}; LED_D3.0mm
D5: ~{INT}; LED_D3.0mm
H1, H2: BRACKET; MountingHole_2.2mm_M2_Pad
H3, H4: MountingHole_Pad; MountingHole_2mm
IC1: Z80; PLCC-44_THT-Socket; Manufacturer_Part_Number Z84C00
IC2: DMA; PLCC-44_THT-Socket; Manufacturer_Part_Number Z84C4206PEG; Mouser Part Number 692-Z84C4206PEG
J1: MEMRD; PinHeader_2x06_P2.54mm_Vertical
J2: MEMWR; PinHeader_2x06_P2.54mm_Vertical
J3: IORD; PinHeader_2x06_P2.54mm_Vertical
J4: IOWR; PinHeader_2x06_P2.54mm_Vertical
JP1, JP4: SolderJumper_3_Bridged12; SolderJumper-3_P1.3mm_Bridged12_RoundedPad1.0x1.5mm
JP2: SolderJumper_2_Open; SolderJumper-2_P1.3mm_Open_RoundedPad1.0x1.5mm
JP3: SolderJumper_3_Open; SolderJumper-3_P1.3mm_Open_RoundedPad1.0x1.5mm
NT1, NT2, NT3, NT4: NetTie_2; NetTie-2_SMD_Pad0.5mm
P1: Z80 BUS BACKPLANE; PinHeader_2x25_P2.54mm_Horizontal
P3: EXT INT; PinHeader_2x04_P2.54mm_Horizontal
PB1, PB2, PB3, PB4: TestPoint; TestPoint_THTPad_1.0x1.0mm_Drill0.5mm
Q1, Q2, Q3: TestPoint; TestPoint_THTPad_1.0x1.0mm_Drill0.5mm
R1, R2, R5: 470R; R_Axial_DIN0207_L6.3mm_D2.5mm_P7.62mm_Horizontal
R3: 220R; R_Axial_DIN0207_L6.3mm_D2.5mm_P7.62mm_Horizontal
R4, R8, R9, R10: 1K8; R_Axial_DIN0207_L6.3mm_D2.5mm_P7.62mm_Horizontal
R6, R11, R12: 10K; R_Axial_DIN0207_L6.3mm_D2.5mm_P7.62mm_Horizontal
R7: 10R; R_Axial_DIN0207_L6.3mm_D2.5mm_P7.62mm_Horizontal
RN1, RN2: 4700; R_Array_SIP9
SW1: SW_Push; SW_Tactile_SPST_Angled_PTS645Vx58-2LFS
TestPoint1: ~{I2C_IACK}; TestPoint_THTPad_1.0x1.0mm_Drill0.5mm
TestPoint2: ~{I2C_INT}; TestPoint_THTPad_1.0x1.0mm_Drill0.5mm
U1: 74LS367; DIP-16_W7.62mm
U2: 74LS07; DIP-14_W7.62mm
U3: GAL16V8; DIP-20_W7.62mm
U4, U5, U7: 74LS244; DIP-20_W7.62mm
U6: 74LS245; DIP-20_W7.62mm
U8: 74LS00; DIP-14_W7.62mm
U9: 74LS164; DIP-14_W7.62mm
U10: 74LS153; DIP-16_W7.62mm
U11: 74LS32; DIP-14_W7.62mm
U12: 74LS148; DIP-16_W7.62mm
U13: 74LS373; DIP-20_W7.62mm
U14: 74LS74
U15: 24LC512; DIP-8_W7.62mm
U16: 74LS77; DIP-14_W7.62mm
U17: 74LS04; DIP-14_W7.62mm
U18: PCF8584; DIP-20_W7.62mm
U19: ATtiny85; DIP-8_W7.62mm
U20: LTC6904_MSOP; MSOP-8_3x3mm_P0.65mm
X1: CXO_DIP8; Oscillator_DIP-8

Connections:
/0WS: J1.2, J2.2, J3.2, J4.2, NT1.2
/1WS: J1.3, J2.3, J3.3, J4.3, U9.3 (Q0)
/2WS: J1.4, J2.4, J3.4, J4.4, U9.4 (Q1)
/3WS: J1.5, J2.5, J3.5, J4.5, U9.5 (Q2)
/4WS: J1.8, J2.8, J3.8, J4.8, U9.6 (Q3)
/5WS: J1.9, J2.9, J3.9, J4.9, U9.10 (Q4)
/6WS: J1.12, J2.12, J3.12, J4.12, U9.11 (Q5)
/7WS: J1.11, J2.11, J3.11, J4.11, U9.12 (Q6)
/8WS: U9.13 (Q7)
/A0: P1.21, U4.18 (1Y0)
/A1: P1.19, U4.16 (1Y1)
/A2: P1.17, U4.14 (1Y2)
/A3: P1.15, U4.12 (1Y3)
/A4: P1.13, U4.3 (2Y0)
/A5: P1.11, U4.5 (2Y1)
/A6: P1.9, U4.7 (2Y2)
/A7: P1.7, U4.9 (2Y3)
/A8: P1.5, U5.18 (1Y0)
/A9: P1.3, U5.16 (1Y1)
/A10: P1.1, U5.14 (1Y2)
/A11: P1.2, U5.12 (1Y3)
/A12: P1.4, U5.3 (2Y0)
/A13: P1.6, U5.5 (2Y1)
/A14: P1.8, U5.7 (2Y2)
/A15: P1.10, U5.9 (2Y3)
/BUSACK: U4.1 (1OE), U4.19 (2OE), U5.1 (1OE), U5.19 (2OE), U7.19 (2OE), U17.4
/CLK: P1.12, RN2.3 (R2), U1.5 (O2a)
/CLKSEL: U14.2 (D), U16.14 (Q0)
/D0: P1.28, U6.18 (B0), U13.2 (O0)
/D1: P1.30, U6.17 (B1), U13.5 (O1)
/D2: P1.24, U6.16 (B2), U13.6 (O2)
/D3: P1.16, U6.15 (B3), U13.9 (O3)
/D4: P1.14, U6.14 (B4), U13.12 (O4)
/D5: P1.18, U6.13 (B5), U13.15 (O5)
/D6: P1.20, U6.12 (B6), U13.16 (O6)
/D7: P1.26, U6.11 (B7), U13.19 (O7)
/I2C_CLK: P1.50, PB2.1, R12.2, U15.6 (SCL), U18.3 (SCL), U19.7 (PB2), U20.3 (SCL)
/I2C_SDA: P1.48, R11.2, U15.5 (SDA), U18.2 (SDA), U19.5 (AREF/PB0), U20.2 (SDA)
/PORT0: U3.16 (IO4), U16.12 (E01)
/PORT1: U3.15 (IO5), U16.3 (E23)
/RDY: U10.7 (Za), U11.2
/READY: U2.13, U11.3
/SPARE1: P1.44
/SPARE6: P1.47
/WS-IORD: J3.1, J3.6, J3.7, J3.10, U10.5 (I1a)
/WS-IOWR: J4.1, J4.6, J4.7, J4.10, U10.3 (I3a)
/WS-MEMRD: J1.1, J1.6, J1.7, J1.10, U10.6 (I0a)
/WS-MEMWR: J2.1, J2.6, J2.7, J2.10, U10.4 (I2a)
/bA0: IC1.34 (A0), IC2.7 (A0), U3.7 (I7), U4.2 (1A0), U18.6 (A0)
/bA1: IC1.35 (A1), IC2.5 (A1), U3.6 (I6), U4.4 (1A1)
/bA2: IC1.36 (A2), IC2.4 (A2), U3.5 (I5), U4.6 (1A2)
/bA3: IC1.37 (A3), IC2.3 (A3), U3.4 (I4), U4.8 (1A3)
/bA4: IC1.38 (A4), IC2.2 (A4), U3.3 (I3), U4.17 (2A0)
/bA5: IC1.39 (A5), IC2.1 (A5), U3.1 (I1/CLK), U4.15 (2A1)
/bA6: IC1.40 (A6), IC2.44 (A6), U3.19 (IO1), U4.13 (2A2)
/bA7: IC1.41 (A7), IC2.43 (A7), U3.18 (IO2), U4.11 (2A3)
/bA8: IC1.42 (A8), IC2.26 (A8), U5.2 (1A0)
/bA9: IC1.43 (A9), IC2.25 (A9), U5.4 (1A1)
/bA10: IC1.44 (A10), IC2.24 (A10), U5.6 (1A2)
/bA11: IC1.1 (A11), IC2.23 (A11), U5.8 (1A3)
/bA12: IC1.2 (A12), IC2.22 (A12), U5.17 (2A0)
/bA13: IC1.3 (A13), IC2.21 (A13), U5.15 (2A1)
/bA14: IC1.4 (A14), IC2.20 (A14), U5.13 (2A2)
/bA15: IC1.5 (A15), IC2.19 (A15), U5.11 (2A3)
/bCLK: IC1.7 (CLK), IC2.8 (CLK), U1.4 (I2), U9.8 (CP), U14.8 (~Q), U14.12 (D), U18.1 (CLK)
/bD0: IC1.16 (D0), IC2.39 (D0), U6.2 (A0), U16.5 (D2), U18.7 (D0)
/bD1: IC1.17 (D1), IC2.38 (D1), U6.3 (A1), U16.6 (D3), U18.8 (D1)
/bD2: IC1.14 (D2), IC2.37 (D2), U6.4 (A2), U16.2 (D1), U18.9 (D2)
/bD3: IC1.9 (D3), IC2.36 (D3), U6.5 (A3), U16.1 (D0), U18.11 (D3)
/bD4: IC1.8 (D4), IC2.35 (D4), U6.6 (A4), U18.12 (D4)
/bD5: IC1.10 (D5), IC2.33 (D5), U6.7 (A5), U18.13 (D5)
/bD6: IC1.11 (D6), IC2.32 (D6), U6.8 (A6), U18.14 (D6)
/bD7: IC1.15 (D7), IC2.31 (D7), U6.9 (A7), U18.15 (D7)
/~BAI: IC1.27 (BUSACK), IC2.16 (~BAI), U3.14 (IO6), U8.12
/~BAO: IC2.15 (~BA0), P1.46, U7.2 (1A0), U17.3
/~BUSACK: P1.35, U7.18 (1Y0)
/~BUSRQ: IC1.29 (BUSRQ), IC2.17 (~BUSREQ), P1.31, RN2.7 (R6), U3.12 (IO8)
/~CS_DMA: IC2.18 (~CE/WAIT), U3.13 (IO7), U8.13
/~CS_I2C: U3.17 (I03), U11.12, U18.17 (~CS)
/~DREQ0: JP3.1 (A), P1.41
/~HALT: P1.36, U7.16 (1Y1)
/~IEO: P1.49, U1.13 (O6b)
/~IM2-INT: U2.9, U11.10, U12.14 (GS)
/~INTA: U8.9, U11.6, U11.9
/~INT: D5.1 (K), IC2.41 (~INT/PULSE), P1.32, RN2.5 (R4), U1.10 (I4), U2.8
/~IORQ: P1.40, R4.2, U7.3 (2Y0)
/~IRQ0: JP2.2 (B), P3.1, RN1.5 (R4), U12.4 (I7)
/~IRQ1: P3.2, RN1.4 (R3), U12.3 (I6)
/~IRQ2: P3.3, RN1.3 (R2), U12.2 (I5)
/~IRQ3: P3.4, RN1.2 (R1), U12.1 (I4)
/~IRQ4: P3.5, RN1.6 (R5), U12.13 (I3)
/~IRQ5: P3.6, RN1.7 (R6), U12.12 (I2)
/~IRQ6: P3.7, RN1.8 (R7), U12.11 (I1)
/~IRQ7: P3.8, RN1.9 (R8), U12.10 (IO)
/~M1: P1.27, U7.12 (1Y3)
/~MREQ: P1.38, R8.2, U7.5 (2Y1)
/~MR: U8.3, U8.5, U9.9 (~MR)
/~NMI: P1.34, RN2.4 (R3), U1.6 (I3), U2.5
/~RD: P1.39, R10.2, U7.9 (2Y3)
/~RESET: P1.29, RN2.2 (R1), U1.2 (I1), U2.10
/~RFSH: P1.25, U7.14 (1Y2)
/~TEND0: P1.45
/~WAIT: D3.1 (K), P1.33, RN2.6 (R5), U1.12 (I5), U2.12
/~WR: P1.37, R9.2, U7.7 (2Y2)
/~bIEO: IC2.40 (IEO), U1.14 (I6)
/~bIORQ: IC1.22 (IOREQ), IC2.11 (~IORQ), RN2.8 (R7), U3.9 (I9), U7.17 (2A0), U8.2, U11.5
/~bM1: IC1.31 (M1), IC2.30 (~M1), U3.8 (I8), U7.8 (1A3), U11.4, U13.11 (LE)
/~bMREQ: IC1.21 (MREQ), IC2.14 (~MREQ), U7.15 (2A1), U8.1, U10.14 (S0)
/~bRD: IC1.23 (RD), IC2.10 (~RD), U7.11 (2A3), U8.10, U10.2 (S1), U18.16 (~RD)
/~bRESET: IC1.30 (RESET), IC2.12 (~RESET), U1.3 (O1a), U3.2 (I2), U18.19 (~RST), U19.1 (~RESET/PB5)
/~bWAIT: IC1.28 (WAIT), U1.11 (O5b), U3.11 (I10/~OE)
/~bWR: IC1.26 (WR), IC2.9 (~WR), U7.13 (2A2), U11.13
GND: C1.2, C2.2, C3.2, C4.2, C5.2, C6.2, C7.2, C8.2, C9.2, C10.2, C11.2, C12.2, C13.2, C14.2, C15.2, C16.2, C17.2, C18.2, C19.2, C20.2, C21.2, C22.2, C23.2, C24.2, D1.1 (K), H1.1, H2.1, IC1.33 (GND), IC2.34 (GND), JP1.3 (B), JP4.1 (A), NT2.1, P1.23, P1.43, SW1.2, U1.1 (OEa), U1.8 (GND), U1.15 (OEb), U2.7 (GND), U3.10 (GND), U4.10 (GND), U5.10 (GND), U6.10 (GND), U7.1 (1OE), U7.10 (GND), U8.7 (GND), U9.7 (GND), U10.1 (Ea), U10.8 (GND), U11.7 (GND), U12.5 (EI), U12.8 (GND), U13.10 (GND), U14.7 (GND), U15.1 (A0), U15.4 (GND), U15.7 (WP), U16.11 (GND), U17.7 (GND), U18.10 (VSS), U19.4 (GND), U20.1 (GND), X1.4 (GND)
unnamed: D1.2 (A), R5.2
unnamed: C10.1, D2.2 (A), R6.2, R7.2, U2.11
unnamed: D3.2 (A), R3.1
unnamed: D4.2 (A), R1.1
unnamed: D4.1 (K), U2.6
unnamed: D5.2 (A), R2.1
unnamed: IC1.20 (HALT), U7.4 (1A1)
unnamed: IC1.18 (INT), U1.9 (O4a)
unnamed: IC1.19 (NMI), U1.7 (O3a)
unnamed: IC1.32 (RFSH), U7.6 (1A2), U8.4
unnamed: IC2.42 (IEI), NT4.2
unnamed: IC2.27 (RDY), JP3.3 (B)
unnamed: JP1.2 (C), U15.2 (A1), U15.3 (A2)
unnamed: JP3.2 (C), NT3.2
unnamed: R7.1, SW1.1
unnamed: U6.1 (A->B), U17.6
unnamed: U6.19 (CE), U8.11
unnamed: U8.6, U11.1
unnamed: U12.9 (S0), U13.4 (D1)
unnamed: U12.7 (S1), U13.7 (D2)
unnamed: U12.6 (S2), U13.8 (D3)
unnamed: NT2.2, U13.3 (D0), U13.13 (D4), U13.14 (D5), U13.17 (D6), U13.18 (D7)
unnamed: U11.8, U13.1 (OE)
unnamed: U14.3 (C), U17.1, U20.6 (CLK), X1.5 (OUT)
unnamed: U14.5 (Q), U14.13 (~R)
unnamed: U14.4 (~S), U14.9 (Q)
unnamed: U14.11 (C), U17.2
unnamed: Q1.1, U16.13 (Q1)
unnamed: Q2.1, U16.9 (Q2)
unnamed: Q3.1, U16.8 (Q3)
unnamed: U8.8, U17.5
unnamed: TestPoint1.1, U18.4 (~IACK)
unnamed: TestPoint2.1, U18.5 (~INT)
unnamed: U11.11, U18.18 (~WR)
unnamed: PB3.1, U19.2 (XTAL1/PB3)
unnamed: PB4.1, U19.3 (XTAL2/PB4)
VCC: C1.1, C2.1, C3.1, C4.1, C5.1, C6.1, C7.1, C8.1, C9.1, C11.1, C12.1, C13.1, C14.1, C15.1, C16.1, C17.1, C18.1, C19.1, C20.1, C21.1, C22.1, C23.1, C24.1, D2.1 (K), IC1.13 (+5V), IC2.13 (VCC), JP1.1 (A), JP4.3 (B), NT1.1, NT3.1, NT4.1, P1.22, P1.42, R1.2, R2.2, R3.2, R4.1, R5.1, R6.1, R8.1, R9.1, R10.1, R11.1, R12.1, RN1.1 (common), RN2.1 (common), U1.16 (VCC), U2.14 (VCC), U3.20 (VCC), U4.20 (VCC), U5.20 (VCC), U6.20 (VCC), U7.20 (VCC), U8.14 (VCC), U9.1 (DSA), U9.2 (DSB), U9.14 (VCC), U10.16 (VCC), U11.14 (VCC), U12.16 (VCC), U13.20 (VCC), U14.1 (~R), U14.10 (~S), U14.14 (VCC), U15.8 (VCC), U16.4 (VCC), U17.14 (VCC), U18.20 (VDD), U19.8 (VCC), U20.7 (OE), U20.8 (VCC), X1.1 (EN), X1.8 (Vcc)

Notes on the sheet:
IEO is an output so the last device does not need to be terminated
Spare Gates
BUSAK
IEI
+5v
DEV
BAO
The following input signals from the backplane are permanently buffered: /RESET /NMI /INT /WAIT
DMA
IEO
The following locally generated signals on the board reenter through the back plane: /RESET from the reset button /INT from the DMA chip
Note: Bus connector is mirror image of Z80 CPU pin out to mate to backplane whose connectors reflect Z80 CPU pin out.
BAI
The following output signals are buffered and permanently driven to the backplane: /BUSACK /HALT /RFRSH /M1 CLK
Wait State Generator Circuit
Interrupt Mode 2 (IM2) Circuit
Tri-state address, data, & control bus during DMA
BUFFER
The following signals have 4K7 pullups on backplane side: CLK /NMI /INT /WAIT /BUSRQ The following signals have 1K8 pullups on backplane side: /IORQ /MREQ /WR /RD
CPU

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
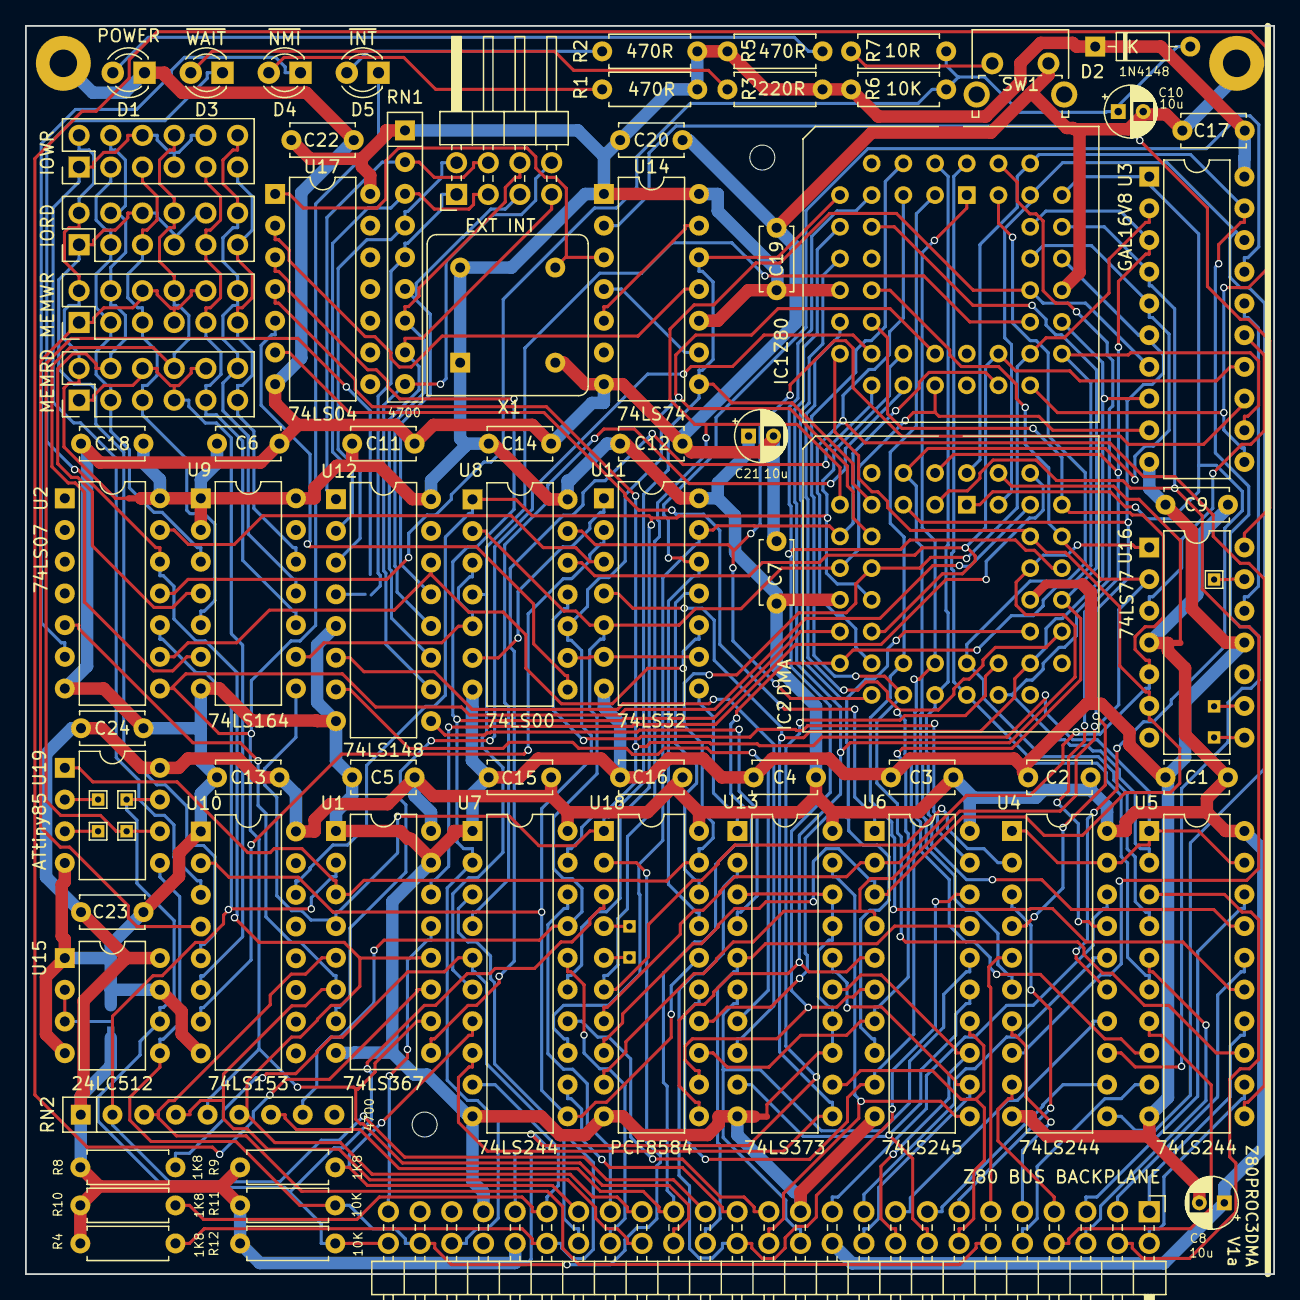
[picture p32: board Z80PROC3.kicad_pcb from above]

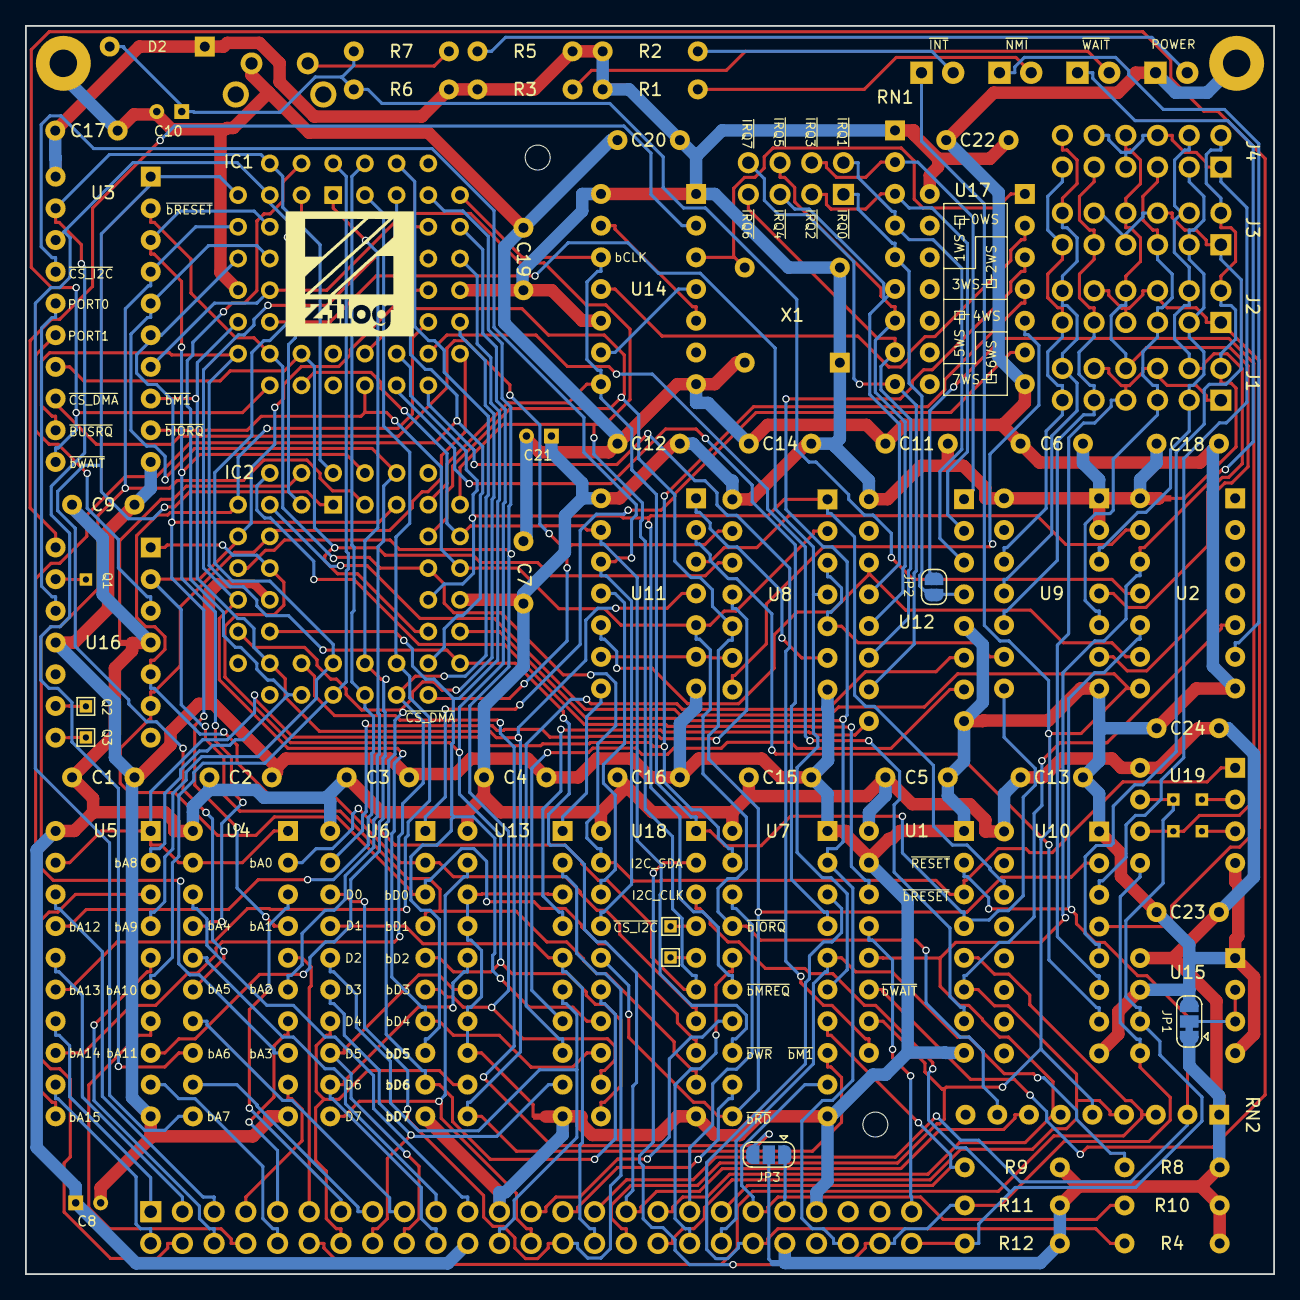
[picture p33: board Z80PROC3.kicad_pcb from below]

Board: 2 copper layers, 100.0 x 100.0 mm, 92 parts (8 on the bottom side), 147 nets.

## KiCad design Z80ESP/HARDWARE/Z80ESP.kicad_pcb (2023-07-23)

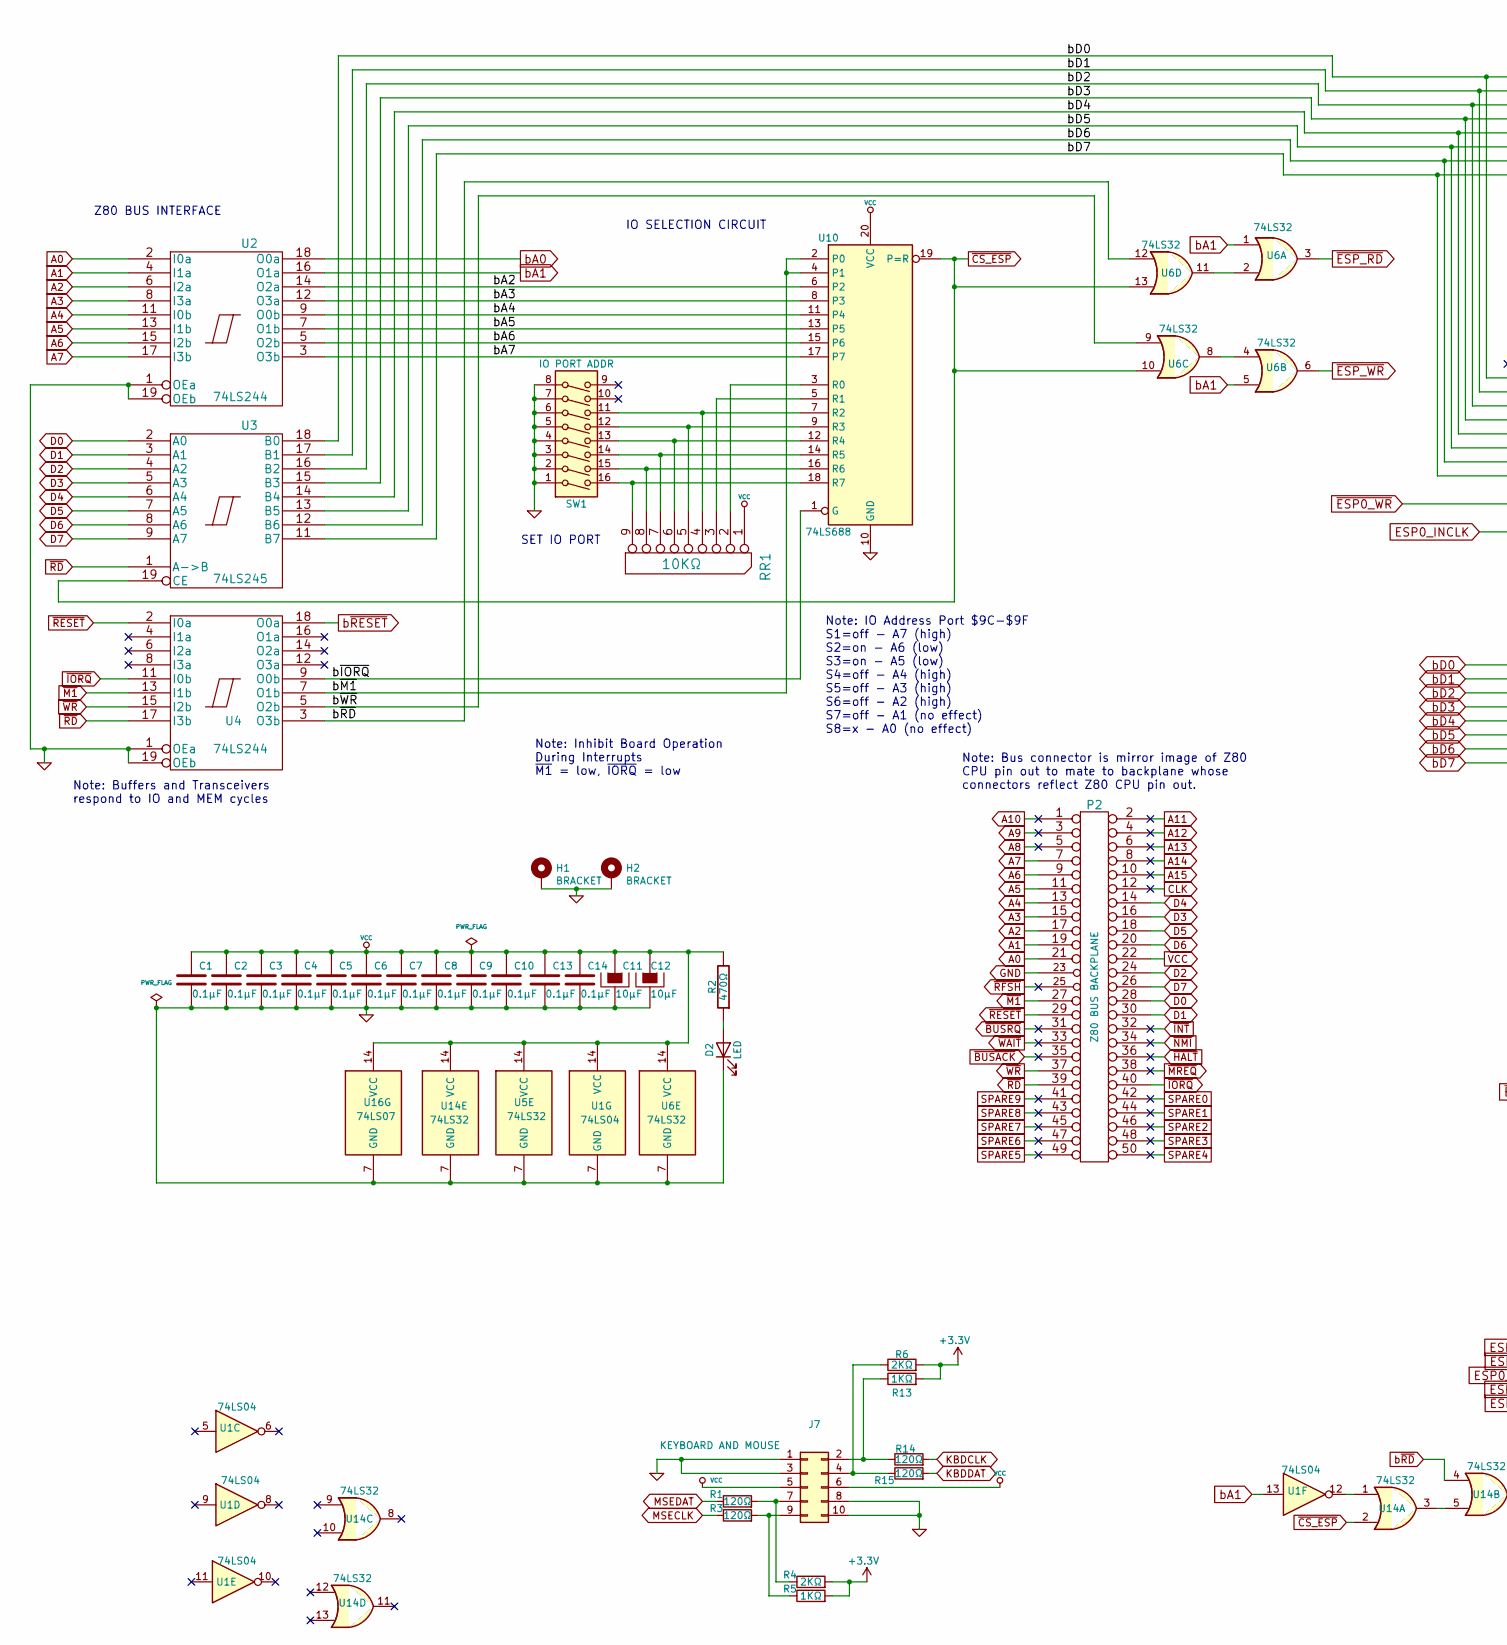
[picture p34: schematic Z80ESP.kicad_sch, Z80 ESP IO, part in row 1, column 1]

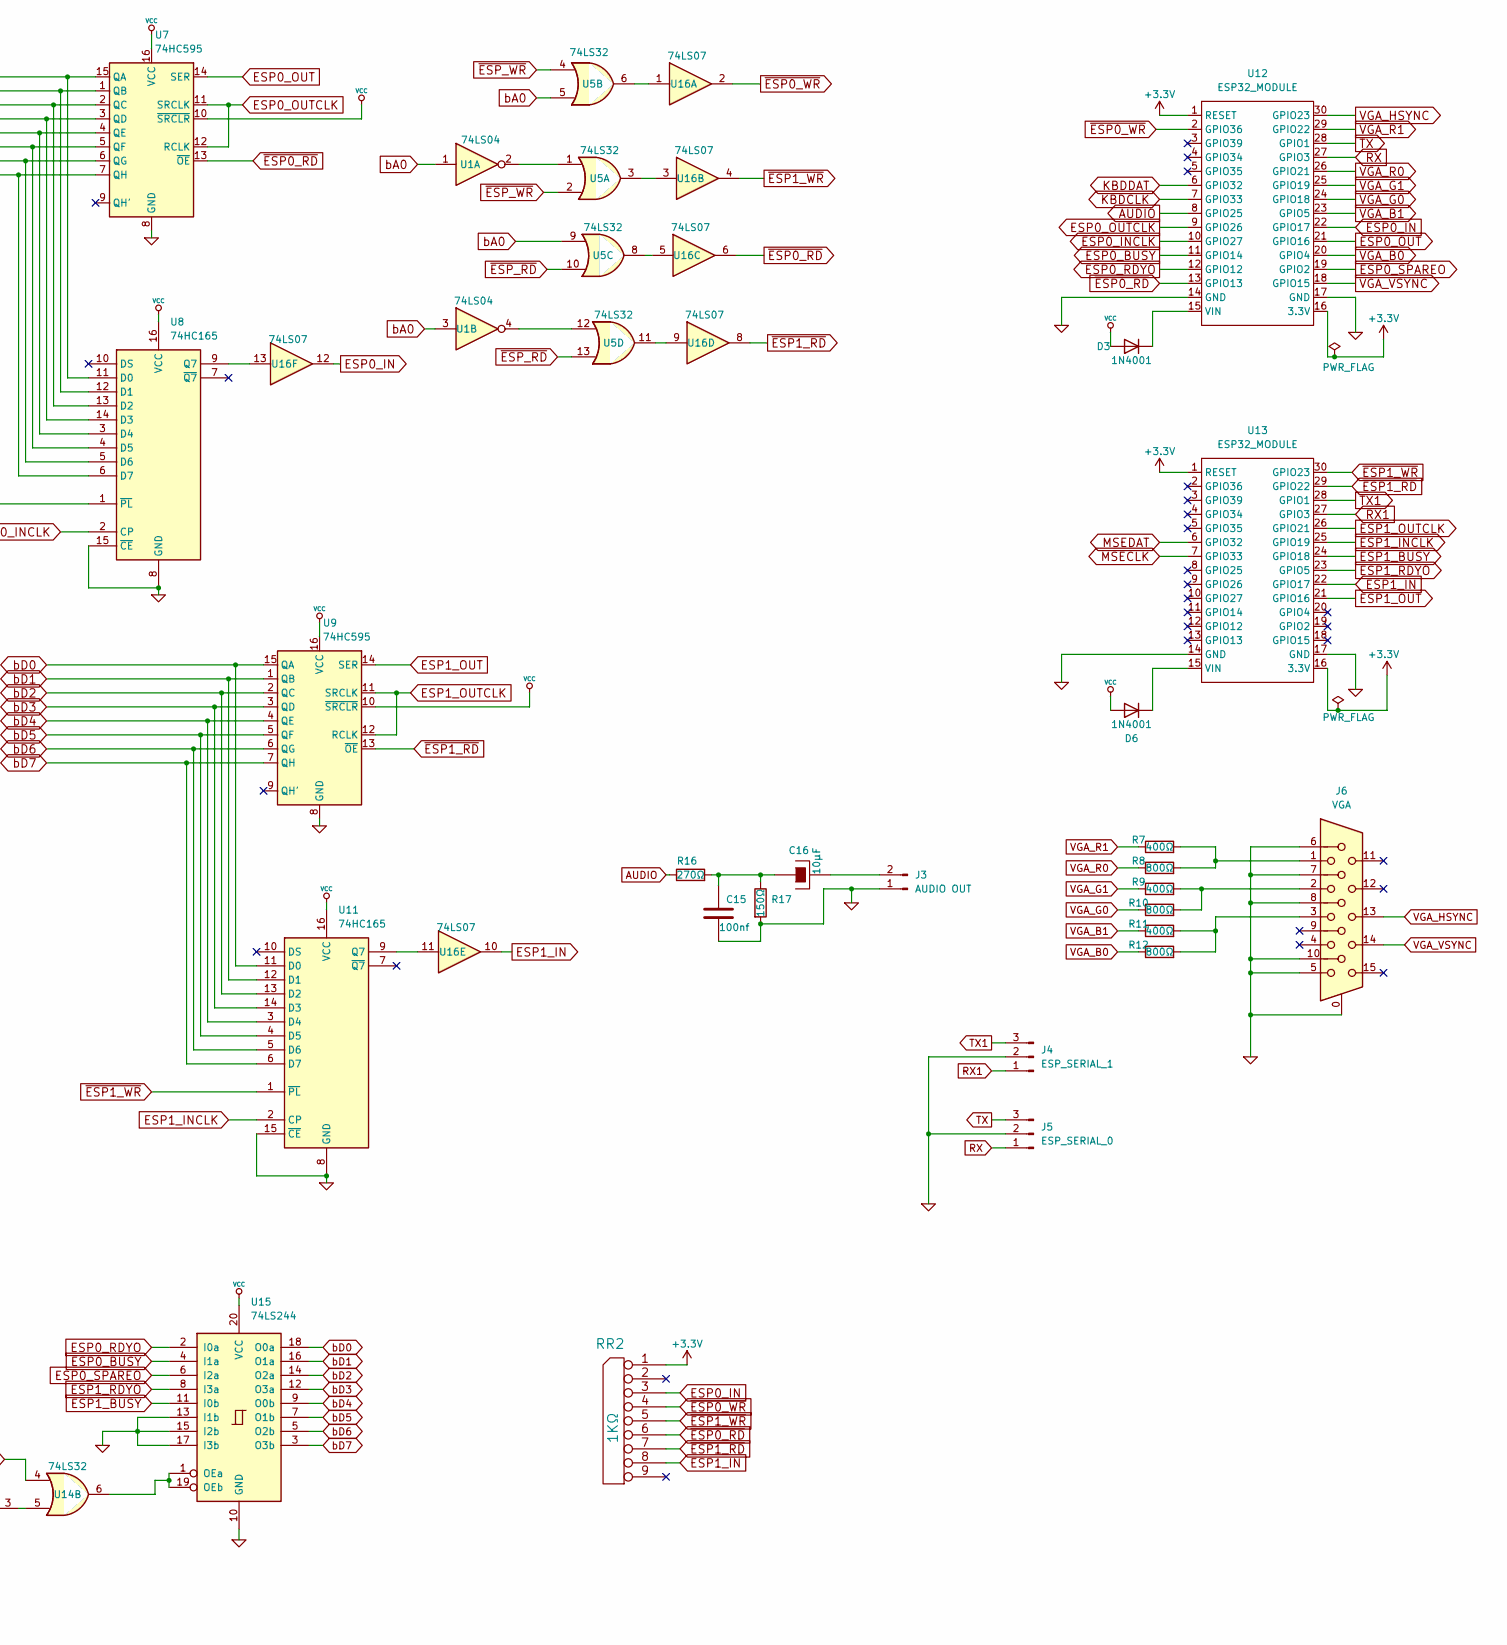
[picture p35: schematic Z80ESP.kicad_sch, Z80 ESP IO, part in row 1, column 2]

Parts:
C1, C2, C3, C4, C5, C6, C7, C8, C9, C10, C13, C14: 0.1µF; C_Disc_D5.0mm_W2.5mm_P5.00mm
C11, C12, C16: 10µF; CP_Radial_D5.0mm_P2.50mm
C15: 100nf; C_Disc_D5.0mm_W2.5mm_P5.00mm
D2: LED; LED_D3.0mm
D3, D6: 1N4001; D_DO-41_SOD81_P10.16mm_Horizontal
H1, H2: BRACKET; MountingHole_2.2mm_M2_Pad
J3: AUDIO OUT; PinHeader_1x02_P2.54mm_Horizontal
J4: ESP_SERIAL_1; PinHeader_1x03_P2.54mm_Horizontal
J5: ESP_SERIAL_0; PinHeader_1x03_P2.54mm_Vertical
J6: VGA; DSUB-15-HD_Female_Horizontal_P2.29x1.98mm_EdgePinOffset3.03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
J7: KEYBOARD AND MOUSE; PinHeader_2x05_P2.54mm_Horizontal
P2: Z80 BUS BACKPLANE; PinHeader_2x25_P2.54mm_Horizontal
R1, R3, R14, R15: 120Ω; R_Axial_DIN0207_L6.3mm_D2.5mm_P7.62mm_Horizontal
R2: 470Ω; R_Axial_DIN0207_L6.3mm_D2.5mm_P7.62mm_Horizontal
R4, R6: 2KΩ; R_Axial_DIN0207_L6.3mm_D2.5mm_P7.62mm_Horizontal
R5, R13: 1KΩ; R_Axial_DIN0207_L6.3mm_D2.5mm_P7.62mm_Horizontal
R7, R9, R11: 400Ω; R_Axial_DIN0207_L6.3mm_D2.5mm_P7.62mm_Horizontal
R8, R10, R12: 800Ω; R_Axial_DIN0207_L6.3mm_D2.5mm_P7.62mm_Horizontal
R16: 270Ω; R_Axial_DIN0207_L6.3mm_D2.5mm_P7.62mm_Horizontal
R17: 150Ω; R_Axial_DIN0207_L6.3mm_D2.5mm_P7.62mm_Horizontal
RR1: 10KΩ; R_Array_SIP9
RR2: 1KΩ; R_Array_SIP9
SW1: IO PORT ADDR; SW_DIP_SPSTx08_Slide_9.78x22.5mm_W7.62mm_P2.54mm
U1: 74LS04; DIP-14_W7.62mm
U2, U4, U15: 74LS244; DIP-20_W7.62mm
U3: 74LS245; DIP-20_W7.62mm
U5, U6, U14: 74LS32; DIP-14_W7.62mm
U7, U9: 74HC595; DIP-16_W7.62mm
U8, U11: 74HC165; DIP-16_W7.62mm
U10: 74LS688; DIP-20_W7.62mm
U12, U13: ESP32_MODULE
U16: 74LS07; DIP-14_W7.62mm

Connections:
+3.3V: R4.2, R5.2, R6.2, R13.2, RR2.1 (COM), U12.1 (RESET), U12.16 (3.3V), U13.1 (RESET), U13.16 (3.3V)
/bA2: U2.14 (O2a), U10.6 (P2)
/bA3: U2.12 (O3a), U10.8 (P3)
/bA4: U2.9 (O0b), U10.11 (P4)
/bA5: U2.7 (O1b), U10.13 (P5)
/bA6: U2.5 (O2b), U10.15 (P6)
/bA7: U2.3 (O3b), U10.17 (P7)
/b~IORQ: U4.9 (O0b), U10.1 (G)
/b~M1: U4.7 (O1b), U10.2 (P0), U10.4 (P1)
/b~WR: U4.5 (O2b), U6.9
A0: P2.21, U2.2 (I0a)
A1: P2.19, U2.4 (I1a)
A2: P2.17, U2.6 (I2a)
A3: P2.15, U2.8 (I3a)
A4: P2.13, U2.11 (I0b)
A5: P2.11, U2.13 (I1b)
A6: P2.9, U2.15 (I2b)
A7: P2.7, U2.17 (I3b)
A8: P2.5
A9: P2.3
A10: P2.1
A11: P2.2
A12: P2.4
A13: P2.6
A14: P2.8
A15: P2.10
AUDIO: R16.1, U12.8 (GPIO25)
CLK: P2.12
D0: P2.28, U3.2 (A0)
D1: P2.30, U3.3 (A1)
D2: P2.24, U3.4 (A2)
D3: P2.16, U3.5 (A3)
D4: P2.14, U3.6 (A4)
D5: P2.18, U3.7 (A5)
D6: P2.20, U3.8 (A6)
D7: P2.26, U3.9 (A7)
ESP0_BUSY: U12.11 (GPIO14), U15.4 (I1a)
ESP0_IN: RR2.3, U12.22 (GPIO17), U16.12
ESP0_INCLK: U8.2 (CP), U12.10 (GPIO27)
ESP0_OUT: U7.14 (SER), U12.21 (GPIO16)
ESP0_OUTCLK: U7.11 (SRCLK), U7.12 (RCLK), U12.9 (GPIO26)
ESP0_RDYO: U12.12 (GPIO12), U15.2 (I0a)
ESP0_SPAREO: U12.19 (GPIO2), U15.6 (I2a)
ESP1_BUSY: U13.24 (GPIO18), U15.11 (I0b)
ESP1_IN: RR2.8, U13.22 (GPIO17), U16.10
ESP1_INCLK: U11.2 (CP), U13.25 (GPIO19)
ESP1_OUT: U9.14 (SER), U13.21 (GPIO16)
ESP1_OUTCLK: U9.11 (SRCLK), U9.12 (RCLK), U13.26 (GPIO21)
ESP1_RDYO: U13.23 (GPIO5), U15.8 (I3a)
GND: C1.2, C2.2, C3.2, C4.2, C5.2, C6.2, C7.2, C8.2, C9.2, C10.2, C11.2, C12.2, C13.2, C14.2, C15.2, D2.1 (K), H1.1, H2.1, J3.1, J4.2, J5.2, J6.0, J6.5, J6.6, J6.7, J6.8, J6.10, J7.1, J7.3, J7.8, J7.10, P2.23, R17.2, SW1.1, SW1.2, SW1.3, SW1.4, SW1.5, SW1.6, SW1.7, SW1.8, U1.7 (GND), U2.1 (OEa), U2.10 (GND), U2.19 (OEb), U3.10 (GND), U4.1 (OEa), U4.10 (GND), U4.19 (OEb), U5.7 (GND), U6.7 (GND), U7.8 (GND), U8.8 (GND), U8.15 (~CE), U9.8 (GND), U10.10 (GND), U11.8 (GND), U11.15 (~CE), U12.14 (GND), U12.17 (GND), U13.14 (GND), U13.17 (GND), U14.7 (GND), U15.10 (GND), U15.13 (I1b), U15.15 (I2b), U15.17 (I3b), U16.7 (GND)
KBDCLK: R14.2, U12.7 (GPIO33)
KBDDAT: R15.2, U12.6 (GPIO32)
MSECLK: R3.1, U13.7 (GPIO33)
MSEDAT: R1.1, U13.6 (GPIO32)
unnamed: C15.1, C16.1, R16.2, R17.1
unnamed: C16.2, J3.2
unnamed: D2.2 (A), R2.1
unnamed: D3.1 (K), U12.15 (VIN)
unnamed: D6.1 (K), U13.15 (VIN)
unnamed: J6.1, R7.2, R8.2
unnamed: J6.2, R9.2, R10.2
unnamed: J6.3, R11.2, R12.2
unnamed: J7.2, R13.1, R14.1
unnamed: J7.4, R6.1, R15.1
unnamed: J7.7, R1.2, R4.1
unnamed: J7.9, R3.2, R5.1
unnamed: RR1.2, U10.3 (R0)
unnamed: RR1.3, U10.5 (R1)
unnamed: RR1.4, SW1.11, U10.7 (R2)
unnamed: RR1.5, SW1.12, U10.9 (R3)
unnamed: RR1.6, SW1.13, U10.12 (R4)
unnamed: RR1.7, SW1.14, U10.14 (R5)
unnamed: RR1.8, SW1.15, U10.16 (R6)
unnamed: RR1.9, SW1.16, U10.18 (R7)
unnamed: U1.2, U5.1
unnamed: U1.4, U5.12
unnamed: U1.12, U14.1
unnamed: U6.4, U6.8
unnamed: U6.2, U6.11
unnamed: U11.9 (Q7), U16.11
unnamed: U14.3, U14.5
unnamed: U14.6, U15.1 (OEa), U15.19 (OEb)
unnamed: U5.6, U16.1
unnamed: U5.3, U16.3
unnamed: U5.8, U16.5
unnamed: U5.11, U16.9
unnamed: U8.9 (Q7), U16.13
RX: J5.1, U12.27 (GPIO3)
RX1: J4.1, U13.27 (GPIO3)
SPARE0: P2.42
SPARE1: P2.44
SPARE2: P2.46
SPARE3: P2.48
SPARE4: P2.50
SPARE5: P2.49
SPARE6: P2.47
SPARE7: P2.45
SPARE8: P2.43
SPARE9: P2.41
TX: J5.3, U12.28 (GPIO1)
TX1: J4.3, U13.28 (GPIO1)
VCC: C1.1, C2.1, C3.1, C4.1, C5.1, C6.1, C7.1, C8.1, C9.1, C10.1, C11.1, C12.1, C13.1, C14.1, D3.2 (A), D6.2 (A), J7.5, J7.6, P2.22, R2.2, RR1.1 (COM), U1.14 (VCC), U2.20 (VCC), U3.20 (VCC), U4.20 (VCC), U5.14 (VCC), U6.14 (VCC), U7.10 (~SRCLR), U7.16 (VCC), U8.16 (VCC), U9.10 (~SRCLR), U9.16 (VCC), U10.20 (VCC), U11.16 (VCC), U14.14 (VCC), U15.20 (VCC), U16.14 (VCC)
VGA_B0: R12.1, U12.20 (GPIO4)
VGA_B1: R11.1, U12.23 (GPIO5)
VGA_G0: R10.1, U12.24 (GPIO18)
VGA_G1: R9.1, U12.25 (GPIO19)
VGA_HSYNC: J6.13, U12.30 (GPIO23)
VGA_R0: R8.1, U12.26 (GPIO21)
VGA_R1: R7.1, U12.29 (GPIO22)
VGA_VSYNC: J6.14, U12.18 (GPIO15)
bA0: U1.1, U1.3, U2.18 (O0a), U5.5, U5.9
bA1: U1.13, U2.16 (O1a), U6.1, U6.5
bD0: U3.18 (B0), U7.15 (QA), U8.11 (D0), U9.15 (QA), U11.11 (D0), U15.18 (O0a)
bD1: U3.17 (B1), U7.1 (QB), U8.12 (D1), U9.1 (QB), U11.12 (D1), U15.16 (O1a)
bD2: U3.16 (B2), U7.2 (QC), U8.13 (D2), U9.2 (QC), U11.13 (D2), U15.14 (O2a)
bD3: U3.15 (B3), U7.3 (QD), U8.14 (D3), U9.3 (QD), U11.14 (D3), U15.12 (O3a)
bD4: U3.14 (B4), U7.4 (QE), U8.3 (D4), U9.4 (QE), U11.3 (D4), U15.9 (O0b)
bD5: U3.13 (B5), U7.5 (QF), U8.4 (D5), U9.5 (QF), U11.4 (D5), U15.7 (O1b)
bD6: U3.12 (B6), U7.6 (QG), U8.5 (D6), U9.6 (QG), U11.5 (D6), U15.5 (O2b)
bD7: U3.11 (B7), U7.7 (QH), U8.6 (D7), U9.7 (QH), U11.6 (D7), U15.3 (O3b)
b~RD: U4.3 (O3b), U6.12, U14.4
b~RESET: U4.18 (O0a)
~BUSACK: P2.35
~BUSRQ: P2.31
~CS_ESP: U3.19 (CE), U6.10, U6.13, U10.19 (P=R), U14.2
~ESP0_RD: RR2.6, U7.13 (~OE), U12.13 (GPIO13), U16.6
~ESP0_WR: RR2.4, U8.1 (~PL), U12.2 (GPIO36), U16.2
~ESP1_RD: RR2.7, U9.13 (~OE), U13.29 (GPIO22), U16.8
~ESP1_WR: RR2.5, U11.1 (~PL), U13.30 (GPIO23), U16.4
~ESP_RD: U5.10, U5.13, U6.3
~ESP_WR: U5.2, U5.4, U6.6
~HALT: P2.36
~INT: P2.32
~IORQ: P2.40, U4.11 (I0b)
~M1: P2.27, U4.13 (I1b)
~MREQ: P2.38
~NMI: P2.34
~RD: P2.39, U3.1 (A->B), U4.17 (I3b)
~RESET: P2.29, U4.2 (I0a)
~RFSH: P2.25
~WAIT: P2.33
~WR: P2.37, U4.15 (I2b)

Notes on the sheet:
Note: Buffers and Transceivers respond to IO and MEM cycles
SET IO PORT
Note: IO Address Port $9C-$9F S1=off - A7 (high) S2=on - A6 (low) S3=on - A5 (low) S4=off - A4 (high) S5=off - A3 (high) S6=off - A2 (high) S7=off - A1 (no effect) S8=x - A0 (no effect)
Note: Inhibit Board Operation During Interrupts ~{M1} = low, ~{IORQ} = low
Z80 BUS INTERFACE
Note: Bus connector is mirror image of Z80 CPU pin out to mate to backplane whose connectors reflect Z80 CPU pin out.
IO SELECTION CIRCUIT

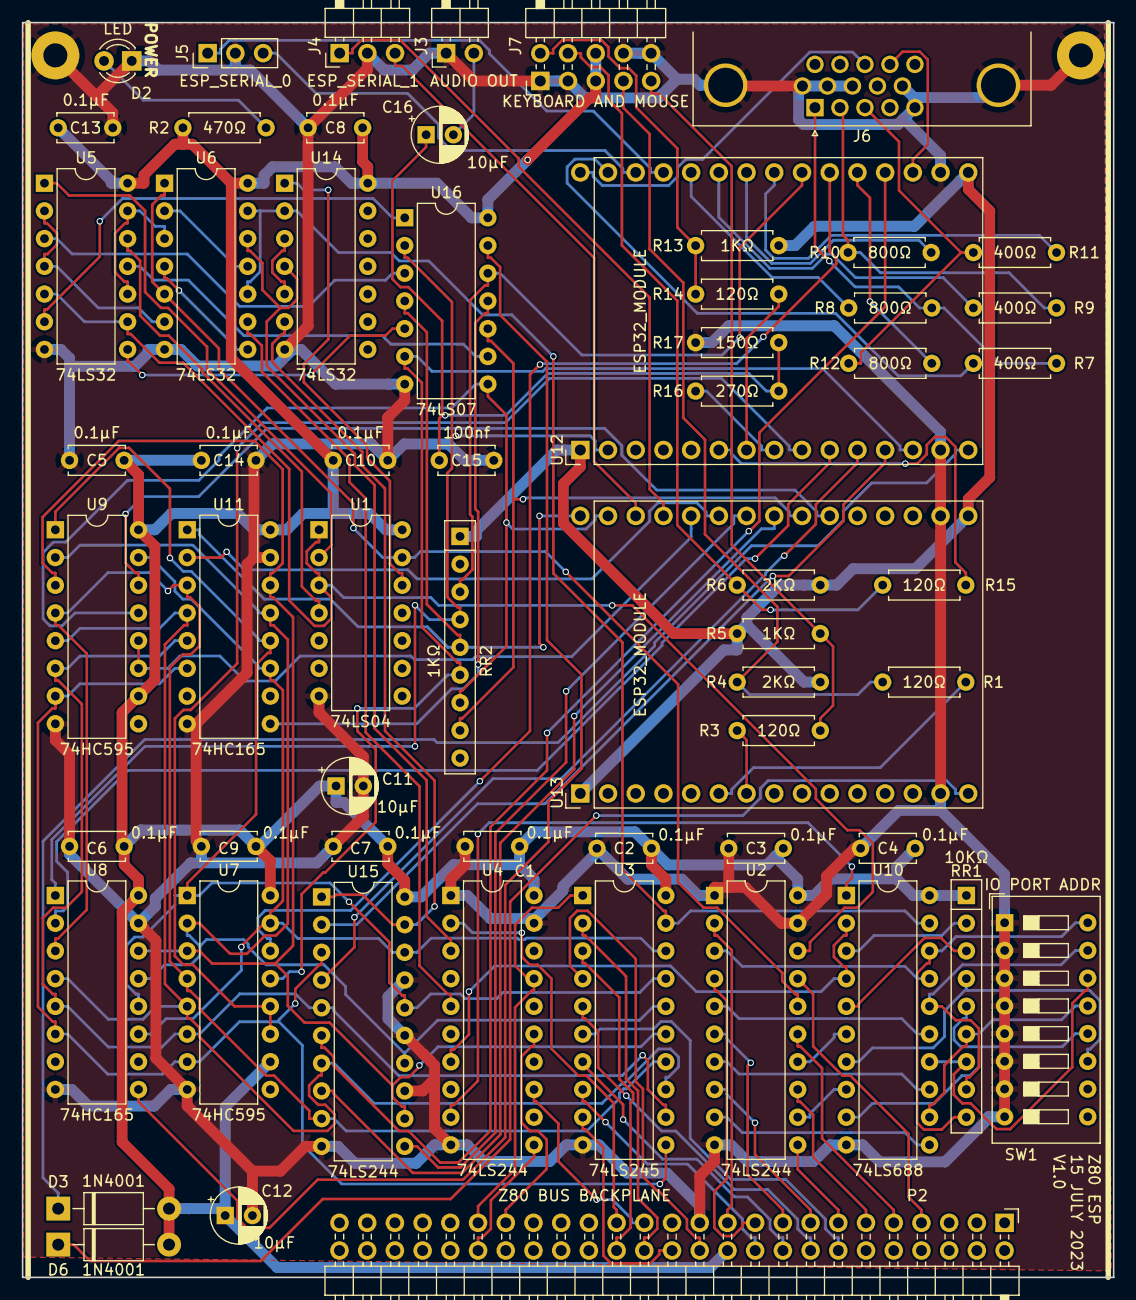
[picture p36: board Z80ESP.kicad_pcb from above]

Board: 2 copper layers, 100.0 x 115.0 mm, 63 parts (0 on the bottom side), 114 nets.

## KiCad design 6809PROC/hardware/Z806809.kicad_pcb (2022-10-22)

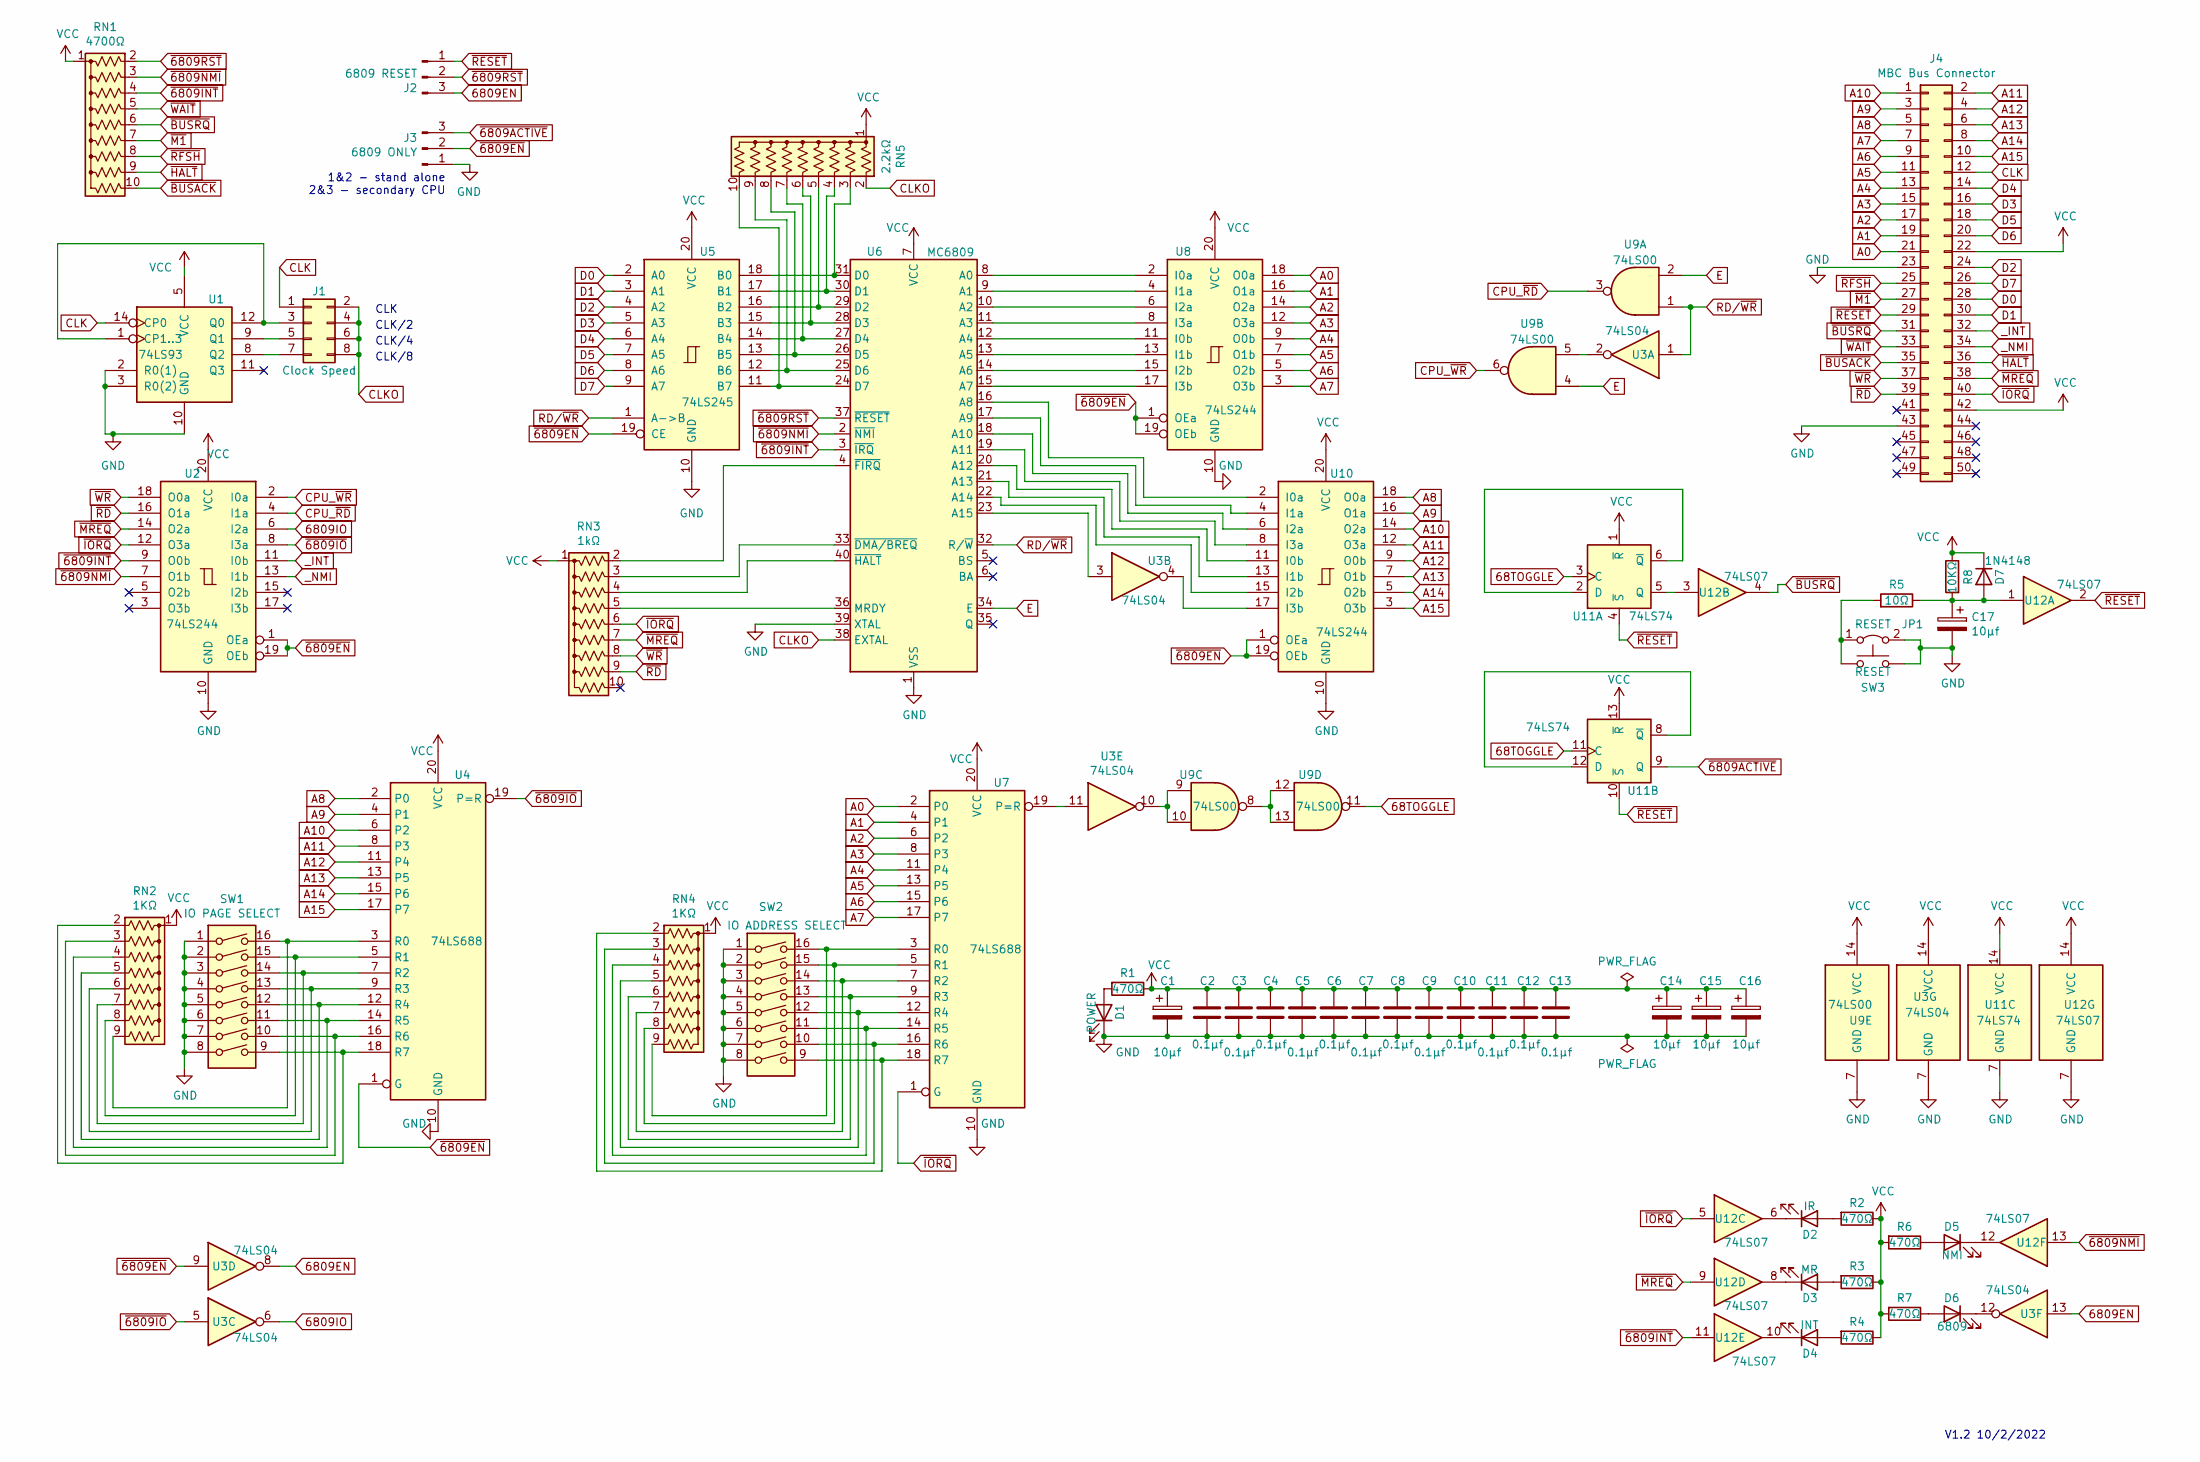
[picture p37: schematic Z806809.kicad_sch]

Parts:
C1, C14, C15, C16, C17: 10µf; CP_Radial_D4.0mm_P2.00mm
C2, C3, C4, C5, C6, C7, C8, C9, C10, C11, C12, C13: 0.1µf; C_Disc_D7.5mm_W2.5mm_P5.00mm
D1: POWER; LED_D3.0mm
D2: IR; LED_D3.0mm
D3: MR; LED_D3.0mm
D4: INT; LED_D3.0mm
D5: NMI; LED_D3.0mm
D6: 6809; LED_D3.0mm
D7: 1N4148; D_A-405_P7.62mm_Horizontal
J1: Clock Speed; PinHeader_2x04_P2.54mm_Horizontal
J2: 6809 RESET; PinHeader_1x03_P2.54mm_Horizontal
J3: 6809 ONLY; PinHeader_1x03_P2.54mm_Horizontal
J4: MBC Bus Connector; PinHeader_2x25_P2.54mm_Horizontal
JP1: RESET; PinHeader_1x02_P2.54mm_Vertical
R1, R2, R3, R4, R6, R7: 470Ω; R_Axial_DIN0207_L6.3mm_D2.5mm_P7.62mm_Horizontal
R5: 10Ω; R_Axial_DIN0207_L6.3mm_D2.5mm_P7.62mm_Horizontal
R8: 10KΩ; R_Axial_DIN0207_L6.3mm_D2.5mm_P7.62mm_Horizontal
RN1: 4700Ω; R_Array_SIP10
RN2, RN4: 1KΩ; R_Array_SIP9
RN3: 1kΩ; R_Array_SIP10
RN5: 2.2kΩ; R_Array_SIP10
SW1: IO PAGE SELECT; SW_DIP_SPSTx08_Slide_6.7x21.88mm_W7.62mm_P2.54mm_LowProfile
SW2: IO ADDRESS SELECT; SW_DIP_SPSTx08_Slide_6.7x21.88mm_W7.62mm_P2.54mm_LowProfile
SW3: RESET; SW_Tactile_SPST_Angled_PTS645Vx31-2LFS
U1: 74LS93; DIP-14_W7.62mm_Socket_LongPads
U2, U8, U10: 74LS244; DIP-20_W7.62mm_Socket_LongPads
U3: 74LS04; DIP-14_W7.62mm_Socket_LongPads
U4, U7: 74LS688; DIP-20_W7.62mm_Socket_LongPads
U5: 74LS245; DIP-20_W7.62mm_Socket_LongPads
U6: MC6809; DIP-40_W15.24mm_LongPads
U9: 74LS00; DIP-14_W7.62mm_Socket_LongPads
U11: 74LS74; DIP-14_W7.62mm_Socket_LongPads
U12: 74LS07; DIP-14_W7.62mm_Socket_LongPads

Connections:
68TOGGLE: U9.11, U11.3 (C), U11.11 (C)
6809EN: J2.3, U3.8, U3.13
6809IO: U2.6 (I2a), U3.6
A0: J4.21, U7.2 (P0), U8.18 (O0a)
A1: J4.19, U7.4 (P1), U8.16 (O1a)
A2: J4.17, U7.6 (P2), U8.14 (O2a)
A3: J4.15, U7.8 (P3), U8.12 (O3a)
A4: J4.13, U7.11 (P4), U8.9 (O0b)
A5: J4.11, U7.13 (P5), U8.7 (O1b)
A6: J4.9, U7.15 (P6), U8.5 (O2b)
A7: J4.7, U7.17 (P7), U8.3 (O3b)
A8: J4.5, U4.2 (P0), U10.18 (O0a)
A9: J4.3, U4.4 (P1), U10.16 (O1a)
A10: J4.1, U4.6 (P2), U10.14 (O2a)
A11: J4.2, U4.8 (P3), U10.12 (O3a)
A12: J4.4, U4.11 (P4), U10.9 (O0b)
A13: J4.6, U4.13 (P5), U10.7 (O1b)
A14: J4.8, U4.15 (P6), U10.5 (O2b)
A15: J4.10, U4.17 (P7), U10.3 (O3b)
CLK: J1.1, J4.12, U1.14 (CP0)
CLKO: J1.2, J1.4, J1.6, J1.8, RN5.2 (R1), U6.38 (EXTAL)
CPU_~RD: U2.4 (I1a), U9.3
CPU_~WR: U2.2 (I0a), U9.6
D0: J4.28, U5.2 (A0)
D1: J4.30, U5.3 (A1)
D2: J4.24, U5.4 (A2)
D3: J4.16, U5.5 (A3)
D4: J4.14, U5.6 (A4)
D5: J4.18, U5.7 (A5)
D6: J4.20, U5.8 (A6)
D7: J4.26, U5.9 (A7)
E: U6.34 (E), U9.2, U9.4
GND: C1.2, C2.2, C3.2, C4.2, C5.2, C6.2, C7.2, C8.2, C9.2, C10.2, C11.2, C12.2, C13.2, C14.2, C15.2, C16.2, C17.2, D1.1 (K), J3.1, J4.23, J4.43, JP1.2 (B), SW1.1, SW1.2, SW1.3, SW1.4, SW1.5, SW1.6, SW1.7, SW1.8, SW2.1, SW2.2, SW2.3, SW2.4, SW2.5, SW2.6, SW2.7, SW2.8, SW3.2, U1.2 (R0(1)), U1.3 (R0(2)), U1.10 (GND), U2.10 (GND), U3.7 (GND), U4.10 (GND), U5.10 (GND), U6.1 (VSS), U6.39 (XTAL), U7.10 (GND), U8.10 (GND), U9.7 (GND), U10.10 (GND), U11.7 (GND), U12.7 (GND)
unnamed: C17.1, D7.2 (A), R5.1, R8.2, U12.1
unnamed: D1.2 (A), R1.2
unnamed: D2.1 (K), U12.6
unnamed: D2.2 (A), R2.2
unnamed: D3.1 (K), U12.8
unnamed: D3.2 (A), R3.2
unnamed: D4.1 (K), U12.10
unnamed: D4.2 (A), R4.2
unnamed: D5.1 (K), U12.12
unnamed: D5.2 (A), R6.1
unnamed: D6.1 (K), U3.12
unnamed: D6.2 (A), R7.1
unnamed: J1.3, U1.1 (CP1..3), U1.12 (Q0)
unnamed: J1.5, U1.9 (Q1)
unnamed: J1.7, U1.8 (Q2)
unnamed: JP1.1 (A), R5.2, SW3.1
unnamed: RN2.2 (R1), SW1.9, U4.18 (R7)
unnamed: RN2.3 (R2), SW1.10, U4.16 (R6)
unnamed: RN2.4 (R3), SW1.11, U4.14 (R5)
unnamed: RN2.5 (R4), SW1.12, U4.12 (R4)
unnamed: RN2.6 (R5), SW1.13, U4.9 (R3)
unnamed: RN2.7 (R6), SW1.14, U4.7 (R2)
unnamed: RN2.8 (R7), SW1.15, U4.5 (R1)
unnamed: RN2.9 (R8), SW1.16, U4.3 (R0)
unnamed: RN3.2 (R1), U6.4 (~FIRQ)
unnamed: RN3.3 (R2), U6.33 (~DMA/BREQ)
unnamed: RN3.4 (R3), U6.40 (~HALT)
unnamed: RN3.5 (R4), U6.36 (MRDY)
unnamed: RN4.2 (R1), SW2.9, U7.18 (R7)
unnamed: RN4.3 (R2), SW2.10, U7.16 (R6)
unnamed: RN4.4 (R3), SW2.11, U7.14 (R5)
unnamed: RN4.5 (R4), SW2.12, U7.12 (R4)
unnamed: RN4.6 (R5), SW2.13, U7.9 (R3)
unnamed: RN4.7 (R6), SW2.14, U7.7 (R2)
unnamed: RN4.8 (R7), SW2.15, U7.5 (R1)
unnamed: RN4.9 (R8), SW2.16, U7.3 (R0)
unnamed: RN5.3 (R2), U5.18 (B0), U6.31 (D0)
unnamed: RN5.4 (R3), U5.17 (B1), U6.30 (D1)
unnamed: RN5.5 (R4), U5.16 (B2), U6.29 (D2)
unnamed: RN5.6 (R5), U5.15 (B3), U6.28 (D3)
unnamed: RN5.7 (R6), U5.14 (B4), U6.27 (D4)
unnamed: RN5.8 (R7), U5.13 (B5), U6.26 (D5)
unnamed: RN5.9 (R8), U5.12 (B6), U6.25 (D6)
unnamed: RN5.10 (R9), U5.11 (B7), U6.24 (D7)
unnamed: U3.2, U9.5
unnamed: U3.3, U6.23 (A15)
unnamed: U3.10, U9.9, U9.10
unnamed: U3.11, U7.19 (P=R)
unnamed: U6.8 (A0), U8.2 (I0a)
unnamed: U6.9 (A1), U8.4 (I1a)
unnamed: U6.10 (A2), U8.6 (I2a)
unnamed: U6.11 (A3), U8.8 (I3a)
unnamed: U6.12 (A4), U8.11 (I0b)
unnamed: U6.13 (A5), U8.13 (I1b)
unnamed: U6.14 (A6), U8.15 (I2b)
unnamed: U6.15 (A7), U8.17 (I3b)
unnamed: U9.8, U9.12, U9.13
unnamed: U6.16 (A8), U10.2 (I0a)
unnamed: U6.17 (A9), U10.4 (I1a)
unnamed: U6.18 (A10), U10.6 (I2a)
unnamed: U6.19 (A11), U10.8 (I3a)
unnamed: U6.20 (A12), U10.11 (I0b)
unnamed: U6.21 (A13), U10.13 (I1b)
unnamed: U6.22 (A14), U10.15 (I2b)
unnamed: U3.4, U10.17 (I3b)
unnamed: U11.2 (D), U11.6 (~Q)
unnamed: U11.5 (Q), U12.3
unnamed: U11.8 (~Q), U11.12 (D)
RD/~WR: U3.1, U5.1 (A->B), U6.32 (R/~W), U9.1
VCC: C1.1, C2.1, C3.1, C4.1, C5.1, C6.1, C7.1, C8.1, C9.1, C10.1, C11.1, C12.1, C13.1, C14.1, C15.1, C16.1, D7.1 (K), J4.22, J4.42, R1.1, R2.1, R3.1, R4.1, R6.2, R7.2, R8.1, RN1.1 (common), RN2.1 (common), RN3.1 (common), RN4.1 (common), RN5.1 (common), U1.5 (VCC), U2.20 (VCC), U3.14 (VCC), U4.20 (VCC), U5.20 (VCC), U6.7 (VCC), U7.20 (VCC), U8.20 (VCC), U9.14 (VCC), U10.20 (VCC), U11.1 (~R), U11.13 (~R), U11.14 (VCC), U12.14 (VCC)
_INT: J4.32, U2.11 (I0b)
_NMI: J4.34, U2.13 (I1b)
~6809ACTIVE: J3.3, U11.9 (Q)
~6809EN: J3.2, U2.1 (OEa), U2.19 (OEb), U3.9, U4.1 (G), U5.19 (CE), U8.1 (OEa), U8.19 (OEb), U10.1 (OEa), U10.19 (OEb)
~6809INT: RN1.4 (R3), U2.9 (O0b), U6.3 (~IRQ), U12.11
~6809IO: U2.8 (I3a), U3.5, U4.19 (P=R)
~6809NMI: RN1.3 (R2), U2.7 (O1b), U6.2 (~NMI), U12.13
~6809RST: J2.2, RN1.2 (R1), U6.37 (~RESET)
~BUSACK: J4.35, RN1.10 (R9)
~BUSRQ: J4.31, RN1.6 (R5), U12.4
~HALT: J4.36, RN1.9 (R8)
~IORQ: J4.40, RN3.6 (R5), U2.12 (O3a), U7.1 (G), U12.5
~M1: J4.27, RN1.7 (R6)
~MREQ: J4.38, RN3.7 (R6), U2.14 (O2a), U12.9
~RD: J4.39, RN3.9 (R8), U2.16 (O1a)
~RESET: J2.1, J4.29, U11.4 (~S), U11.10 (~S), U12.2
~RFSH: J4.25, RN1.8 (R7)
~WAIT: J4.33, RN1.5 (R4)
~WR: J4.37, RN3.8 (R7), U2.18 (O0a)

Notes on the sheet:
CLK/4
CLK/8
CLK/2
V1.2 10/2/2022
CLK
1&2 - stand alone 2&3 - secondary CPU

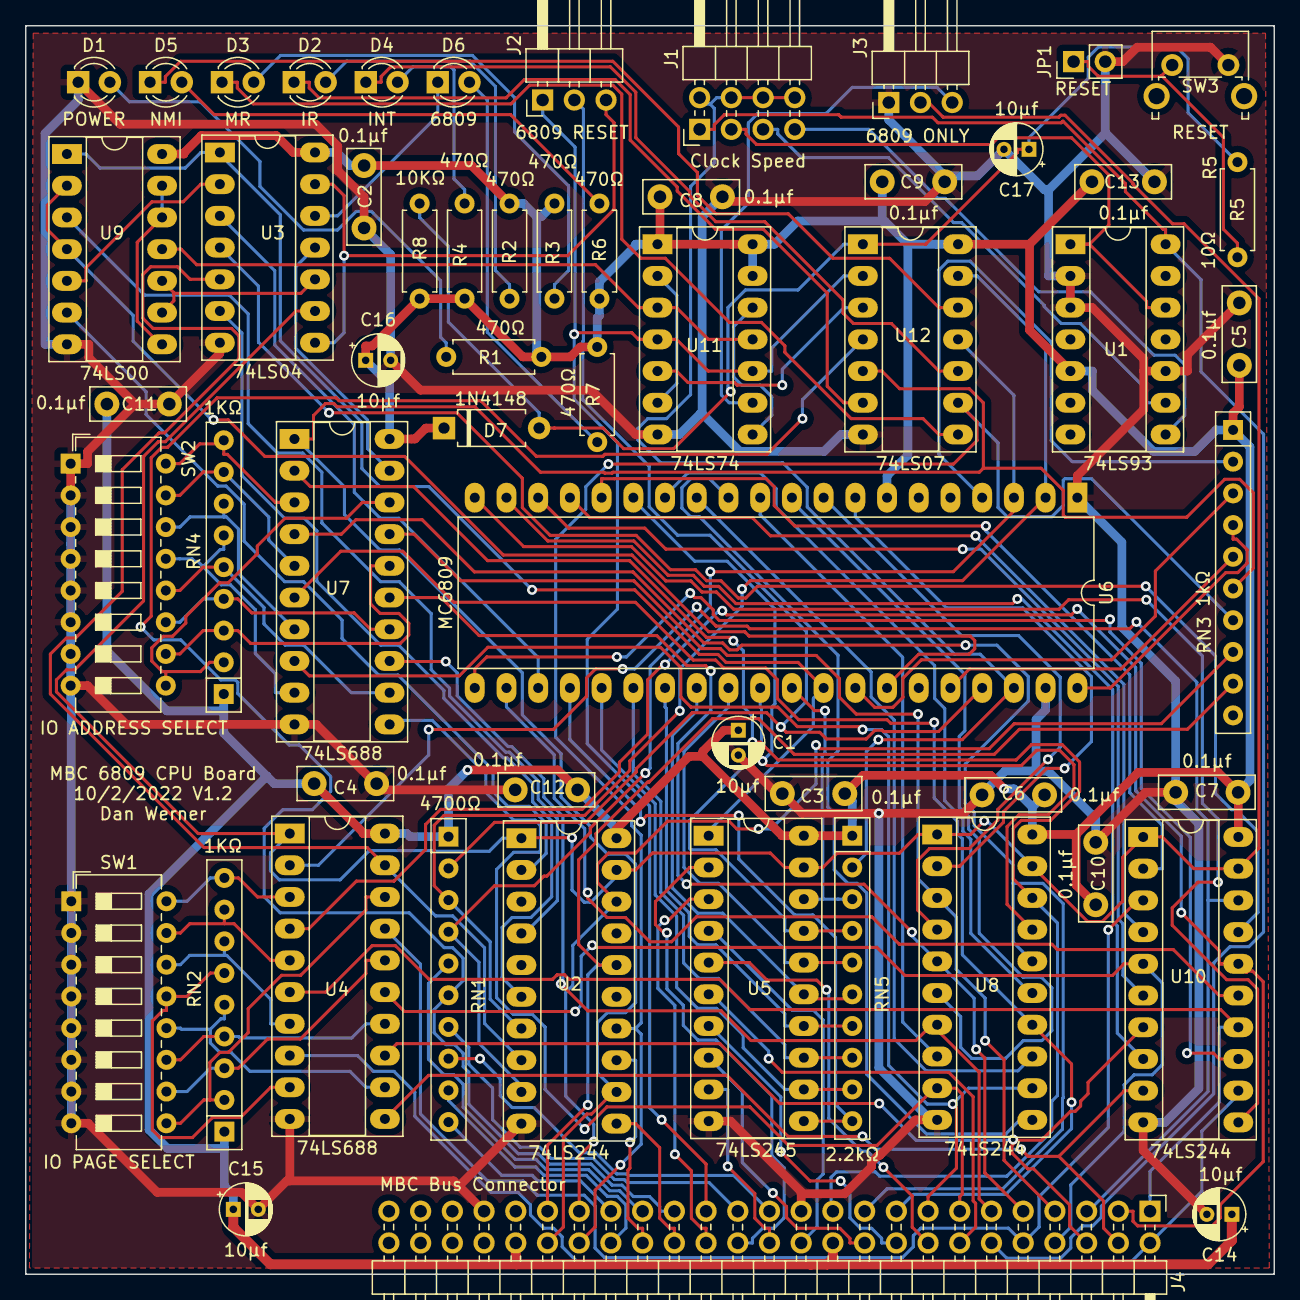
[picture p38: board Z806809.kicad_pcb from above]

Board: 2 copper layers, 100.0 x 100.0 mm, 57 parts (0 on the bottom side), 122 nets.

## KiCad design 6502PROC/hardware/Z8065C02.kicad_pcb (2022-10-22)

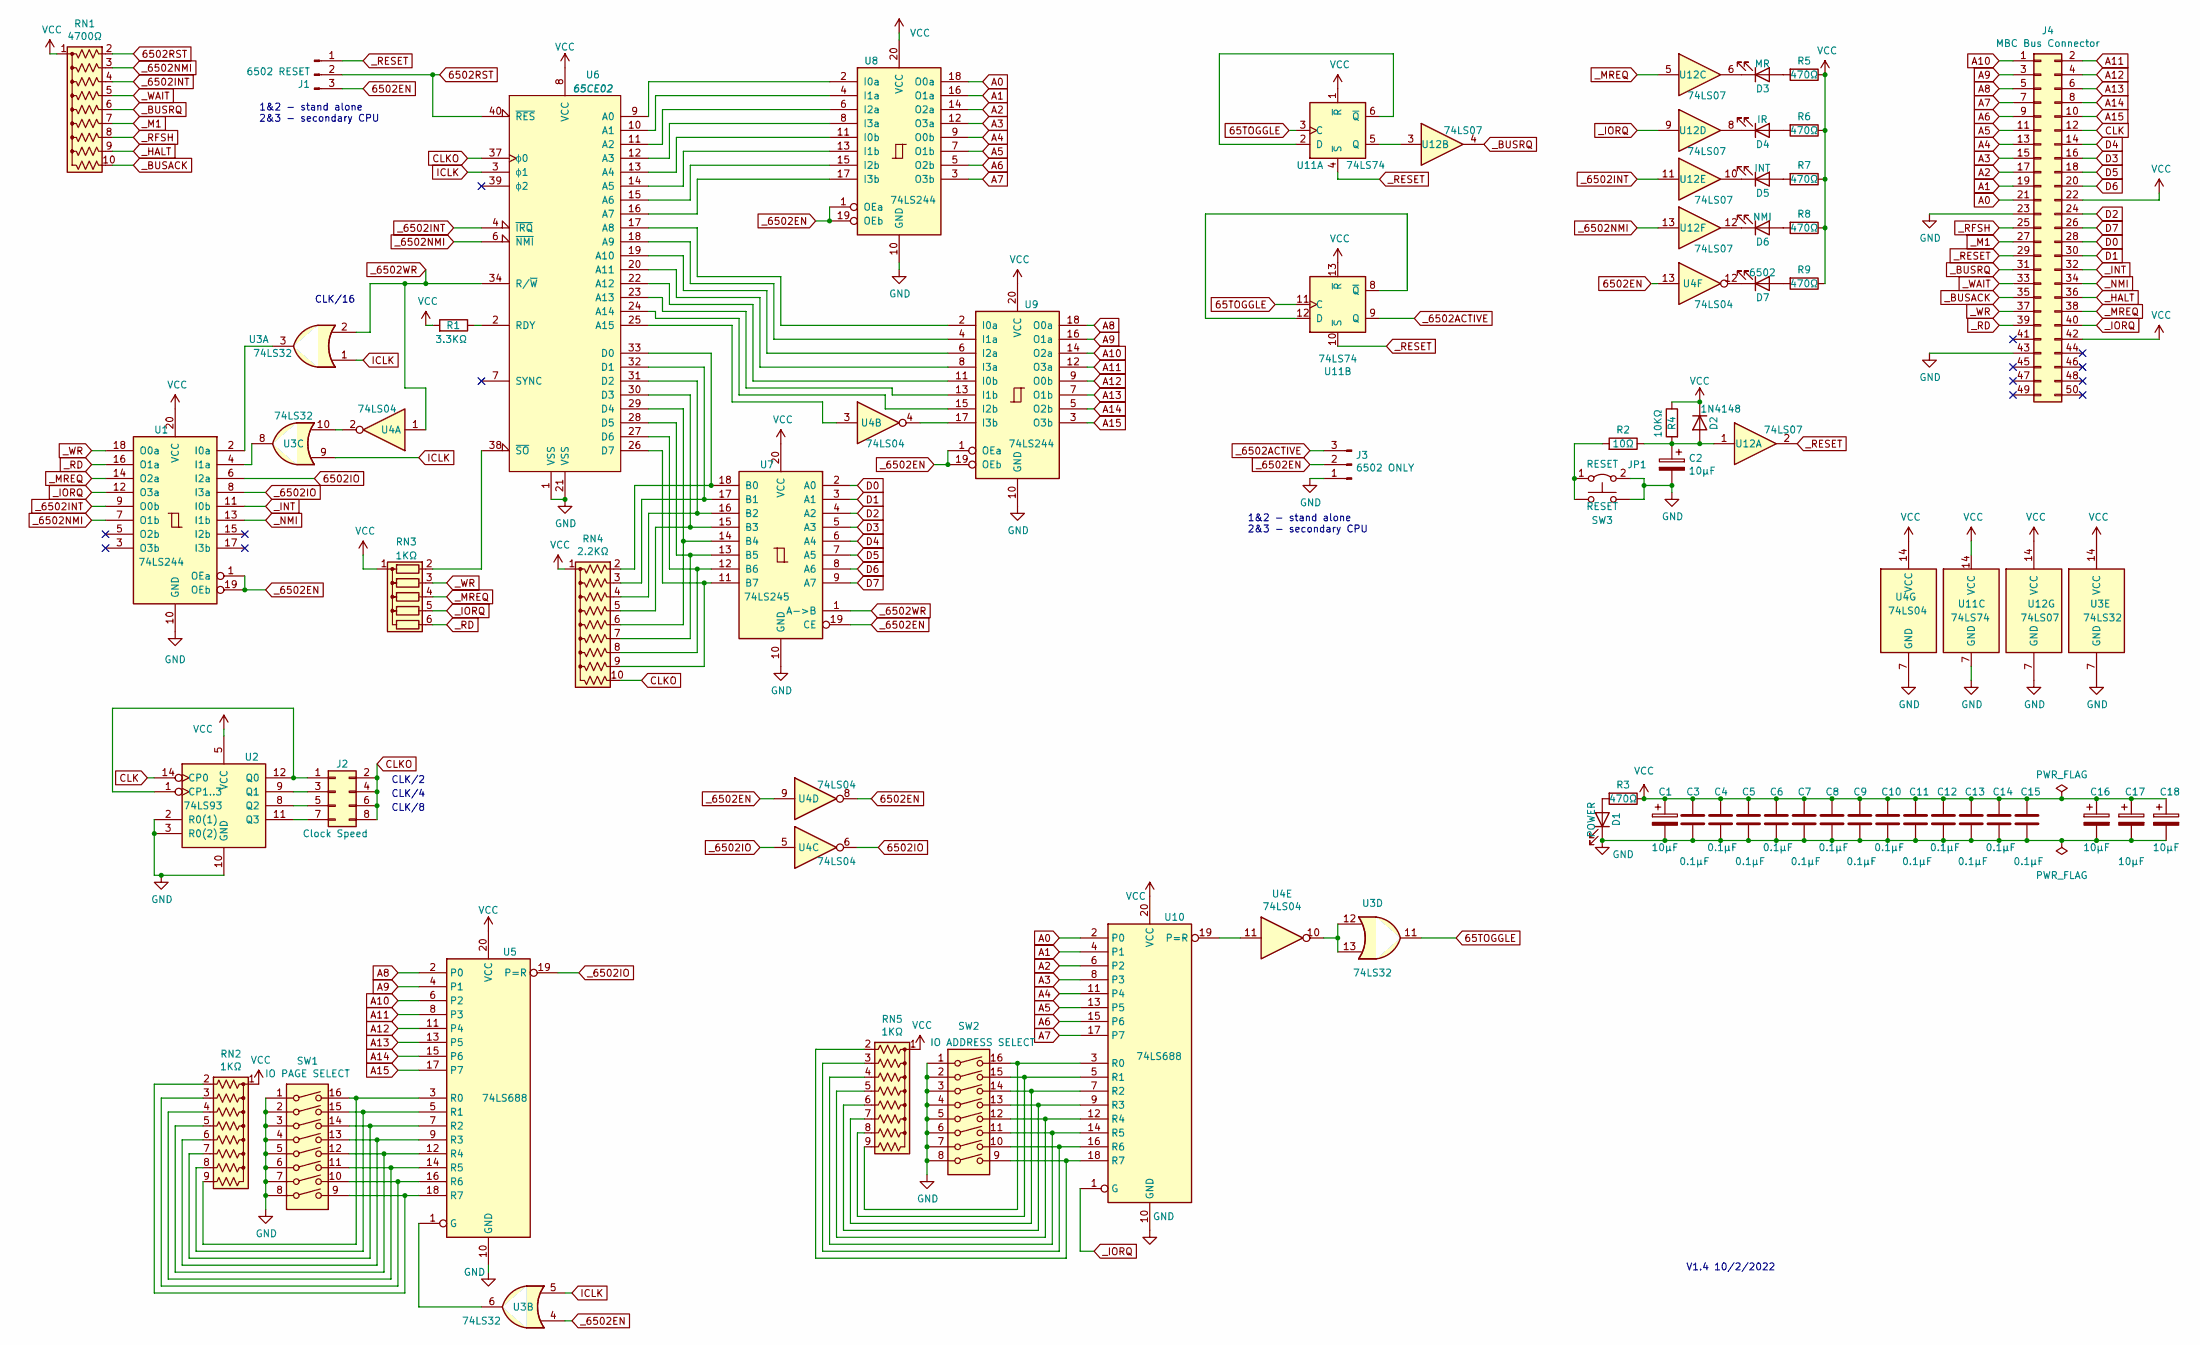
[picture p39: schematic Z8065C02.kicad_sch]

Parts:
C1, C2, C16, C17, C18: 10µF; CP_Radial_D4.0mm_P2.00mm
C3, C4, C5, C6, C7, C8, C9, C10, C11, C12, C13, C14, C15: 0.1µF; C_Disc_D7.5mm_W2.5mm_P5.00mm
D1: POWER; LED_D3.0mm
D2: 1N4148; D_A-405_P7.62mm_Horizontal
D3: MR; LED_D3.0mm
D4: IR; LED_D3.0mm
D5: INT; LED_D3.0mm
D6: NMI; LED_D3.0mm
D7: 6502; LED_D3.0mm
J1: 6502 RESET; PinHeader_1x03_P2.54mm_Horizontal
J2: Clock Speed; PinHeader_2x04_P2.54mm_Horizontal
J3: 6502 ONLY; PinHeader_1x03_P2.54mm_Horizontal
J4: MBC Bus Connector; PinHeader_2x25_P2.54mm_Horizontal
JP1: RESET; PinHeader_1x02_P2.54mm_Vertical
R1: 3.3KΩ; R_Axial_DIN0207_L6.3mm_D2.5mm_P7.62mm_Horizontal
R2: 10Ω; R_Axial_DIN0207_L6.3mm_D2.5mm_P7.62mm_Horizontal
R3, R5, R6, R7, R8, R9: 470Ω; R_Axial_DIN0207_L6.3mm_D2.5mm_P7.62mm_Horizontal
R4: 10KΩ; R_Axial_DIN0207_L6.3mm_D2.5mm_P7.62mm_Horizontal
RN1: 4700Ω; R_Array_SIP10
RN2, RN5: 1KΩ; R_Array_SIP9
RN3: 1KΩ; R_Array_SIP6
RN4: 2.2KΩ; R_Array_SIP10
SW1: IO PAGE SELECT; SW_DIP_SPSTx08_Slide_6.7x21.88mm_W7.62mm_P2.54mm_LowProfile
SW2: IO ADDRESS SELECT; SW_DIP_SPSTx08_Slide_6.7x21.88mm_W7.62mm_P2.54mm_LowProfile
SW3: RESET; SW_Tactile_SPST_Angled_PTS645Vx31-2LFS
U1, U8, U9: 74LS244; DIP-20_W7.62mm_Socket_LongPads
U2: 74LS93; DIP-14_W7.62mm_Socket_LongPads
U3: 74LS32; DIP-14_W7.62mm_Socket_LongPads
U4: 74LS04; DIP-14_W7.62mm_Socket_LongPads
U5, U10: 74LS688; DIP-20_W7.62mm_Socket_LongPads
U6: 65CE02; DIP-40_W15.24mm_Socket_LongPads
U7: 74LS245; DIP-20_W7.62mm_Socket_LongPads
U11: 74LS74; DIP-14_W7.62mm_Socket_LongPads
U12: 74LS07; DIP-14_W7.62mm_Socket_LongPads

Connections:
65TOGGLE: U3.11, U11.3 (C), U11.11 (C)
6502EN: J1.3, U4.8, U4.13
6502IO: U1.6 (I2a), U4.6
6502RST: J1.2, RN1.2 (R1), U6.40 (~RES)
A0: J4.21, U8.18 (O0a), U10.2 (P0)
A1: J4.19, U8.16 (O1a), U10.4 (P1)
A2: J4.17, U8.14 (O2a), U10.6 (P2)
A3: J4.15, U8.12 (O3a), U10.8 (P3)
A4: J4.13, U8.9 (O0b), U10.11 (P4)
A5: J4.11, U8.7 (O1b), U10.13 (P5)
A6: J4.9, U8.5 (O2b), U10.15 (P6)
A7: J4.7, U8.3 (O3b), U10.17 (P7)
A8: J4.5, U5.2 (P0), U9.18 (O0a)
A9: J4.3, U5.4 (P1), U9.16 (O1a)
A10: J4.1, U5.6 (P2), U9.14 (O2a)
A11: J4.2, U5.8 (P3), U9.12 (O3a)
A12: J4.4, U5.11 (P4), U9.9 (O0b)
A13: J4.6, U5.13 (P5), U9.7 (O1b)
A14: J4.8, U5.15 (P6), U9.5 (O2b)
A15: J4.10, U5.17 (P7), U9.3 (O3b)
CLK: J4.12, U2.14 (CP0)
CLKO: J2.2, J2.4, J2.6, J2.8, RN4.10 (R9), U6.37 (ϕ0)
D0: J4.28, U7.2 (A0)
D1: J4.30, U7.3 (A1)
D2: J4.24, U7.4 (A2)
D3: J4.16, U7.5 (A3)
D4: J4.14, U7.6 (A4)
D5: J4.18, U7.7 (A5)
D6: J4.20, U7.8 (A6)
D7: J4.26, U7.9 (A7)
GND: C1.2, C2.2, C3.2, C4.2, C5.2, C6.2, C7.2, C8.2, C9.2, C10.2, C11.2, C12.2, C13.2, C14.2, C15.2, C16.2, C17.2, C18.2, D1.1 (K), J3.1, J4.23, J4.43, JP1.2 (B), SW1.1, SW1.2, SW1.3, SW1.4, SW1.5, SW1.6, SW1.7, SW1.8, SW2.1, SW2.2, SW2.3, SW2.4, SW2.5, SW2.6, SW2.7, SW2.8, SW3.2, U1.10 (GND), U2.2 (R0(1)), U2.3 (R0(2)), U2.10 (GND), U3.7 (GND), U4.7 (GND), U5.10 (GND), U6.1 (VSS), U6.21 (VSS), U7.10 (GND), U8.10 (GND), U9.10 (GND), U10.10 (GND), U11.7 (GND), U12.7 (GND)
ICLK: U3.1, U3.5, U3.9, U6.3 (ϕ1)
unnamed: C2.1, D2.2 (A), R2.1, R4.2, U12.1
unnamed: D1.2 (A), R3.2
unnamed: D3.1 (K), U12.6
unnamed: D3.2 (A), R5.2
unnamed: D4.1 (K), U12.8
unnamed: D4.2 (A), R6.2
unnamed: D5.1 (K), U12.10
unnamed: D5.2 (A), R7.2
unnamed: D6.1 (K), U12.12
unnamed: D6.2 (A), R8.2
unnamed: D7.1 (K), U4.12
unnamed: D7.2 (A), R9.2
unnamed: J2.1, U2.1 (CP1..3), U2.12 (Q0)
unnamed: J2.3, U2.9 (Q1)
unnamed: J2.5, U2.8 (Q2)
unnamed: J2.7, U2.11 (Q3)
unnamed: JP1.1 (A), R2.2, SW3.1
unnamed: R1.1, U6.2 (RDY)
unnamed: RN2.2 (R1), SW1.9, U5.18 (R7)
unnamed: RN2.3 (R2), SW1.10, U5.16 (R6)
unnamed: RN2.4 (R3), SW1.11, U5.14 (R5)
unnamed: RN2.5 (R4), SW1.12, U5.12 (R4)
unnamed: RN2.6 (R5), SW1.13, U5.9 (R3)
unnamed: RN2.7 (R6), SW1.14, U5.7 (R2)
unnamed: RN2.8 (R7), SW1.15, U5.5 (R1)
unnamed: RN2.9 (R8), SW1.16, U5.3 (R0)
unnamed: RN3.2 (R1), U6.38 (~SO)
unnamed: RN4.2 (R1), U6.33 (D0), U7.18 (B0)
unnamed: RN4.3 (R2), U6.32 (D1), U7.17 (B1)
unnamed: RN4.4 (R3), U6.31 (D2), U7.16 (B2)
unnamed: RN4.5 (R4), U6.30 (D3), U7.15 (B3)
unnamed: RN4.6 (R5), U6.29 (D4), U7.14 (B4)
unnamed: RN4.7 (R6), U6.28 (D5), U7.13 (B5)
unnamed: RN4.8 (R7), U6.27 (D6), U7.12 (B6)
unnamed: RN4.9 (R8), U6.26 (D7), U7.11 (B7)
unnamed: RN5.2 (R1), SW2.9, U10.18 (R7)
unnamed: RN5.3 (R2), SW2.10, U10.16 (R6)
unnamed: RN5.4 (R3), SW2.11, U10.14 (R5)
unnamed: RN5.5 (R4), SW2.12, U10.12 (R4)
unnamed: RN5.6 (R5), SW2.13, U10.9 (R3)
unnamed: RN5.7 (R6), SW2.14, U10.7 (R2)
unnamed: RN5.8 (R7), SW2.15, U10.5 (R1)
unnamed: RN5.9 (R8), SW2.16, U10.3 (R0)
unnamed: U1.2 (I0a), U3.3
unnamed: U1.4 (I1a), U3.8
unnamed: U3.6, U5.1 (G)
unnamed: U3.10, U4.2
unnamed: U3.12, U3.13, U4.10
unnamed: U4.3, U6.25 (A15)
unnamed: U4.4, U9.17 (I3b)
unnamed: U6.9 (A0), U8.2 (I0a)
unnamed: U6.10 (A1), U8.4 (I1a)
unnamed: U6.11 (A2), U8.6 (I2a)
unnamed: U6.12 (A3), U8.8 (I3a)
unnamed: U6.13 (A4), U8.11 (I0b)
unnamed: U6.14 (A5), U8.13 (I1b)
unnamed: U6.15 (A6), U8.15 (I2b)
unnamed: U6.16 (A7), U8.17 (I3b)
unnamed: U6.17 (A8), U9.2 (I0a)
unnamed: U6.18 (A9), U9.4 (I1a)
unnamed: U6.19 (A10), U9.6 (I2a)
unnamed: U6.20 (A11), U9.8 (I3a)
unnamed: U6.22 (A12), U9.11 (I0b)
unnamed: U6.23 (A13), U9.13 (I1b)
unnamed: U6.24 (A14), U9.15 (I2b)
unnamed: U4.11, U10.19 (P=R)
unnamed: U11.2 (D), U11.6 (~Q)
unnamed: U11.5 (Q), U12.3
unnamed: U11.8 (~Q), U11.12 (D)
VCC: C1.1, C3.1, C4.1, C5.1, C6.1, C7.1, C8.1, C9.1, C10.1, C11.1, C12.1, C13.1, C14.1, C15.1, C16.1, C17.1, C18.1, D2.1 (K), J4.22, J4.42, R1.2, R3.1, R4.1, R5.1, R6.1, R7.1, R8.1, R9.1, RN1.1 (common), RN2.1 (common), RN3.1 (common), RN4.1 (common), RN5.1 (common), U1.20 (VCC), U2.5 (VCC), U3.14 (VCC), U4.14 (VCC), U5.20 (VCC), U6.8 (VCC), U7.20 (VCC), U8.20 (VCC), U9.20 (VCC), U10.20 (VCC), U11.1 (~R), U11.13 (~R), U11.14 (VCC), U12.14 (VCC)
_6502ACTIVE: J3.3, U11.9 (Q)
_6502EN: J3.2, U1.1 (OEa), U1.19 (OEb), U3.4, U4.9, U7.19 (CE), U8.1 (OEa), U8.19 (OEb), U9.1 (OEa), U9.19 (OEb)
_6502INT: RN1.4 (R3), U1.9 (O0b), U6.4 (~IRQ), U12.11
_6502IO: U1.8 (I3a), U4.5, U5.19 (P=R)
_6502NMI: RN1.3 (R2), U1.7 (O1b), U6.6 (~NMI), U12.13
_6502WR: U3.2, U4.1, U6.34 (R/~W), U7.1 (A->B)
_BUSACK: J4.35, RN1.10 (R9)
_BUSRQ: J4.31, RN1.6 (R5), U12.4
_HALT: J4.36, RN1.9 (R8)
_INT: J4.32, U1.11 (I0b)
_IORQ: J4.40, RN3.5 (R4), U1.12 (O3a), U10.1 (G), U12.9
_M1: J4.27, RN1.7 (R6)
_MREQ: J4.38, RN3.4 (R3), U1.14 (O2a), U12.5
_NMI: J4.34, U1.13 (I1b)
_RD: J4.39, RN3.6 (R5), U1.16 (O1a)
_RESET: J1.1, J4.29, U11.4 (~S), U11.10 (~S), U12.2
_RFSH: J4.25, RN1.8 (R7)
_WAIT: J4.33, RN1.5 (R4)
_WR: J4.37, RN3.3 (R2), U1.18 (O0a)

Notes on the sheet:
CLK/4
1&2 - stand alone 2&3 - secondary CPU
CLK/2
CLK/8
V1.4 10/2/2022
CLK/16


Board: 2 copper layers, 100.0 x 100.0 mm, 59 parts (0 on the bottom side), 121 nets.

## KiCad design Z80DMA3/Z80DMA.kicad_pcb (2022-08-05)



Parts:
C1, C2, C3, C4, C5, C6, C7, C8, C9, C10, C11, C12, C13, C14, C15, C16: 0.1u; C_Disc_D7.0mm_W2.5mm_P5.00mm
C17: 47uF; CP_Radial_D5.0mm_P2.50mm
D1, D2, D3, D4, D5: LED; LED_D3.0mm
H1, H2: BRACKET; MountingHole_2.2mm_M2_Pad
K1: EXT DMA; PinHeader_1x03_P2.54mm_Horizontal
K2: INT SEL; PinHeader_1x03_P2.54mm_Vertical
LINK1: LINK; R_Axial_DIN0207_L6.3mm_D2.5mm_P10.16mm_Horizontal
P1: Z80 BUS BACKPLANE; Pin_Header_Angled_2x25_Pitch2.54mm
P2: SPARES; Pin_Header_Straight_1x10_Pitch2.54mm
P3: DAISY CHAIN; PinHeader_1x05_P2.54mm_Vertical
R1: 1K; R_Axial_DIN0207_L6.3mm_D2.5mm_P10.16mm_Horizontal
R2, R5, R6, R13: 4K7; R_Axial_DIN0207_L6.3mm_D2.5mm_P10.16mm_Horizontal
R4, R7, R12, R14, R15: 470R; R_Axial_DIN0207_L6.3mm_D2.5mm_P10.16mm_Horizontal
R8, R9, R10, R11: 1K8; R_Axial_DIN0207_L6.3mm_D2.5mm_P10.16mm_Horizontal
RN1: 4K7; R_Array_SIP9
SW1: IO PORT ADDR; SW_DIP_SPSTx08_Slide_9.78x22.5mm_W7.62mm_P2.54mm
U1: 74LS08; DIP-14_W7.62mm
U2, U7, U8: 74LS244; DIP-20_W7.62mm
U3: 74LS688; DIP-20_W7.62mm
U4: 74LS32; DIP-14_W7.62mm
U5: 74LS04; DIP-14_W7.62mm
U6: 74LS27; DIP-14_W7.62mm
U9: 74LS241; DIP-20_W7.62mm
U10: 74LS245; DIP-20_W7.62mm
U11: DMA-PLCC-44-CMOS; PLCC-44_THT-Socket; Manufacturer_Part_Number Z84C4206PEG; Mouser Part Number 692-Z84C4206PEG
U12: SN74LS07N; DIP-14_W7.62mm
U13: 74LS175; DIP-16_W7.62mm
U14: 74LS139; DIP-16_W7.62mm
U15: 74LS157; DIP-16_W7.62mm
U16: ATtiny13-20PU; DIP-8_W7.62mm

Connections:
/B_A0: P1.21, U7.18 (O0a), U14.2 (A0)
/B_A1: P1.19, U3.4 (P1), U7.16 (O1a)
/B_A2: P1.17, U3.6 (P2), U7.14 (O2a)
/B_A3: P1.15, U3.8 (P3), U7.12 (O3a)
/B_A4: P1.13, U3.11 (P4), U7.9 (O0b)
/B_A5: P1.11, U3.13 (P5), U7.7 (O1b)
/B_A6: P1.9, U3.15 (P6), U7.5 (O2b)
/B_A7: P1.7, U3.17 (P7), U7.3 (O3b)
/B_A8: P1.5, U8.18 (O0a)
/B_A9: P1.3, U8.16 (O1a)
/B_A10: P1.1, U8.14 (O2a)
/B_A11: P1.2, U8.12 (O3a)
/B_A12: P1.4, U8.9 (O0b)
/B_A13: P1.6, U8.7 (O1b)
/B_A14: P1.8, U8.5 (O2b)
/B_A15: P1.10, U8.3 (O3b)
/B_D0: P1.28, U10.9 (A7), U13.4 (D0)
/B_D1: P1.30, U10.8 (A6), U13.5 (D1)
/B_D2: P1.24, U10.7 (A5), U13.12 (D2)
/B_D3: P1.16, U10.6 (A4), U13.13 (D3)
/B_D4: P1.14, U10.5 (A3)
/B_D5: P1.18, U10.4 (A2)
/B_D6: P1.20, U10.3 (A1)
/B_D7: P1.26, U10.2 (A0)
/B_IEI: P3.4, R2.2, U2.13 (I1b)
/B_IEO: P3.5, U1.6
/B_PHI: P1.12, U2.8 (I3a)
/D0: U10.11 (B7), U11.39 (D0)
/D1: U10.12 (B6), U11.38 (D1)
/D2: U10.13 (B5), U11.37 (D2)
/D3: U10.14 (B4), U11.36 (D3)
/D4: U10.15 (B3), U11.35 (D4)
/D5: U10.16 (B2), U11.33 (D5)
/D6: U10.17 (B1), U11.32 (D6)
/D7: U10.18 (B0), U11.31 (D7)
/G-PLCC: LINK1.1, U11.34 (GND)
/IEI: U1.5, U2.7 (O1b), U5.5, U11.42 (IEI)
/IEO: U1.4, U6.2, U11.40 (IEO)
/PHI: R1.2, U2.12 (O3a), U11.8 (CLK)
/RDY: U5.10, U11.27 (RDY)
/RDY_IN: K1.3, U6.5
/SPARE0: P1.42, P2.1
/SPARE1: P1.44, P2.2
/SPARE2: P1.46, P2.3
/SPARE3: P1.48, P2.4
/SPARE4: P1.50, P2.5
/SPARE5: P1.49, P2.6
/SPARE6: P1.47, P2.7
/SPARE7: P1.45, P2.8
/SPARE8: P1.43, P2.9
/SPARE9: P1.41, P2.10
/~BAI: U2.14 (O2a), U6.9, U11.16 (~BAI), U15.1 (S)
/~BAO: U5.3, U11.15 (~BA0), U12.3
/~B_BAI: P3.2, U2.6 (I2a)
/~B_BAO: P3.3, U12.4
/~B_BUSAK: P1.35, P3.1
/~B_BUSRQ: P1.31, U6.10, U11.17 (~BUSREQ)
/~B_INT: K2.1, P1.32
/~B_IORQ: P1.40, U3.1 (G), U9.11 (I0b), U9.18 (O0a)
/~B_M1: P1.27, U2.2 (I0a), U3.2 (P0)
/~B_MREQ: P1.38, U9.13 (I1b), U9.16 (O1a)
/~B_NMI: K2.3, P1.34
/~B_RD: P1.39, U9.14 (O2a), U9.15 (I2b)
/~B_RESET: P1.29, U2.17 (I3b)
/~B_WAIT: P1.33, U2.11 (I0b)
/~B_WR: P1.37, U2.15 (I2b), U9.12 (O3a), U9.17 (I3b)
/~CE_DMA_BRD: U3.19 (P=R), U14.1 (E)
/~CE_DMA_IC: U4.1, U11.18 (~CE/~WAIT), U12.13, U15.4 (Za)
/~CE_DMA_RDY: U4.13, U14.5 (O1)
/~DMA_HAS_BUS: U4.5, U5.12, U7.1 (OEa), U7.19 (OEb), U8.1 (OEa), U8.19 (OEb), U9.1 (OEa), U9.19 (OEb), U12.11
/~IORQ: R11.2, U4.9, U9.2 (I0a), U9.9 (O0b), U11.11 (~IORQ)
/~M1: U2.18 (O0a), U4.10, U11.30 (~M1)
/~MREQ: R9.2, U9.4 (I1a), U9.7 (O1b), U11.14 (~MREQ)
/~PULSE: R5.2, U11.41 (~INT/PULSE), U12.1, U12.5, U16.6 (PB1)
/~PULSE_OUT: K1.1, R13.2, U12.2
/~RD: R8.2, U4.2, U5.1, U9.5 (O2b), U9.6 (I2a), U11.10 (~RD)
/~RDY: U5.11, U6.6, U12.9
/~RST: R6.1, U1.2, U2.3 (O3b), U13.1 (~Mr), U16.1 (~RESET~/PB5)
/~USR_RST: U1.1, U13.6 (~Q1)
/~WAIT: U2.9 (O0b), U15.2 (I0a)
/~WR: R10.2, U9.3 (O3b), U9.8 (I3a), U11.9 (~WR)
/~WR~b: U2.5 (O2b), U4.12
GND: C1.2, C2.2, C3.2, C4.2, C5.2, C6.2, C7.2, C8.2, C9.2, C10.2, C11.2, C12.2, C13.2, C14.2, C15.2, C16.2, C17.2, D1.1 (K), D2.1 (K), H1.1, H2.1, K1.2, LINK1.2, P1.23, SW1.1, SW1.2, SW1.3, SW1.4, SW1.5, SW1.6, SW1.7, U1.7 (GND), U2.1 (OEa), U2.10 (GND), U2.19 (OEb), U3.10 (GND), U4.7 (GND), U5.7 (GND), U6.4, U6.7 (GND), U7.10 (GND), U8.10 (GND), U9.10 (GND), U10.10 (GND), U10.19 (CE), U12.7 (GND), U13.8 (GND), U14.3 (A1), U14.8 (GND), U15.8 (GND), U15.15 (E), U16.4 (GND)
unnamed: D1.2 (A), R7.1
unnamed: D2.2 (A), R12.2
unnamed: D3.1 (K), U12.12
unnamed: D3.2 (A), R14.2
unnamed: D4.1 (K), U12.8
unnamed: D4.2 (A), R15.2
unnamed: D5.1 (K), U12.10
unnamed: D5.2 (A), R4.2
unnamed: K2.2 (PM), U12.6
unnamed: R7.2, U16.7 (PB2)
unnamed: RN1.2 (R1), SW1.16, U3.18 (R7)
unnamed: RN1.3 (R2), SW1.15, U3.16 (R6)
unnamed: RN1.4 (R3), SW1.14, U3.14 (R5)
unnamed: RN1.5 (R4), SW1.13, U3.12 (R4)
unnamed: RN1.6 (R5), SW1.12, U3.9 (R3)
unnamed: RN1.7 (R6), SW1.11, U3.7 (R2)
unnamed: RN1.8 (R7), SW1.10, U3.5 (R1)
unnamed: RN1.9 (R8), U3.3 (R0)
unnamed: U1.3, U11.12 (~RESET)
unnamed: U1.9, U4.6
unnamed: U1.10, U4.3
unnamed: U1.11, U10.1 (A->B)
unnamed: U1.8, U1.12
unnamed: U1.13, U5.8
unnamed: U4.4, U5.2
unnamed: U4.8, U6.1
unnamed: U5.4, U6.11
unnamed: U5.6, U6.13
unnamed: U5.9, U6.12
unnamed: U5.13, U6.8
unnamed: U7.13 (I1b), U11.1 (A5)
unnamed: U7.11 (I0b), U11.2 (A4)
unnamed: U7.8 (I3a), U11.3 (A3)
unnamed: U7.6 (I2a), U11.4 (A2)
unnamed: U7.4 (I1a), U11.5 (A1)
unnamed: U7.2 (I0a), U11.7 (A0)
unnamed: U8.17 (I3b), U11.19 (A15)
unnamed: U8.15 (I2b), U11.20 (A14)
unnamed: U8.13 (I1b), U11.21 (A13)
unnamed: U8.11 (I0b), U11.22 (A12)
unnamed: U8.8 (I3a), U11.23 (A11)
unnamed: U8.6 (I2a), U11.24 (A10)
unnamed: U8.4 (I1a), U11.25 (A9)
unnamed: U8.2 (I0a), U11.26 (A8)
unnamed: U7.17 (I3b), U11.43 (A7)
unnamed: U7.15 (I2b), U11.44 (A6)
unnamed: U6.3, U13.2 (Q0)
unnamed: U4.11, U13.9 (Cp)
unnamed: U14.4 (O0), U15.3 (I1a)
VCC: C1.1, C2.1, C3.1, C4.1, C5.1, C6.1, C7.1, C8.1, C9.1, C10.1, C11.1, C12.1, C13.1, C14.1, C15.1, C16.1, C17.1, P1.22, R1.1, R2.1, R4.1, R5.1, R6.2, R8.1, R9.1, R10.1, R11.1, R12.1, R13.1, R14.1, R15.1, RN1.1 (common), U1.14 (VCC), U2.20 (VCC), U3.20 (VCC), U4.14 (VCC), U5.14 (VCC), U6.14 (VCC), U7.20 (VCC), U8.20 (VCC), U9.20 (VCC), U10.20 (VCC), U11.13 (VCC), U12.14 (VCC), U13.16 (VCC), U14.16 (VCC), U15.16 (VCC), U16.8 (VCC)

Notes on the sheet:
Note: Bus connector is mirror image of Z80 CPU pin out to mate to backplane whose connectors reflect Z80 CPU pin out.
CE / WAIT FUNCTION SELECT LOGIC WHEN DMA IS BUS MASTER CE/WAIT IS WAIT FUNCTION OTHERWISE CE/WAIT IS CHIP ENABLE WHEN WAIT FUNCTION IS SELECTED, BUS WAIT PIN IS CONNECTED TO CE/WAIT PIN
ADDRESS DIRECTION IS CONTROLLED BY STATUS OF BAI AND BAO. WHEN BAI IS ACTIVE (LOW) AND BAO IS INACTIVE (HIGH) THEN THE DMA BOARD IS THE BUS MASTER. SO IN THIS CASE DIRECTION OUT TO ECB BUS.
DATA DIRECTION CONTROL LOGIC
PORT DECODING
TRANSITION LOW WHEN BASE PORT IS ACCESSED
TRANSITION LOW WHEN SECOND PORT IS ACCESSED
OUTPUT P4 AND P5 ARE HIGH WHEN NOT ACCESSING DMA BOARD
U1D, Pin 11 = H A->B from bus U1D, Pin 11 = L B->A to bus
NOTE: ~B_INT~ AND ~B_NMI~ RELY ON PULL UP RESISTORS ON PROCESOR BOARD
P3 pins 1, 2 & 3 configures whether the board is a primary DMA or secondary DMA in the DMA priority chain. If the board is the only DMA board: Jumper 1-2 If the board is the primary DMA and there are other DMA boards: Jumper 1-2 and wire link BAO pin 3 to the next boards BAI in pin. If the board is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
DMA Transfer LED triggered whenever a DMA transfer is in progress and the pulse signal is active. DMA software needs to program the activation of the pulse signal.
Note: DMA IO Address Ports $E0-$E1 S1=off - A7 (high) S2=off - A6 (high) S3=off - A5 (high) S4=on - A4 (low) S5=on - A3 (low) S6=on - A2 (low) S7=on - A1 (low) S8=xx - A0 (xx)
SPARE GATES


Board: 2 copper layers, 100.0 x 100.0 mm, 62 parts (0 on the bottom side), 133 nets.

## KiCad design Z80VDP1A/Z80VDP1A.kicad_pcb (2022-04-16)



Board: 2 copper layers, 100.0 x 100.0 mm, 93 parts (2 on the bottom side), 154 nets.

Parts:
C1, C2, C3, C4, C5, C6, C7, C8, C9, C19, C24, C27, C33, C39, C40: 0.1u; C_Disc_D5.0mm_W2.5mm_P5.00mm
C10, C11: 10u; CP_Radial_D5.0mm_P2.50mm
C12, C13, C14, C15: 0.22u; C_Disc_D5.0mm_W2.5mm_P5.00mm
C22, C23: 33p; C_Disc_D5.0mm_W2.5mm_P5.00mm
C25: 22u; CP_Radial_D5.0mm_P2.50mm
C26: 220u; CP_Radial_D6.3mm_P2.50mm
D1, D2, D3, D4: LED; LED_D3.0mm
H1, H2: BRACKET; MountingHole_2.2mm_M2_Pad
J1: VY/VCC; PinHeader_1x03_P2.54mm_Vertical
J2: INT#/NMI#; PinHeader_1x03_P2.54mm_Horizontal
J3: CSYNC; PinHeader_1x03_P2.54mm_Vertical
JP1: BUSCLK; PinHeader_1x02_P2.54mm_Vertical
JP2: OPTGND; PinHeader_1x02_P2.54mm_Vertical
JP3: OPTWAIT; PinHeader_1x02_P2.54mm_Vertical
JP4: CSYNCOPT; PinHeader_1x02_P2.54mm_Vertical
L1: INDUCTOR (BEAD); LairdTech_28C0236-0JW-10
P1: RGB TTL; PinHeader_2x05_P2.54mm_Horizontal
P2: SPARES; PinHeader_2x05_P2.54mm_Vertical
P3: Z80 BUS BACKPLANE; PinHeader_2x25_P2.54mm_Horizontal
P4: RAMDAC; PinHeader_2x08_P2.54mm_Vertical
Q1, Q2, Q3, Q4, Q5: 2N3904; TO-92_HandSolder
R1, R2, R3, R5, R10, R11, R19, R22, R29: 470; R_Axial_DIN0207_L6.3mm_D2.5mm_P7.62mm_Horizontal
R4, R8, R9, R12, R20, R23: 1000; R_Axial_DIN0207_L6.3mm_D2.5mm_P7.62mm_Horizontal
R6, R16: 0; R_Axial_DIN0207_L6.3mm_D2.5mm_P7.62mm_Horizontal
R7, R15, R17, R24: 4700; R_Axial_DIN0207_L6.3mm_D2.5mm_P7.62mm_Horizontal
R13: 680K; R_Axial_DIN0207_L6.3mm_D2.5mm_P7.62mm_Horizontal
R14, R18, R21, R25, R30: 75; R_Axial_DIN0207_L6.3mm_D2.5mm_P7.62mm_Horizontal
RR1: 10K; R_Array_SIP9
SW1: IO PORT ADDR; SW_DIP_SPSTx08_Slide_9.78x22.5mm_W7.62mm_P2.54mm
U1, U3: 74LS244; DIP-20_W7.62mm
U2: 74LS245; DIP-20_W7.62mm
U4: 74LS688; DIP-20_W7.62mm
U5: FMS6141; SOIC-8_3.9x4.9mm_P1.27mm
U6: 74LS02; DIP-14_W7.62mm
U7: 74LS32; DIP-14_W7.62mm
U8: 74LS06; DIP-14_W7.62mm
U10: 74LS174; DIP-16_W7.62mm
U12: V9938-V9958; renesas21-DIP64-S
U13, U14, U15, U16: D41464C; DIP-18_W7.62mm
U23: LM1881; DIP-8_W7.62mm
X1: 21.47727 MHz; Crystal_HC49-4H_Vertical

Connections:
/688SEL#: U3.9, U4.1
/A0: P3.21, U1.2
/A1: P3.19, U1.4
/A2: P3.17, U1.6
/A3: P3.15, U1.8
/A4: P3.13, U1.11
/A5: P3.11, U1.13
/A6: P3.9, U1.15
/A7: P3.7, U1.17
/ACRCS#: U6.2, U7.11
/ACRWR#: U6.1, U10.9
/AD0: U12.49, U13.14, U14.14, U15.14, U16.14
/AD1: U12.50, U13.13, U14.13, U15.13, U16.13
/AD2: U12.51, U13.12, U14.12, U15.12, U16.12
/AD3: U12.52, U13.11, U14.11, U15.11, U16.11
/AD4: U12.53, U13.8, U14.8, U15.8, U16.8
/AD5: U12.54, U13.7, U14.7, U15.7, U16.7
/AD6: U12.55, U13.6, U14.6, U15.6, U16.6
/AD7: U12.56, U13.10, U14.10, U15.10, U16.10
/BLUE: Q2.2, R11.1, U12.24
/BLUE-OUT: P1.9, R21.2
/C0: P4.5, U12.19
/C1: P4.6, U12.18
/C2: P4.7, U12.17
/C3: P4.8, U12.16
/C4: P4.9, U12.15
/C5: P4.10, U12.14
/C6: P4.11, U12.13
/C7: P4.12, U12.12
/CAS0#: U12.61, U13.16, U14.16
/CAS1#: U12.60, U15.16, U16.16
/CBDR: P4.14, U12.11
/CLK: JP1.2, P3.12
/COMVID: C26.2, P1.4
/CSYNC#: J3.1, R8.1
/CSYNC-OUT: JP4.2, P1.10, U6.4
/CS_VDP#: U2.19, U3.4, U4.19, U7.10, U7.12
/D0: P3.28, U2.2
/D1: P3.30, U2.3
/D2: P3.24, U2.4
/D3: P3.16, U2.5
/D4: P3.14, U2.6
/D5: P3.18, U2.7
/D6: P3.20, U2.8
/D7: P3.26, U2.9
/DHCLK#: P4.3, U12.2
/DLCLK#: P4.4, R24.1, U12.3
/GREEN: Q3.2, R3.1, U12.22
/GREEN-OUT: P1.7, R18.2
/HSYNC#: P1.6, Q1.1, R9.1, U12.5
/INT#: J2.1, P3.32
/IORQ#: P3.40, U3.11
/LPS-WAIT#: R7.1, U6.11, U6.12, U12.26
/M1#: P3.27, U3.13
/NMI#: J2.3, P3.34
/ONE: R6.1, U12.27
/RAS#: U12.62, U13.5, U14.5, U15.5, U16.5
/RD#: P3.39, U2.1, U3.17
/RED: Q4.2, R19.1, U12.23
/RED-OUT: P1.5, R14.2
/RESET#: P3.29, U3.2
/RESVDP#: R17.1, U8.10, U12.9
/SPARE0: P2.1, P3.42
/SPARE1: P2.2, P3.44
/SPARE2: P2.3, P3.46
/SPARE3: P2.4, P3.48
/SPARE4: P2.5, P3.50
/SPARE5: P2.6, P3.49
/SPARE6: P2.7, P3.47
/SPARE7: P2.8, P3.45
/SPARE8: P2.9, P3.43
/SPARE9: P2.10, P3.41
/STATUS#: U8.3, U10.10
/VD0: U12.41, U13.2, U15.2
/VD1: U12.42, U13.3, U15.3
/VD2: U12.43, U13.15, U15.15
/VD3: U12.44, U13.17, U15.17
/VD4: U12.45, U14.2, U16.2
/VD5: U12.46, U14.3, U16.3
/VD6: U12.47, U14.15, U16.15
/VD7: U12.48, U14.17, U16.17
/VDP-RD#: U7.6, U12.31
/VDP-WR#: U7.3, U12.30
/VFILT: C25.1, C27.1, L1.2, U5.7
/VIDCS#: U7.2, U7.4, U7.8
/VINT#: R15.1, U8.5, U8.9, U12.25
/VRW#: U12.57, U13.4, U14.4, U15.4, U16.4
/VRY: U3.8, U12.8
/VSYNC: Q5.2, R22.1, U23.3
/VSYNC#: P1.8, R25.2
/VY: C24.2, C39.1, J1.1, R29.1
/WAIT#: JP3.2, P3.33
/WR#: P3.37, U3.15
/ZERO: R16.1, U1.1, U1.19, U3.1, U3.19, U13.1, U14.1, U15.1, U16.1
/bA0: U1.18, U12.29
/bA1: U1.16, U12.28
/bA2: U1.14, U6.8, U6.9, U7.9
/bA2#: U6.10, U7.13
/bA3: U1.12, U4.8
/bA4: U1.9, U4.11
/bA5: U1.7, U4.13
/bA6: U1.5, U4.15
/bA7: U1.3, U4.17
/bD0: U2.18, U10.3, U12.40
/bD1: U2.17, U10.4, U12.39
/bD2: U2.16, U10.6, U12.38
/bD3: U2.15, U10.11, U12.37
/bD4: U2.14, U10.13, U12.36
/bD5: U2.13, U10.14, U12.35
/bD6: U2.12, U12.34
/bD7: U2.11, U12.32
/bM1#: U3.7, U4.2, U4.4, U4.6
/bRD#: U3.3, U7.5
/bRESET#: U3.18, U10.1
/bWR#: U3.5, U6.3, U7.1
GND: C1.2, C2.2, C3.2, C4.2, C5.2, C6.2, C7.2, C8.2, C9.2, C10.2, C11.2, C12.2, C13.2, C14.2, C15.2, C19.2, C22.2, C23.2, C25.2, C27.2, C33.2, C40.2, D2.1, H1.1, H2.1, JP2.2, P1.1, P1.3, P3.23, P4.1, P4.16, R13.2, R16.2, R29.2, R30.2, SW1.1, SW1.2, SW1.3, SW1.4, SW1.5, U1.10, U2.10, U3.10, U4.10, U5.3, U6.7, U7.7, U8.7, U10.8, U12.1, U12.20, U13.18, U14.18, U15.18, U16.18, U23.4
unnamed: C22.1, U12.63, X1.1
unnamed: C23.1, U12.64, X1.2
unnamed: C24.1, U5.1
unnamed: C26.1, R30.1, U5.8
unnamed: C33.1, U12.33
unnamed: C39.2, U23.2
unnamed: C40.1, R13.1, U23.6
unnamed: D1.1, U3.16
unnamed: D1.2, R1.1
unnamed: D2.2, R2.1
unnamed: D3.1, U8.4
unnamed: D3.2, R10.1
unnamed: D4.1, U8.8
unnamed: D4.2, R5.1
unnamed: J1.2, U12.21
unnamed: J2.2, U8.6
unnamed: J3.2, U12.6
unnamed: J3.3, U6.5, U6.6
unnamed: JP1.1, U3.12
unnamed: JP2.1, R3.2, R4.2, R9.2, R11.2, R12.2, R19.2, R20.2, R22.2, R23.2
unnamed: JP3.1, U8.2
unnamed: JP4.1, U23.1
unnamed: Q1.2, R8.2
unnamed: Q2.1, R12.1, R14.1
unnamed: Q3.1, R4.1, R18.1
unnamed: Q4.1, R20.1, R21.1
unnamed: Q5.1, R23.1, R25.1
unnamed: RR1.2, U4.3
unnamed: RR1.3, U4.5
unnamed: RR1.4, U4.7
unnamed: RR1.5, SW1.12, U4.9
unnamed: RR1.6, SW1.13, U4.12
unnamed: RR1.7, SW1.14, U4.14
unnamed: RR1.8, SW1.15, U4.16
unnamed: RR1.9, SW1.16, U4.18
unnamed: U6.13, U8.1
unnamed: U8.11, U10.2
VCC: C1.1, C2.1, C3.1, C4.1, C5.1, C6.1, C7.1, C8.1, C9.1, C10.1, C11.1, C12.1, C13.1, C14.1, C15.1, C19.1, J1.3, L1.1, P1.2, P3.22, P4.2, P4.15, Q1.3, Q2.3, Q3.3, Q4.3, Q5.3, R1.2, R2.2, R5.2, R6.2, R7.2, R10.2, R15.2, R17.2, R24.2, RR1.1, U1.20, U2.20, U3.20, U4.20, U6.14, U7.14, U8.14, U10.16, U12.58, U13.9, U14.9, U15.9, U16.9, U23.8

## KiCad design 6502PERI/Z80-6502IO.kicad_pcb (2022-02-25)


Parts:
C1, C2, C3, C4, C5, C6, C7, C8, C19, C20, C21: 0.1u; C_Disc_D5.0mm_W2.5mm_P5.00mm
C9, C10, C11: 10u; CP_Radial_D5.0mm_P2.50mm
C12, C13: 0.22uF; C_Disc_D5.0mm_W2.5mm_P5.00mm
C14, C17, C18: 4.7uF; CP_Radial_D5.0mm_P2.50mm
C15, C16: 2200pF; C_Disc_D5.0mm_W2.5mm_P5.00mm
D1, D2: LED; LED_D3.0mm
H1, H2: MountingHole_Pad; MountingHole_2.2mm_M2_Pad
J1: RCJ-014; CUI_RCJ-014
K1, K2: INT SRC; PinHeader_1x03_P2.54mm_Vertical
K3: HANDS; PinHeader_1x03_P2.54mm_Vertical
P1: CONN_1; PinHeader_1x01_P2.54mm_Vertical
P2: Z80 BUS INTERFACE; PinHeader_2x25_P2.54mm_Horizontal
P3: SERIAL; PinHeader_1x06_P2.54mm_Vertical
P4: USB_PWR; PinHeader_1x02_P2.54mm_Vertical
P5: PPI; PinHeader_2x14_P2.54mm_Horizontal
R1, R2: 470; R_Axial_DIN0207_L6.3mm_D2.5mm_P7.62mm_Horizontal
R3: 1.0KQ; R_Axial_DIN0207_L6.3mm_D2.5mm_P7.62mm_Horizontal
R4: 10KQ; R_Axial_DIN0207_L6.3mm_D2.5mm_P7.62mm_Horizontal
RR1: 10K; R_Array_SIP9
SW1: IO PORT ADDR; SW_DIP_SPSTx08_Slide_9.78x22.5mm_W7.62mm_P2.54mm
U1, U3: 74LS244; DIP-20_W7.62mm
U2: 74LS245; DIP-20_W7.62mm
U4: 74LS04; DIP-14_W7.62mm_Socket
U5: 74LS32; DIP-14_W7.62mm_Socket
U6: 74LS139; DIP-16_W7.62mm_Socket
U7: 74LS688; DIP-20_W7.62mm_Socket
U8: W65C51NxP; DIP-28_W15.24mm_Socket
U9: W65C22SxP; DIP-40_W15.24mm_Socket
U10: 6581; DIP-28_W15.24mm_Socket
U11: MAX662ACPA+; DIP-8_W7.62mm_Socket
U12: OPA2134; DIP-8_W7.62mm_Socket
X1: 1.8432MHz; Oscillator_DIP-8

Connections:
+12V: C14.1, U10.28 (+12V), U11.6 (VOUT), U12.8 (V+)
/688SEL#: U3.9 (O0b), U7.1 (G)
A0: P2.21, U1.2 (I0a)
A1: P2.19, U1.4 (I1a)
A2: P2.17, U1.6 (I2a)
A3: P2.15, U1.8 (I3a)
A4: P2.13, U1.11 (I0b)
A5: P2.11, U1.13 (I1b)
A6: P2.9, U1.15 (I2b)
A7: P2.7, U1.17 (I3b)
A8: P2.5
A9: P2.3
A10: P2.1
A11: P2.2
A12: P2.4
A13: P2.6
A14: P2.8
A15: P2.10
BOARD_CS#: U2.19 (CE), U3.4 (I1a), U6.1 (E), U7.19 (P=R)
BUSACK#: P2.35
BUSRQ#: P2.31
CA1: P5.17, U9.40 (CA1)
CA2: P5.19, U9.39 (CA2)
CB1: P5.18, U9.18 (CB1)
CB2: P5.20, U9.19 (CB2)
CLK: P2.12
CS_ACIA1#: U6.6 (O2), U8.3 (~CS2)
CS_SID#: U6.7 (O3), U10.8 (~CS)
CS_VIA1#: U6.4 (O0), U9.23 (~CS2)
CTS: K3.1, U8.9 (~CTS)
D0: P2.28, U2.2 (A0)
D1: P2.30, U2.3 (A1)
D2: P2.24, U2.4 (A2)
D3: P2.16, U2.5 (A3)
D4: P2.14, U2.6 (A4)
D5: P2.18, U2.7 (A5)
D6: P2.20, U2.8 (A6)
D7: P2.26, U2.9 (A7)
DSR: K3.3, U8.17 (~DSR)
GND: C1.2, C2.2, C3.2, C4.2, C5.2, C6.2, C7.2, C8.2, C9.2, C10.2, C11.2, C14.2, C17.2, C19.2, C20.2, C21.2, D2.1 (K), H1.1, H2.1, J1.1A (1), J1.1B (1), J1.1C (1), P2.23, P3.1, P5.26 (P22), R3.1, R4.1, SW1.1, SW1.2, SW1.3, SW1.4, SW1.5, SW1.6, SW1.7, SW1.8, U1.1 (OEa), U1.10 (GND), U1.19 (OEb), U2.10 (GND), U3.1 (OEa), U3.10 (GND), U3.19 (OEb), U4.7 (GND), U5.7 (GND), U6.8 (GND), U7.10 (GND), U8.1 (VSS), U9.1 (VSS), U10.14 (GND), U11.7 (GND), U11.8 (SHDN), U12.4 (V-), X1.4 (GND)
HALT#: P2.36
INT#: K1.1, K2.1, P2.32
IORQ#: P2.40, U3.11 (I0b)
IRQA#: K2.2 (PM), U8.26 (~IRQ)
IRQV#: K1.2 (PM), U9.21 (~IRQ)
M1#: P2.27, U3.13 (I1b)
MREQ#: P2.38
NMI#: K1.3, K2.3, P2.34
unnamed: C12.1, U11.2 (C1+)
unnamed: C12.2, U11.1 (C1-)
unnamed: C13.1, U11.4 (C2+)
unnamed: C13.2, U11.3 (C2-)
unnamed: C15.1, U10.1 (CAP1A)
unnamed: C15.2, U10.2 (CAP1B)
unnamed: C16.1, U10.3 (CAP2A)
unnamed: C16.2, U10.4 (CAP2B)
unnamed: C18.1, U12.1, U12.2 (-)
unnamed: C18.2, J1.2, R4.2
unnamed: D1.1 (K), U3.16 (O1a)
unnamed: D1.2 (A), R1.1
unnamed: D2.2 (A), R2.1
unnamed: K3.2 (PM), P3.6
unnamed: P3.3, P4.1
unnamed: R3.2, U10.27 (AUDIO_OUT), U12.3 (+)
unnamed: RR1.2, U7.3 (R0)
unnamed: RR1.3, U7.5 (R1)
unnamed: RR1.4, U7.7 (R2)
unnamed: RR1.5, U7.9 (R3)
unnamed: RR1.6, U7.12 (R4)
unnamed: RR1.7, U7.14 (R5)
unnamed: RR1.8, SW1.15, U7.16 (R6)
unnamed: RR1.9, SW1.16, U7.18 (R7)
unnamed: U4.2, U5.1
unnamed: U8.6 (XTAL1), X1.5 (OUT)
PA0: P5.1, U9.2 (PA0)
PA1: P5.3, U9.3 (PA1)
PA2: P5.5, U9.4 (PA2)
PA3: P5.7, U9.5 (PA3)
PA4: P5.9, U9.6 (PA4)
PA5: P5.11, U9.7 (PA5)
PA6: P5.13, U9.8 (PA6)
PA7: P5.15, U9.9 (PA7)
PB0: P5.2, U9.10 (PB0)
PB1: P5.4, U9.11 (PB1)
PB2: P5.6, U9.12 (PB2)
PB3: P5.8, U9.13 (PB3)
PB4: P5.10, U9.14 (PB4)
PB5: P5.12, U9.15 (PB5)
PB6: P5.14, U9.16 (PB6)
PB7: P5.16, U9.17 (PB7)
RD#: P2.39, U2.1 (A->B), U3.17 (I3b)
RESET#: P2.29, U3.2 (I0a)
RFSH#: P2.25
RTS: P3.2, U8.8 (~RTS)
RxD: P3.4, U8.12 (RxD)
SLAVE_CLK: P1.1, U8.27 (ϕ2), U9.25 (ϕ2), U10.6 (ϕ2)
SPARE0: P2.42
SPARE1: P2.44
SPARE2: P2.46
SPARE3: P2.48
SPARE4: P2.50
SPARE5: P2.49
SPARE6: P2.47
SPARE7: P2.45
SPARE8: P2.43
SPARE9: P2.41
TxD: P3.5, U8.10 (TxD)
VCC: C1.1, C2.1, C3.1, C4.1, C5.1, C6.1, C7.1, C8.1, C9.1, C10.1, C11.1, C17.1, C19.1, C20.1, C21.1, P2.22, P4.2 (PM), P5.25 (P24), R1.2, R2.2, RR1.1 (COM), U1.20 (VCC), U2.20 (VCC), U3.20 (VCC), U4.14 (VCC), U5.14 (VCC), U6.16 (VCC), U7.20 (VCC), U8.2 (CS1), U8.15 (VCC), U9.20 (VCC), U9.24 (CS1), U10.25 (+5V), U11.5 (VCC), X1.1 (EN), X1.8 (Vcc)
WAIT#: P2.33
WR#: P2.37, U3.15 (I2b)
bA0: U1.18 (O0a), U8.13 (RS0), U9.38 (RS0), U10.9 (A0)
bA1: U1.16 (O1a), U8.14 (RS1), U9.37 (RS1), U10.10 (A1)
bA2: U1.14 (O2a), U9.36 (RS2), U10.11 (A2)
bA3: U1.12 (O3a), U9.35 (RS3), U10.12 (A3)
bA4: U1.9 (O0b), U6.2 (A0), U10.13 (A4)
bA5: U1.7 (O1b), U6.3 (A1)
bA6: U1.5 (O2b), U7.15 (P6)
bA7: U1.3 (O3b), U7.17 (P7)
bD0: U2.18 (B0), U8.18 (D0), U9.33 (D0), U10.15 (D0)
bD1: U2.17 (B1), U8.19 (D1), U9.32 (D1), U10.16 (D1)
bD2: U2.16 (B2), U8.20 (D2), U9.31 (D2), U10.17 (D2)
bD3: U2.15 (B3), U8.21 (D3), U9.30 (D3), U10.18 (D3)
bD4: U2.14 (B4), U8.22 (D4), U9.29 (D4), U10.19 (D4)
bD5: U2.13 (B5), U8.23 (D5), U9.28 (D5), U10.20 (D5)
bD6: U2.12 (B6), U8.24 (D6), U9.27 (D6), U10.21 (D6)
bD7: U2.11 (B7), U8.25 (D7), U9.26 (D7), U10.22 (D7)
bM1#: U3.7 (O1b), U7.2 (P0), U7.4 (P1), U7.6 (P2), U7.8 (P3), U7.11 (P4), U7.13 (P5)
bRD#: U3.3 (O3b), U4.1
bRESET#: U3.18 (O0a), U8.4 (~RES), U9.34 (~RES), U10.5 (~RES)
bRW#: U5.3, U8.28 (R/~W), U9.22 (R/~W), U10.7 (R/~W)
bWR#: U3.5 (O2b), U5.2

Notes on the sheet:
Note: Bus connector is mirror image of Z80 CPU pin out to mate to backplane whose connectors reflect Z80 CPU pin out.
Note: IO Address Port 64-byte blocks S1=on - A7 (low) S2=off - A6 (high) S3=off - A5 (no effect) S4=on - A4 (no effect) S5=on - A3 (no effect) S6=on - A2 (no effect) S7=x - A1 (no effect) S8=x - A0 (no effect)
Note: Inhibit Board Operation During Interrupts M1# = low, IORQ# = low
Note: Buffers/Transceivers respond to IO and MEM cycles
Z80 BUS INTERFACE
IO SELECTION CIRCUIT
SET IO PORT
IO CHIP SELECT
42=Vcc 43=GND


Board: 2 copper layers, 100.0 x 100.0 mm, 53 parts (0 on the bottom side), 106 nets.

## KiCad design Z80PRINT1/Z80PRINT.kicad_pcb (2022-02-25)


Board: 2 copper layers, 100.0 x 100.0 mm, 68 parts (0 on the bottom side), 120 nets.

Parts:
C1, C2, C3, C4, C5, C6, C7, C8, C9, C12, C13, C14, C15, C25: 0.1u; C_Disc_D5.0mm_W2.5mm_P5.00mm
C10, C11: 10u; CP_Radial_D5.0mm_P2.50mm
C16, C17, C18, C19, C20, C21, C22, C23, C24: 2.2nF; C_Disc_D5.0mm_W2.5mm_P5.00mm
D1, D2, D3, D4, D5: LED; LED_D3.0mm
H1, H2: BRACKET; MountingHole_2.2mm_M2_Pad
K1: INT SEL; PinHeader_1x03_P2.54mm_Horizontal
P1: SPARES; PinHeader_1x10_P2.54mm_Vertical
P2: Z80 BUS BACKPLANE; PinHeader_2x25_P2.54mm_Horizontal
P3: DAISY CHAIN; PinHeader_1x04_P2.54mm_Vertical
P31: PARALLEL; PinHeader_2x13_P2.54mm_Horizontal
R1, R2, R3, R4, R5, R6, R7, R8, R9: 27; R_Axial_DIN0207_L6.3mm_D2.5mm_P7.62mm_Horizontal
R10, R11, R12, R13, R14: 470; R_Axial_DIN0207_L6.3mm_D2.5mm_P7.62mm_Horizontal
RR1: 10K; R_Array_SIP9
RR3: 4700; R_Array_SIP10
SW1: IO PORT ADDR; SW_DIP_SPSTx08_Slide_9.78x22.5mm_W7.62mm_P2.54mm
U1, U3, U27, U28, U29: 74LS244; DIP-20_W7.62mm
U2: 74LS245; DIP-20_W7.62mm
U4: 74LS139; DIP-16_W7.62mm
U5: 74LS32; DIP-14_W7.62mm
U6: 74LS688; DIP-20_W7.62mm
U21: 74LS04; DIP-14_W7.62mm
U25, U26: 74LS374; DIP-20_W7.62mm
U30: 74LS06; DIP-14_W7.62mm
U32: 74LS08; DIP-14_W7.62mm

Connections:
/688SEL#: U3.9, U6.1
//BUSY: P31.21, U30.1
//LINEFEED: P31.2, RR3.3, U21.11, U30.8
//PARIN0: U4.4, U27.1, U27.19
//PARIN1: U4.5, U28.1, U28.2, U28.4, U28.6, U28.19
//PARIN2: U4.6, U29.1, U29.19
//PAROUT0: U4.12, U25.11
//PAROUT2: U4.10, U26.11
//PDENBL: U25.1, U26.15, U29.13
//SEL: P31.8, RR3.5, U21.13, U30.4
//STROBE: C24.1, P31.1, R9.1, RR3.2, U21.9
/A0: P2.21, U1.2
/A1: P2.19, U1.4
/A2: P2.17, U1.6
/A3: P2.15, U1.8
/A4: P2.13, U1.11
/A5: P2.11, U1.13
/A6: P2.9, U1.15
/A7: P2.7, U1.17
/ACK: P31.19, U21.3, U28.15
/BUSY: RR3.6, U28.17, U30.2
/CS_PAR#: U2.19, U3.4, U5.9, U5.12, U6.19
/D0: P2.28, U2.2
/D1: P2.30, U2.3
/D2: P2.24, U2.4
/D3: P2.16, U2.5
/D4: P2.14, U2.6
/D5: P2.18, U2.7
/D6: P2.20, U2.8
/D7: P2.26, U2.9
/ERROR: P31.4, U28.8
/INT#: K1.1, P2.32
/IORQ#: P2.40, U3.11
/M1#: P2.27, U3.13
/NMI#: K1.3, P2.34
/P-RESET: P31.6, RR3.4, U29.6, U30.10
/PAPEROUT: P31.23, U28.13
/PARINT: U26.12, U29.11, U32.4
/PD0: C16.1, P31.3, R1.1, U27.2
/PD1: C17.1, P31.5, R5.1, U27.4
/PD2: C18.1, P31.7, R2.1, U27.6
/PD3: C19.1, P31.9, R6.1, U27.8
/PD4: C20.1, P31.11, R3.1, U27.11
/PD5: C21.1, P31.13, R7.1, U27.13
/PD6: C22.1, P31.15, R4.1, U27.15
/PD7: C23.1, P31.17, R8.1, U27.17
/RD#: P2.39, U2.1, U3.17
/RESET#: P2.29, U3.2
/SELECT: P31.25, U28.11
/SPARE0: P1.1, P2.42
/SPARE1: P1.2, P2.44
/SPARE2: P1.3, P2.46
/SPARE3: P1.4, P2.48
/SPARE4: P1.5, P2.50
/SPARE5: P1.6, P2.49
/SPARE6: P1.7, P2.47
/SPARE7: P1.8, P2.45
/SPARE8: P1.9, P2.43
/SPARE9: P1.10, P2.41
/STATUS0: D4.1, P31.26, U26.16, U29.15
/STATUS1: D5.1, U26.19, U29.17
/WR#: P2.37, U3.15
/bA0: U1.18, U4.2, U4.14
/bA1: U1.16, U4.3, U4.13
/bA2: U1.14, U6.6
/bA3: U1.12, U6.8
/bA4: U1.9, U6.11
/bA5: U1.7, U6.13
/bA6: U1.5, U6.15
/bA7: U1.3, U6.17
/bD0: U2.18, U25.3, U26.3, U27.18, U28.18, U29.18
/bD1: U2.17, U25.4, U26.4, U27.16, U28.16, U29.16
/bD2: U2.16, U25.7, U26.7, U27.14, U28.14, U29.14
/bD3: U2.15, U25.8, U26.8, U27.12, U28.12, U29.12
/bD4: U2.14, U25.13, U26.13, U27.9, U28.9, U29.9
/bD5: U2.13, U25.14, U26.14, U27.7, U28.7, U29.7
/bD6: U2.12, U25.17, U26.17, U27.5, U28.5, U29.5
/bD7: U2.11, U25.18, U26.18, U27.3, U28.3, U29.3
/bM1#: U3.7, U6.2, U6.4
/bRD#: U3.3, U5.10
/bWR#: U3.5, U5.13
GND: C1.2, C2.2, C3.2, C4.2, C5.2, C6.2, C7.2, C8.2, C9.2, C10.2, C11.2, C12.2, C13.2, C14.2, C15.2, C16.2, C17.2, C18.2, C19.2, C20.2, C21.2, C22.2, C23.2, C24.2, C25.2, D2.1, H1.1, H2.1, P2.23, P31.10, P31.12, P31.14, P31.16, P31.18, P31.20, P31.22, P31.24, SW1.1, SW1.2, SW1.3, SW1.4, SW1.5, SW1.6, U1.1, U1.10, U1.19, U2.10, U3.1, U3.10, U3.19, U4.8, U5.7, U6.10, U21.7, U25.10, U26.1, U26.10, U27.10, U28.10, U29.10, U30.7, U32.7
unnamed: D1.1, U3.16
unnamed: D1.2, R12.1
unnamed: D2.2, R13.1
unnamed: D3.1, U32.3
unnamed: D3.2, R10.1
unnamed: D4.2, R11.1
unnamed: D5.2, R14.1
unnamed: K1.2, U30.12, U32.1, U32.2
unnamed: R1.2, U25.2
unnamed: R2.2, U25.6
unnamed: R3.2, U25.12
unnamed: R4.2, U25.16
unnamed: R5.2, U25.5
unnamed: R6.2, U25.9
unnamed: R7.2, U25.15
unnamed: R8.2, U25.19
unnamed: R9.2, U30.6
unnamed: RR1.2, U6.3
unnamed: RR1.3, U6.5
unnamed: RR1.4, SW1.11, U6.7
unnamed: RR1.5, SW1.12, U6.9
unnamed: RR1.6, SW1.13, U6.12
unnamed: RR1.7, SW1.14, U6.14
unnamed: RR1.8, SW1.15, U6.16
unnamed: RR1.9, SW1.16, U6.18
unnamed: U4.1, U5.8
unnamed: U4.15, U5.11
unnamed: U21.4, U32.5
unnamed: U21.5, U26.6
unnamed: U21.6, U30.11
unnamed: U21.8, U29.2
unnamed: U21.10, U29.4
unnamed: U21.12, U29.8
unnamed: U26.2, U30.5
unnamed: U26.5, U30.9
unnamed: U26.9, U30.3
unnamed: U30.13, U32.6
VCC: C1.1, C2.1, C3.1, C4.1, C5.1, C6.1, C7.1, C8.1, C9.1, C10.1, C11.1, C12.1, C13.1, C14.1, C15.1, C25.1, P2.22, R10.2, R11.2, R12.2, R13.2, R14.2, RR1.1, RR3.1, U1.20, U2.20, U3.20, U4.16, U5.14, U6.20, U21.14, U25.20, U26.20, U27.20, U28.20, U29.20, U30.14, U32.14

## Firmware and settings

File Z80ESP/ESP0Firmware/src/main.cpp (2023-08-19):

#include <Arduino.h>
#include <fabgl.h>
#include "sound.h"
#include "pins.h"
#include "interface.h"
#include "graphics.h"
#include "serial.h"
#include "sound.h"
#include <esp_int_wdt.h>
#include <esp_task_wdt.h>

// fabgl::VGAController DisplayController;
fabgl::Terminal Terminal;
fabgl::PS2Controller PS2Controller;
fabgl::SoundGenerator soundGenerator;

retroGraphics graphics;
retroSound sound;
serialHelper serial;

static uint8_t stateMachine = 0;
// states
// 0 waiting for command
// 1 vga term out single char, waiting for char
// 2 vga term out multi, waiting for char
// 3 Set cursor, wait for parameter
// 4 Serial Port Baud Rate wait for bytes
// 5 Serial Port Baud Rate wait for byte of mode
// 6 Serial Port out single char, waiting for char
// 7 Serial Port out multi, waiting for char
// 8 play audio waiting for char
// 9 play sound waiting for value
// 10 set volume waiting for value
// 11 set resolution waiting for value
// 12 loadFont waiting for value
// 13 copyRect waiting for value
// 14 drawBitmap waiting for value
// 15 drawChar waiting for value
// 16 drawEllipse waiting for value
// 17 drawGlyph waiting for value
// 18 drawLine waiting for value
// 19 drawRectangle waiting for value
// 20 fillEllipse waiting for value
// 21 fillRectangle waiting for value
// 22 getPixel waiting for value
// 23 invertRectangle waiting for value
// 24 lineTo waiting for value
// 25 moveTo waiting for value
// 26 scroll waiting for value
// 27 setBrushColor waiting for value
// 28 setLineEnds waiting for value
// 29 setPenColor waiting for value
// 30 setPenWidth waiting for value
// 31 setPixel waiting for value
// 32 setGlyphOptions waiting for value
// 33 setPaletteItem waiting for value
// 34 setMouseCursor waiting for value
// 35 setMouseCursorPosition waiting for value
// 36 setSpriteMap waiting for value
// 37 setSpriteLocation waiting for value
// 38 setSpriteVisibility waiting for value

void processOpcode(uint8_t b);
void attachInterruptTask(void *pvParameters);
void forcedReset();

void setup()
{
   // disableCore0WDT();
  //  delay(200); // experienced crashes without this delay!
  //  disableCore1WDT();

    initialize();
    PS2Controller.begin(PS2Preset::KeyboardPort0);

    graphics.initialize(&Terminal);
    serial.initialize();
    sound.initialize(&soundGenerator);

    pinMode(OUTCLK, OUTPUT);
    pinMode(INCLK, OUTPUT);
    pinMode(OUTDATA, OUTPUT);
    pinMode(INDATA, INPUT);

    pinMode(BUSY, OUTPUT);
    pinMode(READY, OUTPUT);
    pinMode(SPARE, OUTPUT);

    digitalWrite(INCLK, LOW);

    digitalWrite(OUTCLK, HIGH);
    digitalWrite(OUTDATA, LOW);

    digitalWrite(BUSY, LOW);
    digitalWrite(READY, LOW);
    digitalWrite(SPARE, LOW);

    xTaskCreatePinnedToCore(attachInterruptTask, "Attach Interrupt Task", 1000, NULL, 6, NULL, 0);
    popByte();
    popByte();
    popByte();
    popByte();
}

void attachInterruptTask(void *pvParameters)
{

    pinMode(WR, INPUT);
    pinMode(RD, INPUT);
    attachInterrupt(WR, WRISR, FALLING);
    attachInterrupt(RD, RDISR, FALLING);

    while (true)
    {
        delay(500);
    }
    vTaskDelete(NULL);
}

void loop()
{
    int tb = 0;

    if (!bufferEmpty())
    {
        switch (stateMachine)
        {
        case 0: // 0 waiting for command
            processOpcode(popByte());
            break;
        case 1: // 1 vga term out single char, waiting for char
            Terminal.write(popByte());
            stateMachine = 0;
            break;
        case 2: // 2 vga term out multi, waiting for char
            tb = popByte();
            if (tb == 0)
            {
                stateMachine = 0;
            }
            else
            {
                Terminal.write(tb);
            }
            break;
        case 3: // 3 Set cursor, wait for parameter
            graphics.setCursor(popByte());
            stateMachine = 0;
            break;
        case 4: // 4 Serial Port Baud Rate wait for bytes
            if (bufferLength() > 3)
            {
                serial.setBaud(popDoubleWord());
                stateMachine = 0;
            }
            break;
        case 5: // 5 Serial Port Baud Rate wait for byte of mode
            serial.setSerialMode(popByte());
            stateMachine = 0;
            break;
        case 6: // 6 Serial Port out single char, waiting for char
            Serial.write(popByte());
            stateMachine = 0;
            break;
        case 7: // 7 Serial Port out multi, waiting for char
            tb = popByte();
            if (tb == 0)
            {
                stateMachine = 0;
            }
            else
            {
                Serial.write(tb);
            }
            break;
        case 8: // 8 play audio waiting for char
            tb = popByte();
            sound.play_audio_string(tb);
            if (tb == 0)
            {
                stateMachine = 0;
            }
            break;
        case 9: // 9 play sound waiting for value
            if (sound.play_sound_string(popByte()) == 0)
                stateMachine = 0;
            ;
            break;
        case 10: // 10 set volume waiting for value
            sound.setVolume(popByte());
            stateMachine = 0;
            break;
        case 11: // 11 set resolution waiting for value
            graphics.setGraphicsMode(popByte());
            stateMachine = 0;
            ESP.restart();
            break;
        case 12: // 12 LOAD FONT  waiting for value
            graphics.loadFont(popByte());
            stateMachine = 0;
            break;
        case 13: // 13 copyRect waiting for value
            if (graphics.copyRect(popByte()))
                stateMachine = 0;
            break;
        case 14: // 14 drawBitmap waiting for value
            if (graphics.drawBitmap(popByte()))
                stateMachine = 0;
            break;
        case 15: // 15 drawChar waiting for value
            if (graphics.drawChar(popByte()))
                stateMachine = 0;
            break;
        case 16: // 16 drawEllipse waiting for value
            if (graphics.drawEllipse(popByte()))
                stateMachine = 0;
            break;
        case 17: // 17 drawGlyph waiting for value
            if (graphics.drawGlyph(popByte()))
                stateMachine = 0;
            break;
        case 18: // 18 drawLine waiting for value
            if (graphics.drawLine(popByte()))
                stateMachine = 0;
            break;
        case 19: // 19 drawRectangle waiting for value
            if (graphics.drawRectangle(popByte()))
                stateMachine = 0;
            break;
        case 20: // 20 fillEllipse waiting for value
            if (graphics.fillEllipse(popByte()))
                stateMachine = 0;
            break;
        case 21: // 21 fillRectangle waiting for value
            if (graphics.fillRectangle(popByte()))
                stateMachine = 0;
            break;
        case 22: // 22 getPixel waiting for value
            if (graphics.getPixel(popByte()))
                stateMachine = 0;
            break;
        case 23: // 23 invertRectangle waiting for value
            if (graphics.invertRectangle(popByte()))
                stateMachine = 0;
            break;
        case 24: // 24 lineTo waiting for value
            if (graphics.lineTo(popByte()))
                stateMachine = 0;
            break;
        case 25: // 25 moveTo waiting for value
            if (graphics.moveTo(popByte()))
                stateMachine = 0;
            break;
        case 26: // 26 scroll waiting for value
            if (graphics.scroll(popByte()))
                stateMachine = 0;
            break;
        case 27: // 27 setBrushColor waiting for value
            graphics.setBrushColor(popByte());
            stateMachine = 0;
            break;
        case 28: // 28 setLineEnds waiting for value
            graphics.setLineEnds(popByte());
            stateMachine = 0;
            break;
        case 29: // 29 setPenColor waiting for value
            graphics.setPenColor(popByte());
            stateMachine = 0;
            break;
        case 30: // 30 setPenWidth waiting for value
            graphics.setPenWidth(popByte());
            stateMachine = 0;
            break;
        case 31: // 31 setPixel waiting for value
            if (graphics.setPixel(popByte()))
                stateMachine = 0;
            break;
        case 32: // setGlyphOptions waiting for value
            if (graphics.setGlyphOptions(popByte()))
                stateMachine = 0;
            break;
        case 33: // setPaletteItem waiting for value
            if (graphics.setPaletteItem(popByte()))
                stateMachine = 0;
            break;
        case 34: // setMouseCursor waiting for value
            graphics.setMouseCursor(popByte());
            stateMachine = 0;
            break;
        case 35: // setMouseCursorPosition waiting for value
            if (graphics.setMouseCursorPosition(popByte()))
                stateMachine = 0;
            break;
        case 36: // setSpriteMap waiting for value
            if (graphics.setSpriteMap(popByte()))
                stateMachine = 0;
            break;
        case 37: // setSpriteLocation waiting for value
            if (graphics.setSpriteLocation(popByte()))
                stateMachine = 0;
            break;
        case 38: // setSpriteVisibility waiting for value
            if (graphics.setSpriteVisibility(popByte()))
                stateMachine = 0;
            break;
        }
    }
}

void processOpcode(uint8_t b)
{
    switch (b)
    {
    case 0: // NOP
        stateMachine = 0;
        break;
    case 1: // OUT SINGLE CHAR
        stateMachine = 1;
        break;
    case 2: // OUT NULL TERM STRING
        stateMachine = 2;
        break;
    case 3: // GET KEYBOARD CHAR
        if (Terminal.available())
        {
            queueByte(Terminal.read());
        }
        else
        {
            queueByte(0);
        }
        stateMachine = 0;
        break;
    case 4: // GET KEYBOARD WAITING
        queueByte(Terminal.available());
        stateMachine = 0;
        break;
    case 5: // SET DISPLAY CURSOR
        stateMachine = 3;
        break;
    case 6: // GET SERIAL BAUD
        stateMachine = 4;
        break;
    case 7: // GET SERIAL MODE
        stateMachine = 5;
        break;
    case 8: // OUT SERIAL CHAR
        stateMachine = 6;
        break;
    case 9: // OUT SERIAL NULL TERM STRING
        stateMachine = 7;
        break;
    case 10: // GET SERIAL CHAR
        serial.serialIn();
        stateMachine = 0;
        break;
    case 11: // GET SERIAL WAITING
        queueByte(Serial.available());
        stateMachine = 0;
        break;
    case 12: // GET AUDIO PLAY STRING
        sound.newsong();
        stateMachine = 8;
        break;
    case 13: // PLAY SOUND
        sound.newsong();
        stateMachine = 9;
        break;
    case 14: // SET VOLUME
        stateMachine = 10;
        break;
    case 15: // SET GRAPHICS MODE
        stateMachine = 11;
        break;
    case 16: // LOAD FONT
        stateMachine = 12;
        break;
    case 17: // CLEAR SCREEN
        graphics.clearDisplay();
        break;
    case 18: // copyRect
        graphics.resetPointer();
        stateMachine = 13;
        break;
    case 19: // drawBitmap
        graphics.resetPointer();
        stateMachine = 14;
        break;
    case 20: // drawChar
        graphics.resetPointer();
        stateMachine = 15;
        break;
    case 21: // drawEllipse
        graphics.resetPointer();
        stateMachine = 16;
        break;
    case 22: // drawGlyph
        graphics.resetPointer();
        stateMachine = 17;
        break;
    case 23: // drawLine
        graphics.resetPointer();
        stateMachine = 18;
        break;
    case 24: // drawRectangle
        graphics.resetPointer();
        stateMachine = 19;
        break;
    case 25: // fillEllipse
        graphics.resetPointer();
        stateMachine = 20;
        break;
    case 26: // fillRectangle
        graphics.resetPointer();
        stateMachine = 21;
        break;
    case 27: // getPixel
        graphics.resetPointer();
        stateMachine = 22;
        break;
    case 28: // invertRectangle
        graphics.resetPointer();
        stateMachine = 23;
        break;
    case 29: // lineTo
        graphics.resetPointer();
        stateMachine = 24;
        break;
    case 30: // moveTo
        graphics.resetPointer();
        stateMachine = 25;
        break;
    case 31: // scroll
        graphics.resetPointer();
        stateMachine = 26;
        break;
    case 32: // setBrushColor
        stateMachine = 27;
        break;
    case 33: // setLineEnds
        graphics.resetPointer();
        stateMachine = 28;
        break;
    case 34: // setPenColor
        stateMachine = 29;
        break;
    case 35: // setPenWidth
        graphics.resetPointer();
        stateMachine = 30;
        break;
    case 36: // setPixel
        graphics.resetPointer();
        stateMachine = 31;
        break;
    case 37: // setPixelsetGlyphOptions
        graphics.resetPointer();
        stateMachine = 32;
        break;
    case 38: // setPixelsetPaletteItem
        graphics.resetPointer();
        stateMachine = 33;
        break;
    case 39: // setPixelsetMouseCursor
        stateMachine = 34;
        break;
    case 40: // setPixelsetMouseCursorPosition
        graphics.resetPointer();
        stateMachine = 35;
        break;
    case 41: // removeSprites()
        graphics.removeSprites();
        stateMachine = 0;
        break;
    case 42: // setPixelsetSpriteMap
        graphics.resetPointer();
        stateMachine = 36;
        break;
    case 43: // setPixelsetSpriteLocation
        graphics.resetPointer();
        stateMachine = 37;
        break;
    case 44: // setPixelsetSpriteVisibility
        graphics.resetPointer();
        stateMachine = 38;
        break;

    case 255: // HARDWARE DISCOVERY
        stateMachine = 0;
        queueByte('E');
        queueByte('S');
        queueByte('P');
        queueByte('3');
        queueByte('2');
        queueByte('V');
        queueByte('1');
        break;
    }
}

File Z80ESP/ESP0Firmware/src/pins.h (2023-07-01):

#pragma Once

#define RD 13
#define WR 36
#define OUTCLK 26
#define INCLK 27
#define OUTDATA 16
#define INDATA 17
#define BUSY 14
#define READY 12
#define SPARE 2

#define RED1  GPIO_NUM_22
#define RED0  GPIO_NUM_21
#define GREEN1  GPIO_NUM_19
#define GREEN0  GPIO_NUM_18
#define BLUE1  GPIO_NUM_5
#define BLUE0  GPIO_NUM_4
#define HSYNC   GPIO_NUM_23
#define VSYNC   GPIO_NUM_15

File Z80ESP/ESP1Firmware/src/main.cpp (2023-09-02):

#include <Arduino.h>
#include <fabgl.h>
#include <WiFi.h>
#include "pins.h"
#include "interface.h"
#include "serial.h"
#include "retrowifi.h"
#include "retroMouse.h"



serialHelper serial;
retroWifi espWifi;
retroMouse espMouse;

static uint8_t stateMachine = 0;
// states
// 0 waiting for command
// 1 WIFI Set SSID, waiting for char
// 2 WIFI Set SSID Password, waiting for char
// 4 Serial Port Baud Rate wait for bytes
// 5 Serial Port Baud Rate wait for byte of mode
// 6 Serial Port out single char, waiting for char
// 7 Serial Port out multi, waiting for char
// 8 Set IP Address, waiting for char
// 9 Set Subnet Mask, waiting for char
// 10 Set Gateway,waiting for char
// 11 Set Primary DNS, waiting for char
// 12 Set Secondary DNS, waiting for char
// 13 SET HOSTNAME, waiting for char
// 14 CREATE OUTGOING CONNECTION, waiting for char
// 15 SET INCOMING PORT, waiting for char
// 16 OUT BYTE TO CONNECTION, waiting for char
// 17 OUT STRING TO CONNECTION, waiting for char
// 18 IN BYTE FROM CONNECTION, waiting for char
// 19 NUMBER OF BYTES IN QUEUE FOR  CONNECTION, waiting for char

void processOpcode(uint8_t b);
void attachInterruptTask(void *pvParameters);

void setup()
{
    pinMode(OUTCLK, OUTPUT);
    pinMode(INCLK, OUTPUT);
    pinMode(OUTDATA, OUTPUT);
    pinMode(INDATA, INPUT);

    pinMode(BUSY, OUTPUT);
    pinMode(READY, OUTPUT);

    digitalWrite(INCLK, LOW);

    digitalWrite(OUTCLK, HIGH);
    digitalWrite(OUTDATA, LOW);

    digitalWrite(BUSY, LOW);
    digitalWrite(READY, LOW);

    pinMode(WR, INPUT);
    pinMode(RD, INPUT);
    attachInterrupt(WR, WRISR, FALLING);
    attachInterrupt(RD, RDISR, FALLING);

    espMouse.initialize();
    espWifi.initialize();
    serial.initialize();
}

void loop()
{
    int tb = 0;

    if (!bufferEmpty())
    {
        switch (stateMachine)
        {
        case 0: // 0 waiting for command
            processOpcode(popByte());
            break;
        case 1: // 1 WIFI Set SSID, waiting for char
            if (espWifi.setSSID(popByte()))
                stateMachine = 0;
            break;
        case 2: // 2 WIFI Set SSID Password, waiting for char
            if (espWifi.setPassword(popByte()))
                stateMachine = 0;
            break;
        case 4: // 4 Serial Port Baud Rate wait for bytes
            if (bufferLength() > 3)
            {
                serial.setBaud(popDoubleWord());
                stateMachine = 0;
            }
            break;
        case 5: // 5 Serial Port Baud Rate wait for byte of mode
            serial.setSerialMode(popByte());
            stateMachine = 0;
            break;
        case 6: // 6 Serial Port out single char, waiting for char
            Serial.write(popByte());
            stateMachine = 0;
            break;
        case 7: // 7 Serial Port out multi, waiting for char
            tb = popByte();
            if (tb == 0)
            {
                stateMachine = 0;
            }
            else
            {
                Serial.write(tb);
            }
            break;
        case 8: // 8 Set IP Address, waiting for char
            if (espWifi.setIpAddress(popByte()))
                stateMachine = 0;
            break;
        case 9: // 9 Set Subnet Mask, waiting for char
            if (espWifi.setSubnet(popByte()))
                stateMachine = 0;
            break;
        case 10: // 10 Set Gateway,waiting for char
            if (espWifi.setGateway(popByte()))
                stateMachine = 0;
            break;
        case 11: // 11 Set Primary DNS, waiting for char
            if (espWifi.setPrimaryDns(popByte()))
                stateMachine = 0;
            break;
        case 12: // 12 Set Secondary DNS, waiting for char
            if (espWifi.setSecondaryDns(popByte()))
                stateMachine = 0;
            break;
        case 13: // 13 SET HOSTNAME, waiting for char
            if (espWifi.setHostname(popByte()))
                stateMachine = 0;
            break;
        case 14: // 14 CREATE OUTGOING CONNECTION, waiting for char
            if (espWifi.createOutgoingConnection(popByte()))
                stateMachine = 0;
            break;
        case 15: // 15 SET INCOMING PORT, waiting for char
            if (bufferLength() > 1)
            {
                espWifi.setIncomingPort(popWord());
                stateMachine = 0;
            }
            break;
        case 16: // 16 OUT BYTE TO CONNECTION, waiting for char
            if (espWifi.outByteToConnection(popByte()))
                stateMachine = 0;
            break;
        case 17: // 17 OUT STRING TO CONNECTION, waiting for char
            if (espWifi.outStringToConnection(popByte()))
                stateMachine = 0;
            break;
        case 18: // 18 IN BYTE FROM CONNECTION, waiting for char
            espWifi.inByteFromConnection(popByte());
            stateMachine = 0;
            break;
        case 19: // 19 NUMBER OF BYTES IN QUEUE FOR  CONNECTION, waiting for char
            espWifi.queuedBytesFromConnection(popByte());
            stateMachine = 0;
            break;
        }
    }

    espWifi.listenForIncomingConnection();
}
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

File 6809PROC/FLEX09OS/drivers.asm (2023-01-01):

                NAM     DRIVERS
                PAG
                PRAGMA CD

USEDSKYNG       EQU     1
USEDSKYKB       EQU     1


;_____________________________________________________________________________________________________
; File Name   : DRIVERS.ASM
;_____________________________________________________________________________________________________
;
;  Harware Addresses
;_____________________________________________________________________________________________________
; UART 16C550 SERIAL
UART0       	equ    	$FE68           ; DATA IN/OUT
UART1       	equ    	$FE69           ; CHECK RX
UART2       	equ    	$FE6A           ; INTERRUPTS
UART3       	equ    	$FE6B           ; LINE CONTROL
UART4       	equ    	$FE6C           ; MODEM CONTROL
UART5          	equ    	$FE6D           ; LINE STATUS
UART6          	equ    	$FE6E           ; MODEM STATUS
UART7	       	equ    	$FE6F           ; SCRATCH REG.

;_____________________________________________________________________________________________________
;
; DISK DRIVER ROUTINE JUMP TABLE
;_____________________________________________________________________________________________________
                ORG     $DE00

READ            JMP     >DREAD       * DE00    READ      Read a single sector
WRITE           JMP     >DWRITE      * DE03    WRITE     Write a single sector
VERIFY          JMP     >DVERIFY     * DE06    VERIFY    Verify last sector written
RESTORE         JMP     >DRESTORE    * DE09    RESTORE   Restore head to track #0
DRIVE           JMP     >DDRIVE      * DE0C    DRIVE     Select the specified drive
CHKRDY          JMP     >DCHKRDY     * DE0F    CHKRDY    Check for drive ready
QUICK           JMP     >DQUICK      * DE12    QUICK     Quick check for drive ready
CINIT           JMP     >DCINIT      * DE15    CINIT     Driver initialize (cold start)
WARM            JMP     >DWARM       * DE18    WARM      Driver initialize (warm start)
SEEK            JMP     >DSEEK       * DE1B    SEEK      Seek to specified track


;_____________________________________________________________________________________________________
; Temp Storage Area
;_____________________________________________________________________________________________________


CURDRV          FCB     $00
CURDRVTYP       FCB     $00
CURDRVADDRESS   FCB     $00
CURDRVSLICE     FDB     $0000

DRVTYPES        FCB     $02,$02,$01,$01
                ;   $00 - INVALID
                ;   $01 - Floppy
                ;   $02 - IDE
DRVADDRESS      FCB     $01,$01,$01,$01
DRVSLICE        FDB     $0000,$0000,$0000,$0000

;_____________________________________________________________________________________________________
;_____________________________________________________________________________________________________
;_____________________________________________________________________________________________________




;_____________________________________________________________________________________________________
;
;       Monitor entry routine
;_____________________________________________________________________________________________________
MONITR          LDA     #$A
                BSR     VOUTCH              * OUTPUT CHARACTER
                LDA     #$D
                BSR     VOUTCH              * OUTPUT CHARACTER
                JMP     $FC0B               LOCATION OF MONITOR

;_____________________________________________________________________________________________________
;
;       Timer Drivers
;
;       Timers not supported
;_____________________________________________________________________________________________________
TMOFF       ; TIMER OFF ROUTINE
TMON        ; TIMER ON ROUTINE
TMINT       ; TIMER INITIALIZATION
                RTS

;_____________________________________________________________________________________________________
;
;       Console Drivers
;_____________________________________________________________________________________________________
;       Terminal init routine
TINIT           PSHS    A
                ; these are all set by CP/M prior to activating the 6809 card. If 6809 is the primary CPU, these need to be set
               	;	LDA		#$80		;
            	;	STA		UART3		; SET DLAB FLAG
	            ;	LDA		#12			; SET TO 12 = 9600 BAUD
	            ;	STA		UART0		; save baud rate
	            ;	LDA		#00			;
	            ;	STA		UART1		;
	            ;	LDA		#03			;
	            ;	STA		UART3		; SET 8 BIT DATA, 1 STOPBIT
	            ;	STA		UART4		;
                PULS    PC,A


;       Terminal input routine

VINCH           TST     >TAPPTR         ; allow redirection of input from terminal
                BEQ     TREDIR          ; redirection not required
                JSR     [TAPPTR]        ; redirect to alternate routine

;       Terminal output routine

VOUTCH          PSHS    a
!
		        LDA		UART5			; READ LINE STATUS REGISTER
		        ANDA	#$20			; TEST IF UART IS READY TO SEND (BIT 5)
		        CMPA 	#$00
		        BEQ		<       		; IF NOT REPEAT
                PULS    A
		        STA		UART0			; THEN WRITE THE CHAR TO UART
                RTS


;       Terminal status check routine

STAT:           PSHS    A
    	        LDA	    UART5			; READ LINE STATUS REGISTER
		        ANDA	#$01			; TEST IF DATA IN RECEIVE BUFFER
		        CMPA 	#$00
		        PULS    PC,A


;       Monitor terminal input character with echo

TREDIR          JSR     INCHNE
                BRA     VOUTCH


;       Monitor terminal input character without echo

INCHNE
		        LDA	    UART5			; READ LINE STATUS REGISTER
		        ANDA	#$01			; TEST IF DATA IN RECEIVE BUFFER
		        CMPA 	#$00
		        BEQ	    INCHNE      	; LOOP UNTIL DATA IS READY
		        LDA	    UART0			; THEN READ THE CHAR FROM THE UART
		        RTS


;_____________________________________________________________________________________________________
;
;       Interupt handler
;_____________________________________________________________________________________________________
IHNDLR          ;leau    <IRQLL-4,pc         get address of IRQ handler linked list
                fcb     $33,$8c             Why?  Because LWASM does not handle the above line correctly
                fcb     IRQLL-*-5
CHKNXT          ldu     4,u                 get a link
                beq     IHDONE              end of list

                lda     [,u]                get status from device
                bita    6,u                 did it interrupt?
                beq     CHKNXT              no - check next

                ldy     ,u                  yes - get address of device in Y
                jmp     [2,u]               go to device ISR

IHDONE          rti                         return from interrupt
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

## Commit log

2021-12-07 Add files via upload
    Picture of the front of the KBDMSEv1, also showing the keyboard dongle (which is a panel-mount DIN6 connector with 0.1" header attached).
2021-12-12 Add 65C02 designs and code
    [Z8065C02-B_Cu.gbr, Z8065C02-B_Mask.gbr, Z8065C02-B_Paste.gbr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]
2021-12-14 correct issues with WR
    [Z8065C02.dsn, Z8065C02.kicad_pcb, Z8065C02.sch]
2021-12-14 update PCB
    [Z8065C02-B_Cu.gbr, Z8065C02-B_Mask.gbr, Z8065C02-B_Paste.gbr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]
2021-12-18 6502 software work
    [mbc.cfg]
2021-12-22 6502 updates
    [Z8065C02-B_Cu.gbr, Z8065C02-B_Mask.gbr, Z8065C02-B_Paste.gbr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]
2021-12-24 DOS65 work
    [DOS65.obj]
2021-12-26 6502 BOM update
2021-12-27 6502 BOM
    [DOS65.obj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]
2021-12-30 add CPM.CO6 command and convert build to Makefile
    [DOS65.obj, dos65.cfg]
2021-12-30 setup c compiler
    [dos65c.cfg]
2022-01-01 assign.co6 complete
    [dos65c.cfg]
2022-01-01 WORK ON MD DEVICES
2022-01-01 memory disk drivers
2022-01-17 DOS updates
    [Z8065C02.dsn, Z8065C02.kicad_pcb, Z8065C02.sch]
2022-01-19 PCB update
    [Z8065C02-B_Cu.gbr, Z8065C02-B_Mask.gbr, Z8065C02-B_Paste.gbr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]
2022-02-20 Fix RomWBW read only filesystem dir bug
    [ccmnhy.asm]
2022-02-25 Initial commit of a 6502-oriented multi-peripheral board for the MBC series.
    Initial commit of design files.
    [Z80-6502IO.dsn, Z80-6502IO.kicad_pcb, Z80-6502IO.sch]
2022-04-24 reorganize DOS65
    [dos65.cfg, dos65c.cfg]
2022-04-25 Add banked driver support to DOS65
    [dos65.cfg]
2022-04-25 Move serial device to paged ram
2022-04-25 Driver Work
2022-05-01 relocate dos65
    [dos65.cfg]
2022-06-15 fix inverter
    [Z8065C02-B_Cu.gbr, Z8065C02-B_Mask.gbr, Z8065C02-B_Paste.gbr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]
2022-06-16 add pull up
    [Z8065C02-B_Cu.gbr, Z8065C02-B_Mask.gbr, Z8065C02-B_Paste.gbr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]
2022-07-26 6809 CPU Board
    [Z806809-B_Cu.gbr, Z806809-B_Mask.gbr, Z806809-B_Paste.gbr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]
2022-08-04 DMA V3
    DMA Daisy chain corrections
    [Z80DMA.kicad_pcb, Z80DMA.sch]
2022-08-12 correct zloader assemble issue
2022-08-12 add ground plane
    [Z8065C02-B_Cu.gbr, Z8065C02-B_Mask.gbr, Z8065C02-B_Paste.gbr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]
2022-08-13 Correct prototype hardware issues
    [Z806809-B_Cu.gbr, Z806809-B_Mask.gbr, Z806809-B_Paste.gbr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]
2022-08-14 flex console driver work
    [drivers.asm, monitor.asm, scream.asm]
2022-08-15 add ppide drivers
2022-09-10 flex DSKY code
    [Z8065C02-B_Cu.gbr, Z8065C02-B_Mask.gbr, Z8065C02-B_Paste.gbr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]
2022-09-11 DSKY flex drivers
2022-09-11 flex floppy drivers
    [Z806809-B_Cu.gbr, Z806809-B_Mask.gbr, Z806809-B_Paste.gbr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]
2022-09-25 Add files via upload
    Sample MBC configuration file for Andrew Lynch system
2022-10-03 work to resolve cpu concurrency issues
    [Z8065C02-B_Cu.gbr, Z8065C02-B_Mask.gbr, Z8065C02-B_Paste.gbr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]
2022-10-22 Correct 6502 gerber
    [Z80-6502IO.sch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]
2023-03-04 add software binaries
    [1.stl, 3.stl, 4.stl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]
2023-03-20 Boot Code
    [mbc.cfg]
2023-03-25 DOS65 device cleanup
2023-05-22 add Z80ESP design
    [Z80ESP-B_Cu.gbr, Z80ESP-B_Fab.gbr, Z80ESP-B_Mask.gbr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]
2023-06-19 z80 esp
    [Z80ESP-B_Cu.gbr, Z80ESP-B_Fab.gbr, Z80ESP-B_Mask.gbr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]
2023-07-15 esp wifi work
    [Z80ESP.kicad_sch, Z80ESP_Commands.xlsx]
2023-07-16 esp MOUSE WORK
    [Z80ESP_Commands.xlsx]
2023-08-06 6809 work
    [Z806809-B_Cu.gbr, Z806809-B_Mask.gbr, Z806809-B_Paste.gbr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]
2023-08-11 Z80PROCDMA Development
    [Z80PROC3.dsn, Z80PROC3.kicad_pcb, Z80PROC3.kicad_sch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]
2023-08-12 Z80ESP Docs
    [Z80ESP.csv, Z80ESP_bom.csv]
2023-08-21 Fix serial 2 firmware
    [main.cpp]
